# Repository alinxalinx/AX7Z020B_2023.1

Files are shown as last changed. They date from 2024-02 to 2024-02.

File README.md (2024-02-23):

# Xilinx Zynq 7000 series development boards AX7Z020, AX7Z020B
## Development board introduction
### Development board introduction
The entire structure of the development board is designed based on our consistent core board + expansion board model. Core board and expansion board
are connected using high-speed inter-board connectors.
The core board is mainly composed of XC7Z020 + 2 DDR3 + QSPI FLASH minimum system, responsible for the ZYNQ system
The high-speed data processing and storage function of the system. The data bit width between ZYNQ7020 and two DDR3 chips is 32 bits.
DDR3 capacity up to 1GB. ZYNQ7020 uses Xilinx’s Zynq7000 series of chips, model number is
XC7Z020-2CLG400I. The ZYNQ7020 chip can be divided into the processor system part Processor System (PS) and
Programmable Logic (PL).
The baseboard extends the core board with a wealth of peripheral interfaces, including 1 Gigabit Ethernet interface and 1 USB2.0 HOST
interface, 1 HDMI output interface, 1 SD Card interface, 1 UART USB interface, 1 SD card interface, 1
2-way MIPI interface, 2-way CAN bus interface, 2-way RS485 bus interface, 2-way AD input interface, 2-way 40-pin
Expansion port and some button LEDs.
### Key Features
1. ZYNQ7000 core board consists of XC7Z020+1GB DDR3 + 256Mb QSPI FLASH, and a 33.333333MHz crystal oscillator provides the clock to the PS system.
2. For the 2-way CAN bus interface, the SN65HVD232 chip of TI Company is selected.
3. For the 2-way 485 communication interface, the MAX3485 chip of MAXIM Company is selected.
4. 1 channel 10/100M/1000M Ethernet RJ45 interface, used for Ethernet data exchange with computers or other network devices. The network interface chip uses JL2121 industrial-grade GPHY chip from Jinglue Semiconductor Company.
5. One high-speed USB2.0 HOST interface, which can be used to connect the development board to USB peripherals such as mouse, keyboard, and U disk;
6. 1-way Uart to USB interface, used to communicate with the computer to facilitate user debugging. The serial port chip uses the USB-UAR chip of Silicon Labs CP2102GM, and the USB interface uses the MINI USB interface.
7. 1-way Micro SD card holder for storing operating system images and file systems.
8. 2 AD analog input interfaces, which can be used for analog signal input and voltage conversion, SMA interface form. The analog signal voltage input range is 0~10V (do not input voltage exceeding this range).
9. One HDMI image video output interface, capable of 1080P video image transmission;
10. A piece of EEPROM 24LC04 with IIC interface;
11. There is a temperature sensor chip LM75 on the board, which is used to detect the temperature of the environment around the board.
12. One MIPI camera interface, which can be connected to the OV5640 camera with black gold MIPI interface (only used by AX7Z020).
13. 1 JTAG debugging interface.
14. Two 40-pin 2.54mm pitch expansion ports can be used to connect various black gold modules (binocular cameras, TFT LCD screens, high-speed AD modules, etc.). The expansion port includes 1 channel of 5V power supply, 2 channels of 3.3V power supply, 3 channels of ground, and 34 channels of IO port.
15. 7 light-emitting diodes LED, 6 on the core board and 1 on the base board. There is 1 power indicator light on the core board; 1 power indicator light, 1 DONE configuration indicator light; and 4 user indicator lights on the base board.
16. 4 user buttons on the base panel.

# AX7Z020, AX7Z020B document tutorial link

 Note: You can switch between Chinese and English languages at the footer at the end of the document

# AX7Z020,AX7Z020B routine
## Routine description
This project is the factory routine of the development board and supports most peripherals on the board.
## Development environment and requirements
* Vivado 2023.1
* AX7Z020/AX7Z020B development board
## Create Vivado project
* Download the latest ZIP package.
* Create a new project folder.
* Unzip the downloaded ZIP package into this project folder.

There are two ways to create a Vivado project, as follows:
### Use Vivado tcl console to create a Vivado project
1. Open the Vivado software and use the **cd** command to enter the "**auto_create_project**" directory and press Enter
```
cd \<archive extracted location\>/vivado/auto_create_project
```
2. Enter **source ./create_project.tcl** and press Enter
```
source ./create_project.tcl
```

### Use bat to create a Vivado project
1. In the "**auto_create_project**" folder, there is a "**create_project.bat**" file, right-click to open it in edit mode, and modify the vivado path to the vivado installation path of this host, save and close.
```
CALL E:\XilinxVitis\Vivado\2023.1\bin\vivado.bat -mode batch -source create_project.tcl
PAUSE
```
2. Double-click the bat file under Windows.

For more information, please visit [ALINX website](https://www.alinx.com)

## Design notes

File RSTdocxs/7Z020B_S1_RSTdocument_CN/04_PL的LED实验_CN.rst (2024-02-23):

PL的“Hello World”LED实验
==========================

**实验Vivado工程为“led”。**

**本章内容主要由FPGA工程师负责实现。**

对于ZYNQ来说PL（FPGA）开发是至关重要的，这也是ZYNQ比其他ARM的有优势的地方，可以定制化很多ARM端的外设，在定制ARM端的外设之前先让我们通过一个LED例程来熟悉PL（FPGA）的开发流程，熟悉Vivado软件的基本操作，这个开发流程和不带ARM的FPGA芯片完全一致。

在本例程中，我们要做的是LED灯控制实验，每秒钟控制开发板上的LED灯翻转一次，实现亮、灭、亮、灭的控制。会控制LED灯，其它外设也慢慢就会了。

LED硬件介绍
-----------

1) 开发板的PL部分连接了4个红色的用户LED灯。这4个灯完全由PL控制。

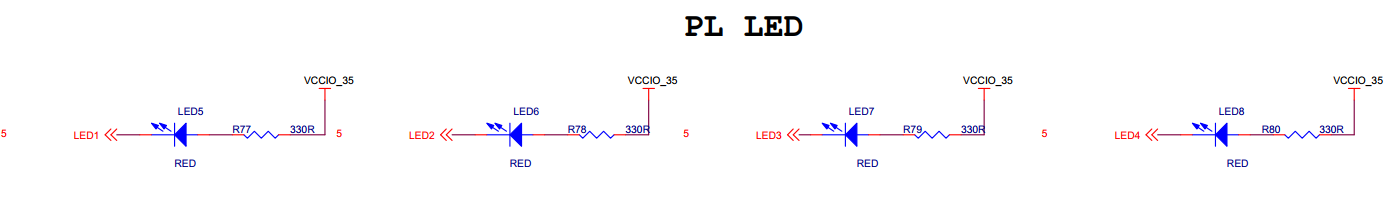
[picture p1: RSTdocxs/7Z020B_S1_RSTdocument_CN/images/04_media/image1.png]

    
2) 我们可以根据原理图的连线关系确定LED和PL管脚的绑定关系。

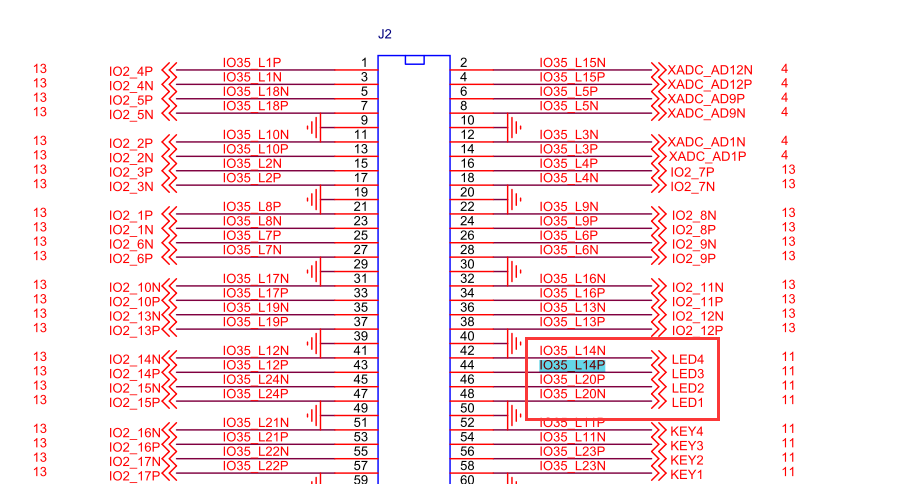
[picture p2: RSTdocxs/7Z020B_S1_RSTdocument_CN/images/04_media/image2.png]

    
对应的管脚信息

3) **原理图中以PS_MIO开头的IO都是PS端IO，不需要绑定，也不能绑定**

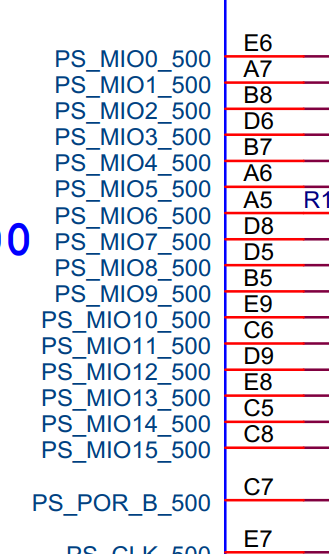
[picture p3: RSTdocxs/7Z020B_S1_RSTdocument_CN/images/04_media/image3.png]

    
创建Vivado工程
--------------

1) 启动Vivado，在Windows中可以通过双击Vivado快捷方式启动


       
2) 在Vivado开发环境里点击“Create New Project”，创建一个新的工程。

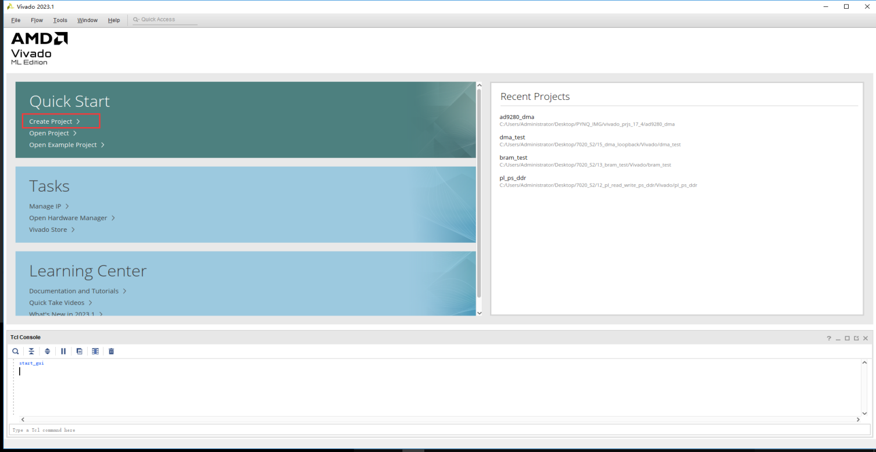
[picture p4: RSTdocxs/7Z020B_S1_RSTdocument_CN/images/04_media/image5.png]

       
3) 弹出一个建立新工程的向导，点击“Next”

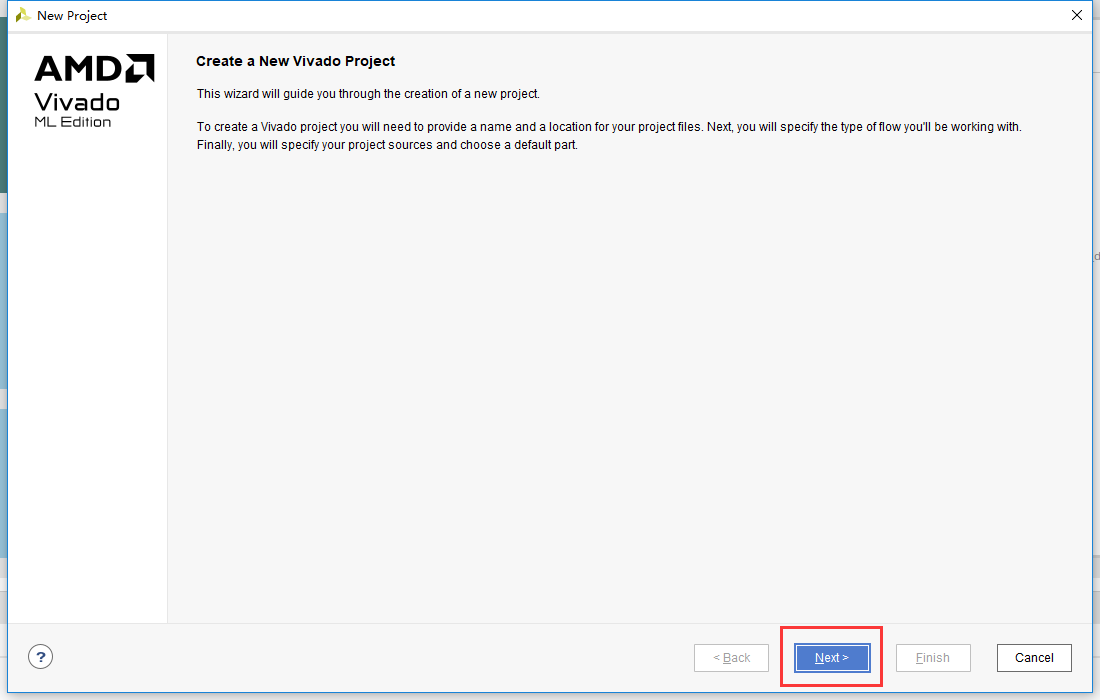
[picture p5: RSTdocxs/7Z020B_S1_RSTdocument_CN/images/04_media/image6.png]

       
4) 在弹出的对话框中输入工程名和工程存放的目录，我们这里取一个led的工程名。需要注意工程路径“Project
   location”不能有中文空格，路径名称也不能太长。

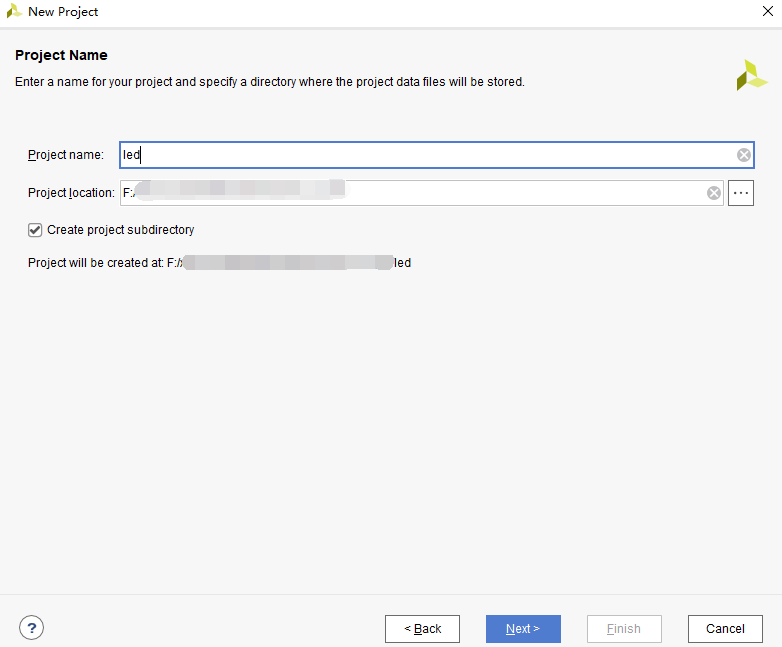
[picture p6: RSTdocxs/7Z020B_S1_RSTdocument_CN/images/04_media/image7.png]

    
5) 在工程类型中选择“RTL Project”

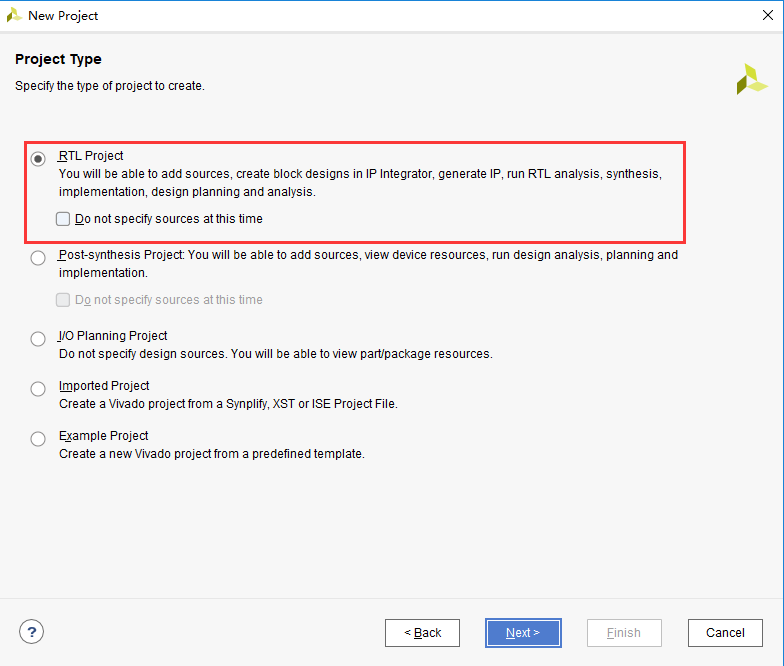
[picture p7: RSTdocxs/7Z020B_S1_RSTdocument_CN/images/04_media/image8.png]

    
6) 目标语言“Target
   language”选择“Verilog”，虽然选择Verilog，但VHDL也可以使用，支持多语言混合编程。

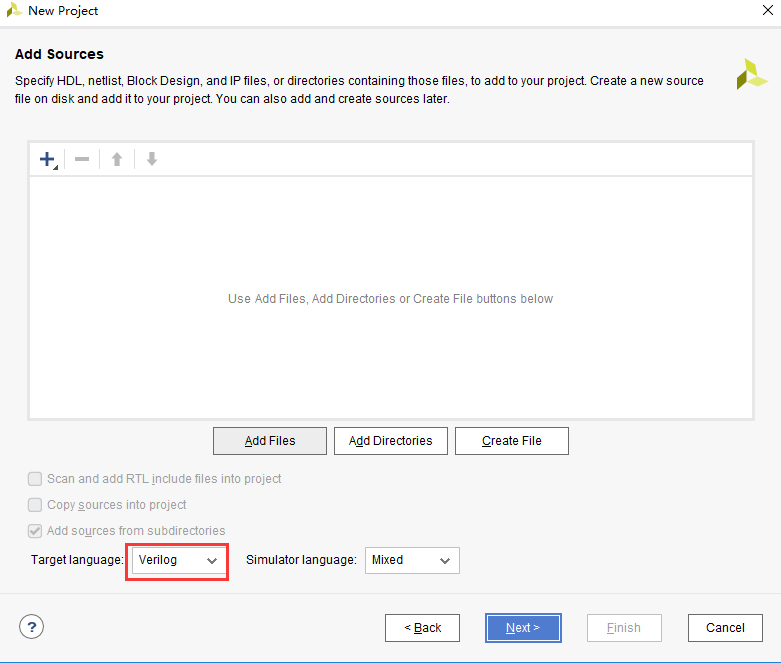
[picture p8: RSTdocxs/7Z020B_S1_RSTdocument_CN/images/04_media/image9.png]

    
7) 点击“Next”，不添加任何文件

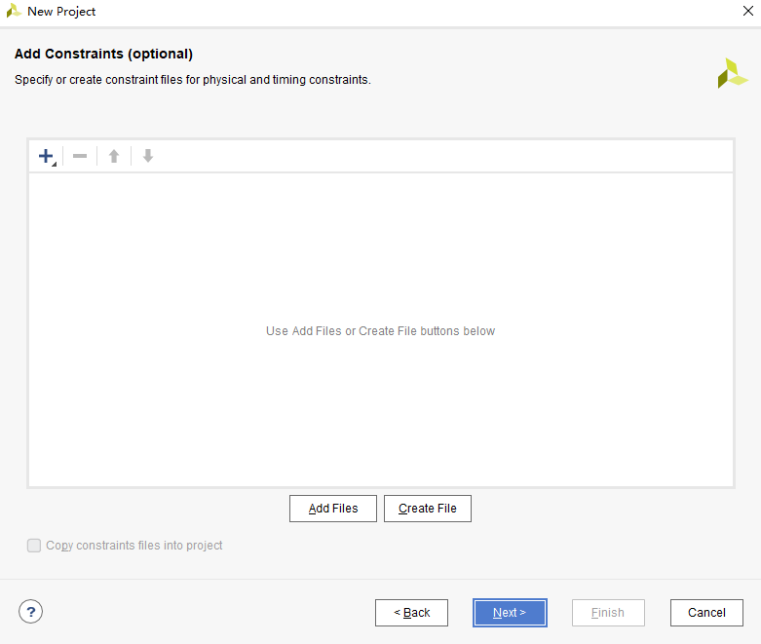
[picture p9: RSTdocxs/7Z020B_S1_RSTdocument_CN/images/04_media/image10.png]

    
8) 在“Part”选项中，器件家族“Family”选择“Zynq-7000”，AX7020开发板封装类型“Package”选择“clg400”,Speed选择”-2”减少选择范围。在下拉列表中选择“xc7z020clg400-2”,“-2”表示速率等级，数字越大，性能越好，速率高的芯片向下兼容速率低的芯片。

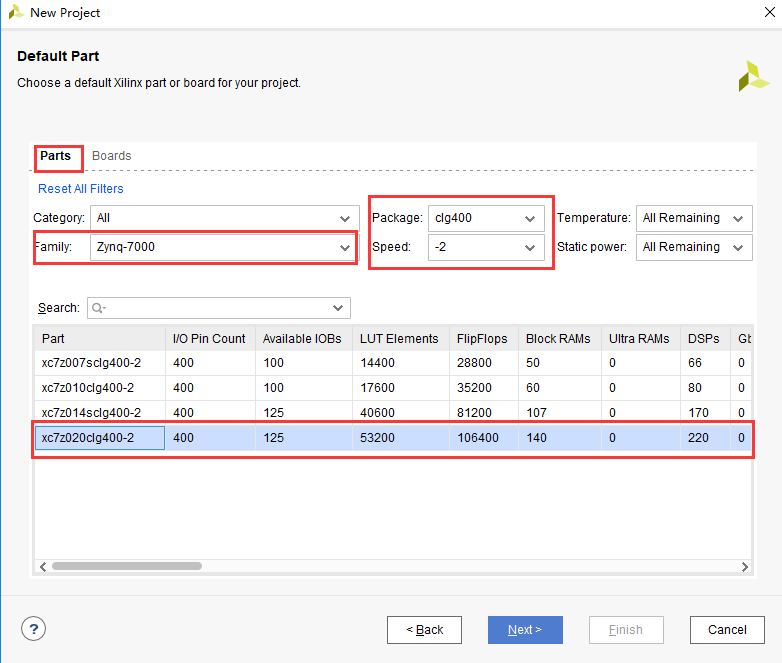
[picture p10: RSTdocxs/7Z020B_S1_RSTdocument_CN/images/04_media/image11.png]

    
AX7010开发板选择型号“xc7z010clg400-1”

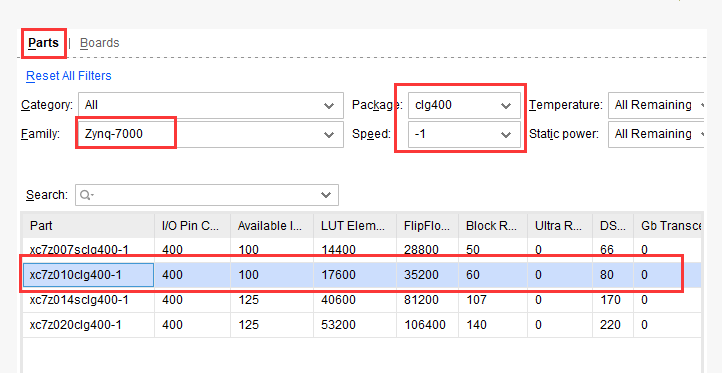
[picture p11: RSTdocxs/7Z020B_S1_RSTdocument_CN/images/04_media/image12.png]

    
9) 点击“Finish”就可以完成以后名为“led”工程的创建。

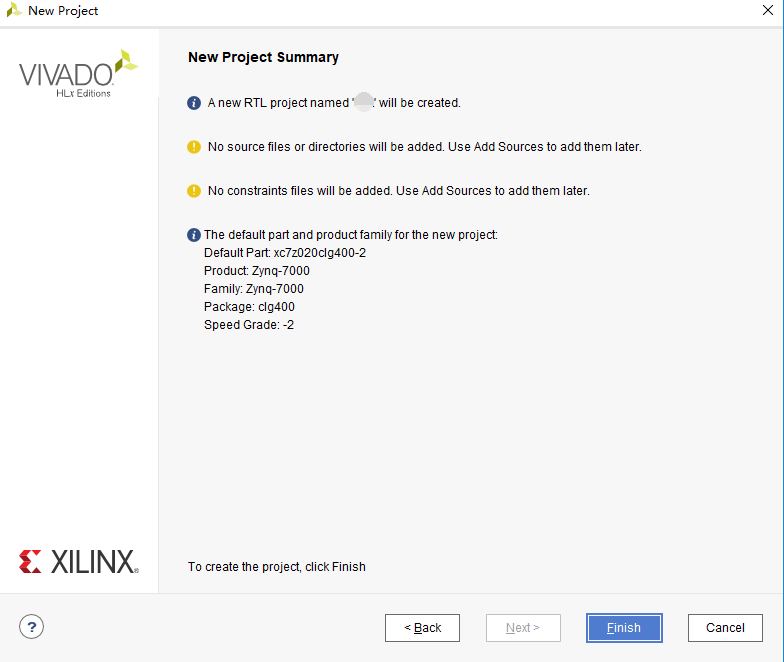
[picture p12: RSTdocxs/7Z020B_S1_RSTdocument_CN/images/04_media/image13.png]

    
10) Vivado软件界面

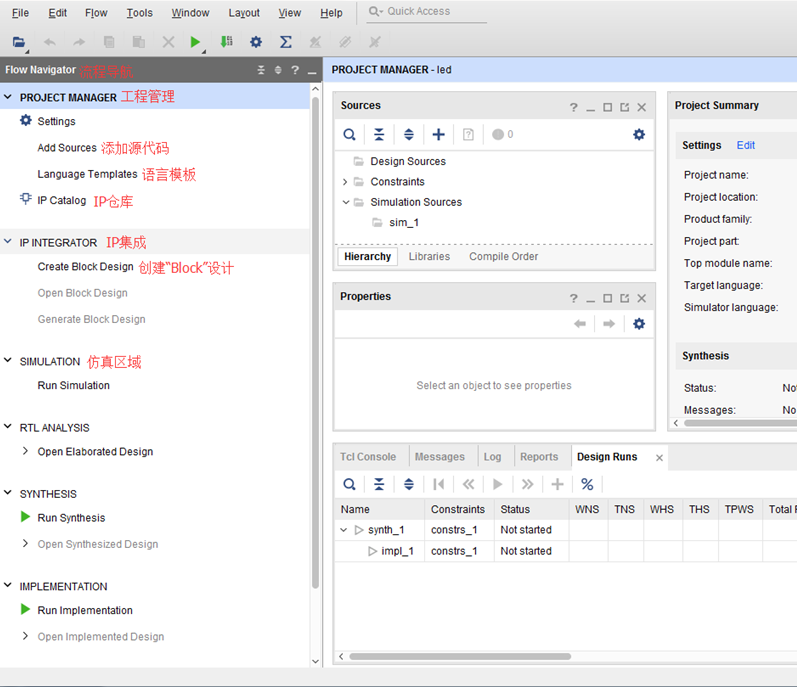
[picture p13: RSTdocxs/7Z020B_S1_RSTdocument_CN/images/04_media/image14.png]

    
创建Verilog HDL文件点亮LED
--------------------------

1) 点击Project Manager下的Add Sources图标（或者使用快捷键Alt+A）

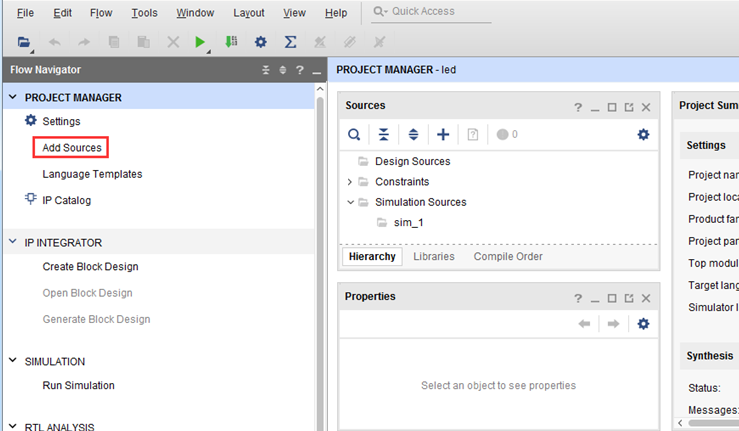
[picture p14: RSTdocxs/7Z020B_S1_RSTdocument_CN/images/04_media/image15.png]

    
2) 选择添加或创建设计源文件“Add or create design sources”,点击“Next”

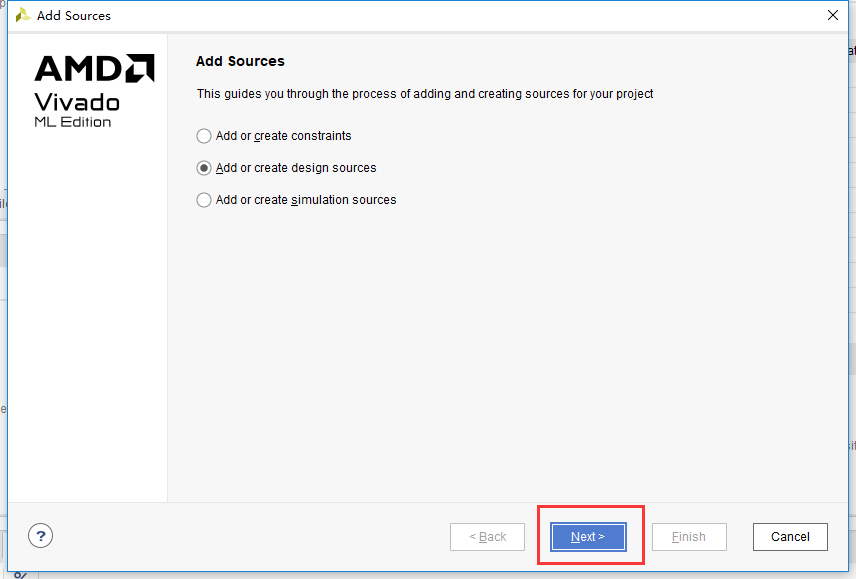
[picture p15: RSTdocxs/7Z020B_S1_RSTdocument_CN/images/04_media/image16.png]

       
3) 选择创建文件“Create File”

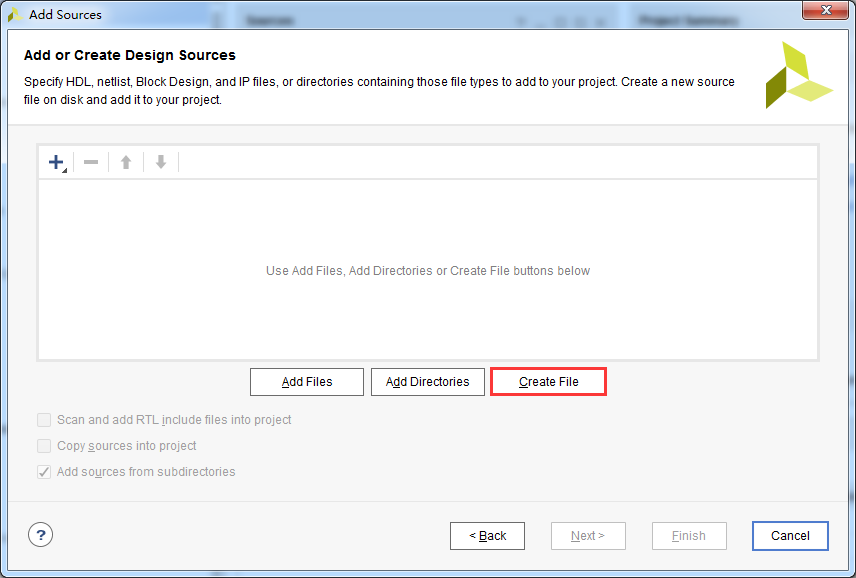
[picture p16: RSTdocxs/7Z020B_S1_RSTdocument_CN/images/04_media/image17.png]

    
4) 文件名“File name”设置为“led”，点击“OK”

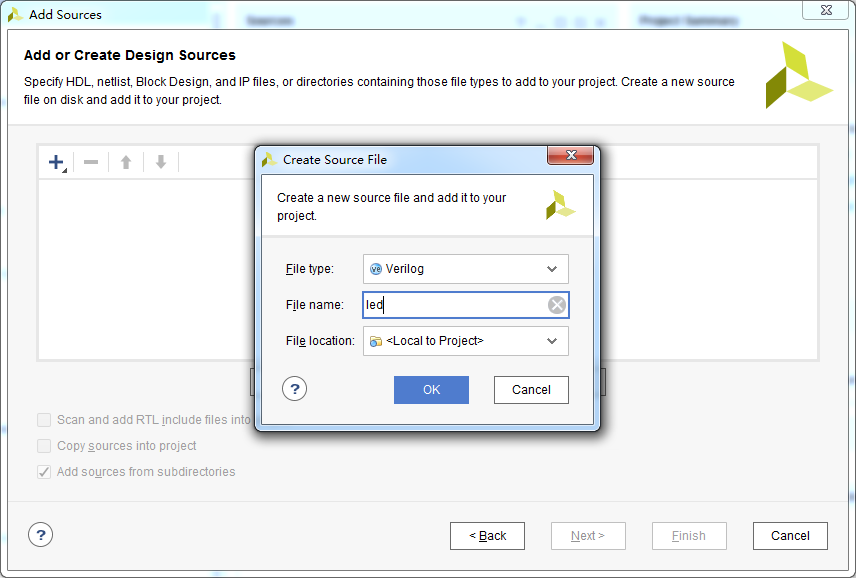
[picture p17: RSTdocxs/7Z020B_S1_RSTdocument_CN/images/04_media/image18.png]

    
5) 点击“Finish”,完成“led.v”文件添加

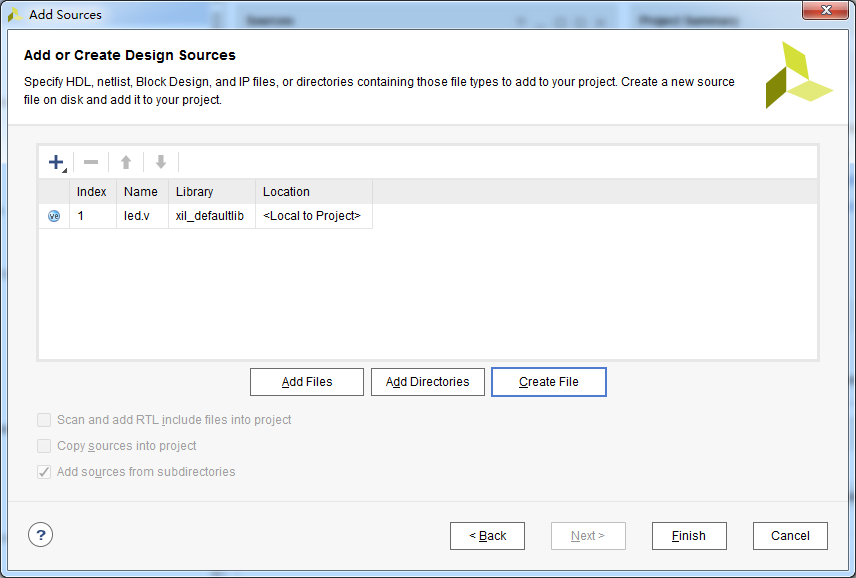
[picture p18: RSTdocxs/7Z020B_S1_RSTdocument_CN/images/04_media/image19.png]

    
6) 在弹出的模块定义“Define
   Module”,中可以指定“led.v”文件的模块名称“Module
   name”,这里默认不变为“led”，还可以指定一些端口，这里暂时不指定，点击“OK”。

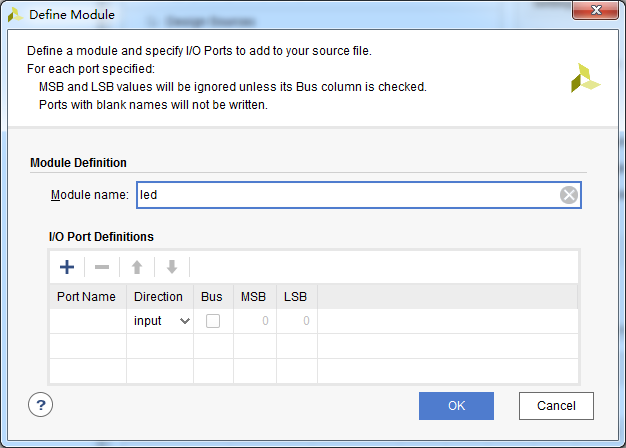
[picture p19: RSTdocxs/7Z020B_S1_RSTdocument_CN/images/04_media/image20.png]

    
7) 在弹出的对话框中选择“Yes”

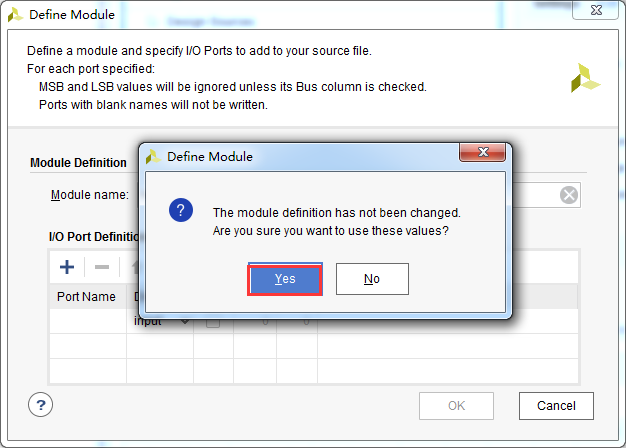
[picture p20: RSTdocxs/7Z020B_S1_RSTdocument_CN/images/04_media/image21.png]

    
8) 双击“led.v”可以打开文件，然后编辑

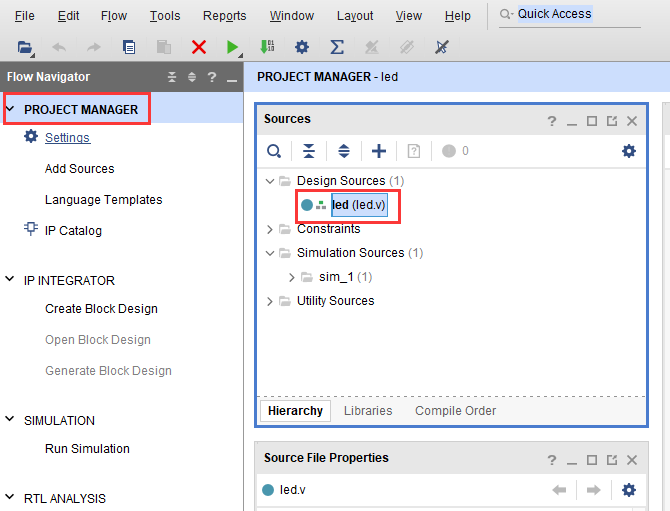
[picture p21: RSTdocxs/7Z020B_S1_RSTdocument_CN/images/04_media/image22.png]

    
9) 编写“led.v”,这里定义了一个32位的寄存器timer,
   用于循环计数0~49999999(1秒钟), 计数到49999999(1秒)的时候,
   寄存器timer变为0，并翻转四个LED。这样原来LED是灭的话，就会点亮，如果原来LED为亮的话，就会熄灭。编写好后的代码如下：

.. code:: verilog

 module led(
     input sys_clk,
     input rst_n,
     output reg [3:0] led
     );
 reg[31:0] timer_cnt;
 always@(posedge sys_clk or negedge rst_n)
 begin
     if (!rst_n)
     begin
         led <= 4'd0 ;
         timer_cnt <= 32'd0 ;
     end
     else if(timer_cnt >= 32'd49_999_999)
     begin
         led <= ~led;
         timer_cnt <= 32'd0;
     end
     else
     begin
         led <= led;
         timer_cnt <= timer_cnt + 32'd1;
     end
     
 end
 endmodule 

10) 编写好代码后保存

添加管脚约束
------------

Vivado使用的约束文件格式为xdc文件。xdc文件里主要是完成管脚的约束,时钟的约束,
以及组的约束。这里我们需要对led.v程序中的输入输出端口分配到FPGA的真实管脚上。

1) 点击“Open Elaborated Design”

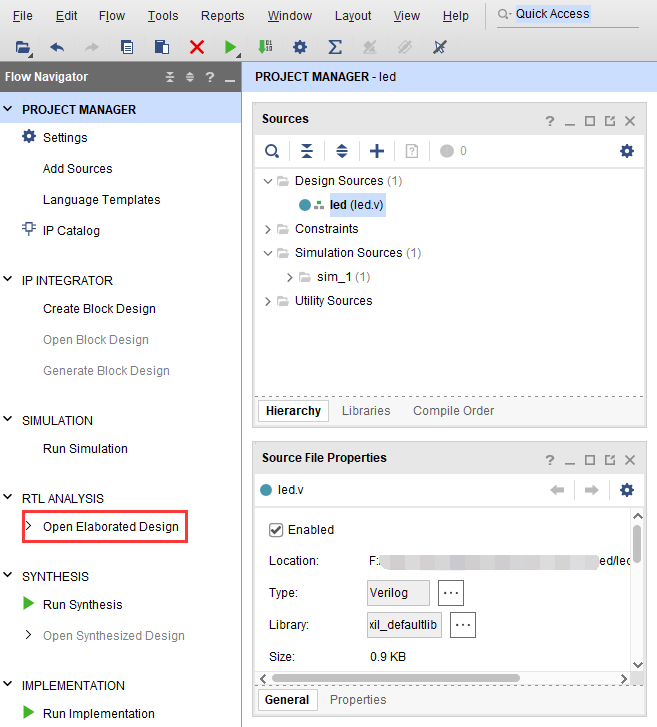
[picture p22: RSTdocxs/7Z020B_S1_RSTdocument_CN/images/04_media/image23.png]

    
2) 在弹出的窗口中点击“OK”按钮

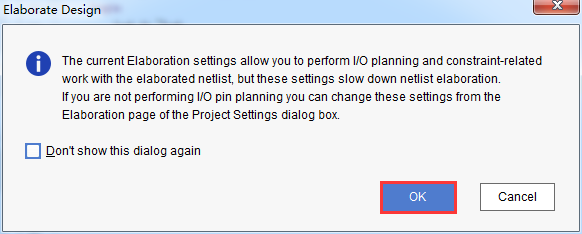
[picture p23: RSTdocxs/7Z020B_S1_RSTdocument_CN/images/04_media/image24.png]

    
3) 在菜单中选择“Window -> I/O Ports”

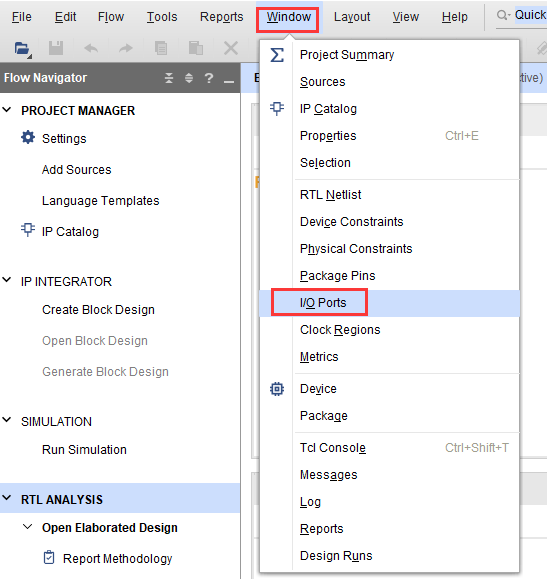
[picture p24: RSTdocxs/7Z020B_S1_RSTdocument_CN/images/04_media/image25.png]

    
4) 在弹出的I/O Ports中可以看到管脚分配情况


    
5) 将复位信号rst_n绑定到PL端的按键，给LED和时钟分配管脚、电平标准，完成后点击保存图标


    
6) 弹出窗口，要求保存约束文件，文件名我们填写“led”，文件类型默认“XDC”，点击“OK”


    
7) 打开刚才生成的“led.xdc”文件，我们可以看到是一个TCL脚本，如果我们了解这些语法，完全可以通过自己编写led.xdc文件的方式来约束管脚


    
下面来介绍一下最基本的XDC编写的语法，普通IO口只需约束引脚号和电压，管脚约束如下：

**set_property PACKAGE_PIN "引脚编号" [get_ports “端口名称”]**

电平信号的约束如下：

**set_property IOSTANDARD "电平标准" [get_ports “端口名称”]**

这里需要注意文字的大小写，端口名称是数组的话用{
}刮起来，端口名称必须和源代码中的名字一致，且端口名字不能和关键字一样。

电平标准中“LVCMOS33”后面的数字指FPGA的BANK电压，LED所在BANK电压为3.3伏，所以电平标准为“LVCMOS33”。\ **Vivado默认要求为所有IO分配正确的电平标准和管脚编号**\ 。

添加时序约束
------------

一个FPGA设计除了管脚分配以外，还有一个重要的约束，那就是时序约束，这里通过向导方式演示如果进行一个时序约束。

1) 点击“Run Synthesis”开始综合


    
2) 弹出对话框点击“OK”


    
3) 综合完成以后点击“Cancel”


    
4) 点击“Constraints Wizard”


    
5) 在弹出的窗口中点击“Next”


    
6) 时序约束向导分析出设计中的时钟，这里把“sys_clk”频率设置为50Mhz，然后点击“Skip
   to Finish”结束时序约束向导。


    
7) 弹出的窗口中点击“OK”


    
8) 点击“Finish”


    
9) 这个时候led.xdc文件已经更新，点击“Reload”重新加载文件，并保存文件


    
生成BIT文件
-----------

1) 编译的过程可以细分为综合、布局布线、生成bit文件等，这里我们直接点击“Generate
   Bitstream”,直接生成bit文件。


    
2) 在弹出的对话框中可以选择任务数量，这里和CPU核心数有关，一般数字越大，编译越快，点击“OK”


    
3) 这个时候开始编译，可以看到右上角有个状态信息，在编译过程中可能会被杀毒软件、电脑管家拦截运行，导致无法编译或很长时间没有编译成功。


    
4) 编译中没有任何错误，编译完成，弹出一个对话框让我们选择后续操作，可以选择“Open
   Hardware Manger”，当然，也可以选择“Cancel”，我们这里选择
   “Cancel”，先不下载。


    
Vivado仿真
----------

接下来我们不妨小试牛刀，利用Vivado自带的仿真工具来输出波形验证流水灯程序设计结果和我们的预想是否一致。具体步骤如下：

1. 设置Vivado的仿真配置，右击SIMULATION中Simulation Settings。


    
2. 在Simulation
   Settings窗口中进行如下图来配置，这里设置成50ms（根据需要自行设定）,其它按默认设置，单击OK完成。


    
3. 添加激励测试文件，点击Project Manager下的Add
   Sources图标,按下图设置后单击Next。


    
4. 点击Create File生成仿真激励文件。


    
在弹出的对话框中输入激励文件的名字，这里我们输入名为vtf_led_test。


    
5. 点击Finish按钮返回。


    
这里我们先不添加IO Ports，点击OK。


    
在Simulation
Sources目录下多了一个刚才添加的vtf_led_test文件。双击打开这个文件，可以看到里面只有module名的定义，其它都没有。


    
6. 接下去我们需要编写这个vtf_led_test.v文件的内容。首先定义输入和输出信号，然后需要实例化led_test模块，让led_test程序作为本测试程序的一部分。再添加复位和时钟的激励。完成后的vtf_led_test.v文件如下：

.. code:: verilog

 `timescale 1ns / 1ps
 //////////////////////////////////////////////////////////////////////////////////
 // Module Name: vtf_led_test
 //////////////////////////////////////////////////////////////////////////////////
 
 module vtf_led_test;
 // Inputs
 reg sys_clk;
 reg rst_n ;
 // Outputs
 wire [3:0] led;
 
 // Instantiate the Unit Under Test (UUT)
 led uut (
     .sys_clk(sys_clk),   
     .rst_n(rst_n),
     .led(led)
  );
 
 initial 
 begin
 // Initialize Inputs
     sys_clk = 0;
     rst_n = 0 ;
     #1000 ;
     rst_n = 1; 
 end
 //Create clock
 always #10 sys_clk = ~ sys_clk;  
 
 endmodule

1) 编写好后保存，vtf_led_test.v自动成了这个仿真Hierarchy的顶层了，它下面是设计文件led_test.v。


    
8) 点击Run Simulation按钮，再选择Run Behavioral
   Simulation。这里我们做一下行为级的仿真就可以了。


    
如果没有错误，Vivado中的仿真软件开始工作了。

10.
在弹出仿真界面后如下图，界面是仿真软件自动运行到仿真设置的50ms的波形。


    
由于LED[3：0]在程序中设计的状态变化时间长，而仿真又比较耗时，在这里观测timer[31:0]计数器变化。把它放到Wave中观察(点击Scope界面下的uut，
再右键选择Objects界面下的timer， 在弹出的下拉菜单里选择Add Wave
Window)。


    
添加后timer显示在Wave的波形界面上，如下图所示。


    
11. 点击如下标注的Restart按钮复位一下，再点击Run
All按钮。（需要耐心！！！），可以看到仿真波形与设计相符。（注意：仿真的时间越长，仿真的波形文件占用的磁盘空间越大，波形文件在工程目录的xx.sim文件夹）


    

    
我们可以看到led的信号会变成F，说明LED1~LED4灯同时变亮。

下载
----

1) 连接好开发板的JTAG接口，给开发板上电

2) 在“HARDWARE MANAGER”界面点击“Auto Connect”，自动连接设备


    
3) 可以看到JTAG扫描到arm和FPGA内核


    
4) 选择xc7z020_1，右键“Program Device...”


    
5) 在弹出窗口中点击“Program”


    
6) 等待下载


    
7) 下载完成以后，我们可以看到4颗LED开始每秒变化一次。到此为止Vivado简单流程体验完成。后面的章节会介绍如果把程序烧录到Flash，需要PS系统的配合才能完成，只有PL的工程不能直接烧写Flash。在”体验ARM，裸机输出”Hello
   World”一章的常见问题中有介绍。

在线调试
--------

前面介绍了仿真和下载，但仿真并不需要程序烧写到板子，是比较理想化的结果，下面介绍Vivado在线调试方法，观察内部信号的变化。Vivado有内嵌的逻辑分析仪，叫做ILA，可以用于在线观察内部信号的变化，对于调试有很大帮助。在本实验中我们观察timer_cnt和led的信号变化。

添加ILA IP核
~~~~~~~~~~~~

1. 点击IP Catalog，在搜索框中搜索ila，双击ILA的IP


    
2. 修改名称为ila，由于要采样两个信号，Probes的数量设置为2，Sample Data
   Depth指的是采样深度，设置的越高，采集的信号越多，同样消耗的资源也会越多。


    
3. 在Probe_Ports页面，设置Probe的宽度，设置PROBE0位宽为32，用于采样timer_cnt，设置PROBE1位宽为4，用于采样led。点击OK


    
弹出界面，选择OK


    
再如下设置，点击Generate


    
4. 在led.v中例化ila，并保存


    
5. 重新生成Bitstream


    
6. 下载程序


    
这时候看到有bit和ltx文件，点击program


    
7. 此时弹出在线调试窗口，出现了我们添加的信号


    
点击运行按钮，出现信号的数据


    
也可以触发采集，在Trigger Setup窗口点击“+”，深度选择timer_cnt信号


    
将Radix改为U，也就是十进制，在Value中设置为49999999，也就是timer_cnt计数的最大值


    
再次点击运行，即可以看到触发成功，此时timer_cnt显示为十六进制，而led也在此时翻转。


    
MARK DEBUG
~~~~~~~~~~

上面介绍了添加ILA
IP的方式在线调试，下面介绍在代码中添加综合属性，实现在线调试。

1. 首先打开led.v，将ila的例化部分注释掉


    
2. 在led和timer_cnt的定义前面添加(\* MARK_DEBUG=”true” \*)，保存文件。


    
3. 点击综合


    
4. 综合结束后，点击Set Up Debug


    
5) 弹出的窗口点击Next


    
按照默认点击Next


    
采样深度窗口，选择Next


    
点击Finish


    
点击保存


    
在xdc文件中即可看到添加的ila核约束


    
5. 重新生成bitstream


    
6) 调试方法与前面一样，不再赘述。

实验总结
--------

本章节介绍了如何在PL端开发程序，包括工程建立，约束，仿真，在线调试等方法，在后续的代码开发方式中皆可参考此方法。

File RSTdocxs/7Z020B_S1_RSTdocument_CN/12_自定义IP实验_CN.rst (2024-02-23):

自定义IP实验
==============

**实验Vivado工程为“custom_pwm_ip”。**

Xilinx官方为大家提供了很多IP核，在Vivado的IP Catalog中可以查看这些IP核，
用户在构建自己的系统中，不可能只使用Xilinx官方的免费IP核，很多时候需要创建属于自己的用户IP核，创建自己的IP核有很多好处，例如系统设计定制化；设计复用，可以在在IP核中加入license,
有偿提供给别人使用；简化系统设计和缩短设计时间。用ZYNQ系统设计IP核，最常用的就是使用AXI总线将PS同PL部分的IP核连接起来。本实验将为大家介绍如何在Vivado中构建AXI总线类型的IP核，此IP核用来产生一个PWM，用这个控制开发板上的LED，做一个呼吸灯的效果。

PWM介绍
-------

我们经常使用PWM来控制LED，蜂鸣器等，通过调节脉冲的占空比来调节LED的亮度。

在其他开发板中我们使用过的一个pwm模块如下：

.. code:: verilog
   
 //////////////////////////////////////////////////////////////////////////////////
 //                                                                              //
 //                                                                              //
 //  Author: meisq                                                               //
 //          msq@qq.com                                                          //
 //          ALINX(shanghai) Technology Co.,Ltd                                  //
 //          heijin                                                              //
 //     WEB: http://www.alinx.cn/                                                //
 //     BBS: http://www.heijin.org/                                              //
 //                                                                              //
 //////////////////////////////////////////////////////////////////////////////////
 //                                                                              //
 // Copyright (c) 2017,ALINX(shanghai) Technology Co.,Ltd                        //
 //                    All rights reserved                                       //
 //                                                                              //
 // This source file may be used and distributed without restriction provided    //
 // that this copyright statement is not removed from the file and that any      //
 // derivative work contains the original copyright notice and the associated    //
 // disclaimer.                                                                  //
 //                                                                              //
 //////////////////////////////////////////////////////////////////////////////////
 
 //================================================================================
 //   Description:  pwm model
 //   pwm out period = frequency(pwm_out) * (2 ** N) / frequency(clk);
 //
 //================================================================================
 //  Revision History:
 //  Date          By            Revision    Change Description
 //--------------------------------------------------------------------------------
 //  2017/5/3     meisq          1.0         Original
 //********************************************************************************/
 `timescale 1ns / 1ps
 module ax_pwm
 #(
 	parameter N = 32 //pwm bit width 
 )
 (
     input         clk,
     input         rst,
     input[N - 1:0]period,
     input[N - 1:0]duty,
     output        pwm_out 
     );
  
 reg[N - 1:0] period_r;
 reg[N - 1:0] duty_r;
 reg[N - 1:0] period_cnt;
 reg pwm_r;
 assign pwm_out = pwm_r;
 always@(posedge clk or posedge rst)
 begin
     if(rst==1)
     begin
         period_r <= { N {1'b0} };
         duty_r <= { N {1'b0} };
     end
     else
     begin
         period_r <= period;
         duty_r   <= duty;
     end
 end
 
 always@(posedge clk or posedge rst)
 begin
     if(rst==1)
         period_cnt <= { N {1'b0} };
     else
         period_cnt <= period_cnt + period_r;
 end
 
 always@(posedge clk or posedge rst)
 begin
     if(rst==1)
     begin
         pwm_r <= 1'b0;
     end
     else
     begin
         if(period_cnt >= duty_r)
             pwm_r <= 1'b1;
         else
             pwm_r <= 1'b0;
     end
 end
 
 endmodule

可以看到这个PWM模块需要2个参数“period”、“duty”来控制频率和占空比，”period”为步进值，也就是计数器每个周期要加的值。Duty为占空比的值。我们需要设计一些寄存器来控制这些参数，这里需要使用AXI总线，PS通过AXI总线来读写寄存器。

PWM频率 = :math:`\frac{period}{2\hat{}N} \times clk频率` (单位为Hz)

PWM占空比 = 1 - :math:`\frac{duty + 1}{2\hat{}N}`

Vivado工程建立
--------------

用”ps_hello”工程另存为一个名为“custom_pwm_ip”工程

创建自定义IP
~~~~~~~~~~~~

1) 点击菜单“Tools->Create and Package IP...”


    
2) 选择“Next”


    
3) 选择创建一个新的AXI4设备


    
4) 名称填写“ax_pwm”,描述填写“alinx pwm”，然后选择一个合适的位置用来放IP


    
5) 下面参数可以指定接口类型、寄存器数量等，这里不需要修改，使用AXI Lite
   Slave接口，4个寄存器。


    
6) 点击“Finish”完成IP的创建


    
7) 在“IP Catalog”中可以看到刚才创建的IP


    
8) 这个时候的IP只有简单的寄存器读写功能，我们需要修改IP，选择IP，右键“Edit
   in IP Packager”


    
9) 这是弹出一个对话框，可以填写工程名称和路径，这里默认，点击“OK”


    
10) Vivado打开了一个新的工程


    
11) 添加PWM功能的核心代码


    
12) 添加代码时选择复制代码到IP目录


    
13) 修改“ax_pwm_v1_0.v”，添加一个pwm输出端口


    
14) 修改“ax_pwm_v1_0.v”，在例化“ax_pwm_V1_0_S00_AXI”,中添加pwm端口的例化


    
15) 修改“ax_pwm_v1_0_s00_AXI.v”文件，添加pwm端口，这个文件是实现AXI4
    Lite Slave的核心代码


    
16) 修改“ax_pwm_v1_0_s00_AXI.v”文件，例化pwm核心功能代码，将寄存器slv_reg0和slv_reg1用于pwm模块的参数控制。


    
17) 双击“component.xml”文件


    
18) 在“File Groups”选项中点击“Merge changers from File Groups Wizard”


    
19) 在“Customization Parameters”选项中点击“Merge changes form
    Customization Parameters Wizard”


    
20) 点击“Re-Package IP”完成IP的修改


    
添加自定义IP到工程
~~~~~~~~~~~~~~~~~~

1) 搜索“pwm”，添加“ax_pwm_v1.0”


    
2) 点击“Run Connection Automation”


    
3) 导出pwm端口


    

    
4) 保存设计，并Generate Output Products


    
5) 添加xdc文件分配管脚，把pwm_0输出端口分配给PL LED1，做一个呼吸灯

::

 set_property IOSTANDARD LVCMOS33 [get_ports pwm_0]
 set_property PACKAGE_PIN J14 [get_ports pwm_0]

1) 编译生成bit文件，导出硬件


    

    
Vitis软件编写调试
-----------------

1) 启动Vitis，新建APP，模板选择“Hello World”


                
2) 前面的例都是使用xilinx的IP，xilinx大多都提供一套API，对于这个自定义IP，我们需要自己开发，先看看APP的目录下的资源，可以找到一个ax_pwm.h的文件，这个文件里包含里对自定义IP寄存器的读写宏定义


    
3) 在bsp里找到“xparameters.h”文件，这个非常重要的文件，里面找到了自定IP的寄存器基地址，可以找到自定义IP的基地址。


    
4) 有个寄存器读写宏和自定义IP的基地址，我们开始编写代码，测试自定义IP，我们先通过写寄存器AX_PWM_S00_AXI_SLV_REG0_OFFSET，控制PWM输出频率，然后通过写寄存器AX_PWM_S00_AXI_SLV_REG1_OFFSET控制PWM输出的占空比。

.. code:: verilog

 #include <stdio.h>
 #include "platform.h"
 #include "xil_printf.h"
 #include "ax_pwm.h"
 #include "xil_io.h"
 #include "xparameters.h"
 #include "sleep.h"
 
 unsigned int duty;
 
 int main()
 {
     init_platform();
 
     print("Hello World\n\r");
 
 	//pwm out period = frequency(pwm_out) * (2^N) / frequency(clk);
 	AX_PWM_mWriteReg(XPAR_AX_PWM_0_S00_AXI_BASEADDR, AX_PWM_S00_AXI_SLV_REG0_OFFSET, 17179);//200hz
 	//duty = (2^N) * (1 - (duty cycle)) - 1
 	while (1) {
 		for (duty = 0x8fffffff; duty < 0xffffffff; duty = duty + 100000) {
 			AX_PWM_mWriteReg(XPAR_AX_PWM_0_S00_AXI_BASEADDR, AX_PWM_S00_AXI_SLV_REG1_OFFSET, duty);
 			usleep(100);
 		}
 	}
 
     cleanup_platform();
     return 0;
 }

1) 通过运行代码，我们可以看到PL LED1呈现出一个呼吸灯的效果。


    
6) 通过debug，我们来查看一下寄存器


    
7) 进入debug状态，按“F6”可以单步运行。


    
8) 通过菜单可以查看“Memory”窗口


    
9) 添加一个监视地址“0x43c00000”


    

    
10) 单步运行，观察变化


    
实验总结
--------

通过本实验我们掌握了更多的Vitis调试技巧，掌握了ARM +
FPGA开发的核心内容，就是ARM和FPGA数据交互。

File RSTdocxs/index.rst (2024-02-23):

.. ZYNQ 7000 开发平台 FPGA 教程 documentation master file, created by
   sphinx-quickstart on Tue Jan 30 18:14:13 2024.
   You can adapt this file completely to your liking, but it should at least
   contain the root `toctree` directive.

ZYNQ 7000 开发平台
======================================

.. toctree::
   :maxdepth: 1
   :caption: 公司简介

   7Z020B_S1_RSTdocument_CN/00_关于ALINX_CN
   7Z020B_S1_RSTdocument_CN/00_序_CN
   7Z020B_S1_RSTdocument_CN/00_文档版本履历_CN

.. toctree::
   :maxdepth: 3
   :caption: 用户手册

   7Z020UserManual_CN/AX7Z020UserManual

.. toctree::
   :maxdepth: 2
   :caption: AX7Z020B型号板卡S1_FPGA教程

   7Z020B_S1_RSTdocument_CN/01_软件包说明和开发板检测_CN
   7Z020B_S1_RSTdocument_CN/02_ZYNQ简介_CN
   7Z020B_S1_RSTdocument_CN/03_Vivado开发环境_CN
   7Z020B_S1_RSTdocument_CN/04_PL的LED实验_CN
   7Z020B_S1_RSTdocument_CN/05_HDMI输出实验_CN
   7Z020B_S1_RSTdocument_CN/06_体验ARM输出Hello World_CN
   7Z020B_S1_RSTdocument_CN/07_PS定时器中断实验_CN
   7Z020B_S1_RSTdocument_CN/08_PS端MIO的使用_CN
   7Z020B_S1_RSTdocument_CN/09_PS端EMIO的使用_CN
   7Z020B_S1_RSTdocument_CN/10_PL端AXI GPIO的使用_CN
   7Z020B_S1_RSTdocument_CN/11_以太网实验_CN
   7Z020B_S1_RSTdocument_CN/12_自定义IP实验_CN
   7Z020B_S1_RSTdocument_CN/13_使用VDMA驱动HDMI显示_CN

.. toctree::
   :maxdepth: 2
   :caption: AX7Z020B型号板卡S2_Vitis教程
   
   7Z020B_S2_RSTdocument_CN/00_前言_CN
   7Z020B_S2_RSTdocument_CN/00_准备工程及注意事项_CN
   7Z020B_S2_RSTdocument_CN/01_PS端UART读写控制_CN
   7Z020B_S2_RSTdocument_CN/02_XADC的使用_CN
   7Z020B_S2_RSTdocument_CN/03_I2C的读写_CN
   7Z020B_S2_RSTdocument_CN/04_CAN总线读写_CN
   7Z020B_S2_RSTdocument_CN/05_RS485测试_CN
   7Z020B_S2_RSTdocument_CN/06_PL读写PS端DDR数据_CN
   7Z020B_S2_RSTdocument_CN/07_通过BRAM实现PS与PL数据交互_CN
   7Z020B_S2_RSTdocument_CN/08_双核AMP的使用_CN
   7Z020B_S2_RSTdocument_CN/09_ZYNQ下使用Free RTOS_CN
   7Z020B_S2_RSTdocument_CN/10_DMA环通测试_CN
   7Z020B_S2_RSTdocument_CN/11_DMA使用之DAC波形发生器_CN
   7Z020B_S2_RSTdocument_CN/12_DMA使用之ADC示波器_CN
   7Z020B_S2_RSTdocument_CN/13_DMA使用之ADC示波器_CN
   7Z020B_S2_RSTdocument_CN/14_DMA使用之ADC示波器_CN
   7Z020B_S2_RSTdocument_CN/15_基于ADC模块的Scatter_CN
   7Z020B_S2_RSTdocument_CN/16_基于DAC模块的Scatter_CN
   7Z020B_S2_RSTdocument_CN/17_OV5640摄像头的采集显示一_CN
   7Z020B_S2_RSTdocument_CN/18_OV5640摄像头的采集显示二_CN
   7Z020B_S2_RSTdocument_CN/19_双目摄像头以太网传输_CN
   7Z020B_S2_RSTdocument_CN/20_SD卡读写操作之BMP图片显示_CN
   7Z020B_S2_RSTdocument_CN/21_SD卡读写操作之摄像头抓拍_CN
   7Z020B_S2_RSTdocument_CN/22_基于AN5641模块的MIPI采集显示_CN
   7Z020B_S2_RSTdocument_CN/23_音频模块AN831的录音与播放_CN
   7Z020B_S2_RSTdocument_CN/24_7寸触摸屏模块的显示_CN
   7Z020B_S2_RSTdocument_CN/25_7寸触摸屏的GUI及触摸控制_CN
   7Z020B_S2_RSTdocument_CN/26_基于AN108模块的ADC采集以太网传输_CN
   7Z020B_S2_RSTdocument_CN/27_基于AN9238模块的ADC采集之以太网传输_CN
   7Z020B_S2_RSTdocument_CN/28_基于AN706模块的ADC采集之以太网传输_CN
   7Z020B_S2_RSTdocument_CN/29_基于UDP TCP的远程更新_CN

.. toctree::
   :maxdepth: 2
   :caption: AX7Z020B型号板卡S3_HLS教程

   7Z020B_S3_RSTdocument_CN/01_led_control_CN
   7Z020B_S3_RSTdocument_CN/02_led_register_CN
   7Z020B_S3_RSTdocument_CN/03_average_float_CN
   7Z020B_S3_RSTdocument_CN/04_colorbar_CN
   7Z020B_S3_RSTdocument_CN/05_video_show_CN
   7Z020B_S3_RSTdocument_CN/06_contrast_adj_CN
   7Z020B_S3_RSTdocument_CN/07_auto_focus_CN
   7Z020B_S3_RSTdocument_CN/08_edge_detector_CN
   7Z020B_S3_RSTdocument_CN/09_dual_corner_CN

.. toctree::
   :maxdepth: 2
   :caption: AX7Z020B型号板卡S4_LINUX教程

   7Z020B_S4_RSTdocument_CN/01_安装虚拟机和Ubuntu系统_CN
   7Z020B_S4_RSTdocument_CN/02_Ubuntu安装Linux版Vitis软件_CN
   7Z020B_S4_RSTdocument_CN/03_Petalinux工具安装_CN
   7Z020B_S4_RSTdocument_CN/04_NFS服务软件安装_CN
   7Z020B_S4_RSTdocument_CN/05_使用Petalinux定制Linux系统_CN
   7Z020B_S4_RSTdocument_CN/06_使用Vitis开发Linux程序_CN
   7Z020B_S4_RSTdocument_CN/07_Linux下GPIO实验_CN
   7Z020B_S4_RSTdocument_CN/08_Petalinux下的HDMI显示_CN
   7Z020B_S4_RSTdocument_CN/09_使用Debian桌面系统_CN
   7Z020B_S4_RSTdocument_CN/10_制作QSPI Flash启动的Linux_CN
   7Z020B_S4_RSTdocument_CN/11_QT在ZYNQ上的应用_CN
   7Z020B_S4_RSTdocument_CN/12_OpenCV应用_CN
   7Z020B_S4_RSTdocument_CN/13_双目摄像头模块OpenCV显示_CN
   7Z020B_S4_RSTdocument_CN/14_触摸屏模块应用_CN
   7Z020B_S4_RSTdocument_CN/15_AXI DMA读写测试_CN
   7Z020B_S4_RSTdocument_CN/16_基于DMA的ADC波形显示AN9238_CN
   7Z020B_S4_RSTdocument_CN/17_基于DMA的ADC波形显示AN706_CN
   7Z020B_S4_RSTdocument_CN/18_自动运行的petalinux应用程序_CN

.. toctree::
   :maxdepth: 1
   :caption: Alinx版权

   7Z020B_S1_RSTdocument_CN/00_责任声明_CN

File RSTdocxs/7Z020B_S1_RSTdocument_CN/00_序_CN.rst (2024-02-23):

序
====

首先感谢大家购买芯驿电子科技（上海）有限公司出品的ZYNQ的开发板AX7Z010、AX7Z020！
您对我们和我们产品的支持和信任,给我们增添了永往直前的信心和勇气。

“播下一粒种子，收获一片森林”，更是芯驿电子科技（上海）有限公司的美好愿望，同时我们会在 GitHub 上和大家一起讨论，一起学习，一起进步，一起成长。

有人要问零基础能不能学习ZYNQ？那要看这个零在哪里，如果连原理图都看不懂，C语言里数组是什么都不知道，对指针完全没有概念，这是负基础，学习ZYNQ要有基本的硬件知识，熟练的C语言功底。

本教程为基础教程，通过不断练习，掌握ZYNQ开发的基本流程，虽然没有讲解很多大道理，但是熟能生巧，多多练习，逐渐掌握其中的奥秘。

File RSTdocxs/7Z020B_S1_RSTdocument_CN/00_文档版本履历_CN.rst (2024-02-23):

文档版本履历
============

Copyright ©2012-2024 芯驿电子科技（上海）有限公司

公司网址:

Http://www.alinx.com.cn

官方旗舰店：

http://alinx.jd.com

邮箱:

avic@alinx.com.cn

电话:

021-67676997

传真：

021-37737073

ALINX微信公众号：



文档修订记录:

+---------+--------------+--------------------------------------------+
| 版本    | 时间         | 描述                                       |
+=========+==============+============================================+
| 1.01    | 2024/1/12    | 2017v1.06版本更新至2023v1.01版本           |
+---------+--------------+--------------------------------------------+
|         |              |                                            |
+---------+--------------+--------------------------------------------+
|         |              |                                            |
+---------+--------------+--------------------------------------------+
|         |              |                                            |
+---------+--------------+--------------------------------------------+
|         |              |                                            |
+---------+--------------+--------------------------------------------+
|         |              |                                            |
+---------+--------------+--------------------------------------------+
|         |              |                                            |
+---------+--------------+--------------------------------------------+
|         |              |                                            |
+---------+--------------+--------------------------------------------+
|         |              |                                            |
+---------+--------------+--------------------------------------------+
|         |              |                                            |
+---------+--------------+--------------------------------------------+

我们承诺本教程并非一劳永逸，固守不变的文档。我们会根据论坛上大家的反馈意见，以及实际的开发实践经验积累不断的修正和优化教程

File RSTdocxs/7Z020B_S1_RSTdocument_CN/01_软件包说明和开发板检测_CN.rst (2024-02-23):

软件包说明和开发板检测
========================

为了您方便找到教程中所用到的软件、源码包、驱动等，下面会介绍一下软件包里主要内容，教程中难免有疏漏之处，找不到时麻烦您搜索一下您的电脑。

软件包说明
----------


    
1) CP210x_Windows_Drivers.zip 串口驱动

2) **Xilinx_Unified_2023.1_0507_1903.tar.gz** Vivado
   2023.1安装包，Windows和Linux通用版本，Windows下需要WinRAR解压软件。

3) petalinux-v2023.1-final-installer.run petalinux安装包

4) qt-opensource-windows-x86-mingw530-5.7.1.exe Windows版本QT

5) qt-opensource-linux-x64-5.7.1.run Linux版本QT

6) imageUSB.exe 镜像恢复工具

7) 00_resource内包含Linux源代码、根文件系统

8) VMware-workstation-full-12.1.1-3770994.exe 虚拟机安装包

9) ubuntu-16.04.3-desktop-amd64.iso
   Ubuntu安装包，只能装在PC上，不能装开发板

开发板检测
----------

拿到开发板，大部分人都想立即体验一下，看看开发板是否正常工作，下面我们介绍如何对开发板进行一个简单的检测。

测需要自备的工具
~~~~~~~~~~~~~~~~

1) 电脑


    
2) 另外一台支持HDMI的显示器，要求分辨率不小于1920x1080，开发板不支持无电源HDMI转VGA转换器，需要使用单独供电的转换器。


    
3) HDMI线缆1条


    
4) USB鼠标键盘


    
5) 路由器，为了测试网络，最好能连接互联网，支持DHCP，这个非常重要，特别是对于那些不会配置网络的开发人员，如果是校园网，特殊运行商宽带，还要特殊路由器。


    
6) 网线


    
开发板线缆连接
~~~~~~~~~~~~~~

1) 连接HDMI显示器

2) 连接网口到路由器

3) 连接电源


    
开始测试
~~~~~~~~

1) 测试前我们需要安装USB转串口的驱动软件（软件/CP210x_Windows_Drivers.zip），不然无法做串口通信测试，双击exe文件进行驱动安装。驱动安装好以后，用红色USB线连接电脑USB口和开发板上的UART口(J7)进行连接,
   然后打开电脑的设备管理器，设备管理器能够找到串口设备CP210x,
   我机器上映射的是COM3。如果不能成功安装驱动，可以尝试使用驱动精灵安装。


    

    

    
2) 终端工具有很多，例如putty，teraterm,
   Windows自带终端工具，SecureCRT等等，众多终端工具中，比较下来，还是putty最好用，资料（软件/
   putty.exe）为大家准备了绿色免安装的putty软件。

3) 选择Serial，Serial
   line填写COM3，Speed填写115200，COM3串口号根据设备管理器里显示的填写


    
选择Serial，并将流控Flow control改为None，点击“Open”


    

    
启动后界面

4) 确定开发板启动模式是否为SD启动模式（默认出厂时开发板的SD卡插槽里有卡，启动模式默认也是SD卡），通过跳冒修改启动模式。


    
5) 打开开发板上的电源开关，PuTTY工具窗口会显示u-boot和Linux系统的启动信息。


    
6) 可以在串口终端登陆系统，用户: root，密码: root

有很多人是第一次接触Putty，或者是第一次用串口，需要说明的是，Putty输入命令是通过主机键盘输入，不是通过连接在开发板上的键盘输入


    
7) 启动完成后连接开发板HDMI显示器会显示Debian的桌面。可能会提示选择面板，选择默认面板配置就可以。


    

    
8) 这时可以使用连接到鼠标和键盘来操作了，用鼠标双击Web浏览器，启动浏览器时间较长，请耐心等待。


    
9) 地址栏输入网址，我们这里输入黑金动力社区的网址。正常打开，我们的开发板已经能正常上网了。提示一下，不要使用浏览器带的搜索功能，因为国内无法使用谷歌搜索。\ **这里需要说明：有些公司、学校网络有网络管制，不是任意设备都能连接互联网，建议先咨询网络管理员**\ 。


    
10) 开发板的简单检测到此结束。

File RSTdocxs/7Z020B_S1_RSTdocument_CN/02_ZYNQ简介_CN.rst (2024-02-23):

ZYNQ简介
==========

Zynq系列的亮点在于FPGA里包含了完整的ARM处理子系统（PS），每一颗Zynq系列的处理器都包含了Cortex-A9处理器，整个处理器的搭建都以处理器为中心，
而且处理器子系统中集成了内存控制器和大量的外设，
使Cortex-A9的核在Zynq-7000中完全独立于可编程逻辑单元，也就是说如果暂时没有用到可编程逻辑单元部分（PL），
ARM处理器的子系统也可以独立工作，这与以前的FPGA有本质区别，其是以处理器为中心的。

Zynq就是两大功能块，PS 部分和 PL部分，
说白了，就是ARM的SOC部分，和FPGA部分。其中，PS集成了两个ARM
Cortex™-A9处理器，AMBA®互连，内部存储器，外部存储器接口和外设。这些外设主要包括USB总线接口，以太网接口，SD/SDIO接口，I2C总线接口，CAN总线接口，UART接口，GPIO等。


    
ZYNQ芯片的总体框图

PS: 处理系统 （Processing System) , 就是与FPGA无关的ARM的SOC的部分。

PL: 可编程逻辑 (Progarmmable Logic), 就是FPGA部分。

*PL部分是与7系列一样的，在DS190文档中可以看到对应的7系列产品。*


    
PS和PL互联技术 
---------------

ZYNQ作为首款将高性能ARM
Cortex-A9系列处理器与高性能FPGA在单芯片内紧密结合的产品，为了实现ARM处理器和FPGA之间的高速通信和数据交互，发挥ARM处理器和FPGA的性能优势，需要设计高效的片内高性能处理器与FPGA之间的互联通路。因此，如何设计高效的PL和PS数据交互通路是ZYNQ芯片设计的重中之重，也是产品设计的成败关键之一。本节，我们就将主要介绍PS和PL的连接，让用户了解PS和PL之间连接的技术。

其实，在具体设计中我们往往不需要在连接这个地方做太多工作，我们加入IP核以后，系统会自动使用AXI接口将我们的IP核与处理器连接起来，我们只需要再做一点补充就可以了。

AXI全称Advanced eXtensible
Interface，是Xilinx从6系列的FPGA开始引入的一个接口协议，主要描述了主设备和从设备之间的数据传输方式。在ZYNQ中继续使用，版本是AXI4，所以我们经常会看到AXI4.0，ZYNQ内部设备都有AXI接口。其实AXI就是ARM公司提出的AMBA（Advanced
Microcontroller Bus
Architecture）的一个部分，是一种高性能、高带宽、低延迟的片内总线，也用来替代以前的AHB和APB总线。第一个版本的AXI（AXI3）包含在2003年发布的AMBA3.0中，AXI的第二个版本AXI（AXI4）包含在2010年发布的AMBA
4.0之中。

AXI协议主要描述了主设备和从设备之间的数据传输方式，主设备和从设备之间通过握手信号建立连接。当从设备准备好接收数据时，会发出READY信号。当主设备的数据准备好时，会发出和维持VALID信号，表示数据有效。数据只有在VALID和READY信号都有效的时候才开始传输。当这两个信号持续保持有效，主设备会继续传输下一个数据。主设备可以撤销VALID信号，或者从设备撤销READY信号终止传输。AXI的协议如图，T2时，从设备的READY信号有效，T3时主设备的VILID信号有效，数据传输开始。


    
AXI握手时序图

在ZYNQ中，支持AXI-Lite，AXI4和AXI-Stream三种总线，通过表5-1,我们可以看到这三中AXI接口的特性。

+----------------------+----------------------+------------------------+
| 接口协议             | 特性                 | 应用场合               |
+======================+======================+========================+
| AXI4-Lite            | 地址/单数据传输      | 低速外设或控制         |
+----------------------+----------------------+------------------------+
| AXI4                 | 地址/突发数据传输    | 地址的批量传输         |
+----------------------+----------------------+------------------------+
| AXI4-Stream          | 仅传输数据，突发传输 | 数据流和媒体流传输     |
+----------------------+----------------------+------------------------+

AXI4-Lite：

具有轻量级，结构简单的特点，适合小批量数据、简单控制场合。不支持批量传输，读写时一次只能读写一个字（32bit）。主要用于访问一些低速外设和外设的控制。

AXI4：

接口和AXI-Lite差不多，只是增加了一项功能就是批量传输，可以连续对一片地址进行一次性读写。也就是说具有数据读写的burst功能。

上面两种均采用内存映射控制方式，即ARM将用户自定义IP编入某一地址进行访问，读写时就像在读写自己的片内RAM，编程也很方便，开发难度较低。代价就是资源占用过多，需要额外的读地址线、写地址线、读数据线、写数据线、写应答线这些信号线。

AXI4-Stream：

这是一种连续流接口，不需要地址线（很像FIFO，一直读或一直写就行）。对于这类IP，ARM不能通过上面的内存映射方式控制（FIFO根本没有地址的概念），必须有一个转换装置，例如AXI-DMA模块来实现内存映射到流式接口的转换。AXI-Stream适用的场合有很多：视频流处理；通信协议转换；数字信号处理；无线通信等。其本质都是针对数值流构建的数据通路，从信源（例如ARM内存、DMA、无线接收前端等）到信宿（例如HDMI显示器、高速AD音频输出，等）构建起连续的数据流。这种接口适合做实时信号处理。

AXI4和AXI4-Lite接口包含5个不同的通道：

-  Read Address Channel

-  Write Address Channel

-  Read Data Channel

-  Write Data Channel

-  Write Response Channel

其中每个通道都是一个独立的AXI握手协议。下面两个图分别显示了读和写的模型：


    
AXI读数据通道


    
AXI写数据通道

在ZYNQ芯片内部用硬件实现了AXI总线协议，包括9个物理接口，分别为AXI-GP0~AXI-GP3，AXI-HP0~AXI-HP3，AXI-ACP接口。

AXI_ACP接口，是ARM多核架构下定义的一种接口，中文翻译为加速器一致性端口，用来管理DMA之类的不带缓存的AXI外设，PS端是Slave接口。

AXI_HP接口，是高性能/带宽的AXI3.0标准的接口，总共有四个，PL模块作为主设备连接。主要用于PL访问PS上的存储器（DDR和On-Chip
RAM）

AXI_GP接口，是通用的AXI接口，总共有四个，包括两个32位主设备接口和两个32位从设备接口。


    
可以看到，只有两个AXI-GP是Master Port，即主机接口，其余7个口都是Slave
Port（从机接口）。主机接口具有发起读写的权限，ARM可以利用两个AXI-GP主机接口主动访问PL逻辑，其实就是把PL映射到某个地址，读写PL寄存器如同在读写自己的存储器。其余从机接口就属于被动接口，接受来自PL的读写，逆来顺受。

另外这9个AXI接口性能也是不同的。GP接口是32位的低性能接口，理论带宽600MB/s，而HP和ACP接口为64位高性能接口，理论带宽1200MB/s。有人会问，为什么高性能接口不做成主机接口呢？这样可以由ARM发起高速数据传输。答案是高性能接口根本不需要ARM
CPU来负责数据搬移，真正的搬运工是位于PL中的DMA控制器。

位于PS端的ARM直接有硬件支持AXI接口，而PL则需要使用逻辑实现相应的AXI协议。Xilinx在Vivado开发环境里提供现成IP如AXI-DMA，AXI-GPIO，AXI-Dataover,
AXI-Stream都实现了相应的接口，使用时直接从Vivado的IP列表中添加即可实现相应的功能。下图为Vivado下的各种DMA
IP：


    
下面为几个常用的AXI接口IP的功能介绍：

AXI-DMA：实现从PS内存到PL高速传输高速通道AXI-HP<---->AXI-Stream的转换

AXI-FIFO-MM2S：实现从PS内存到PL通用传输通道AXI-GP<----->AXI-Stream的转换

AXI-Datamover：实现从PS内存到PL高速传输高速通道AXI-HP<---->AXI-Stream的转换，只不过这次是完全由PL控制的，PS是完全被动的。

AXI-VDMA：实现从PS内存到PL高速传输高速通道AXI-HP<---->AXI-Stream的转换，只不过是专门针对视频、图像等二维数据的。

AXI-CDMA：这个是由PL完成的将数据从内存的一个位置搬移到另一个位置，无需CPU来插手。

关于如何使用这些IP，我们会在后面的章节中举例讲到。有时，用户需要开发自己定义的IP同PS进行通信，这时可以利用向导生成对应的IP。用户自定义IP核可以拥有AXI4-Lite，AXI4，AXI-Stream，PLB和FSL这些接口。后两种由于ARM这一端不支持，所以不用。

有了上面的这些官方IP和向导生成的自定义IP，用户其实不需要对AXI时序了解太多（除非确实遇到问题），因为Xilinx已经将和AXI时序有关的细节都封装起来，用户只需要关注自己的逻辑实现即可。

AXI协议严格的讲是一个点对点的主从接口协议，当多个外设需要互相交互数据时，我们需要加入一个AXI
Interconnect模块，也就是AXI互联矩阵，作用是提供将一个或多个AXI主设备连接到一个或多个AXI从设备的一种交换机制（有点类似于交换机里面的交换矩阵）。

这个AXI Interconnect
IP核最多可以支持16个主设备、16个从设备，如果需要更多的接口，可以多加入几个IP核。

AXI Interconnect基本连接模式有以下几种：

-  N-to-1 Interconnect

-  to-N Interconnect

-  N-to-M Interconnect (Crossbar Mode)

-  N-to-M Interconnect (Shared Access Mode)


    
多对一的情况


    
一对多的情况


    
多对多读写地址通道


    
多对多读写数据通道

ZYNQ内部的AXI接口设备就是通过互联矩阵的的方式互联起来的，既保证了传输数据的高效性，又保证了连接的灵活性。Xilinx在Vivado里我们提供了实现这种互联矩阵的IP核axi_interconnect，我们只要调用就可以。


    
AXI Interconnect IP

ZYNQ芯片开发流程的简介
----------------------

由于ZYNQ将CPU与FPGA集成在了一起，开发人员既需要设计ARM的操作系统应用程序和设备的驱动程序，又需要设计FPGA部分的硬件逻辑设计。开发中既要了解Linux操作系统，系统的构架，也需要搭建一个FPGA和ARM系统之间的硬件设计平台。所以ZYNQ的开发是需要软件人员和硬件硬件人员协同设计并开发的。这既是ZYNQ开发中所谓的"软硬件协同设计”。

ZYNQ系统的硬件系统和软件系统的设计和开发需要用到一下的开发环境和调试工具：
Xilinx Vivado。

Vivado设计套件实现FPGA部分的设计和开发，管脚和时序的约束，编译和仿真，实现RTL到比特流的设计流程。Vivado并不是ISE设计套件的简单升级，而是一个全新的设计套件。它替代了ISE设计套件的所有重要工具，比如Project
Navigator、Xilinx Synthesis Technology、Implementation、CORE
Generator、Constraint、Simulator、Chipscope Analyzer、FPGA
Editor等设计工具。

Xilinx Vitis（Software Development Kit），
Vitis是Xilinx软件开发套件(Vitis),在Vivado硬件系统的基础上，系统会自动配置一些重要参数，其中包括工具和库路径、编译器选项、JTAG和闪存设置，调试器连接已经裸机板支持包(BSP)。Vitis也为所有支持的Xilinx
IP硬核提供了驱动程序。Vitis支持IP硬核（FPGA上）和处理器软件协同调试，我们可以使用高级C或C++语言来开发和调试ARM和FPGA系统，测试硬件系统是否工作正常。Vitis软件也是Vivado软件自带的，无需单独安装。

ZYNQ的开发也是先硬件后软件的方法。具体流程如下：

1) 在Vivado上新建工程，增加一个嵌入式的源文件。

2) 在Vivado里添加和配置PS和PL部分基本的外设，或需要添加自定义的外设。

3) 在Vivado里生成顶层HDL文件，并添加约束文件。再编译生成比特流文件（\*.bit）。

4) 导出硬件信息到Vitis软件开发环境，在Vitis环境里可以编写一些调试软件验证硬件和软件，结合比特流文件单独调试ZYNQ系统。

5) 在Vitis里生成FSBL文件。

6) 在VMware虚拟机里生成u-boot.elf、 bootloader 镜像。

7) 在Vitis里通过FSBL文件,
   比特流文件system.bit和u-boot.elf文件生成一个BOOT.bin文件。

8) 在VMware里生成Ubuntu的内核镜像文件Zimage和Ubuntu的根文件系统。另外还需要要对FPGA自定义的IP编写驱动。

9) 把BOOT、内核、设备树、根文件系统文件放入到SD卡中，启动开发板电源，Linux操作系统会从SD卡里启动。

以上是典型的ZYNQ开发流程，但是ZYNQ也可以单独做为ARM来使用，这样就不需要关系PL端资源，和传统的ARM开发没有太大区别。ZYNQ也可以只使用PL部分，但是PL的配置还是要PS来完成的，就是无法通过传统的固化Flash方式把只要PL的固件固化起来。

学习ZYNQ要具备哪些技能
----------------------

学习ZYNQ比学习FPGA、MCU、ARM等传统工具开发要求更高，想学好ZYNQ也不是一蹴而就的事情。

软件开发人员
~~~~~~~~~~~~

-  计算机组成原理

-  C、C++语言

-  计算机操作系统

-  tcl脚本

-  良好的英语阅读基础

逻辑开发人员
~~~~~~~~~~~~

-  计算机组成原理

-  C语言

-  数字电路基础

-  Verilog、VHDL语言

-  良好的英语阅读基础

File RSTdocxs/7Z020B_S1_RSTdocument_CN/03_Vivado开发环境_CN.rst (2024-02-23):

Vivado开发环境
================

Vivado软件介绍
--------------

一提起Xilinx的开发环境，人们总是先会想起ISE，而对Vivado不甚了解。其实，Vivado是Xilinx公司于2012推出的新一代集成设计
环境。虽然目前其流行度并不高，但可以说Vivado代表了未来Xilinx
FPGA开发环境的变化趋势。所以，作为一个Xilinx
FPGA的开发使用者，学习掌握Vivado是趋势，也是必然。作为开发者，首先肯定有以下疑惑：既然已经有ISE存在了，为何Xilinx公司又花大力气去搞什么Vivado呢？在Vivado
Design Suite User Guide : Getting
Started(UG910)中提到，推出Vivado是为了提高设计者的效率，它能显著增加Xilinx的28nm工艺的可编程逻辑器件的设计、综合与
实现效率。可以推测，随着FPGA进入28nm时代，ISE工具似乎就有些“不合时宜”了，硬件提升了，软件不提升的话，设计效率必然受影响。正是出于这
一考虑，Xilinx公司于2008年开始便筹划推出新一代的软件开发环境，经历10年时间打造出了Vivado工具这一巅峰之作。

Vivado软件版本
--------------

Vivado的软件版本在不断的升级中，到目前为止最新的软件版本已经是2023.2了。因为ZYNQ开发板的所有例程和教程我们都在Vivado
2023.1的开发环境中完成。为了避免软件版本版本的原因而导致一些无法解释的问题，还是希望大家学习过程中与我们保持同步。用户使用之前需要安装Vivado
2023.1的软件。因为Vivado软件比较大，我们没有提供光盘安装文件，只提供下载链接，另外用户也可以到Xilinx的官网下载，官网下载需要注册相关账号。

Vivado软件的Xilinx官方下载地址：\ http://china.xilinx.com/support/download.html


       
Vivado提供了Linux版和Windows版，还提供二合一版本，我们这里使用二合一版本，既能满足Windows开发又能满足Linux开发，Vivado要求操作系统必须是64位。

Vivado软件Windows下安装
-----------------------

1) 下载解压Vivado软件压缩包，直接点击xsetup.exe，进入安装，不过为了更好的安装，请关闭杀毒软件，各种电脑管家，电脑用户名不要有中文，和空格


       

       
2) 如果提示版本更新，我们忽略更新，点击“Continue”

3) 点击“next”进行安装，可以看到Vivado对系统要求


       
4) 选择需要安装的产品，如果不需要使用Vitis（取代之前的Vitis）则仅选Vivado，一般Vivado是ZYNQ或者带有处理器硬核的芯片会用到，如果是纯FPGA硬件且自己不学习软件相关，则选择Vivado


       
5) 这里选择安装的器件库，由于我们不需要UltraScale、UltraScale+和versal芯片，可以取消勾选，节省安装空间，其他保持默认，点击“next”


       
6) 选中“I agree”，点击“next”


       
7) 安装路径这里没有修改，安装路径不能有中文、空格等特殊字符，同时电脑的用户名不要是中文、带空格的名称。可以看到Vivado对硬盘大小的要求，至少要有190G。


       
8) 点击“Install”安装


    
9) 等待安装，时间较长，如果没有关闭杀毒软件和电脑管家，安装过程可能会被拦截，导致安装软件后不能使用


    
10) 提示安装成功


    
11) 安装License文件，点击“Copy
    License”，选择“xilinx_ise_vivado.lic”文件。


    
12) 可以看到安装成功


    
重新安装驱动
------------

一般安装vivado时，都会安装下载器驱动。如果需要再次安装下载器驱动，进入vivado安装路径“X:\\XXX\\Vivado\\2023.1\\data\\xicom\\cable_drivers\\nt64\\digilent”下，双击“install_digilent.exe”文件安装，安装前先关闭vivado软件，如果vivado识别不到下载器，请尝试关闭防火墙，杀毒软件，也不能同时打开多个版本的vivado、ise。


       
安装完成后，\ **连接下载器，**\ 打开设备管理器，在通用串行总线控制器里找到USB
Serial Converter，说明安装成功



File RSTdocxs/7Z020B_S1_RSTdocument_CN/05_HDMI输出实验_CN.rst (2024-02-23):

HDMI输出实验
==============

**实验Vivado工程为“hdmi_output_test”。**

**本章内容主要由FPGA工程师负责实现。**

前面我们介绍了led闪灯实验，只是为了了解Vivado的基本开发流程，本章这个实验相对LED闪灯实验复杂点，做一个HDMI输出的彩条，这也是我们后面学习显示、视频处理的基础。实验还不涉及到PS系统，从实验设计可以看出如果要非常好的使用ZYNQ芯片，需要良好的FPGA基础知识。

硬件介绍
--------

开发板没有使用HDMI编码芯片，而是将FPGA的3.3V差分IO直接连接到HDMI连接器，
FPGA完成24位RGB编码输出TMDS差分信号。


    
在做HDMI显示之前，我们需要思考一个问题，产生HDMI图像数据需要哪些要素，如果各位了解过图像的时序应该清楚，无非是图像的像素时钟，图像时序，以及图像数据。当然不同的分辨率时钟和时序也是不同的，具体的可以网上搜索各种分辨率的时序参数。在此不再赘述。本实验仅提供了720p的时序参数（color_bar.v文件中）。


    
Vivado工程建立
--------------

1) 新建一个名为“hdmi_output_test”的工程

添加HDMI 编码器IP核
~~~~~~~~~~~~~~~~~~~

VGA的数据很多人都比较清楚，为RGB数据，而HDMI为TMDS差分信号，RGB数据在FPGA比较容易操作，那么我们需要做的就是把RGB数据转成HDMI的TMDS差分信号，因此采用了RGB
to DVI的IP（DVI与HDMI都是TMDS信号）。

2) 复制repo文件夹（这个文件夹可以到给的例程工程中找到）到工程目录，这个文件夹里包含了HDMI编码器的IP，是别的厂家提供


    
3) 点击“IP
   Catalog”，默认这些IP和都是Xilinx提供，现在我们要添加第三方IP，或者我们自己做的IP


    
4) 右键“Add Repository...”


    
5) 路径选择刚才复制的repo文件夹


    
6) 添加IP成功提示添加了多少个IP


    
7) 找到“RGB to DVI Video Encoder(Source)”，双击


    
8) 弹出下面窗口，“Component
   Name”元件名保持不变，其他参数也不用改，点击“OK”


    
9) 弹出一个“Generate Output Products”窗口，其中“Number of
   jobs”指线程数量，越高越快


    
10) 可以看到一个名为rgb2dvi_0


    
添加像素时钟PLL模块
~~~~~~~~~~~~~~~~~~~

为了驱动HDMI编码器，需要提供像素时钟和5倍像素时钟，5倍像素时钟用于10:1串行化。

11) 在“IP Catlog”窗口搜索关键字“clock”，双击“Clocking Wizard”


    
12) 这次给元件起个名字，在“Component
    Name”中填写“video_clock”，“clk_in1”填写50，这里50Mhz和开发板PL端晶振频率一致。


    
13) 输出时钟“clk_out1”用于视频像素时钟，这里填写74.25，这是1280x720@60分辨率的像素时钟，每一种分辨率的像素时钟都不同，需要非常了解视频标准才能知道每一种视频分辨率的像素时钟，“clk_out2”用于编码器串行化，像素时钟的5倍，这里填写371.25，然后点击“OK”生成IP。


    
添加彩条发生模块
~~~~~~~~~~~~~~~~

14) 彩条发生模块是一段Verilog代码，用于产生视频时序和水平方向的8个彩条，FPGA不是本开发学习重点，不再详细讲解代码，可以到给的例程中复制现有代码。


    
添加顶层模块
~~~~~~~~~~~~

15) top模块例化了彩条发生模块，HDMI编码模块，和像素时钟生成模块，代码参考例程给的工程。


    
添加XDC约束文件
---------------

添加以下的xdc约束文件到项目中，在约束文件里添加了时钟和HDMI相关的管脚。


    
::

 set_property PACKAGE_PIN U18 [get_ports {sys_clk}]
 set_property IOSTANDARD LVCMOS33 [get_ports {sys_clk}]
 create_clock -period 20.000 -waveform {0.000 10.000} [get_ports sys_clk]
 set_property IOSTANDARD TMDS_33 [get_ports TMDS_clk_n]
 set_property PACKAGE_PIN U13 [get_ports TMDS_clk_p]
 set_property IOSTANDARD TMDS_33 [get_ports TMDS_clk_p]
 set_property IOSTANDARD TMDS_33 [get_ports {TMDS_data_n[0]}]
 set_property PACKAGE_PIN W14 [get_ports {TMDS_data_p[0]}]
 set_property IOSTANDARD TMDS_33 [get_ports {TMDS_data_p[0]}]
 set_property IOSTANDARD TMDS_33 [get_ports {TMDS_data_n[1]}]
 set_property PACKAGE_PIN Y18 [get_ports {TMDS_data_p[1]}]
 set_property IOSTANDARD TMDS_33 [get_ports {TMDS_data_p[1]}]
 set_property IOSTANDARD TMDS_33 [get_ports {TMDS_data_n[2]}]
 set_property PACKAGE_PIN Y16 [get_ports {TMDS_data_p[2]}]
 set_property IOSTANDARD TMDS_33 [get_ports {TMDS_data_p[2]}]
 set_property PACKAGE_PIN V16 [get_ports hdmi_oen]
 set_property IOSTANDARD LVCMOS33 [get_ports hdmi_oen]

下载调试
--------

保存工程并编译生成bit文件，连接HDMI接口到HDMI显示器，需要注意，这里使用1280x720@60Hz，请确保自己的显示器支持这个分辨率。


    
下载后显示器显示如下图像


    
实验总结
--------

本实验初步接触到视频显示，涉及到视频知识，这不是zynq学习的重点，所以没有详细介绍，但zynq在视频处理领域用途广泛，需要学习者有良好的基础知识。实验中仅仅使用PL来驱动HDMI芯片，初步学习了第三方自定IP的用法，后面我们会学习如何自定义IP。

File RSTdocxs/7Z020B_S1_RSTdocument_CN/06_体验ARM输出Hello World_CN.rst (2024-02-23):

体验ARM，裸机输出“Hello World”
================================

**实验Vivado工程为“ps_hello”。**

**从本章开始由FPGA工程师与软件开发工程师协同实现。**

前面的实验都是在PL端进行的，可以看到和普通FPGA开发流程没有任何区别，ZYNQ的主要优势就是FPGA和ARM的合理结合，这对开发人员提出了更高的要求。从本章开始，我们开始使用ARM，也就是我们说的PS，本章我们使用一个简单的串口打印来体验一下Vivado
Vitis和PS端的特性。

前面的实验都是FPGA工程师应该做的事情，从本章节开始就有了分工，FPGA工程师负责把Vivado工程搭建好，提供好硬件给软件开发人员，软件开发人员便能在这个基础上开发应用程序。做好分工，也有利于项目的推进。如果是软件开发人员想把所有的事情都做了，可能需要花费很多时间和精力去学习FPGA的知识，由软件思维转成硬件思维是个比较痛苦的过程，如果纯粹的学习，又有时间，就另当别论了。专业的人做专业的事，是个很好的选择。

硬件介绍
--------

我们从原理图中可以看到ZYNQ芯片分为PL和PS，PS端的IO分配相对是固定的，不能任意分配，而且不需要在Vivado软件里分配管脚，虽然本实验仅仅使用了PS，但是还要建立一个Vivado工程，用来配置PS管脚。虽然PS端的ARM是硬核，但是在ZYNQ当中也要将ARM硬核添加到工程当中才能使用。前面章节介绍的是代码形式的工程，本章开始介绍ZYNQ的图形化方式建立工程。

FPGA工程师工作内容
------------------

下面介绍FPGA工程师负责内容。

Vivado工程建立
--------------

1) 创建一个名为“ps_hello”的工程，建立过程不再赘述，参考“PL的”Hello
   World”LED实验”。

2) 点击“Create Block Design”，创建一个Block设计，也就是图形化设计


    
3) “Design
   name”这里不做修改，保持默认“design_1”，这里可以根据需要修改，不过名字要尽量简短，否则在Windows下编译会有问题。


    
4) 点击“Add IP”快捷图标


    
5) 搜索“zynq”，在搜索结果列表中双击“ZYNQ7 Processing System”


    
6) 双击Block图中的“processing_system7_0”，配置相关参数


    
7) 首先出现的界面是ZYNQ硬核的架构图，可以很清楚看到它的结构，可以参考ug585文档，里面有对ZYNQ的详细介绍。图中绿色部分是可配置模块，可以点击进入相应的编辑界面，当然也可以在左侧的窗口进入编辑。下面对各个窗口的功能一一介绍。


    
8) 接下来是PS-PL
   Configuration界面，这个界面主要是进行PS与PL之间接口的配置，主要是AXI接口，这些接口可以扩展PL端的AXI接口外设，所以PL如果要和PS进行数据交互，都要按照AXI总线协议进行，xilinx为我们提供了大量的AXI接口的IP
   核。在这里保持默认，在后面的章节中会对其配置，本章节不与PL端进行交互，保持默认。


    
9) 之后进入PS端外设的配置阶段，一开始接触ZYNQ可能会很疑惑，看到密密麻麻的外设，无从下手。这里解释一下，ZYNQ的PS端外设很多是复用的，相同的引脚标号可以配置成不一样的功能，比如下图中的16-27可以配置成Enet0，也可以配置成SD0、SD1，但只能配置成一种外设，比如如果配置Enet0，也就不能再选择SD0、SD1了。
至于该怎么去选择，是由原理图和PCB决定的，可以通过查看原理图或用户手册选择。


    

    
PS端外设原理图

PS端外设配置
~~~~~~~~~~~~

1)  从原理图中我们可以找到串口连接在PS的MIO48-MIO49上，所以在“Peripheral
    I/O Pins”选项中使能UART1（MIO48 MIO49），PS端MIO分为两个Bank，Bank 0
    ，也就是原理图中的BANK500，电压选择“LVCMOS 3.3V”，Bank
    1，也就是原理图中的BANK501，电压选择“LVCOMS 1.8
    V”。\ **如果不配置Bank1电平标准，可能导致串口无法接收**\ 。


    
11) 配置QSPI，QSPI可以作为ZYNQ的启动存储设备，ZYNQ可以通过读取QSPI中存储的启动文件加载ARM和FPGA，从原理图得知，我们选择Quad
    SPI Flash为Single SS 4bit IO，并且勾选上fb引脚。


    
12) 配置以太网，在PS端设计有以太网接口，根据原理图选择Ethernet
    0到MIO16-MIO27


    
MDIO为以太网PHY寄存器配置接口，选择MDIO并配置到MIO52-MIO53


    
13) 配置USB0到MIO28-MIO39


    
14) 除了QSPI启动ZYNQ，还有SD卡模式启动ZYNQ，选择SD
    0，配置到MIO40-MIO45，选择Card Detection MIO47，用于检测SD卡的插入。


    
15) 打开GPIO MIO，PS便可以控制剩余未分配的MIO，用作GPIO


    
在GPIO MIO中选择MIO46作为USB PHY的复位


    
至此，外设配置结束。

MIO配置
~~~~~~~

修改Enet0的电平标准为HSTL 1.8V，Speed 为
fast，这些参数非常重要，如果不修改，网络可能不通。其他部分保持默认。


    
时钟配置
~~~~~~~~

16) 在“Clock
    Configuration”选项卡中我们可以配置PS时钟输入时钟频率，这里默认是33.333333，和板子上一致，不用修改，CPU频率默认666.666666Mhz，这里也不修改。同时PS还可以给PL端提供4路时钟，频率可以配置，这里不需要，所以保持默认即可。还有PS端外设的时钟等也可以进行配置，这里保持默认。


    
DDR3配置
~~~~~~~~

17) 在“DDR
Configuration”选项卡中可以配置PS端ddr的参数，配置DDR3型号为“MT41J256M16
RE-125”，\ **这里ddr3型号并不是板子上的ddr3型号，而是参数最接近的型号**\ 。Effective
DRAM Bus Width”，选择“32 Bit”


    
DDR3配置

其他部分保持默认，点击OK。至此ZYNQ核的配置结束。

18) 点击“Run Block Automation”，vivado软件会自动完成一些导出端口的工作


    
19) 按照默认点击“OK”


    
20) 点击“OK”以后我们可以看到PS端导出一些管脚，包括DDR还有FIXED_IO，DDR是DDR3的接口信号，FIXED_IO为PS端固定的一些接口，比如输入时钟，PS端复位信号，MIO等。


    
21) 连接FCLK_CLK0到M_AXI_GP0_ACLK，按Ctrl+S保存设计


    
*知识点：DDR和FIXED_IO是PS端引脚，PS_PORB为PS端上电复位信号，不能用于PL端复位，不要将PL端的复位绑定到这个引脚号上，切记！！！*


    
22) 选择Block设计，右键“Create HDL
Wrapper...”,创建一个Verilog或VHDL文件，为block
design生成HDL顶层文件。


    
23) 保持默认选项，点击“OK”


    
24) 展开设计可以看到PS被当成一个普通IP 来使用。


    
25) 选择block设计，右键“Generate Output
    Products”，此步骤会生成block的输出文件，包括IP，例化模板，RTL源文件，XDC约束，第三方综合源文件等等。供后续操作使用。


    
26) 点击“Generate”


    
27) 其实并不是说PS端的引脚不需要绑定，而是在IP生成的输出文件里已经包含了PS端引脚分配的XDC文件，在IP
Sources，Block
Designsdesign_1Synthesis中，可以看到处理器的XDC文件，绑定了PS端的IO，因此不需要再新建XDC绑定这些引脚。


    
28) 在菜单栏“File -> Export -> Export
Hardware...”导出硬件信息，这里就包含了PS端的配置信息。


    
29) 在弹出的对话框中点击“next”，因为实验仅仅是使用了PS的串口，不需要PL参与，这里就没有使能“Include
bitstream”，继续步骤直到finish。


    

    

    

    

    
此时刚刚的路径下就会输出一个xsa文件，这个文件就是这个文件就包含了Vivado硬件设计的信息，供软件开发人员使用。

\ 到此为止，FPGA工程师工作告一段落。

软件工程师工作内容
------------------

以下为软件工程师负责内容。

Vitis调试
---------

创建Application工程
~~~~~~~~~~~~~~~~~~~

1) Vitis是独立的软件，我们可以通过ToolsLaunch Vitis打开Vitis软件


    
也可以需要双击Vitis软件打开


       
选择之前新建的文件夹，点击”Launch”


       
2) 启动Vitis之后界面如下，点击“Create Application
Project”，这个选项会生成APP工程以及Platfrom工程，Platform工程类似于以前版本的hardware
platform，包含了硬件支持的相关文件以及BSP。


       
3) 点击Next


       
4) 点击“Create a new platform
hardware(XSA)，软件已经提供了一些板卡的硬件平台，但对于我们自己的硬件平台，可以选择”+”


       
5) 选择之前生成的xsa，点击打开


       
6) 最下面的Generate boot
components选项，如果勾选上，软件会自动生成fsbl工程，我们一般选择默认勾选上。点击Next


       
7) 项目名称填入“hello”，也可以根据自己的需要填写,CPU默认选择ps7_cortexa9_0，OS选择standalone，点击Next


       

       
8) 模板选择Hello World，点击Finish


       
9) 完成之后可以看到生成了两个工程，一个是硬件平台工程，即之前所说的Platfrom工程，一个是APP工程


       
10) 展开Platform工程后可以看到里面包含有BSP工程，以及zynq_fsbl工程（此工程即选择Generate
boot
components之后的结果）,双击platform.spr即可看到Platform对应生成的BSP工程，可以在这里对BSP进行配置。软件开发人员比较清楚，BSP也就是Board
Support
Package板级支持包的意思，里面包含了开发所需要的驱动文件，用于应用程序开发。可以看到Platform下有多个BSP，这是跟以往的Vitis软件不一样的，其中zynq_fsbl即是fsbl的BSP，standalone
on
ps7_cortexa9_0即是APP工程的BSP。也可以在Platform里添加BSP，在以后的例程中再讲。


       
11) 点开BSP，即可看到工程带有的外设驱动，其中Documentation是xilinx提供的驱动的说明文档，Import
Examples是xilinx提供的example工程，加快学习。


    
12) 选中APP工程，右键Build
Project，或者点击菜单栏的“锤子”按键，进行工程编译


    
13) 可以在Console看到编译过程


    
编译结束，生成elf文件


    
14) 连接JTAG线到开发板、UART的USB线到PC

15) 使用PuTTY软件做为串口终端调试工具，PuTTY是一个免安装的小软件


    
16) 选择Serial，Serial
line填写COM3，Speed填写115200，COM3串口号根据设备管理器里显示的填写，点击“Open”


    
17) 在上电之前最好将开发板的启动模式设置到JTAG模式


    
18) 给开发板上电，准备运行程序，开发板出厂时带有程序，这里可以把运行模式选择JTAG模式，然后重新上电。选择“hello”，右键，可以看到很多选项，本实验要用到这里的“Run
as”，就是把程序运行起来，“Run as”里又有很对选项，选择第一个“Launch
on Hardware(Single Application Debug)”，使用系统调试，直接运行程序。


    
19) 这个时候观察PuTTY软件，即可以看到输出”Hello World”


    
20) 为了保证系统的可靠调试，最好是右键“Run As -> Run Configuration...”


    
21) 我们可以看一下里面的配置，其中Reset entire
system是默认选中的，这是跟以前的Vitis软件不同的。如果系统中还有PL设计，还必须选择“Program
FPGA”。


    
22) 除了“Run As”，还可以“Debug As”，这样可以设置断点，单步运行


    
23) 进入Debug模式


    
24) 和其他C语言开发IDE一样，可以逐步运行、设置断点等


    
25) 右上角可以切换IDE模式


    
固化程序
--------

普通的FPGA一般是可以从flash启动，或者被动加载，ZYNQ的启动是由ARM主导的，包括FPGA程序的加载，ZYNQ启动一般为最少两个步骤，在UG585中也有介绍：

Stage 0
:在上电复位或者热复位之后，处理器首先执行BootRom里的代码，这一步是最初始启动设置。BootRom存放了一段用户不可更改的代码，当然是在非JTAG模式下才执行，代码里包含了最基本的NAND，NOR，Quad-SPI，SD和PCAP的驱动。另外一个很重要的作用就是把stage
1的代码搬运到OCM中，就是FSBL代码（First Stage Boot
Loader）,空间限制为192KB。

Stage 1:
接下来进入最重要的一步，当BootRom搬运FSBL到OCM后，处理开始执行FSBL代码，FSBL主要有以下几个作用：

-  初始化PS端配置，这些配置也就是在Vivado工程中对ZYNQ核的配置。包括初始化DDR，MIO，SLCR寄存器。主要是执行ps7_init.c和ps7_init.h，ps7_init.tcl的执行效果跟ps7_init.c是一样的。

-  如果有PL端程序，加载PL端bitstream

-  加载second stage bootloader或者bare-metal应用程序到DDR存储器

-  交接给second stage bootloader或bare-metal应用程序


    
Stage 2: Second stage
bootloader是可选项，一般是在跑系统的情况下使用，比如linux系统的u-boot，在这里不再介绍，后面会使用petalinux工具制作linux系统。

生成FSBL
~~~~~~~~

FSBL是一个二级引导程序，完成MIO的分配、时钟、PLL、DDR控制器初始化、SD、QSPI控制器初始化，通过启动模式查找bitstream配置FPGA，然后搜索用户程序加载到DDR，最后交接给应用程序执行。详情请参考ug821文档。

1) 由于在新建时选择了Generate boot
   components选项，所以Platform已经导入了fsbl的工程，并生成了相应的elf文件。


    
2) 添加调试宏定义FSBL_DEBUG_INFO，可以在启动输出FSBL的一些状态信息，有利于调试，但是会导致启动时间变长。保存文件。可以看一下fsbl里包含了很多外设的文件，包括ps7_init.c，nand，nor，qspi，sd等，在fsbl的main.c中，第一个运行的函数就是ps7_init，至于后面的工作，大家可以再仔细读读代码。当然这个fsbl模板也是可以修改的，至于怎么修改根据自己的需求来做。


    
3) 重新Build Project


    
4) 接下来我们可以点击APP工程的system，右键选择Build project


    
5) 这个时候就会多出一个Debug文件夹，生成了对应的BOOT.BIN


    
6) 还有一种方法就是，点击APP工程的system右键选择Creat Boot
Image，弹出的窗口中可以看到生成的BIF文件路径，BIF文件是生成BOOT文件的配置文件，还有生成的BOOT.bin文件路径，BOOT.bin文件是我们需要的启动文件，可以放到SD卡启动，也可以烧写到QSPI
Flash。


    

    
1) 在Boot image
   partitions列表中有要合成的文件，第一个文件一定是bootloader文件，就是上面生成的fsbl.elf文件，第二个文件是FPGA配置文件bitstream，在本实验中由于没有FPGA的bitstream，不需要添加，第三个是应用程序，在本实验中为hello.elf，由于没有bitstream，在本实验中只添加bootloader和应用程序。点击Create
   Image生成。


    
8) 在生成的目录下可以找到BOOT.bin文件


    
SD卡启动测试
~~~~~~~~~~~~

1) 格式化SD卡，只能格式化为FAT32格式，其他格式无法启动


    
2) 放入BOOT.bin文件，放在根目录


    
3) SD卡插入开发板的SD卡插槽

4) 启动模式调整为SD卡启动


    
5) 打开putty软件，上电启动，即可看到打印信息，红色框为FSBL启动信息，黄色箭头部分为执行的应用程序helloworld


    
QSPI启动测试
~~~~~~~~~~~~

1) 在Vitis菜单Xilinx -> Program Flash


    
2) Hardware Platform选择最新的，Image FIle文件选择要烧写的BOOT.bin，FSBL
   file选择生成的fsbl.elf，Flash Type选择qspi_dual_parallel。


    
3) 点击Program等待烧写完成


    
4) 设置启动模式为QSPI，再次启动，可以在putty里看到与SD同样的启动效果。


    
Vivado下烧写QSPI 
~~~~~~~~~~~~~~~~~

1) 在HARDWARE MANGER下选择器件，右键Add Configuration Memory Device


    
2) 选择尝试Winbond，类型选择qspi，宽度选择x4-single，这时候出现w25q128，选择红框型号，开发板使用w25q256，但是不影响烧录。


    
3) 右键选择编程文件


    
4) 选择要烧写的文件和fsbl文件，就可以烧写了，如果烧写时不是JTAG启动模式，软件会给出一个警告，所以建议烧写QSPI的时候设置到JTAG启动模式


    
使用批处理文件快速烧写QSPI
~~~~~~~~~~~~~~~~~~~~~~~~~~

1) 新建一个program_qspi.txt文本文件，扩展名改为bat,内容填写如下，其中set
   XIL_CSE_ZYNQ_DISPLAY_UBOOT_MESSAGES=1设置显示烧写过程中的uboot打印信息，

..

   C:\\Xilinx\\Vitis\\2023.1\\bin\\program_flash
   为我们工具路径，按照安装路径适当修改，-f
   为要烧写的文件，-fsbl为要烧写使用的fsbl文件（芯驿电子特定文件），-blank_check
   -verify为校验选项。

::

 set XIL_CSE_ZYNQ_DISPLAY_UBOOT_MESSAGES=1
 call C:\Xilinx\Vitis\2023.1\bin\program_flash -f BOOT.bin  -fsbl fsbl.elf  -offset 0 -flash_type qspi_single  -blank_check       -verify
 pause

1) 把要烧录的BOOT.bin、fsbl、bat文件放在一起


    
2) 插上JTAG线后上电，双击bat文件即可烧写flash。


    
常见问题
--------

仅有PL端逻辑的固化
~~~~~~~~~~~~~~~~~~

有很多人会问，如果只有PL端的逻辑，不需要PS端该怎么固化程序呢？不带ARM的FPGA固化是没问题的，但是对于ZYNQ来说，必须要有PS端的配合才能固化程序。那么对于前面的”PL的“Hello
World”LED实验”该怎么固化程序呢？

1. 根据本章的PS端添加ZYNQ核并配置，最简单的方法就是在本章工程的基础上添加LED实验的verilog源文件，并进行例化，组成一个系统，并需要生成bitstream。


    

    
2. 生成bitstream之后，导出硬件，选择include bitstream


    
3. 在生成BOOT.BIN时，还是需要一个app工程hello，仅仅是为了生成BOOT.BIN，默认情况下在system右键Build
   Project，即可生成包含bitstream的BOOT.BIN。


    
打开Create Boot Image界面可以看到，Boot Image
Partitions的文件顺序是fsbl、bitstream、app，注意顺序不要颠倒，利用这样生成的BOOT.BIN就可以按照前面的启动方式测试启动了


    
在course_s1文件夹，我们提供了一个名为led_qspi_sd的工程，大家可以参考。

使用技巧分享
------------

在频繁的修改源文件，并进行编译的时候，最好选择APP工程进行Build
Project，这种情况下只会生成elf文件。


    
如果想生成BOOT.BIN文件，可以选择system进行编译，这种情况既会生成elf也会生成BOOT.BIN，笔者最开始用的时候就吃过亏，每次编译都是选择system，结果每次都要等待生成BOOT.BIN，浪费时间，大家可以注意一下。


    
本章小结
--------

本章从FPGA工程师和软件工程师两者角度出发，介绍了ZYNQ开发的经典流程，FPGA工程师的主要工作是搭建好硬件平台，提供硬件描述文件xsa给软件工程师，软件工程师在此基础上开发应用程序。本章是一个简单的例子介绍了FPGA和软件工程师协同工作，后续还会牵涉到PS与PL之间的联合调试，较为复杂，也是ZYNQ开发的核心部分。

同时也介绍了FSBL，启动文件的制作，SD卡启动方式，QSPI下载及启动方式，Vivado下载BOOT.BIN方式，本章没有FPGA加载文件，后面的应用中会再介绍添加FPGA加载文件制作BOOT.BIN。

后续的工程都会以本章节的配置为准，后面不再介绍ZYNQ的基本配置。

千里之行，始于足下，相信经过本章的学习，大家对ZYNQ开发有了基本概念，高楼稳不稳，要看地基打的牢不牢，虽然本章较为简单，但也有很多知识点待诸位慢慢消化。加油！！！



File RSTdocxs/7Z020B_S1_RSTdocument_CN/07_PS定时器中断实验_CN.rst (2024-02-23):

PS定时器中断实验
==================

**实验Vivado工程为“ps_timer”。**

很多SOC内部都会有定时器，ZYNQ的PS也有，对于ZYNQ内到底有什么外设，这些外设有什么特性，都是开发者必须关心的，因此建议经常阅读xilinx文档UG585。本章的实验用的是CPU
Private Timer，即私有定时器。


    
ZYNQ定时器结构图

打开工程“ps_hello”，另存为一个名为”ps_timer”的工程

中断介绍
--------

翻开UG585中断部分，Zynq中断大致可分为三个部分，1为SGI，软件生成的中断，共16个端口；2为PPI，CPU私有外设中断，有5个；3为SPI，共享外设中断，来自于44个PS端的IO外设以及16个PL端的中断。中间部分为GIC，也即中断控制器，用于对中断进行使能、关闭、掩码、设置优先等。


    
以下为中断控制器框图，主要的控制器部分为ICC和ICD，ICD连接SGI和PPI，ICD连接SPI，可配置两者的寄存器来控制中断。


    
SGI中断（软件产生中断），共16个IRQ ID号


    
PPI中断，CPU私有中断，共5个IRQ ID号


    

    
SPI中断部分，共60个IRQ ID号


    

    
中断寄存器介绍
--------------

用Xilinx的API函数就可以很好的控制中断，如果有兴趣可以深入了解中断寄存器，可以对其机制有更好的认识。


    
ICDICFR:
配置寄存器，用于配置触发方式，电平触发或边沿触发，共有6个，每个寄存器32位，每两位表示一个中断，32*6/2=96个中断号，能覆盖所有中断。

ICDICFR0: IRQ ID#0~#15

ICDICFR1: IRQ ID#16~#31

ICDICFR2: IRQ ID#32~#47

ICDICFR3: IRQ ID#48~#63

ICDICFR4: IRQ ID#64~#79

ICDICFR5: IRQ ID#80~#95

对于SPI中断 0b01：高电平触发 0b11：上升沿触发

ICDIPR:
中断优先级寄存器，设置优先级，共24个寄存器，每8位代表一个中断号，共96个中断号。

ICDIPTR: CPU选择寄存器，24个寄存器，每8位代表一个中断号，共96个

0bxxxxxxx1: CPU interface 0

0bxxxxxx1x: CPU interface 1

ICDICER: 中断关闭寄存器，3个寄存器，每1位代表一个中断号，共96个

ICDISER: 中断使能寄存器，3个寄存器，每1位代表一个中断号，共96个

关于其余的寄存器，大家可以研究UG585的寄存器表中的mpcore部分。


    
软件工程师工作内容
------------------

以下为软件工程师负责内容。

Vitis程序编写
-------------

创建Platform工程
~~~~~~~~~~~~~~~~

1) 点击ToolsLaunch Vitis


    
2) 与前面的Hello World实验不同，我们只建立Platform工程


    
3) 填入工程名字，点击Next


    
4) 选择XSA文件


    
保持默认，点击Finish


    
5) 点开platform.spr，并点开BSP


    
6) 现在又到了写代码的时候了，又有了无从下手的感觉，不知道定时器怎么用，也不知道中断怎么用，还是用老方法，来看看例子


    
7) 非常幸运，有一个定时器中断的例子，怎么就知道这个例子就是中断的例子呢？是通过“intr”猜测的，所以，基本功很重要，不然你连找例程都不会。


    
下面就是阅读代码，然后修改代码了，当然，可能一下不能完全理解这些代码，只能在以后的应用中去反复练习

8) 本实验设计一个1秒定时器中断一次，然后打印出信息，30秒后结束。在UG585文档中我们得知，定时器的时钟频率为CPU频率的一半，首先要修改计数器最大值，修改为CPU频率的一半，也就是计数器的时钟频率值，这样就会1秒中断一次


    

    
CPU频率的宏定义可以在xparameters.h中找到


    
9) 修改计数次数3改为30


    
10) 添加打印信息


    
11) 了解一下中断控制器的使用，主要分为几个步骤，初始化中断控制器\ *GIC初始化中断异常中断服务函数注册在中断控制器中使能中断使能外设中断使能中断异常*\ 。有两步需要注意，\ *在中断控制器中使能中断*
是要根据中断号使能相应的中断，比如本章介绍的Timer为私有定时器，中断号为29，是在中断控制器GIC中的操作，而后面的\ *使能外设中断*
是指在外设中打开它的中断，正常情况下是不打开的，打开之后就可以产生中断传递到中断控制器GIC。在以后的实验中可以借鉴这种写法。


    

    
下载调试
--------

1) 打开PuTTY串口终端

2) 下载调试程序的方法前面教程已经讲解，不再复述


    
3) 和我们预期一样，串口每秒会输出一句信息


    
实验总结
--------

实验中通过简单的修改Vitis的例程，就完成了定时器，中断的应用，看似简单的操作，可蕴含了丰富的知识，我们需要非常了解定时器的原理、中断的原理，这些基本知识是学习好ZYNQ的必要条件。

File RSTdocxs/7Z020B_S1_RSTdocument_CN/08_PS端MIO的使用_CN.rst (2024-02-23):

PS端MIO的使用
===============

**实验Vivado工程为“ps_mio”(仅供参考，AX7Z020/AX7Z010开发板没有此工程)。**

本章介绍PS端MIO的操作，MIO是基础的外设IO，可以连接诸如SPI，I2C，UART，GPIO等，通过VIVADO软件设置，软件可以将信号通过MIO导出，同样也可以将信号通过EMIO连接到PL端的引脚上。

MIO共有两个BANK，BANK0有16个引脚，BANK1为38个引脚，共54个引脚，两个BANK的电压需要注意选择正确。


    
本实验通过实现PS端LED灯的闪烁演示MIO的操作。

原理介绍
--------

先来了解GPIO的BANK分布，在UG585文档GPIO一章中可以看到GPIO是有4个BANK，注意与MIO的BANK区分。
BANK0控制32个信号，BANK1控制22个信号，总共是MIO的54个引脚，也就是诸如SPI,I2C,USB,SD等PS端外设接口；
BANK2和BANK3共能控制64个PL端引脚，注意每一组都有三个信号，输入EMIOGPIOI，输出EMIOGPIOO，输出使能EMIOGPIOTN，类似于三态门，共192个信号。可以连接到PL端引脚，通过PS控制信号。


    
Vivado工程建立
--------------

本实验基于 “ps_hello”工程。如果想要控制PS端的MIO是需要将 GPIO
MIO打开的，前面已经配置.. image:: images/08_media/image3.png
          
1. 为了方便，将Vitis目录删除


          
2. 由于不需要生成FPGA烧写文件，直接点击FileExportExport
   Hardware，不用勾选include
   bitstream选项，生成Hardware信息，此时会生成新的Vitis目录。


          

          
软件工程师工作内容
------------------

以下为软件工程师负责内容。

Vitis程序开发
-------------

MIO点亮PS端LED灯
~~~~~~~~~~~~~~~~

根据原理图得知，AX7020和AX7010的LED灯连接到了PS端的MIO0和MIO13，可以根据相应的开发板MIO的位置控制LED灯。


    
AX7020/AX7010原理图

1. 点击FileLaunch Vitis进入Vitis


          
2. 新建platform工程过程不再赘述，参考“PS定时器中断实验” 一章


    
3. 下图为GPIO的控制框图，实验中会用到输出部分的寄存器，数据寄存器DATA，数据掩码寄存器MASK_DATA_LSW，MASK_DATA_MSW，方向控制寄存器DIRM，输出使能控制器OEN。


    
4. 再来看GPIO的寄存器，可以打开UG585文档的最下面Register
Details，找到General Purpose I/O部分。


    
5. 实验中可能会用到的寄存器：

数据掩码寄存器，例如MIO 9在GPIO的BANK0，可以屏蔽其他BANK0中的其他31位。


    
方向寄存器，控制数据的方向


    
输出使能寄存器


    
数据寄存器，有效的数据


    
具体的寄存器含义就不一一讲解了，大家自行研究。

6. 一开始编写代码可能会无从下手，我们可以导入Xilinx提供的example工程，点开system.mss，找到ps7_gpio_0，点击Import Examples


    
在弹出窗口选择“xgpiops_polled_example”，点击OK


    
会出现一个新的APP工程


    
7. 这个example工程是测试PS端MIO的输入输出的，由于开发板PS端的LED是MIO0和MIO13，需要在文件中修改Output_pin为0，测试MIO0的LED灯。


    
由于只测试LED灯，也就是输出，我们把输入功能注释掉。保存文件。


    
8. 编译工程


          
9. Run AsLaunch on Hardware(Single Application Debug)，下载结束后，即可看到PS_LED1快速闪烁16次


          
大家也可以改成MIO13观察PS_LED2的变化。

10. 虽然用官方的例子比较方便，但是它的代码看起来比较臃肿，我们可以通过学习它的方法，自己简化写一遍。在ps_led_test的helloworld.c中修改。其实程序步骤很简单，初始化GPIO设置方向输出使能控制GPIO输出值。


    
11. 选择platform


    
12. 选择Domain，Domain的含义类似于BSP


    
13. 模板选择Hellow World即可


    
14. 可以看到多了一个APP工程，仍然是基于名为standalone on ps7_cortexa9_0的BSP，也就是一个Domain，与前面的example工程共用一个BSP


          
15. 可以将例程的代码复制到helloworld.c中，保存并Build Project


          
下载方法与前面一样，就可以看到PS端的LED1和LED2灯开始闪烁。

MIO按键中断
~~~~~~~~~~~

前面介绍了MIO作为输出控制LED灯，这里讲一下利用MIO作为按键输入控制LED灯。

1. 通过UG585文档看下GPIO的结构图，中断的寄存器：

INT_MASK：中断掩码

INT_DIS: 中断关闭

INT_EN: 中断使能

INT_TYPE: 中断类型，设置电平敏感还是边沿敏感

INT_POLARITY: 中断极性，设置低电平或下降沿还是高电平或上升沿

INT_ANY: 边沿触发方式，需要INT_TYPE设置为边沿敏感才能使用

设置中断产生方式时需要INT_TYPE、INT_POLARITY、INT_ANY配合使用。具体寄存器含义请参考UG585
Register Details部分。


    
在原理图中可以看出PS端的按键接在了MIO50和MIO51，本实验采用MIO50

\ 

AX7020/AX7010原理图

2. 本实验设计为接下按键LED灯亮，再按下LED灭。

主程序设计流程如下：

GPIO初始化设置按键和LED方向设置产生中断方式设置中断打开中断控制器打开中断异常打开GPIO中断判断KEY_FLAG值，是1，写LED

中断处理流程：

查询中断状态寄存器判断状态清除中断设置KEY_FLAG值

3. 新建Vitis工程


    
4. 定义PS按键编号为50，PS LED为0


    
5. 在main函数中，设置LED和按键，将按键中断类型设置为上升沿产生中断。在本实验中，即按键信号的上升沿产生中断。


    
6. 中断控制器设置函数IntrInitFuntions是参考PS定时器中断实验所做，而下面的语句是设置中断优先级和触发方式。即操作ICDIPR和ICDICFR寄存器。


    
7. 在中断服务程序GpioHandler中，判断中断状态寄存器，清除中断，并将按键标志置1。


    
8. 在main函数中，判断按键标志key_flag，向LED写入数据。


    
9.  下载程序界面

10. 观察实验现象，按下PS端按键，就可以控制PS端LED的亮灭。

..

   AX7020/AX7010开发板丝印为PS KEY1；

   PS端LED灯位置： AX7020/AX7010开发板丝印为PS LED1;

知识点分享
----------

1. 在bsp的include文件夹下包含了xilinx的各种头文件，如本章用到的GPIO，用到了xgpiops.h，在此文件中可以看到各种宏定义，在调用GPIO函数时可以使用这些宏定义，提高可读性。


    
同时也包含外设自带的函数声明


    
2. 在xparameters.h头文件中定义了各个外设的基地址，器件ID，中断等


    
比如程序中的DEVICE_ID宏定义就是在这个文件里找到的。


    
3. 在libsrc文件夹中，包含外设函数的定义，使用说明


    
4. 在src文件夹下的lscript.ld中，定义了可用memory空间，栈和堆空间大小等，可根据需要修改。


    
5. 把鼠标光标放到宏定义或函数上，按下F3即可看到在哪里定义的，也可以按Ctrl+鼠标左键进入。比如下面的DEVICE_ID即可进入xparameter.h中


    

    
本章小结
--------

本章介绍了MIO的输入输出控制，以及GPIO的使用，相信大家也有了一定的认识。在学习过程中，一定要多看文档，结合模块结构以及寄存器含义加深理解。参考文档UG585。




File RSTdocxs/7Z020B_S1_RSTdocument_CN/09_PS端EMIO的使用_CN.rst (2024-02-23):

PS端EMIO的使用
================

**实验Vivado工程为“ps_emio”。**

前面介绍了PS端点亮LED灯的实验，但是如果想用PS点亮PL的LED灯，该如何做呢？一是可以通过EMIO控制PL端LED灯，二是通过AXI
GPIO的IP实现控制。本章介绍如何使用EMIO控制PL端LED灯的亮灭。同时也介绍了，利用EMIO连接PL端按键控制PL端LED灯。

原理介绍
--------

前面介绍了PS端MIO的结构如下，从图中可知BANK0和BANK1的MIO有54个。BANK2和BANK3的EMIO有64个，本章就是采用EMIO控制PL端LED。


    
FPGA工程师工作内容
------------------

以下为FPGA工程师负责内容。

Vivado工程建立
--------------

1. 以ps_hello工程为基础，另存为一个名为ps_emio的工程，打开ZYNQ配置，把GPIO
   EMIO勾选上。


    
2. 在MIO配置中选择EMIO的位宽为8位，因为PL端的LED有四个，使用PL端的一个按键。配置结束，点击OK。


    
3. 点击多出的GPIO_0端口右键选择Make External，将端口信号导出


    
4. 修改引脚名称为emio


    
修改结果，并保存设计


    
5. 点击xx.bd右键选择Generate Output Products，重新生成输出文件


    
6. 结束后，顶层文件会更新出新的管脚，下面需要对其进行引脚绑定


    
XDC文件约束PL管脚
-----------------

7. 新建XDC文件，绑定PL端引脚


    
设置文件名称为emio


    
8. emio.xdc添加一下内容，端口名称一定要和顶层文件端口一致

::

 set_property IOSTANDARD LVCMOS33 [get_ports {emio_tri_io[*]}]
 #pl led
 set_property PACKAGE_PIN J14 [get_ports {emio_tri_io[0]}]
 set_property PACKAGE_PIN K14 [get_ports {emio_tri_io[1]}]
 set_property PACKAGE_PIN J18 [get_ports {emio_tri_io[2]}]
 set_property PACKAGE_PIN H18 [get_ports {emio_tri_io[3]}]
 #pl key
 set_property PACKAGE_PIN M15 [get_ports {emio_tri_io[4]}]

1. 生成bit文件


    
10. 导出硬件


    
11. 因为要用到PL，所以选择“Include bitstream”，点击“OK”


    
软件工程师工作内容
------------------

以下为软件工程师负责内容。

Vitis程序编写
-------------

EMIO点亮PL端LED灯
~~~~~~~~~~~~~~~~~

1. 进入Vitis软件，新建名为emio_led_test的工程


    
2. 代码部分与PS端MIO操作点亮LED类似，由于MIO的编号是0~53，因此EMIO的编号是从54开始的，只要做以下修改即可


    
3. 下载配置


    
由于下载需要bitstream文件，勾选上Program
FPGA，点击Run，即可看到PL端LED闪烁。


    
EMIO实现PL端按键中断
~~~~~~~~~~~~~~~~~~~~

通过PL端的按键控制PL端LED灯的亮灭

1) 新建名为emio_key的工程，模板为hello world，拷贝例程的程序，保存并编译


    
1. 由PS端MIO的使用的MIO按键中断程序移植过来，并修改按键的编号为58，LED灯编号为54，保存重新生成elf。


    
2. Run Configurations选择Program FPGA，点击Run


    
1. 观察实验现象，按下PL端按键，就可以控制PL端LED的亮灭。

..

   AX7Z020/AX7Z010开发板丝印为KEY1；

   PL端LED灯位置： AX7Z020/AX7Z010开发板丝印为 LED1;

固化程序
--------

前面介绍过没有FPGA加载文件情况下如何生成固化程序（详情参考“体验ARM，裸机输出”Hello
World”一章）。本章内容生成了FPGA的加载文件，在这里演示一下如何生成固化程序。

与前面一样，也是点击system，右键Build Project即可


    

    
软件会自动添加三个文件，第一个引导程序fsbl.elf，第二个为FPGA的bitstream，第三个为应用程序xx.elf，下载方法与前面一样，不再赘述。

引脚绑定常见错误
----------------

1. 在block design设计中，比如下图，GPIO模块的引脚名设置为了leds和keys，很多人想当然的在XDC里按照这样的名称绑定引脚。


          
如果打开顶层文件就会发现引脚名称是不一样的，一定要仔细检查，以顶层文件里的引脚名称为


          
否则就会出现以下引脚未绑定的


          
2. 如果是手写XDC文件，切记注意空格，这也是非常常见的错误


          
本章小节
--------

本章进一步学习了PS端的EMIO的使用，虽然将EMIO连接到了PL端的引脚上，但Vitis中的用法还是一样的，从这个例子我们也可以看出，一旦与PL端发生了联系，就需要生成bitstream，虽然几乎没有产生逻辑。

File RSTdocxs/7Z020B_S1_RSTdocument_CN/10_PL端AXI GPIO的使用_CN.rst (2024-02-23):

PL端AXI GPIO的使用
====================

**实验Vivado工程为“ps_axi_gpio”。**

可能有些人就会问，怎么又在讲GPIO，LED灯，觉得太繁琐，但是GPIO是ZYNQ的基本操作，本教程力求把各种方法分享给大家，PS端的MIO，EMIO，PL端的axi
gpio，包括输入输出两个方向，以及PS与PL的基本操作，所以还是希望大家耐心学习。

前面讲过如何用的是PS端的EMIO点亮PL端LED灯，但是并没有与PL端产生交互。本章介绍另外一种控制方法，在ZYNQ当中可以使用AXI
GPIO，通过AXI总线控制PL端的LED灯。同时也介绍了PL端按键的使用。

使用zynq最大的疑问就是如何把PS和PL结合起来使用，在其他的SOC芯片中一般都会有GPIO，本实验使用一个AXI
GPIO的IP核，让PS端通过AXI总线控制PL端的LED灯，实验虽然简单，不过可以让我们了解PL和PS是如何结合的。

原理介绍
--------

一个AXI
GPIO模块有两个GPIO，分别是GPIO和GPIO2，也就是channel1和channel2，为双向IO。


    
AXI GPIO结构

FPGA工程师工作内容
------------------

以下为FPGA工程师负责内容。

Vivado工程建立
--------------

1) 打开“ps_hello”另存为一个名为“ps_axi_gpio”Vivado工程，表示PS通过AXI总线控制gpio


    

    
2) 双击xx.bd打开block design


    
添加AXI GPIO
~~~~~~~~~~~~

3) 添加一个AXI GPIO的IP 核


    
4) 双击刚才添加的“axi_gpio_0”配置参数


    
5) 选择“All Outputs”，因为这里控制LED，只要输出就可以了，“GPIO
   Width”填4，控制4颗LED，点击OK。如果想使用channel2，需要把”Enable Dual
   Channel”打开，也就使能了GPIO2。


    
6) 点击“Run Connection Automation”，可以完成部分自动连线


    
7) 选择要自动连接的端口，这里全选，点击OK


    
8) 点击“Optimize
   Routing”，可以优化布局，同时可以看到多了两个模块，一个是Processor
   System Reset模块，为同步复位模块，提供同一时钟域的复位信号。AXI
   Interconnect模块为AXI总线互联模块，用于AXI模块的交叉互联。


    
在这个应用中，我们可以看到用到了ZYNQ的GP口，M_AXI_GP0，M代表的是master，此接口用于访问PL端数据，大部分应用中是为了配置PL端模块的寄存器。


    
复位信号由ZYNQ的复位输出提供，最好是每个时钟域都加一个复位模块，可以根据模块下面的名称搜索添加。


    
9) 修改GPIO端口的名称


    
10) 名称修改为leds


    
11) 再添加一个AXI GPIO，连接PL端按键


    
12) 配置GPIO参数，都为输入，宽度为1，使能中断


    
13) 使用自动连接


    
14) 再把端口名称改为keys


    
15) 由于是PL端过来的中断，在这里需要配置ZYNQ处理器的中断，勾选IRQ_F2P


    
16) 连接ip2intc_irpt到IRQ_F2P


    
17) 保存设计，点击xx.bd，右键Generate Output Products


    
18) 在生成的Verilog文件中，可以看到有个“leds_tri_o”和”keys_tri_i”的端口，要为他们分配管脚，在绑定引脚时，以这个文件里的引脚名称为准。


    
XDC文件约束PL管脚
-----------------

1. 创建一个新的xdc约束文件


    
2. 文件名称为led


    
3. led.xdc添加一下内容，端口名称一定要和顶层文件端口一致

::

 set_property IOSTANDARD LVCMOS33 [get_ports {leds_tri_o[3]}]
 set_property IOSTANDARD LVCMOS33 [get_ports {leds_tri_o[2]}]
 set_property IOSTANDARD LVCMOS33 [get_ports {leds_tri_o[1]}]
 set_property IOSTANDARD LVCMOS33 [get_ports {leds_tri_o[0]}]
 set_property PACKAGE_PIN J14 [get_ports {leds_tri_o[0]}]
 set_property PACKAGE_PIN K14 [get_ports {leds_tri_o[1]}]
 set_property PACKAGE_PIN J18 [get_ports {leds_tri_o[2]}]
 set_property PACKAGE_PIN H18 [get_ports {leds_tri_o[3]}]
 
 set_property IOSTANDARD LVCMOS33 [get_ports {keys_tri_i[0]}]
 set_property PACKAGE_PIN M15 [get_ports {keys_tri_i[0]}]

1. 生成bit文件


    
5. 导出硬件FileExportExport Hardware


    
6. 因为要用到PL，所以选择“Include bitstream”，点击“OK”


    
软件工程师工作内容
------------------

以下为软件工程师负责内容。

Vitis程序编写
-------------

AXI GPIO点亮PL端LED灯
~~~~~~~~~~~~~~~~~~~~~

1) 创建一个platform，创建过程参考“PS定时器中断实验”一章


    
2) 面对一个不熟悉AXI
   GPIO，我们如何控制呢？我们可以尝试一下Vitis自带的例程

3) 双击“system.mss”,找到“axi_gpio_0”,这里可以点击“Documentation”来看相关文档，这里就不演示，点击“Import
   Examples”


    
4) 在弹出的对话框中有多个例程，从名称中可以猜个大概，这里选第一个“xgpio_example”


    
5) 可以看到例程比较简单，短短几行代码，完成了AXI GPIO的操作

\ 里面用到很多GPIO相关的API函数，通过文档可以了解详细，也可以选中该函数，按“F3”查看具体定义。如果有了这些信息你还不能理解如何使用AXI
GPIO，说明你需要补充C语言基础。

其实这些函数都是在操作GPIO的寄存器，AXI
GPIO的寄存器也不多，主要是两个channel的数据寄存器GPIO_DATA和GPIO2_DATA，两个channel的方向控制GPIO_TRI和GPIO2_TRI，以及全局中断使能寄存器GIER，IP的中断使能IP
IER和中断状态寄存器ISR，具体的功能可以看AXI GPIO的文档pg144。


    
比如进入到设置GPIO方向的函数中，就可以看到是在向GPIO的GPIO_TRI寄存器写数据，从而控制方向。


    
其他的函数也可以按此法自行研究。

下载调试
~~~~~~~~

1) 虽然Vitis可以提供一些例程，但有一部分例程是需要自己修改的，这个简单的LED例程就不修改了，尝试运行一下，发现不能达到预期效果，甚至提示一些错误。


    
2) 前面的教程已经提到，“Run As”最好复位系统，有PL的设计要“Program
   FPGA”，如果你的PL多次修改，别忘了重新导出硬件。按照下图配置后再次运行，可以看到开发板PL
   LED1快速闪烁。


    
3) 修改代码让4个LED灯都闪烁


    
寄存器方式实现
~~~~~~~~~~~~~~

如果觉得Xilinx提供的API函数比较繁琐，效率低，也可以采取操作寄存器的方式实现LED的控制。

比如下面我们在axi_led的工程，修改helloworld.c如下。


    

    
其中定义的基地址GPIO_BASEADDR可以在XX.xsa里找到


    
由于我们只启用了channel1，因此定义了下面的寄存器地址


    
这样直接操作寄存器的方式效率会比调用Xilinx
API函数高，而且更直观，对于理解程序如何运行有很大帮助。但是对于大工程来讲，这种方式使用起来就比较复杂，主要依据个人需求选择。

AXI GPIO之PL端按键中断
~~~~~~~~~~~~~~~~~~~~~~

前面的定时器中断实验的中断属于PS内部的中断，本实验中断来自PL，PS最大可以接收16个来自PL的中断信号，都是上升沿或高电平触发。


    
1) 和前面的教程一样，在不熟悉Vitis程序编写的情况下，我们尽量使用Vitis自带例程来修改，选择“xgpio_intr_tapp_example”


    
2) 导入例程以后有未定义的错误，我们需要修改部分代码，可以回到vivado工程看到按键的axi
   gpio模块叫做axi_gpio_1，以及它的偏移地址


    
因此就可以在xparameters.h中找到它的device id


    

    

    
3) 然后可以修改GPIO和中断号的宏定义如下


    
4) 修改测试延时时间，让我们有足够的时间去按按键


    
.. _下载调试-1:

下载调试
~~~~~~~~

1. 打开串口终端，运行程序


    
5) 如果一直不按按键，串口显示“No button pressed.”，如果按下“PL
   KEY1”按键显示“Successfully ran Gpio Interrupt Tapp Example”。


    
实验总结
--------

通过实验我们了解到PS可以通过AXI总线控制PL，但几乎没有体现出ZYNQ的优势，因为对于控制LED灯，无论是ARM还是FPGA，都可以轻松完成，但是如果把LED换成串口呢，控制100路串口通信，8路以太网等应用，我想还没有哪个SOC能完成这种功能，只有ZYNQ可以，这就是ZYNQ和普通SOC的不同之处。

PL端可以给PS发送中断信号，这提高了PL和PS数据交互的效率，在需要大数量、低延时的应用中需要用到中断处理。

到本章结束已经把ZYNQ的PS端MIO、EMIO，PL端GPIO如何使用讲完了，包括输入和输出以及中断处理，这些都是最基础的操作，大家还是要多多思考，理解清楚。

知识点分享
----------

1) 在设计好后，可以看到Address
   Editor中，已经为AXI外设分配好了地址空间，其中偏移地址和空间大小是可以修改的。


    
但是修改偏移地址是有限制的，详情参考UG585文档System Address一章，
AXI外设连接到了M_AXI_GP0口， 在4000_0000到7FFF_FFFF地址空间内修改。


    
2) 在使用一个模块时，需要配套的文档辅助开发，但是这些文档该如何去找呢，例如XILINX的IP，打开模块的配置，在左上角点击Documentation，再点击Product
   Guide，如果在安装Vivado的时候安装了DocNav，就会跳转过去打开文档。


    

    

    
此功能需要电脑联网，DocNav会从网站加载文档。可以点击下载按钮下载到本地。

还有一种方法是在Xilinx官网根据模块的名称搜索资料下载（页面可能会有所变化）


    


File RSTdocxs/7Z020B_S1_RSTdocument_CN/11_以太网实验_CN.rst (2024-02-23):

以太网实验（LWIP）
==============================

**实验Vivado工程为“net_test”。**

开发板有1路千兆以太网，通过RGMII接口连接，本实验演示如何使用Vitis自带的LWIP模板进行千兆以太网TCP通信。

LWIP虽然是轻量级协议栈，但如果从来没有使用过，使用起来会有一定的困难，建议先熟悉LWIP的相关知识。

Vivado工程建立
--------------

基于“ps_hello”另存一个“net_test”vivado工作。PS端Ethernet 0已经配置过。

Vitis程序开发
-------------

LWIP库修改
~~~~~~~~~~

由于自带的LWIP库只能识别部分phy芯片，如果开发板所用的phy芯片不在默认支持范围内，要修改库文件。也可以直接使用修改过的库替换原有的库。

1) 找到库文件目录“D:\\Xilinx2023.1\\Vitis\\2023.1\\data\\embeddedsw\\ThirdParty\\sw_services”



2) 找到要修改的文件目录“lwip213_v1_0\\src\\contrib\\ports\\xilinx\\netif”中文件“xaxiemacif_physpeed.c”和“xemacpsif_physpeed.c”要修改。



3) 修改“xaxiemacif_physpeed.c”文件，添加相关宏定义



4) 添加phy速度获取函数

.. code:: c

 unsigned int get_phy_speed_ksz9031(XAxiEthernet *xaxiemacp, u32 phy_addr)
 {
 	u16 control;
 	u16 status;
 	u16 partner_capabilities;
 	xil_printf("Start PHY autonegotiation \r\n");
 
 	XAxiEthernet_PhyWrite(xaxiemacp,phy_addr, IEEE_PAGE_ADDRESS_REGISTER, 2);
 	XAxiEthernet_PhyRead(xaxiemacp, phy_addr, IEEE_CONTROL_REG_MAC, &control);
 	//control |= IEEE_RGMII_TXRX_CLOCK_DELAYED_MASK;
 	control &= ~(0x10);
 	XAxiEthernet_PhyWrite(xaxiemacp, phy_addr, IEEE_CONTROL_REG_MAC, control);
 
 	XAxiEthernet_PhyWrite(xaxiemacp, phy_addr, IEEE_PAGE_ADDRESS_REGISTER, 0);
 
 	XAxiEthernet_PhyRead(xaxiemacp, phy_addr, IEEE_AUTONEGO_ADVERTISE_REG, &control);
 	control |= IEEE_ASYMMETRIC_PAUSE_MASK;
 	control |= IEEE_PAUSE_MASK;
 	control |= ADVERTISE_100;
 	control |= ADVERTISE_10;
 	XAxiEthernet_PhyWrite(xaxiemacp, phy_addr, IEEE_AUTONEGO_ADVERTISE_REG, control);
 
 	XAxiEthernet_PhyRead(xaxiemacp, phy_addr, IEEE_1000_ADVERTISE_REG_OFFSET,
 																	&control);
 	control |= ADVERTISE_1000;
 	XAxiEthernet_PhyWrite(xaxiemacp, phy_addr, IEEE_1000_ADVERTISE_REG_OFFSET,
 																	control);
 
 	XAxiEthernet_PhyWrite(xaxiemacp, phy_addr, IEEE_PAGE_ADDRESS_REGISTER, 0);
 	XAxiEthernet_PhyRead(xaxiemacp, phy_addr, IEEE_COPPER_SPECIFIC_CONTROL_REG,
 																&control);
 	control |= (7 << 12);	/* max number of gigabit attempts */
 	control |= (1 << 11);	/* enable downshift */
 	XAxiEthernet_PhyWrite(xaxiemacp, phy_addr, IEEE_COPPER_SPECIFIC_CONTROL_REG,
 																control);
 	XAxiEthernet_PhyRead(xaxiemacp, phy_addr, IEEE_CONTROL_REG_OFFSET, &control);
 	control |= IEEE_CTRL_AUTONEGOTIATE_ENABLE;
 	control |= IEEE_STAT_AUTONEGOTIATE_RESTART;
 
 	XAxiEthernet_PhyWrite(xaxiemacp, phy_addr, IEEE_CONTROL_REG_OFFSET, control);
 
 	XAxiEthernet_PhyRead(xaxiemacp, phy_addr, IEEE_CONTROL_REG_OFFSET, &control);
 	control |= IEEE_CTRL_RESET_MASK;
 	XAxiEthernet_PhyWrite(xaxiemacp, phy_addr, IEEE_CONTROL_REG_OFFSET, control);
 
 	while (1) {
 		XAxiEthernet_PhyRead(xaxiemacp, phy_addr, IEEE_CONTROL_REG_OFFSET, &control);
 		if (control & IEEE_CTRL_RESET_MASK)
 			continue;
 		else
 			break;
 	}
 	xil_printf("Waiting for PHY to complete autonegotiation.\r\n");
 
 	XAxiEthernet_PhyRead(xaxiemacp, phy_addr, IEEE_STATUS_REG_OFFSET, &status);
 	while ( !(status & IEEE_STAT_AUTONEGOTIATE_COMPLETE) ) {
 		sleep(1);
 		XAxiEthernet_PhyRead(xaxiemacp, phy_addr, IEEE_STATUS_REG_OFFSET,
 																&status);
 		}
 
 	xil_printf("autonegotiation complete \r\n");
 
 	XAxiEthernet_PhyRead(xaxiemacp, phy_addr, 0x1f, &partner_capabilities);
 
 	if ( (partner_capabilities & 0x40) == 0x40)/* 1000Mbps */
 		return 1000;
 	else if ( (partner_capabilities & 0x20) == 0x20)/* 100Mbps */
 		return 100;
 	else if ( (partner_capabilities & 0x10) == 0x10)/* 10Mbps */
 		return 10;
 	else
 		return 0;
 }
 static u32_t get_phy_speed_JL2121(XAxiEthernet *xaxiemacp, u32_t phy_addr)
 {
 	u16_t temp;
 	u16_t control;
 	u16_t status;
 	u16_t status_speed;
 	u32_t timeout_counter = 0;
 	u32_t temp_speed;
 	u32_t phyregtemp;
 
 	xil_printf("phy is JL2121!\r\n");

 	xil_printf("Start PHY autonegotiation \r\n");
 
 	XAxiEthernet_PhyRead(xaxiemacp, phy_addr, IEEE_CONTROL_REG_OFFSET, &control);
 	control |= IEEE_CTRL_RESET_MASK;
 	XAxiEthernet_PhyWrite(xaxiemacp, phy_addr, IEEE_CONTROL_REG_OFFSET, control);
 
 	usleep(10000);
 
 	XAxiEthernet_PhyRead(xaxiemacp, phy_addr, IEEE_AUTONEGO_ADVERTISE_REG, &control);
 	control |= IEEE_ASYMMETRIC_PAUSE_MASK;
 	control |= IEEE_PAUSE_MASK;
 	control |= ADVERTISE_100;
 	control |= ADVERTISE_10;
 	XAxiEthernet_PhyWrite(xaxiemacp, phy_addr, IEEE_AUTONEGO_ADVERTISE_REG, control);
 
 	XAxiEthernet_PhyRead(xaxiemacp, phy_addr, IEEE_1000_ADVERTISE_REG_OFFSET,
 					&control);
 	control |= ADVERTISE_1000;
 	XAxiEthernet_PhyWrite(xaxiemacp, phy_addr, IEEE_1000_ADVERTISE_REG_OFFSET,
 					control);
 
 	XAxiEthernet_PhyRead(xaxiemacp, phy_addr, IEEE_CONTROL_REG_OFFSET, &control);
 	control |= IEEE_CTRL_AUTONEGOTIATE_ENABLE;
 	control |= IEEE_STAT_AUTONEGOTIATE_RESTART;
 	XAxiEthernet_PhyWrite(xaxiemacp, phy_addr, IEEE_CONTROL_REG_OFFSET, control);

 	while (1) {
 		XAxiEthernet_PhyRead(xaxiemacp, phy_addr, IEEE_CONTROL_REG_OFFSET, &control);
 		if (control & IEEE_CTRL_RESET_MASK)
 			continue;
 		else
 			break;
 	}
 
 	XAxiEthernet_PhyRead(xaxiemacp, phy_addr, IEEE_STATUS_REG_OFFSET, &status);
 
 	xil_printf("Waiting for PHY to complete autonegotiation.\r\n");
 
 	while ( !(status & IEEE_STAT_AUTONEGOTIATE_COMPLETE) ) {
 		sleep(1);
 
 		timeout_counter++;
 
 		if (timeout_counter == 30) {
 			xil_printf("Auto negotiation error \r\n");
 			return;
 		}
 		XAxiEthernet_PhyRead(xaxiemacp, phy_addr, IEEE_STATUS_REG_OFFSET, &status);
 	}
 	xil_printf("autonegotiation complete \r\n");

 	XAxiEthernet_PhyWrite(xaxiemacp, phy_addr,JLSEMI_PHY_SELECT_REG_OFFSET,JLSEMI_PHY_SPECIFIC_PAGE);
 	XAxiEthernet_PhyRead(xaxiemacp,  phy_addr, JLSEMI_PHY_SPECIFIC_STATUS_REG_OFFSET, &status_speed);
 
 	XAxiEthernet_PhyWrite(xaxiemacp, phy_addr,JLSEMI_PHY_SELECT_REG_OFFSET,JLSEMI_PHY_LCR_PAGE);
 	XAxiEthernet_PhyWrite(xaxiemacp, phy_addr,JLSEMI_PHY_LED_CONTROL_REG_OFFSET,0xAE01);
 
 	XAxiEthernet_PhyWrite(xaxiemacp, phy_addr,JLSEMI_PHY_SELECT_REG_OFFSET,JLSEMI_PHY_LED_BLINK_PAGE);
 	XAxiEthernet_PhyWrite(xaxiemacp, phy_addr,JLSEMI_PHY_LED_BLINK_REG_OFFSET,0x0704);
 	XAxiEthernet_PhyWrite(xaxiemacp, phy_addr,JLSEMI_PHY_SELECT_REG_OFFSET,0);
 
 	if ( (status_speed & 0x20) == 0x20)/* 1000Mbps */
 		return 1000;
 	else if ( (status_speed & 0x10) == 0x10)/* 100Mbps */
 		return 100;
 	else if ( (status_speed & 0x30) == 0x0)/* 10Mbps */
 		return 10;
 	else
 		return 0;
 	return XST_SUCCESS;
 }

5) 修改函数“get_IEEE_phy_speed”，添加对KSZ9031和JL2121的支持。

.. code:: c

 unsigned get_IEEE_phy_speed(XAxiEthernet *xaxiemacp)
 {
 	u16 phy_identifier;
 	u16 phy_model;
 	u8 phytype;
 
 #ifdef XPAR_AXIETHERNET_0_BASEADDR
 	u32 phy_addr = detect_phy(xaxiemacp);
 
 	/* Get the PHY Identifier and Model number */
 	XAxiEthernet_PhyRead(xaxiemacp, phy_addr, PHY_IDENTIFIER_1_REG, &phy_identifier);
 	XAxiEthernet_PhyRead(xaxiemacp, phy_addr, PHY_IDENTIFIER_2_REG, &phy_model);
 
 /* Depending upon what manufacturer PHY is connected, a different mask is
  * needed to determine the specific model number of the PHY. */
 	if (phy_identifier == MARVEL_PHY_IDENTIFIER) {
 		phy_model = phy_model & MARVEL_PHY_MODEL_NUM_MASK;
 
 		if (phy_model == MARVEL_PHY_88E1116R_MODEL) {
 			return get_phy_speed_88E1116R(xaxiemacp, phy_addr);
 		} else if (phy_model == MARVEL_PHY_88E1111_MODEL) {
 			return get_phy_speed_88E1111(xaxiemacp, phy_addr);
 		}
 	} else if (phy_identifier == TI_PHY_IDENTIFIER) {
 		phy_model = phy_model & TI_PHY_DP83867_MODEL;
 		phytype = XAxiEthernet_GetPhysicalInterface(xaxiemacp);
 
 		if (phy_model == TI_PHY_DP83867_MODEL && phytype == XAE_PHY_TYPE_SGMII) {
 			return get_phy_speed_TI_DP83867_SGMII(xaxiemacp, phy_addr);
 		}
 
 		if (phy_model == TI_PHY_DP83867_MODEL) {
 			return get_phy_speed_TI_DP83867(xaxiemacp, phy_addr);
 		}
 	}
 	else if(phy_identifier == MICREL_PHY_IDENTIFIER)
 	{
 		xil_printf("Phy %d is KSZ9031\n\r", phy_addr);
 		return get_phy_speed_ksz9031(xaxiemacp, phy_addr);
 	}
 	else if(phy_identifier == JLSEMI_IDENTIFIER)
 	{
 		return get_phy_speed_JL2121(xaxiemacp, phy_addr);
 	}
 	else {
 	    LWIP_DEBUGF(NETIF_DEBUG, ("XAxiEthernet get_IEEE_phy_speed: Detected PHY with unknown identifier/model.\r\n"));
 	}
 #endif
 #ifdef PCM_PMA_CORE_PRESENT
 	return get_phy_negotiated_speed(xaxiemacp, phy_addr);
 #endif
 }

6) 修改“xemacpsif_physpeed.c”文件添加宏定义



7) 添加phy速度获取函数

.. code:: c

 static u32_t get_phy_speed_ksz9031(XEmacPs *xemacpsp, u32_t phy_addr)
 {
 	u16_t temp;
 	u16_t control;
 	u16_t status;
 	u16_t status_speed;
 	u32_t timeout_counter = 0;
 	u32_t temp_speed;
 	u32_t phyregtemp;
 
 	xil_printf("Start PHY autonegotiation \r\n");
 
 	XEmacPs_PhyWrite(xemacpsp,phy_addr, IEEE_PAGE_ADDRESS_REGISTER, 2);
 	XEmacPs_PhyRead(xemacpsp, phy_addr, IEEE_CONTROL_REG_MAC, &control);
 	control |= IEEE_RGMII_TXRX_CLOCK_DELAYED_MASK;
 	XEmacPs_PhyWrite(xemacpsp, phy_addr, IEEE_CONTROL_REG_MAC, control);
 
 	XEmacPs_PhyWrite(xemacpsp, phy_addr, IEEE_PAGE_ADDRESS_REGISTER, 0);
 
 	XEmacPs_PhyRead(xemacpsp, phy_addr, IEEE_AUTONEGO_ADVERTISE_REG, &control);
 	control |= IEEE_ASYMMETRIC_PAUSE_MASK;
 	control |= IEEE_PAUSE_MASK;
 	control |= ADVERTISE_100;
 	control |= ADVERTISE_10;
 	XEmacPs_PhyWrite(xemacpsp, phy_addr, IEEE_AUTONEGO_ADVERTISE_REG, control);
 
 	XEmacPs_PhyRead(xemacpsp, phy_addr, IEEE_1000_ADVERTISE_REG_OFFSET,
 					&control);
 	control |= ADVERTISE_1000;
 	XEmacPs_PhyWrite(xemacpsp, phy_addr, IEEE_1000_ADVERTISE_REG_OFFSET,
 					control);
 
 	XEmacPs_PhyWrite(xemacpsp, phy_addr, IEEE_PAGE_ADDRESS_REGISTER, 0);
 	XEmacPs_PhyRead(xemacpsp, phy_addr, IEEE_COPPER_SPECIFIC_CONTROL_REG,
 																&control);
 	control |= (7 << 12);	/* max number of gigabit attempts */
 	control |= (1 << 11);	/* enable downshift */
 	XEmacPs_PhyWrite(xemacpsp, phy_addr, IEEE_COPPER_SPECIFIC_CONTROL_REG,
 																control);
 	XEmacPs_PhyRead(xemacpsp, phy_addr, IEEE_CONTROL_REG_OFFSET, &control);
 	control |= IEEE_CTRL_AUTONEGOTIATE_ENABLE;
 	control |= IEEE_STAT_AUTONEGOTIATE_RESTART;
 	XEmacPs_PhyWrite(xemacpsp, phy_addr, IEEE_CONTROL_REG_OFFSET, control);
 
 	XEmacPs_PhyRead(xemacpsp, phy_addr, IEEE_CONTROL_REG_OFFSET, &control);
 	control |= IEEE_CTRL_RESET_MASK;
 	XEmacPs_PhyWrite(xemacpsp, phy_addr, IEEE_CONTROL_REG_OFFSET, control);
 
 	while (1) {
 		XEmacPs_PhyRead(xemacpsp, phy_addr, IEEE_CONTROL_REG_OFFSET, &control);
 		if (control & IEEE_CTRL_RESET_MASK)
 			continue;
 		else
 			break;
 	}
 
 	XEmacPs_PhyRead(xemacpsp, phy_addr, IEEE_STATUS_REG_OFFSET, &status);
 
 	xil_printf("Waiting for PHY to complete autonegotiation.\r\n");
 
 	while ( !(status & IEEE_STAT_AUTONEGOTIATE_COMPLETE) ) {
 		sleep(1);
 		XEmacPs_PhyRead(xemacpsp, phy_addr,
 						IEEE_COPPER_SPECIFIC_STATUS_REG_2,  &temp);
 		timeout_counter++;
 
 		if (timeout_counter == 30) {
 			xil_printf("Auto negotiation error \r\n");
 			return;
 		}
 		XEmacPs_PhyRead(xemacpsp, phy_addr, IEEE_STATUS_REG_OFFSET, &status);
 	}
 	xil_printf("autonegotiation complete \r\n");
 
 	XEmacPs_PhyRead(xemacpsp, phy_addr,0x1f,
 					&status_speed);
 
 	if ( (status_speed & 0x40) == 0x40)/* 1000Mbps */
 		return 1000;
 	else if ( (status_speed & 0x20) == 0x20)/* 100Mbps */
 		return 100;
 	else if ( (status_speed & 0x10) == 0x10)/* 10Mbps */
 		return 10;
 	else
 		return 0;
 	return XST_SUCCESS;
 }
 static u32_t get_phy_speed_JL2121(XEmacPs *xemacpsp, u32_t phy_addr)
 {
 	u16_t temp;
 	u16_t control;
 	u16_t status;
 	u16_t status_speed;
 	u32_t timeout_counter = 0;
 	u32_t temp_speed;
 	u32_t phyregtemp;
 
 	xil_printf("phy is JL2121!\r\n");

 	xil_printf("Start PHY autonegotiation \r\n");
 
 	XEmacPs_PhyRead(xemacpsp, phy_addr, IEEE_CONTROL_REG_OFFSET, &control);
 	control |= IEEE_CTRL_RESET_MASK;
 	XEmacPs_PhyWrite(xemacpsp, phy_addr, IEEE_CONTROL_REG_OFFSET, control);
 
 	usleep(10000);
 
 	XEmacPs_PhyRead(xemacpsp, phy_addr, IEEE_AUTONEGO_ADVERTISE_REG, &control);
 	control |= IEEE_ASYMMETRIC_PAUSE_MASK;
 	control |= IEEE_PAUSE_MASK;
 	control |= ADVERTISE_100;
 	control |= ADVERTISE_10;
 	XEmacPs_PhyWrite(xemacpsp, phy_addr, IEEE_AUTONEGO_ADVERTISE_REG, control);
 
 	XEmacPs_PhyRead(xemacpsp, phy_addr, IEEE_1000_ADVERTISE_REG_OFFSET,
 					&control);
 	control |= ADVERTISE_1000;
 	XEmacPs_PhyWrite(xemacpsp, phy_addr, IEEE_1000_ADVERTISE_REG_OFFSET,
 					control);
 
 	XEmacPs_PhyRead(xemacpsp, phy_addr, IEEE_CONTROL_REG_OFFSET, &control);
 	control |= IEEE_CTRL_AUTONEGOTIATE_ENABLE;
 	control |= IEEE_STAT_AUTONEGOTIATE_RESTART;
 	XEmacPs_PhyWrite(xemacpsp, phy_addr, IEEE_CONTROL_REG_OFFSET, control);
 
 	while (1) {
 		XEmacPs_PhyRead(xemacpsp, phy_addr, IEEE_CONTROL_REG_OFFSET, &control);
 		if (control & IEEE_CTRL_RESET_MASK)
 			continue;
 		else
 			break;
 	}
 
 	XEmacPs_PhyRead(xemacpsp, phy_addr, IEEE_STATUS_REG_OFFSET, &status);
 
 	xil_printf("Waiting for PHY to complete autonegotiation.\r\n");
 
 	while ( !(status & IEEE_STAT_AUTONEGOTIATE_COMPLETE) ) {
 		sleep(1);
 
 		timeout_counter++;
 
 		if (timeout_counter == 30) {
 			xil_printf("Auto negotiation error \r\n");
 			return;
 		}
 		XEmacPs_PhyRead(xemacpsp, phy_addr, IEEE_STATUS_REG_OFFSET, &status);
 	}
 	xil_printf("autonegotiation complete \r\n");

 	XEmacPs_PhyWrite(xemacpsp, phy_addr,JLSEMI_PHY_SELECT_REG_OFFSET,JLSEMI_PHY_SPECIFIC_PAGE);
 	XEmacPs_PhyRead(xemacpsp,  phy_addr, JLSEMI_PHY_SPECIFIC_STATUS_REG_OFFSET, &status_speed);
 
 	XEmacPs_PhyWrite(xemacpsp, phy_addr,JLSEMI_PHY_SELECT_REG_OFFSET,JLSEMI_PHY_LCR_PAGE);
 	XEmacPs_PhyWrite(xemacpsp, phy_addr,JLSEMI_PHY_LED_CONTROL_REG_OFFSET,0xAE01);
 
 	XEmacPs_PhyWrite(xemacpsp, phy_addr,JLSEMI_PHY_SELECT_REG_OFFSET,JLSEMI_PHY_LED_BLINK_PAGE);
 	XEmacPs_PhyWrite(xemacpsp, phy_addr,JLSEMI_PHY_LED_BLINK_REG_OFFSET,0x0704);
 	XEmacPs_PhyWrite(xemacpsp, phy_addr,JLSEMI_PHY_SELECT_REG_OFFSET,0);
 
 	if ( (status_speed & 0x20) == 0x20)/* 1000Mbps */
 		return 1000;
 	else if ( (status_speed & 0x10) == 0x10)/* 100Mbps */
 		return 100;
 	else if ( (status_speed & 0x30) == 0x0)/* 10Mbps */
 		return 10;
 	else
 		return 0;
 	return XST_SUCCESS;
 }

1) 修改函数“get_IEEE_phy_speed”，添加对KSZ9031和JL2121的支持

.. code:: c

 static u32_t get_IEEE_phy_speed(XEmacPs *xemacpsp, u32_t phy_addr)
 {
 	u16_t phy_identity;
 	u32_t RetStatus;
 
 	XEmacPs_PhyRead(xemacpsp, phy_addr, PHY_IDENTIFIER_1_REG,
 					&phy_identity);
 	
 	if(phy_identity == MICREL_PHY_IDENTIFIER)
 	{
 		RetStatus = get_phy_speed_ksz9031(xemacpsp, phy_addr);
 	}else if (phy_identity == JLSEMI_IDENTIFIER) {
 		RetStatus = get_phy_speed_JL2121(xemacpsp, phy_addr);
 	}
 	else if (phy_identity == PHY_TI_IDENTIFIER) {
 		RetStatus = get_TI_phy_speed(xemacpsp, phy_addr);
 	} else {
 		RetStatus = get_Marvell_phy_speed(xemacpsp, phy_addr);
 	}
 
 	return RetStatus;
 }

创建基于LWIP模板的APP
~~~~~~~~~~~~~~~~~~~~~



下载调试
--------

测试环境要求有一台支持dhcp的路由器，开发板连接路由器可以自动获取IP地址，实验主机和开发板在一个网络，可以相互通信。

以太网测试
~~~~~~~~~~

1) 连接串口打开串口调试终端，连接好PS端以太网网线到路由器，运行Vitis



2) 可以看到串口打印出一些信息，可以看到自动获取到地址为“192.168.1.63”，连接速度1000Mbps，tcp端口为7



3) 使用telnet连接



4) 当输入一个字符时，开发板返回相同字符



实验总结
--------

通过实验我们更加深刻了解到Vitis程序的开发，本实验只是简单的讲解如何创建一个LWIP应用，LWIP可以完成UDP、TCP等协议，在后续的教程中我们会提供基于以太网的具体应用，例如ADC采集数据通过以太网发送，摄像头数据通过以太网发送上位机显示。

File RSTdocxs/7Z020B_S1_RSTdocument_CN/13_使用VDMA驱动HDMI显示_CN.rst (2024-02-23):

使用VDMA驱动HDMI显示
======================

**实验Vivado工程为“vdma_hdmi_out”。**

我们板子上是有HDMI接口的，在前面也介绍过了使用PL端实现HDMI的显示，但是如何使用PS控制HDMI显示内容呢？由于PS没有集成显示控制系统，还是需要借助PL来实现，怎么将数据传输到PL端的显示部分呢？这里就需要用到PS与PL之间的数据交互接口了。通常情况下，都会选择高性能的HP口作为PS与PL之间的高速数据传输。HP口最大数据宽度是64位，如果频率跑到150MHz，带宽就能达到9.6Gbps，可以满足图像数据的传输。

实现数据传输方案有很多，但是都离不开DMA系统，DMA系统可以完成显示数据从ddr3读出到显示器的显示，降低CPU的开销，VDMA是xilinx开发的特殊DMA，专门用于视频输入输出，是学习xilinx
FPGA视频处理的重要内容。

前面的HDMI显示数据是PL内部产生的，这个实验中显示数据是PS生成的，然后PL通过VDMA送给HDMI接口。



FPGA工程师工作内容
------------------

下面介绍FPGA工程师负责内容。

Vivado工程建立
--------------

由于VDMA显示是一个非常重要的内容，本实验会详细介绍Vivado的搭建过程。

1) 用”ps_hello”新建一个名为“vdma_hdmi_out”工程。打开ZYNQ配置，由于要从DDR中读出数据，我们采用高性能的HP口进行PS与PL之间的数据交互。打开
   HP0接口。


    
配置I2C的EMIO
~~~~~~~~~~~~~

2) 使能I2C0，并且选择EMIO，这样可以把I2C连接到PL端，用于连接HDMI DDC


    
3) 配置时钟，FCLK_CLK0配置为100Mhz，FCLK_CLK1配置为142Mhz，这个时钟用于VDMA读取数据。这是由于1080p
   60帧的频率为148.5MHz，但包含同步和消隐时间，而VDMA传输的都是有效数据，因此设置为142MHz就可以满足要求。


    
配置中断
~~~~~~~~

4) 配置中断，使能IRQ_F2P，接收PL端的中断


    
配置VDMA
~~~~~~~~

5) 添加VDMA IP


    
6) 按照下图配置VDMA基本参数，这里主要牵涉到两个接口，Memory
   Map接口，采用AXI4接口，与ZYNQ
   HP口进行数据交互，读取PS端DDR中的图像数据。ZYNQ
   HP接口为64位接口，在这里我们也设置成64位接口，当然也可以设置大一些，经过交叉互联模块可以进行数据宽度自动转换。另外一个接口就是Stream接口，也就是AXI4
   stream流接口，在这里主要是用来传输图像数据到HDMI接口，由于RGB数据是24位的，因此这里的Stream
   Data Width也设置成24。Frame
   Buffers为帧缓存数，可以储存多帧图像，本实验中只使能1帧图像缓存。Line
   Buffer Depth类似于fifo缓存，以Stream Data
   Width为单位，设置大些，可以缓存的数据越多。


    
7) 配置VDMA高级参数，在这里使能Allow Unaligned
   Transfers，如果不使能，在软件中就要对数据按照Memory Map Data
   Width对齐，比如我们设置的是64，也就是要64位对齐。但这里使能了，就可以进行不对齐的数据传输。GenLock用于避免读和写通道同时访问同一个frame，而使图像显示不正常。由于我们只有一个读通道，设置它的意义并不是很大，需要与写通道配置才有用处。组合方式比较多，具体可以参考VDMA的手册PG020。


    
8) 添加视频时序控制器，此模块主要是用来产生图像的时序。


    
9) 配置视频时序控制器参数（简称VTC），Enable
   Generation是产生输出时序的使能，选择之后会出现vtiming_out总线信号。Enable
   Detetion是用于检测输入时序信号的使能，如果使能，会出现vtiming_in总线，由于本实验为图像输出，因此不使能。


    
10) 添加AXI流转视频输出控制器


    
11) 配置AXI流转视频输出控制器参数，Clock
    Mode选择Independent，指的是AXI4-Stream和Video的时钟是独立的，异步的，而common是同步的。在本实验中两者是异步的。Timing
    Mode的Slave mode是指VTC是时序的Slave，由Video Out模块通过clock
    enable控制时序的输出。Master Mode指VTC是时序的master，不由Video
    Out控制。详情参考模块用户手册pg044。


    
添加自定义IP
~~~~~~~~~~~~

12) 由于视频有很多分辨率，各种分辨的时钟频率不相同，需要使用一个动态时钟控制器，找到例程里的repo目录，复制到自己的目录下


    
13) 添加IP仓库


    
14) 添加完成以后可以看到很多IP


    
15) 添加动态时钟控制器，这个模块主要功能是根据不同的分辨率配置出不同的时钟输出，本质上是调用了锁相环，但要注意的是，此模块的参考时钟必须设置为100MHz


    
添加HDMI编码器，用于将RGB数据转换为TMDS信号。
~~~~~~~~~~~~~~~~~~~~~~~~~~~~~~~~~~~~~~~~~~~~~


    

    
16) 连接Vivado可能无法自动连接的时钟信号


    
17) 连接其他一些关键信号


    
18) 连接中断信号，需要先添加一个Concat IP，用于中断信号连接


    

    
19) 使用Vivado自动连接功能，完成剩下的线连接


    
20) 选择所有模块自动连接


    
21) 导出IIC_0端口


    
22) 导出编码器端口TMDS


    
23) 修改其他端口的名称


    
24) 保存设计后按F6 检查设计，添加HDMI输出的xdc文件，约束管脚


    
25) xdc文件内容如下

::

 set_property IOSTANDARD TMDS_33 [get_ports TMDS_clk_n]
 set_property PACKAGE_PIN U13 [get_ports TMDS_clk_p]
 set_property IOSTANDARD TMDS_33 [get_ports TMDS_clk_p]
 set_property IOSTANDARD TMDS_33 [get_ports {TMDS_data_n[0]}]
 set_property PACKAGE_PIN W14 [get_ports {TMDS_data_p[0]}]
 set_property IOSTANDARD TMDS_33 [get_ports {TMDS_data_p[0]}]
 set_property IOSTANDARD TMDS_33 [get_ports {TMDS_data_n[1]}]
 set_property PACKAGE_PIN Y18 [get_ports {TMDS_data_p[1]}]
 set_property IOSTANDARD TMDS_33 [get_ports {TMDS_data_p[1]}]
 set_property IOSTANDARD TMDS_33 [get_ports {TMDS_data_n[2]}]
 set_property PACKAGE_PIN Y16 [get_ports {TMDS_data_p[2]}]
 set_property IOSTANDARD TMDS_33 [get_ports {TMDS_data_p[2]}]
 #set_property PACKAGE_PIN Y19 [get_ports {hdmi_hpd_tri_i[0]}]
 #set_property IOSTANDARD LVCMOS33 [get_ports {hdmi_hpd_tri_i[0]}]
 #set_property PACKAGE_PIN V16 [get_ports hdmi_oen]
 #set_property IOSTANDARD LVCMOS33 [get_ports hdmi_oen]
 set_property PACKAGE_PIN V18 [get_ports hdmi_ddc_scl_io]
 set_property IOSTANDARD LVCMOS33 [get_ports hdmi_ddc_scl_io]
 set_property PACKAGE_PIN V17 [get_ports hdmi_ddc_sda_io]
 set_property IOSTANDARD LVCMOS33 [get_ports hdmi_ddc_sda_io]

26) 编译生成bit文件，之后导出硬件


    

    
软件工程师工作内容
------------------

以下为软件工程师负责内容。

Vitis软件编写调试
-----------------

1) 运行Vitis，新建一个名为vdma_hdmi的APP，已经预备了相关程序


    
2) 由于程序文件较多，不再具体介绍，直接复制例程的源代码。删除src目录下的文件，使用例程的src目录文件代替


    
3) 在Vitis下按F5刷新

4) 在display_ctrl文件夹中，diplay_ctrl.c主要是显示的控制，vga_mode.h中加入了一些显示分辨率的时序参数。


    
在display_ctrl.c中，可以修改displayPtr->vMode，改变显示的分辨率。


    
5) Dynclk文件中，主要功能是根据不同的分辨率配置锁相环的时钟输出，产生像素时钟。


    
6) 有个概念注意要弄清楚，一般我们知道，图像有行和列的概念，在VDMA的寄存器中，即HSIZE和VSIZE，这里多了一个STRIDE寄存器，可以理解为一行存储的最大字节数，大于等于HSIZE。注意HSIZE和STRIDE都是以字节为单位。


    
举例说明：如果显示分辨率为1920*1080，24位深度，也就是3个字节，那么HSIZE就可以设置成1920*3，VSIZE为1080，STRIDE为1920*3；如果显示分辨率改为1280*720，那么HSIZE设置为1280*3，VSIZE为720，STRIDE可以不用变，仍然为1920*3。

7) 连接HDMI输出端口到显示器，编译运行


    
8) 显示器显示出一幅图片


    
本章小结
--------

本章介绍了使用VDMA实现HDMI的显示，使用的模块较多，需要大家多看看各个模块的文档，尤其是VDMA，VTC，Video
Out，慢慢消化。此实验是后面显示实验的基础，还要是多花些时间学习。

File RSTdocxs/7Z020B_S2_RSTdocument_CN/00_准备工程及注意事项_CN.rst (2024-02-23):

准备工程及注意事项
====================

软件环境
--------

软件开发环境基于Vivado 2023.1


         
硬件环境
--------

+---------------------------------+------------------------------------+
| 开发板型号                      | 芯片型号                           |
+=================================+====================================+
| AX7015                          | XCZ7015-2CLG485                    |
+---------------------------------+------------------------------------+
| AX7010/AX7Z010                  | XCZ7010-1CLG400                    |
+---------------------------------+------------------------------------+
| AX7020/AX7Z020                  | XCZ7020-2CLG400                    |
+---------------------------------+------------------------------------+
| AX7021                          | XC7Z020-2CLG484                    |
+---------------------------------+------------------------------------+

工程对应
--------

+----------------------------------+-----------------------------------+
| 章节名称                         | 工程目录                          |
+==================================+===================================+
| PS端UART读写控制                 | ps_uart                           |
+----------------------------------+-----------------------------------+
| XADC的使用                       | ps_xadc                           |
+----------------------------------+-----------------------------------+
| I2C的读写                        | i2c_test                          |
+----------------------------------+-----------------------------------+
| CAN总线的读写                    | ps_can                            |
+----------------------------------+-----------------------------------+
| RS485测试                        | rs485_test                        |
+----------------------------------+-----------------------------------+
| PL读写PS端DDR数据                | pl_read_write_ps_ddr              |
+----------------------------------+-----------------------------------+
| 通过BRAM实现PS与PL数据交互       | bram_test                         |
+----------------------------------+-----------------------------------+
| 双核AMP的使用                    | dualcore_amp                      |
+----------------------------------+-----------------------------------+
| ZYNQ下使用Free RTOS              | freeos_test                       |
+----------------------------------+-----------------------------------+
| DMA环通测试                      | dma_loopback                      |
+----------------------------------+-----------------------------------+
| DMA使用之DAC波形发生器（AN108）  | ad9708_dma                        |
+----------------------------------+-----------------------------------+
| DMA使用之ADC示波器（AN108）      | ad9280_dma_hdmi                   |
+----------------------------------+-----------------------------------+
| DMA使用之ADC示波器（AN9238）     | ad9238_dma_hdmi                   |
+----------------------------------+-----------------------------------+
| DMA使用之ADC示波器（AN706）      | ad7606_dma_hdmi                   |
+----------------------------------+-----------------------------------+
| 基于ADC模块的Scatter/Gather      | ad9280_sg_dma_hdmi                |
| DMA使用(AN108)                   |                                   |
+----------------------------------+-----------------------------------+
| 基于DAC模块的Scatter/Gather      | ad9767_sg_dma                     |
| DMA使用(AN9767)                  |                                   |
+----------------------------------+-----------------------------------+
| OV5640摄像头的采集显示一         | ov5640_single                     |
+----------------------------------+-----------------------------------+
| OV5640摄像头的采集显示二         | ov5640_dual                       |
+----------------------------------+-----------------------------------+
| 双目摄像头以太网传输             | an5642_lwip_double                |
+----------------------------------+-----------------------------------+
| SD卡读写操作之BMP图片显示        | sd_hdmi_out                       |
+----------------------------------+-----------------------------------+
| SD卡读写操作之摄像头抓拍         | ov5640_sd                         |
+----------------------------------+-----------------------------------+
| 基于AN5641模块的MIPI采集显示     | an5641_mipi_hdmi                  |
+----------------------------------+-----------------------------------+
| 基于AN831音频模块的录音与播放    | audio_i2s_stream                  |
+----------------------------------+-----------------------------------+
| 7寸液晶屏模块的使用              | lcd7_touch                        |
+----------------------------------+-----------------------------------+
| 7寸触摸屏的使用                  | lcd7_touch                        |
+----------------------------------+-----------------------------------+
| 基                               | ad9280_lwip                       |
| 于AN108模块的ADC采集之以太网传输 |                                   |
+----------------------------------+-----------------------------------+
| 基于                             | ad9238_lwip                       |
| AN9238模块的ADC采集之以太网传输  |                                   |
+----------------------------------+-----------------------------------+
| 基                               | ad7606_lwip                       |
| 于AN706模块的ADC采集之以太网传输 |                                   |
+----------------------------------+-----------------------------------+
| 基于UDP/TCP的远程更新QSPI FLASH  | remote_update                     |
+----------------------------------+-----------------------------------+

注意事项
--------

所有的工程目录下都有个bootimage文件夹，存放了对应的BOOT.bin文件，可将此文件拷贝到Vitis_image_download文件夹，覆盖原有的BOOT.bin。


      
Vitis_image_download文件夹在course_s2_Vitis目录下面，进入文件夹，右键点击program_qspi.bat，打开编辑


      

      
将program_flash路径改成自己的软件安装路径，保存并关闭。


      
双击program_qspi.bat，即可下载BOOT.BIN到QSPI FLASH，建议用JTAG模式下载。


      
也可以采用SD卡启动方法，把BOOT.bin文件拷贝到SD内，启动方法前面在基础篇已经讲过，不再赘述。

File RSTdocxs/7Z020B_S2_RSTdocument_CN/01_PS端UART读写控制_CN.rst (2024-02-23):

PS端UART读写控制
==================

在前面的实验中，大家或多或少会发现有打印信息的情况，主要是调用”xil_printf”或”printf”，但是通过什么打印信息呢？我们还记得打印信息之前设置了串口，是的，确实是串口，但这些函数是如何调用串口呢？其实我们可以在”xil_printf”函数定义中看到，注意outbyte函数就是调用UART打印的。


      
再进入outbye的函数，即可看到调用了PS端UART的函数，得以在串口中显示。


      
除了打印信息之外，如果我们想用UART进行数据传输呢？本章便来介绍PS端UART的读写控制，实验中，每隔1S向外发送一串字符，如果收到数据，产生中断，并将收到的数据再发送出去。

Vivado工程基于“ps_hello”。

UART模块介绍
------------

以下是UART模块的结构图，TxFIFO和RxFIFO都为64字节。


      
下图为UART的四种模式


      
可以用remote loopback
mode测试物理电路是否正常，使用API函数XUartPs_SetOperMode


      
软件工程师工作内容
------------------

以下为软件工程师负责内容。

Vitis程序开发
-------------

1. 本实验流程如下：

**主程序流程：**

UART初始化 —— 设置UART模式 —— 设置数据格式 —— 设置中断 —— 发送UART数据检查是否收到数据 —— 如果收到,发送收到的数据,如果没有,等待1秒钟,继续发数据

**中断程序流程：**

中断初始化 —— 设置接收FIFO trigger中断寄存器,设置为1,即收到一个数据就中断 —— 打开接收trigger中断REMPTY及接收FIFO空中断RTRIG

**中断服务程序：**

判断状态寄存器是trigger还是empty —— 清除相应中断 —— trigger状态读取RxFIFO数据,empty状态将接收标志ReceivedFlag置1

2. 首先来看寄存器，主要分为配置寄存器，用于配置UART的模式，波特率；中断寄存器配置；发送以及接收寄存器的配置。


      
3. 设置trigger level寄存器，6位，1~63


      
4. 发送部分比较简单，只要向TxFIFO写数据即可，而接收部分需要用到中断，在这里主要用到Intrpt_en_reg和Intrpt_dis_reg，一般这两个中断寄存器都是成对使用的。使能相应的中断，关闭其余的中断。


      
需要设置接收的RTRIG中断，也就是trigger中断，在此之前设置好trigger的值，也就是RxFIFO里的数据个数达到了trigger值，即中断，同时打开REMPTY空中断，判断是否为空。


      
5. 在中断服务程序中读取status register的值，判断接收是否有trigger或为空


      

      
6. 在main函数中进行模式的设置，可以直接调用函数，设置为正常模式，数据格式设置为波特率115200，数据8bit，无校验位，1bit停止位。UartFormat定义在uart_parameter.h中。


      

      
7. 中断控制器程序初始化可参考按键中断方式，用法类似。

8. 在main函数中将trigger level设置为1，打开trigger和empty中断。


      
9. 数据的发送和接收函数参考了UARTPS的XUartPs_Send和XUartPs_Rev函数，但它们会打开某些中断，不符合预期，因此做了修改。


      
在接收缓存中设置了最大2000字节的缓冲，可以根据需要修改。

\ 

10. 在中断服务程序中，将ReceivedBufferPtr指针地址和ReceivedByteNum加上接收到的个数，如果FIFO空了，将ReceivedFlag置为1。同时向中断状态寄存器写数据，清除中断。


      

      
UG585 UART部分清除中断

11. 在main函数中，将ReceivedFlag和ReceivedByteNum清零，ReceivedBufferPtr指针复位。


      
12. Uart发送函数中，判断TxFIFO是否满，否则继续发送，直到计数达到NumBytes


      
13. Uart接收函数中，判断接收RxFIFO是否为空，否则继续读数据，NumBytes为需要读取的数据个数，但如果接收的FIFO空了，计数没有达到这个值，也会结束此函数。


      
14. 除了自己写程序外，还可以从platform.spr的BSP中导入模块的例子，参考Xilinx提供的程序，方便学习。


      
板上验证
--------

1. 接下来下载程序


      
2. 打开工程目录下的串口调试工具


      
3. 设置好参数如下，打开串口，即可看到打印信息。


      
4. 在发送区填入数据，点击手动发送，即可看到接收区的数据。


      
总结
----

本章学习了UART的发送与接收，以及中断的使用，希望大家能养成良好的习惯，多看文档，理解原理，能对系统的认识有很大提高。




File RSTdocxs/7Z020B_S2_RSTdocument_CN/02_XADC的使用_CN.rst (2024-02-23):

XADC的使用
============

本章介绍XADC的使用，XADC内嵌在PS端，允许CPU或其他主机连接XADC，而不用使用PL端。XADC最大采样率为1MSPS，精度为12bits，内置电压和温度传感器，可监测芯片的电压及温度信息。如图所示电压传感器可监测芯片的VCCINT,VCCAUX,VCCBRAM等，VP_0和VN_0为一对专用的ADC模拟输入口。VAUXP[*]和VAUXN[*]也是ADC输入口，但是不用作ADC输入口时，可用作普通IO使用。在AX7015/AX7021/AX7010/AX7020/AX7Z035/AX7Z100开发板上这些引脚均未引出。因此本实验主要测量温度传感器Temperature
Sensor以及电压传感器Supply Sensors的值。


      
本实验介绍三种读取传感器信息值的方法。首先需要新建Vivado工程，同样以“ps_hello”工程为基础，另存一个工程，不再赘述。

Hardware读取XADC
----------------

1. 打开工程，连接好开发板电源，JTAG下载器，并将开发板调整为JTAG模式，开发板上电，点击Open
   Hardware Manager，再点击Auto Connect，发现硬件。


      
2. 右键选中XADC，新建Dashboard


      
3. 修改名称，点击OK


      
4. 默认会有温度信息


      
5. 点击+将电压值添加到窗口


      
6. 显示如下


      
此方法优点是图形化显示，较为直观，但缺点是无法得到数据值。下面介绍PS读取XADC信息。

PS读取XADC信息
--------------

1. 打开Vitis软件，新建Vitis工程，已经为大家准备好了程序，可拷贝到新的工程


      
2. 可以在platform.spr的BSP中看到PS自带有XADC外设


      
3. 在本实验中主要用到xadcps.h和xadcps_hw.h


      
4. 此实验现象为读取温度和电压的数据，并每隔1S通过串口打印出来。通过XAdcPs_GetAdcData函数读取原始值，用XAdcPs_RawToTemperature宏将ADC值转换为温度值。用XAdcPs_RawToVoltage转换为电压值。


      
5. Run as下载后在串口工具中可看到打印信息如下：


      
此方法简单方便，可以读取数据信息，但是其信号对于PL端来说是不可见的，灵活性差些。参考资料UG585，UG480。下面再介绍AXI总线方式读取数据。

AXI总线读取XADC信息
-------------------

前面PS端读取XADC实验是通过查询的方式读取，本小节实验我们想在查询的基础上，添加中断，监测温度是否超过一定温度，如果超过了，就产生中断。

1. 添加XADC模块，点击Run Connection Automation


      
2. 重新配置Zynq CPU，添加PL端中断，点击OK完成


      
3. 连接XADC中断到CPU中断口， 

4. 由于板子连接了Vp_Vn，以及VAUX1, VAUX9, VAXU12四个XADC的外部引脚，因此需要对XADC模块进行配置，在Basic界面设置为Channel Sequencer


      

      
在Channel Sequencer界面，选择上四路通道，点击OK


      
5. 将四个通道导出引脚，并修改名称


      
6. 重新Generate Output Products，之后open Elaborated Design，并在IOPorts里修改引脚位置，这些位置是固定的，主要是电平标准的设置，保存到xdc文件内。Vp_Vn读取的是板子的电流，VAUX12为板子的供电电压5V，VAUX1和VAUX9连接的是SMA接头。


      
7. 此次需要生成Bitstream，点击Generate Bitstream，生成FPGA下载文件。


      
8. 重新Export Hardware，在这里在选中Include bitstream


      
9. XADC有很多报警信号alarm，如温度，电压等，此实验通过设置XADC的温度的Temp Upper和Temp Lower值，设置中断，一旦温度超过Temp Upper的值，就会触发中断


      
温度值与ADC Code值换算关系式如下，程序中有现成的公式可用


      
10. 新建Vitis工程


      
11. 在platform.spr的BSP里多了一个模块，也就是刚才添加的XADC模块，用到了sysmon.h和sysmon_hw.h头文件。


      
12. 以下为设置温度的upper和lower值，打开全局中断和温度中断，中断寄存器可以在PG091文档中找到


      
温度中断使能为ALM[0]，打开此中断即可


      
XSysMon_IntrGlobalEnable(); 全局中断使能函数

XSysMon_IntrEnable(); 中断使能函数，可使用MASK宏定义来确定需要打开的中断

13. 中断服务程序中使用XsysMon_IntrGet_Status();函数读取中断状态寄存器，确定是否是温度中断，打印信息，最后使用XSysMon_IntrClear();函数清除中断


      
14. 打开Run Configuration窗口，新建System Debugger，选择Program
    FPGA，点击Run


      
15. 在程序中设置了电流的转换，电流为0.48A左右，电压VAUX12为5V左右，有一定偏差。SMA没有连接信号。


      
XADC的ADC接口电压范围是0-1V，我们的电路设计做了分压，分压值为10，因此从SMA接入的电压输入范围为0-10V。

16. 程序中设置Upper为80摄氏度，在高于80度后会触发一次中断，等温度降到lower温度后，如果温度再次上升到Upper温度之上，又会触发中断。如下串口所示。


      
当然还有其他许多报警，可以通过配置Alarm Threshold寄存器和中断寄存器实现不同的监测功能。


      
此种方法不但可以访问温度和电压传感器，还可以在PL端进行访问，本章不再做讲解。

本章小结
--------

本章介绍了三种读取XADC的方法，各有优缺点，用户可根据需求选择需要的方式。



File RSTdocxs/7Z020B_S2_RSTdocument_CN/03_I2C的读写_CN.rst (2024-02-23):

I2C的读写
===========

从原理图中可以看出，PS端的I2C接了三个外设，分别是EEPROM，实时时钟RTC，温度传感器，本章介绍如何利用I2C读写外设。

 


      
硬件工程搭建
------------

硬件工程基于”ps_hello”，另存为一份工程“i2c_test”。配置I2C0到MIO50-51，重新Generate Output Products，并导出硬件平台。


      
Vitis程序开发
-------------

RTC测试
~~~~~~~

以下是RTC DS1338的寄存器地址及说明，主要是控制类寄存器07H和时分秒寄存器00H~06H。


      
在DS1338手册中可以看到I2C读写时序，其中器件地址为0x68 + r/w，而xilinx提供的API函数也是7bit地址+1bit读写位.


      
1. 在Vitis软件中新建工程rtc_test，其中添加了PS_i2c.c，主要提供的是i2c的初始化和读写操作等函数。


      
2. 在main函数中，首先是进行i2c的初始化


      
3. 接下来设置为Squart-Wave模式，并设置为32.768KHz，因为板子上的晶振是32.678KHz


      
4. 判断RTC是否是停止状态，如果是停止状态，设置秒寄存器的bit7设置为0。


      
5. 设置初始值时分秒寄存器初始值


      
6. 最后是打印时钟信息


      
7. 下载验证


      
8. 串口工具查看打印信息


      
温度传感器测试
~~~~~~~~~~~~~~

温度传感器用的是LM75，以下是它的寄存器说明，只要读取Temperature寄存器的值就可以了，因此它的地址为0x48+r/w\ 

而它的数据是有两个字节，第一个字节为整数位，第二个字节为小数位，最高位为1，即0.5摄氏度，如果为0，小数位则为0


      
1. 新建Vitis工程，在temp.c中设置了读取的数据为2字节


      
2. 程序很简单，根据收到的数据值，每秒打印出来显示。


      
3. 下载程序


      
4. 串口打印信息


      
EEPROM读写
~~~~~~~~~~

1. 新建一个Vitis工程，导出emample工程


      
2. 导入xiicps_eeprom_polled_example工程


      
EEPROM 的程序比较简单，具体代码大家可以自己去看，这里不详细说了。下面只对程序的功能和一些要点做一下介绍：

1. EEPROM 的设备地址在程序的前面做了定义，这个地址就是系统访问外部 IIC
   外设的设备地址，这里EEPROM地址为 0x54, 相当于 8bit 的 0xA8。


      
EEPROM 的设备地址可以在 24LC04 的芯片手册上找的到，高 4 位是 A，后面 3 位是 Block地址，因为 24LC04 只有 2 个 Block, 所以高 2 位 Block Address 是无效的。


      
2. 由于EEPROM的地址为1个字节，在程序中修改如下


      
3. 程序流程如下：

ReadBuffer清0，WriteBuffer赋FF写16个字节到EEPROM读EEPROM的16个字节到ReadBuffer检验是否正确Readbuffer清0，WriteBuffer赋值10~25写16字节到EEPROM读16字节到ReadBuffer检验是否正确返回

4. 下载程序


      
5. 串口结果


      
本章小结
--------

本章介绍了PS端的I2C控制外设的实验，用户可以再做下。





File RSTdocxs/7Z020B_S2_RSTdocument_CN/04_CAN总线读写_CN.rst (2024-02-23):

CAN总线读写
=============

本章介绍利用板子上了两路CAN接口进行回环测试。

硬件环境搭建
------------

基于”ps_hello”工程另存为一份ps_can，打开block design，配置ZYNQ核，选择CAN0和CAN1，点击OK即可。


      
保存设计，Generate Output Products


      
重新导出硬件信息，不包含bitstream


      
Vitis程序开发
-------------

在Vitis软件中新建工程can_test，并引入example工程，xcanps_polled_example，此example工程是测试单个CAN接口的内部loopback，本实验是在此example基础上进行的修改，将两个CAN接口都设置为Normal Mode，并在外部连接起来，进行loopback测试。


      
1. 功能其实也比较简单，主要就是两路CAN的初始化，并设置为Normal Mode，然后是loopback。


      
2. CanLoopback函数也比较简单，先是CAN0发数据，CAN1接收数据并进行数据对比，然后清除RxBuffer的数据，再是CAN1发送数据，CAN0接收数据并进行数据对比，测试结束。


            
下载测试
--------

1. 利用杜绑线将CAN0的H和L分别与CAN1的H和L进行连接


      
2. 下载程序


      
3. 在串口看到打印信息，大家也可以进入Debug模式进行数据的观测。



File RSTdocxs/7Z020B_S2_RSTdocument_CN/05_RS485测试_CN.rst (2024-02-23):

RS485测试
===========

本章介绍两路RS485接口的读写测试实验。

硬件环境搭建
------------

基于”ps_hello”工程，另存为一份rs485_test工程

1. 第一路RS485用的是PS端的UART0，而DE信号用的是MIO9，GPIO MIO已经勾选上。


      
配置时钟频率为100MHz


      
打开PL端中断


      
2. 添加AXI GPIO模块，并配置为输出，位宽为1，用于第二路RS485的DE控制


      
3. 添加UART16550模块，用于第二路RS485的数据端口


      
4. 自动连接


      

      
5. 删除UART引脚，并展开UART接口

\ 

6. 添加constant模块，并设置位宽为1，值为1


      
7. 连接ctsn，rin信号


      
8. 再添加一个constant模块，值设置为0


      
9. 连接freeze，dcdn，dsrn信号


      
10. 将sin和sout导出引脚


      
11. 连接中断信号到ZYNQ的IRQ_F2P接口


      
12. 修改引脚名称


      
13. 引脚绑定


      
14. 生成bitstream


      
15. 导出硬件平台信息


         
Vitis程序开发
-------------

1. 新建Vitis工程rs485_test，本实验是根据UART和UART16550模块的example工程修改而来，程序流程为，初始化RS485 DE和UART设置RS485 0为发送，设置RS485 1为接收，发送16个字节数据，接收后进行数据对比反向，设置RS485 1为发送，设置RS485 0为接收，发送16个字节数据，接收后进行数据对比程序结束


      
2. 注意要进行BSP的设置，将打印输入输出改成ps7_uart_1，也就是PS端的UART


      

      
3. PS端GPIO设置MIO9为输出，因为它是连接在RS485 0的DE上的。


      
4. PL端GPIO设置，连接到RS485 1的DE


      
5. 在对UART初始化中，将PS端UART和PL端UART16550都设置为波特率115200，8bit，无奇偶校验位，1bit停止位


      
6. 在回环的函数中，首先是将RS485_0设置为输出，RS485_1设置为输入，设置完后，在发送数据之前等待1ms时间，是因为有切换延迟。


      
1. 测试后，切换方向RS485_0设置为输入，RS485_1设置为输出，再次进行数据发送


      
板上验证
--------

1. 用杜邦线将A1与A2连接，B1与B2连接如下：


      
2. 下载界面设置


      
3. 串口打印信息


      
本章小结
--------

本章介绍了利用板子上的两路RS485进行回环测试，大家可以在此基础上功能扩展进行测试。




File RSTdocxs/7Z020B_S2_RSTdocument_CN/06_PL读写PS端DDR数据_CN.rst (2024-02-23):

PL读写PS端DDR数据
===================

PL和PS的高效交互是zynq 7000
soc开发的重中之重，我们常常需要将PL端的大量数据实时送到PS端处理，或者将PS端处理结果实时送到PL端处理，常规我们会想到使用DMA的方式来进行，但是各种协议非常麻烦，灵活性也比较差，本节课程讲解如何直接通过AXI总线来读写PS端ddr的数据，这里面涉及到AXI4协议，vivado的FPGA调试等。

ZYNQ的HP端口使用
----------------

zynq 7000 SOC的HP口是 High-Performance
Ports的缩写，如下图所示，一共有4个HP口，HP口是AXI
Slave设备，我们可以通过这4个HP接口实现高带宽的数据交互。


         
以”ps_hello”工程为基础，另存为一个工程

1. 在vivado的界面中HP的配置如下图(HP0~HP3)，这里面有使能控制，数据位宽选择，可选择32或64bit的位宽。把MAXI GP0接口取消，在本实验中不需要。


      
我们的实验启用HP0配置为64bit位宽，使用的时钟是150Mhz，HP的带宽是150Mhz
\* 64bit，对于视频处理，ADC数据采集等应用都有足够的带宽。


      
2. 如下图所示，配置完HP端口以后，zynq会多出一个AXI Slave端口，名称为S_AXI_HP0，不过这些端口都是AXI3标准的，我们常用的是AXI4协议，这里添加1个AXI Interconnect IP，用于协议转换（AXI3<->AXI4）。


      
3. 将FCLK_CLK0时钟和S00_AXI导出，并修改名称


      
4. 在空白处右键选择Create Port，添加一个时钟输入接口


      

      
5. 添加一个复位模块，并连接时钟如下


      
6. 单击S00_AXI接口，选择时钟接口为axi_hp_clk


      
7. 双击S00_AXI引脚进行配置，改为AXI4接口


      
再次双击，打开配置将AXI的Burst长度设置为最大256，如果与上一步同时设置，可能会不成功。


      

      
8. 导出复位引脚，修改名称，并连接对应信号


      
9. 修改复位的关联时钟为axi_hp_clk


      
10. 在Address Editor里点击自动分配地址空间


      
11. 保存设计，并按F6检查设计


      
12. Generate Output Products生成输出文件。

13. 添加其他hdl文件


      
PL端AXI Master
--------------

AXI4相对复杂，但SOC开发者必须掌握，对于zynq的开发者，笔者建议能够在一些已有的模板代码基础上修改。AXI协议的具体内容可参考Xilinx
UG761 AXI Reference Guide。在这里我们简单了解一下。

AXI4所采用的是一种READY，VALID握手通信机制，即主从模块进行数据通信前，先根据操作对各所用到的数据、地址通道进行握手。主要操作包括传输发送者A等到传输接受者B的READY信号后，A将数据与VALID信号同时发送给B，这是一种典型的握手机制。


         
AXI总线分为五个通道：

-  读地址通道，包含ARVALID, ARADDR, ARREADY信号；

-  写地址通道，包含AWVALID，AWADDR, AWREADY信号；

-  读数据通道，包含RVALID, RDATA, RREADY, RRESP信号；

-  写数据通道，包含WVALID, WDATA，WSTRB, WREADY信号；

-  写应答通道，包含BVALID, BRESP, BREADY信号；

-  系统通道，包含：ACLK，ARESETN信号；

其中ACLK为axi总线时钟，ARESETN是axi总线复位信号，低电平有效；读写数据与读写地址类信号宽度都为32bit；READY与VALID是对应的通道握手信号；WSTRB信号为1的bit对应WDATA有效数据字节，WSTRB宽度是32bit/8=4bit；BRESP与RRESP分别为写回应信号，读回应信号，宽度都为2bit，‘h0代表成功，其他为错误。

读操作顺序为主与从进行读地址通道握手并传输地址内容，然后在读数据通道握手并传输所读内容以及读取操作的回应，时钟上升沿有效。如图所示：


      
写操作顺序为主与从进行写地址通道握手并传输地址内容，然后在写数据通道握手并传输所读内容，最后再写回应通道握手，并传输写回应数据，时钟上升沿有效。如图所示：


      
在我们不擅长写FPGA的一些代码时我们往往要借鉴别人的代码或者使用IP
core。在这里笔者从github上找到一个AXI
master的代码，地址是https://github.com/aquaxis/IPCORE/tree/master/aq_axi_vdma。这个工程是一个自己写的VDMA，里面包含了大量可参考的代码。笔者这里主要使用了aq_axi_master.v这个代码用于AXI
master读写操作。借鉴别人代码有时会节省很多时间，但如果不能理解的去借鉴，出现问题了很难解决。具体可以参考aq_axi_master.v代码，有部分修改。

ddr读写数据的检验
-----------------

有了AXI
Master读写接口以后比较编写了一个简单的验证模块，这个验证模块以前是用来验证ddr
ip的，通过每8bit写入以后递增的数据，然后读取出来比较。这里要注意的是PS端DDR的起始地址和大小，还有地址的单位是byte还是word，AXI总线的地址单位是byte，测试模块的地址单位是word（这里的word不一定是4byte）。文件名mem_test.v。

Vivado软件的调试技巧
--------------------

AXI读写验证模块只有一个error信号用于指示错误，如果有数据错误我们希望能更精确的信息，altera的quartus
II软件中有signal tap工具，xilinx
的ISE中有chipscope工具，这些都是嵌入式逻辑分析仪，对我们调试有很大帮助，在vivado软件中调试更加方便。如下图所示点击Set
Up Debug可直接进入调试配置界面。


      
具体的添加方法在course_s1中的”PL的“Hello
World”LED实验”中已经讲过，可参考。

并在XDC文件里绑定error信号到PL端LED灯上。


      
上电验证
--------

生成bit文件后导出到Vitis，运行Vitis，如下图所示。因为工程移动位置后Vitis找不到硬件信息，所以又重新建了一个硬件平台，top_hw_platform_1，这里的top_hw_platform_0，是笔者调试时产生的。大家可以直接删除，同时将文件也删除，删除以后可将留下top_hw_platform_1改名为top_hw_platform_0。我们在Vitis里建立了一个helloworld程序，虽然我们仅仅测试PL端读取PS端DDR，但是PS如果不工作起来，DDR控制器也是没有工作的，所以这个简单的helloword程序就是为了让DDR控制器工作起来。注意一定要从Vitis下载，如果直接在Vivado中下载bit文件，将无法正常运行。我们配置运行选项，如下图所示：


      
点击运行后系统会复位并且下载FPGA的bit文件。然后回到vivado界面点击Program
and Debug栏自动连接目标如下图所示：


      
自动连接硬件后可发现JTAG连上的设备，其中有一个hw_ila_1的设备，这个设备就是我们debug设备，选中后可点击上方黄色三角按钮捕捉波形。如果有些信号没有显示完整，可点击波形旁边的“+”按钮添加。


      
点击捕获波形以后如下图所示，如果error一直为低，并且读写状态有变化，说明读写DDR数据正常，用户在这里可以自己查看其它的信号来观察写入DDR的数据和从DDR读出的数据。


      
本章小结
--------

zynq系统相对于单个FPGA或单个ARM要复杂很大，对开发者的基础知识要求较高，本章内容涉及到AXI协议、zynq的互联资源、vivado的和Vitis的调试技巧。这些都仅仅是基础知识，笔者在这里也仅仅是抛砖引玉，大家还是要多多练习，在不断练习中掌握技巧。

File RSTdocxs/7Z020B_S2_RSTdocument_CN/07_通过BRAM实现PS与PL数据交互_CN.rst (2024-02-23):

通过BRAM实现PS与PL数据交互
============================

有时CPU需要与PL进行小批量的数据交换，可以通过BRAM模块，也就是Block
RAM实现此要求。本章通过Zynq的GP
Master接口读写PL端的BRAM，实现与PL的交互。在本实验中加入了自定义的FPGA程序，并利用AXI4总线进行配置，通知其何时读写BRAM。

以下为本实验原理图，CPU通过AXI BRAM
Controller读取BRAM数据，CPU仅配置自定义的PL BRAM
Controller的寄存器，不通过它读写数据。


      
硬件环境搭建
------------

以“ps_hello”为基础，另存为一份工程，并配置打开ZYNQ的中断

1. 首先添加AXI BRAM Controller模块，用于PS端控制BRAM，双击打开配置，连接AXI总线，可用于读写BRAM模块，AXI模式设置为AXI4，数据宽度设置为32位，memory depth不在这里设置，需要在Address Editor里设置。BRAM端口数量设置为1个，用于连接双口RAM的PORTA。不使能ECC功能。


      
由于AXI4总线为字节询址，BRAM数据宽度设置也是32位，同样都是32位数据宽度，因此在映射到BRAM地址时，需要按4字节询址，即去掉最后两位，下图为BRAM控制器与BRAM的映射关系。


      
2. 添加BRAM模块，BRAM设置如下，有两种模式选择，standalon模式，此模式可以自由配置RAM的数据宽度和深度。BRAM Controller模式，此模式下地址线和数据端口默认为32位，本实验因为用到了BRAM控制器，因此选择BRAM Controller模式。Memory类型选择双口RAM，一端连BRAM控制器，一端连PL RAM控制器。


            
3. 添加自定义的PL RAM控制器pl_ram_ctrl，功能很简单，start信号有效后开始读取BRAM的数据，可通过ILA逻辑分析仪观察读取的数据，PL RAM控制器读BRAM结束后，开始向BRAM写数据，写完数据使能intr信号，即中断信号，CPU即可读取BRAM的数据。将PL控制器信号与BRAM的PORTB连接。自定义IP在ip_repo文件夹中。


      
如果想添加自定义IP到IP库中，点击IP Catalog，在Vivado Repository右键点击Add Repository


      
找到自定义IP所在文件夹，点击Select


      
跳出窗口，选择IP，点击OK


      
即可看到，出现了刚添加的IP


      
4. 连接AXI BRAM Controller的BRAM_PORTA到BRAM的PORTA，连接pl_bram_ctrl的BRAM_PORT到BRAM的PORTB。连接pl_bram_ctrl模块的中断信号intr到ZYNQ的中断口。并点击自动连接


      
5. 在Address Editor里选择BRAM询址大小，如设置4K空间，即可询址BRAM空间为1K深度。


      
Block Design添加逻辑分析仪方法
~~~~~~~~~~~~~~~~~~~~~~~~~~~~~~

6. 再介绍一种添加逻辑分析仪的方法，选中BRAM_PORT总线和intr中断，右键选择Debug


      
7. 可以看到总线上多了小昆虫，点击Run Connection Automation，自动连接


      
自动添加了一个ILA模块，并且有一个总线接口，一个信号接口


      
8. 保存设计，之后点击Generate Bitsream生成bit文件，并导出Hardware信息。


      
Vitis程序开发
-------------

1. 程序设计流程为：输入起始地址和长度CPU通过BRAM控制器写入BRAM数据通知PL控制器读取BRAM数据PL内部读完后向相同位置写入数据，初始数据由CPU告知写完后使能write_end信号，触发GPIO中断中断读取BRAM数据，打印显示

2. 进入Vitis后，在Vitis下新建项目，已经准备好程序。程序也比较简单，首先中断设置\ |image1|

3. While语句中需要输入起始地址和长度，之后调用bram_write函数


      
4. 在bram_read_write();函数里先通过BRAM控制器写入数据，数据初值为TEST_START_VAL，之后配置PL RAM控制器参数，有长度，起始地址，初始数据，以及开始信号。并在函数中判断测试长度是否超出BRAM控制器地址范围，如果超出，会报错，需要重新输入地址和长度。


            
5. 中断服务程序中，BRAM控制器读取BRAM的数据，并打印


      
实验现象
--------

1. 打开Putty


      
2. 通过Run Configurations下载程序，注意勾选Program FPGA，点击Run


      
3. 打开Hardware Manager，设置将中断信号作为触发信号，选择上升沿触发，点击开始按钮，可以看到hw_ila_1变成了Waiting for trigger状态


      
4. 在串口软件中，输入起始地址，由于BRAM询址为1K，那么可以设置为0~1023，长度设置为1~1024，注意起始地址+长度不要超过1024，因为超出了询址空间。


      
5. 输入的数据为十进制数，输入结束按回车


      
6. 打开ILA逻辑分析仪，可以看到已经触发，首先是PL控制器从BRAM读数据，之后是写数据，可以看到红色为PL读出的BRAM数据，正是CPU写入的数据，从12开始，共10个数据，PL写入的数据为黄色部分从1开始，共10个数据，正与上图CPU读BRAM的数据相符。


      
7. 同样也能看到中断信号的状态


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

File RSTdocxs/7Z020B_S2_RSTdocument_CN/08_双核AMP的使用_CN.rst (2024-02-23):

双核AMP的使用
===============

前面的例程都是采用的单核CPU，在有些情况下，比如多任务处理，并行处理等，需要用到双核CPU，本章将简单介绍双核的使用方法。并将实现以下功能：

1. CPU0实现PS端按键中断，控制PS端LED的亮灭，并向CPU1发出软件中断，让CPU1打印CPU0内存空间的一串字符

2. CPU1实现PL端按键中断，控制PL端LED的亮灭，并向CPU0发出软件中断，让CPU0打印CPU1内存空间的一串字符

3. 内存空间的划分，共享内存空间的使用

4. FSBL启动Flash

参考文档为XAPP1079，裸机下双核应用。名词解释：

AMP:
非对称多处理，每个CPU内核运行一个独立的操作系统或同一操作系统的独立实例

SMP:
对称多处理，一个操作系统实例可以管理所有CPU内核，且应用并不绑定某一内核

BMP:
混合多处理，一个操作系统实例可以同时管理所有CPU内核，但每个应用被锁定于某个指定的核心。

硬件环境搭建
------------

1. 本实验以“ps_hello”例程为基础，添加PL端的GPIO。添加axi_gpio_0设置为输出，位宽为1位，连接PL端LED。


      
2. 添加axi_gpio_1，连接PL端按键，设置为输入，位宽为1位，并使能中断


      
3. 连接后的结果如下，将axi_gpio_1的中断输出连接到CPU的IRQ_F2P端口


      
4. 配置打开GPIO
EMIO（AX7Z035和AX7Z100,以及AX7Z020和AX7Z010开发板比较特殊，没有PS端按键和LED灯，需要配置EMIO控制PL端按键和LED灯，其他板卡不需要打开此项）


      
并将EMIO宽度设置为2，一个用来控制按键，一个控制LED灯


      
将其导出，并修改名称


      
5. Generate Outputs


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

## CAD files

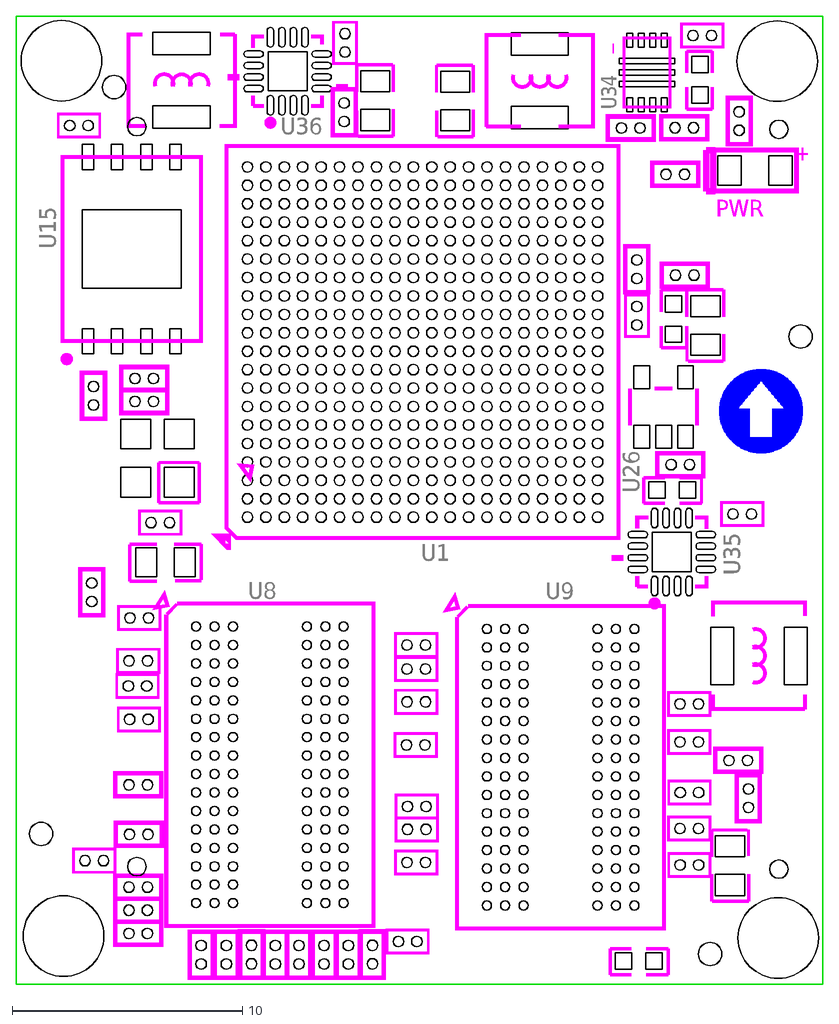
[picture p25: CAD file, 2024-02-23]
Hardware/03_structure size/AC7Z010_AC7Z020_T.dxf
U34
U15
U35
U36
+
U1
U8
U9
U26
PWR

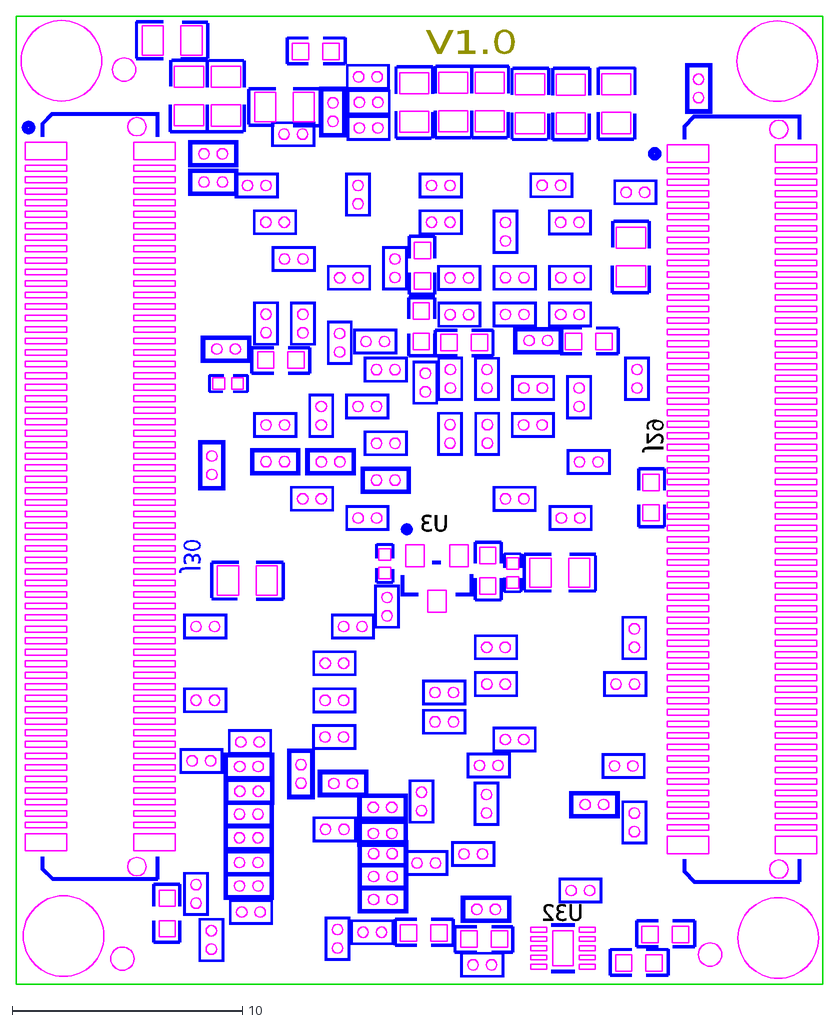
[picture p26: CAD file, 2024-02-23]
Hardware/03_structure size/AC7Z010_AC7Z020_B.dxf
U3
U32
J29
V1.0
J30

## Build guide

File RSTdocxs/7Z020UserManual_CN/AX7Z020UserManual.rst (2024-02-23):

 芯驿电子科技（上海）有限公司 基于XILINX
ZYNQ7000开发平台的开发板（型号：
AX7Z020）2019款正式发布了，为了让您对此开发平台可以快速了解，我们编写了此用户手册。

这款ZYNQ7000
FPGA开发平台采用核心板加扩展板的模式，方便用户对核心板的二次开发利用。核心板使用XILINX的Zynq7000
SOC 芯片的解决方案，它采用ARM+FPGA SOC技术将双核ARM Cortex-A9 和FPGA
可编程逻辑集成在一颗芯片上。另外核心板上含有2片共1GB高速DDR3
SDRAM芯片和1片256Mb的QSPI FLASH芯片。

在底板设计上我们为用户扩展了丰富的外围接口，比如2路CAN通信接口，2路485通信接口，2路XADC输入接口，
1路千兆以太网接口，1路USB2.0
HOST接口，1路HDMI输出接口，Uart通信接口，SD卡座，40针扩展接口等等。满足用户各种以太网高速数据交换，数据存储，视频传输处理以及工业控制的要求，是一款"专业级“的ZYNQ开发平台。为高速以太网数据传输和交换，数据处理的前期验证和后期应用提供了可能。相信这样的一款产品非常适合从事ZYNQ开发的学生、工程师等群体。

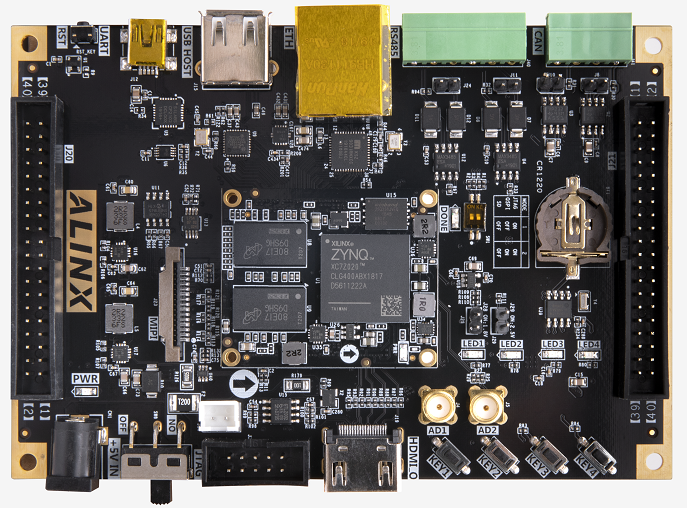
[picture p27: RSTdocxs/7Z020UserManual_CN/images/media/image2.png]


开发板简介
==========

在这里，对这款AX7Z020 ZYNQ开发平台进行简单的功能介绍。

开发板的整个结构，继承了我们一贯的核心板+扩展板的模式来设计的。核心板和扩展板之间使用高速板间连接器连接。

核心板主要由XC7Z020 + 2个DDR3 + QSPI
FLASH的最小系统构成，承担ZYNQ系统的高速数据处理和存储的功能，
ZYNQ7020和两片DDR3之间的数据位宽为32位，两片DDR3容量高达1GB。ZYNQ7020
采用Xilinx公司的Zynq7000系列的芯片，型号为XC7Z020-2CLG400I。ZYNQ7020芯片可分成处理器系统部分Processor
System（PS）和可编程逻辑部分Programmable Logic（PL）。

底板为核心板扩展了丰富的外围接口，其中包含1路千兆以太网接口、1路USB2.0
HOST接口、1路HDMI输出接口、1路SD Card接口、1路UART
USB接口、1路SD卡接口、1路MIPI接口、2路CAN总线接口、2路RS485总线接口、2路AD输入接口、2路40针的扩展口和一些按键LED。

下图为整个开发系统的结构示意图：

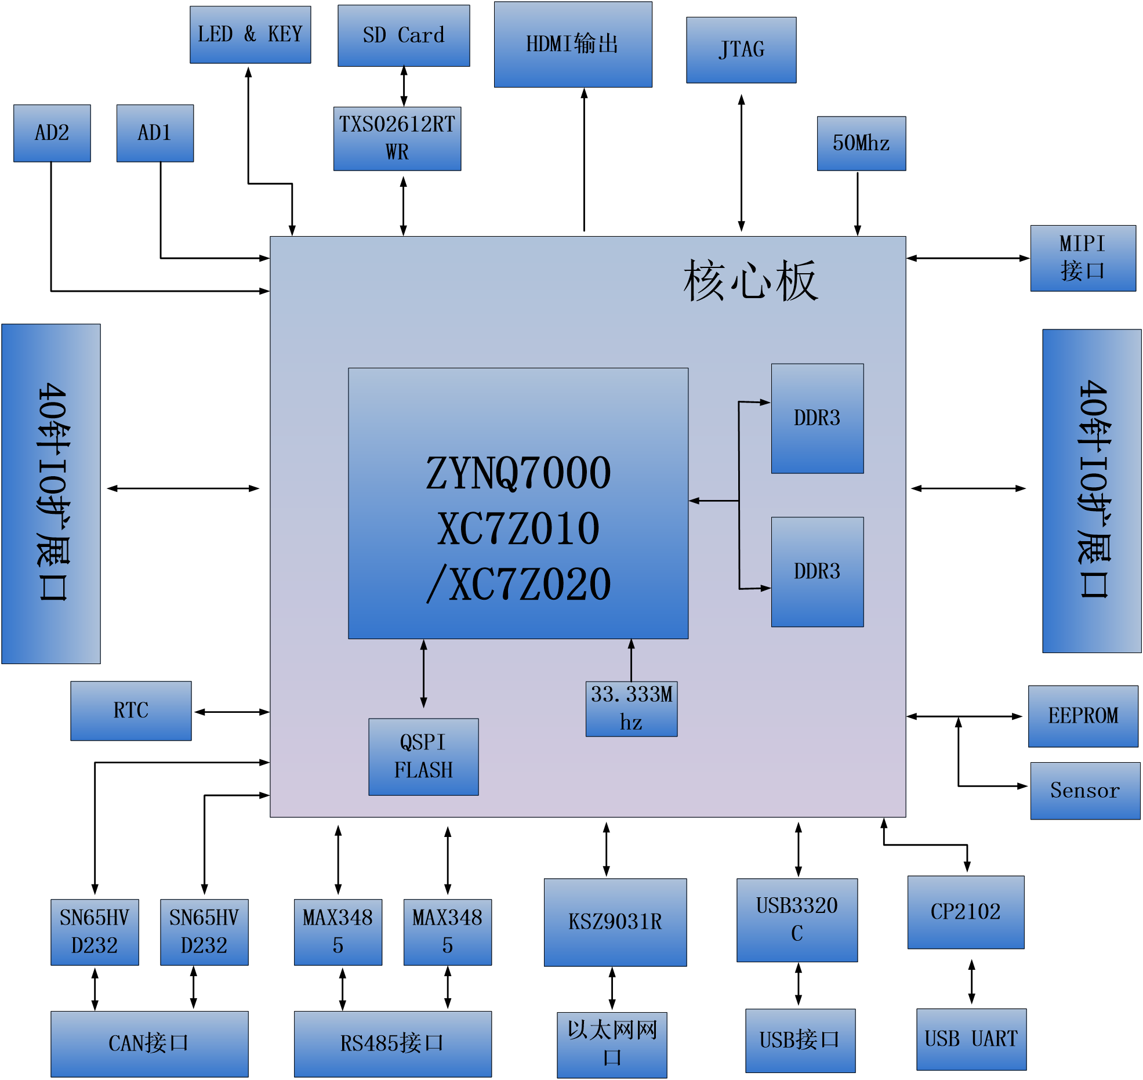
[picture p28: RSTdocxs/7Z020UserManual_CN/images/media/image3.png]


通过这个示意图，我们可以看到，我们这个开发平台所能含有的接口和功能。

-   ZYNQ7000核心板

由XC7Z020+1GB DDR3 + 256Mb QSPI
FLASH组成，另外有33.333333MHz晶振提供时钟提供给PS系统。

-  CAN通信接口

2路CAN总线接口，选用TI公司的SN65HVD232芯片。

-  485通信接口

2路485通信接口，选用MAXIM公司的MAX3485芯片。

-  千兆以太网接口

1路10/100M/1000M以太网RJ45接口，用于和电脑或其它网络设备进行以太网数据交换。网络接口芯片采用Micrel公司的KSZ9031工业级GPHY芯片。

-  一路高速USB2.0 HOST接口, 可用于开发板连接鼠标、键盘和U盘等USB外设;

-  USB Uart接口

1路Uart转USB接口，用于和电脑通信，方便用户调试。串口芯片采用Silicon Labs
CP2102GM的USB-UAR芯片, USB接口采用MINI USB接口。

-  Micro SD卡座

1路Micro SD卡座，用于存储操作系统镜像和文件系统。

-  AD模拟输入接口

2路AD模拟输入接口，可用于模拟信号的输入和电压转换，SMA接口形式。模拟信号电压输入范围为0~10V（不要输入超过这个范围的电压）。

-  一路HDMI 图像视频输出接口, 能实现1080P的视频图像传输；

-  一片IIC接口的EEPROM 24LC04;

-  板载一片温度传感器芯片LM75，用于检测板子周围环境的温度。

-  一路MIPI摄像头接口，可以连接黑金MIPI接口的OV5640摄像头。

-  1个JTAG调试接口。

-  40针扩展口

2个40针2.54mm间距的扩展口，可以外接黑金的各种模块（双目摄像头，TFT
LCD屏，高速AD模块等等）。扩展口包含5V电源1路，3.3V电源2路，地3路，IO口34路。

-  LED灯

7个发光二极管LED,
核心板上6个，底板上1个。核心板上1个电源指示灯；底板上有1个电源指示灯，1个DONE配置指示灯；4个用户指示灯。

-  4个用户按键在底板上。

AC7Z020核心板
=============

简介
----

AC7Z020(**核心板型号，下同**)核心板，ZYNQ芯片是基于XILINX公司的ZYNQ7000系列的XC7Z020-2CLG400I。ZYNQ芯片的PS系统集成了两个ARM
Cortex™-A9处理器，AMBA®互连，内部存储器，外部存储器接口和外设。ZYNQ芯片的FPGA内部含有丰富的可编程逻辑单元，DSP和内部RAM。

   这款核心板使用了2片Micron公司的MT41K256M16TW-107这款DDR3芯片，每片DDR的容量为512MB；2片DDR芯片组合成32bit的数据总线宽度，ZYNQ和DDR3之间的读写数据时钟频率高达533Mhz；这样的配置，可以满足系统的高带宽的数据处理的需求。

   为了和底板连接，这款核心板的2个板对板连接器扩展出了PS端的USB接口，千兆以太网接口，SD卡接口及其它剩余的MIO口。以及PL端的BANK13,
   BAN34和BANK35的几乎所有IO口（122个），其中BANK34和BANK35的IO的电平可以通过更换核心板上的LDO芯片来修改，满足用户不同电平接口的要求。对于需要大量IO的用户，此核心板将是不错的选择。而且IO连接部分，ZYNQ芯片到接口之间走线做了等长和差分处理，并且核心板尺寸仅为35*42（mm），对于二次开发来说非常适合。

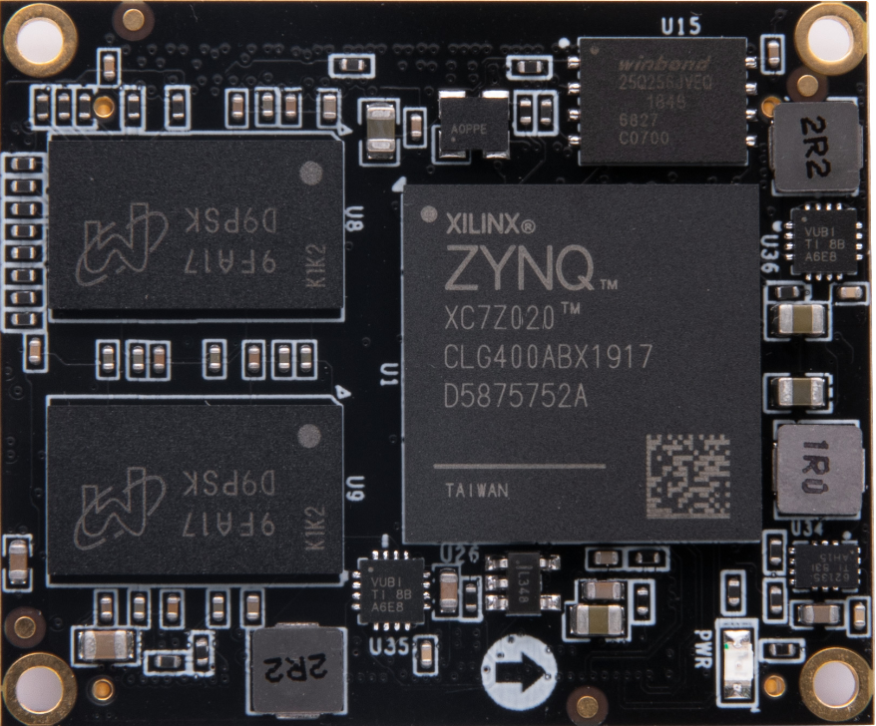
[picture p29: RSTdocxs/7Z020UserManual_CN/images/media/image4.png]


AC7Z020核心板正面图

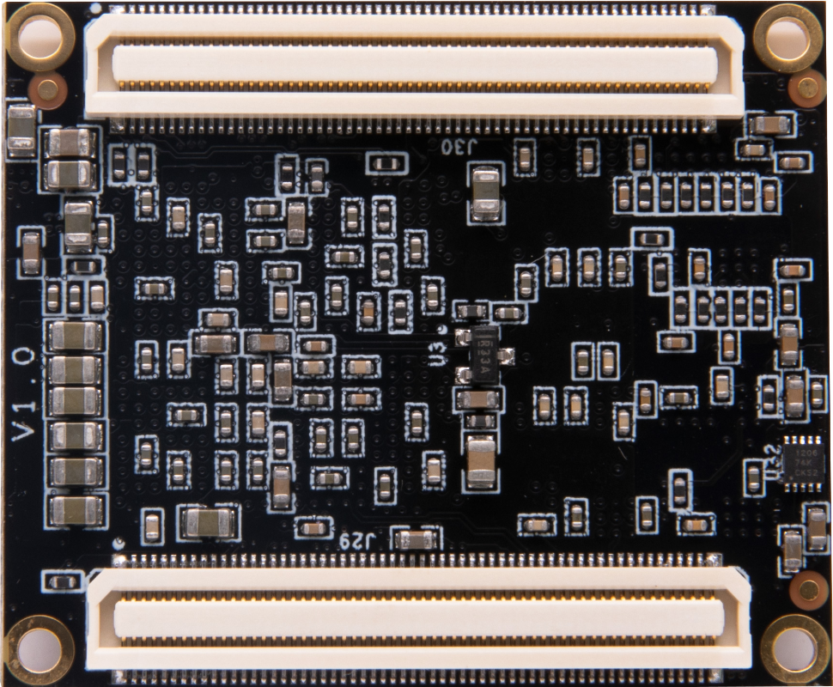
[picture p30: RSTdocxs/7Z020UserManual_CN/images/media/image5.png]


AC7Z020核心板背面图

ZYNQ芯片
--------

开发板使用的是Xilinx公司的Zynq7000系列的芯片，型号为XC7Z020-2CLG400I。芯片的PS系统集成了两个ARM
Cortex™-A9处理器，AMBA®互连，内部存储器，外部存储器接口和外设。这些外设主要包括USB总线接口，以太网接口，SD/SDIO接口，I2C总线接口，CAN总线接口，UART接口，GPIO等。PS可以独立运行并在上电或复位下启动。ZYNQ7000芯片的总体框图如图2-2-1所示

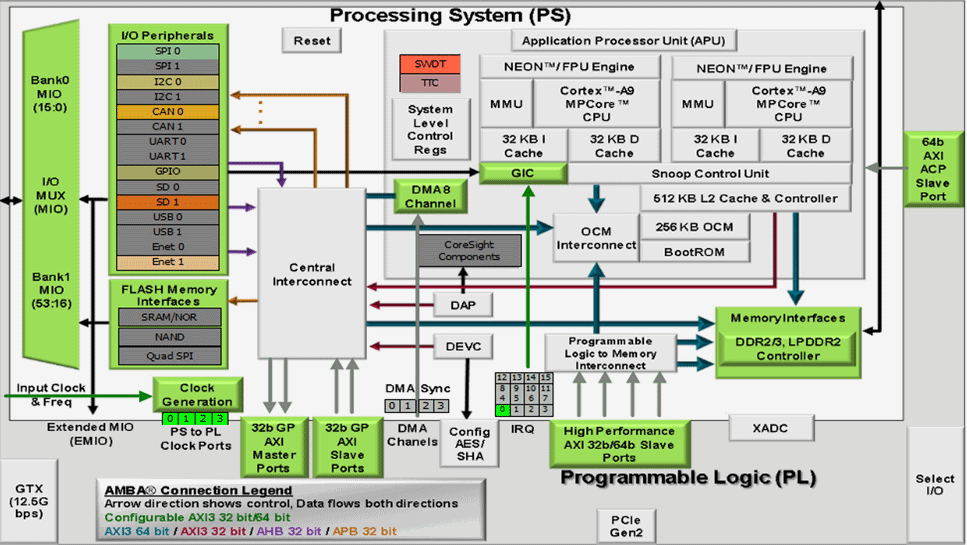
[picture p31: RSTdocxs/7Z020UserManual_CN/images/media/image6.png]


图2-2-1 ZYNQ7000芯片的总体框图

其中PS系统部分的主要参数如下：

-  基于ARM 双核CortexA9 的应用处理器，ARM-v7架构 高达1GHz

-  每个CPU 32KB 1级指令和数据缓存，512KB 2级缓存 2个CPU共享

-  片上boot ROM和256KB 片内RAM

-  外部存储接口，支持16/32 bit DDR2、DDR3接口

-  两个千兆网卡支持：发散-聚集DMA ，GMII，RGMII，SGMII接口

-  两个USB2.0 OTG接口，每个最多支持12节点

-  两个CAN2.0B总线接口

-  两个SD卡、SDIO、MMC兼容控制器

-  2个SPI，2个UARTs，2个I2C接口

-  4组32bit GPIO，54（32+22）作为PS系统IO，64连接到PL

-  PS内和PS到PL的高带宽连接

其中PL逻辑部分的主要参数如下：

-  逻辑单元Logic Cells：85K；

-  查找表LUTs: 53,200

-  触发器(flip-flops):106,400

-  乘法器18x25MACCs：220;

-  Block RAM：4.9Mb；

-  两个AD转换器,可以测量片上电压、温度感应和高达17外部差分输入通道，1MBPS

XC7Z020-2CLG400I芯片的速度等级为-2，工业级，封装为BGA400，引脚间距为0.8mm，ZYNQ7000系列的具体的芯片型号定义如下图2-2-2所示。

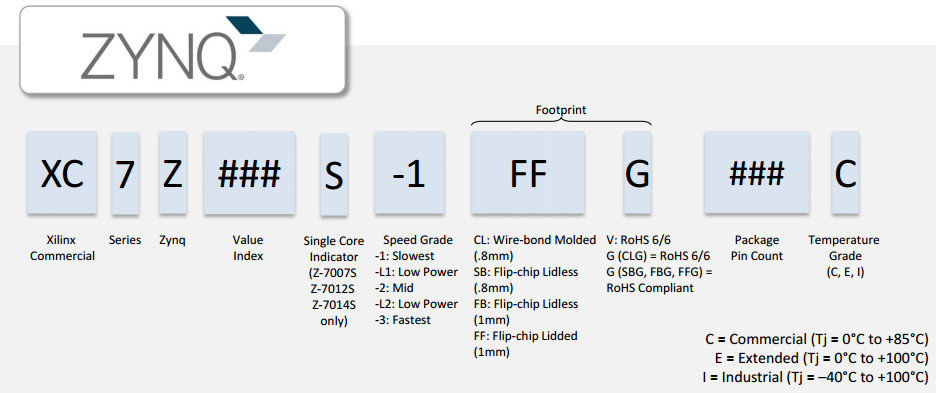
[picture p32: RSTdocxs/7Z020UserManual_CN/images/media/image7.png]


图2-2-2 ZYNQ型号命名规则定义

图2-2-3为开发板所用的XC7Z020芯片实物图。

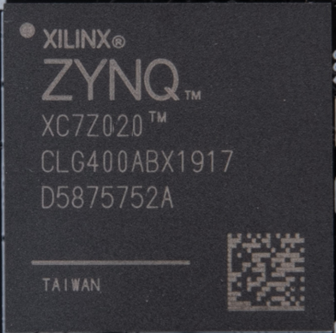
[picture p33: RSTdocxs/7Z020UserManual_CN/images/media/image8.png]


图2-2-3 XC7Z020芯片实物

DDR3 DRAM
---------

AC7Z020核心板上配有两片Micron公司的DDR3
SDRAM芯片(共计1GB),型号为MT41K256M16TW-107(兼容海力士的H5TQ4G63AFR-PBI）。DDR3
SDRAM的总线宽度共为32bit。DDR3
SDRAM的最高运行速度可达533MHz(数据速率1066Mbps)。该DDR3存储系统直接连接到了ZYNQ处理系统（PS）的BANK
502的存储器接口上。DDR3 SDRAM的具体配置如下表2-3-1所示。

表5-1 DDR3 SDRAM配置

+-------------+----------------------+-----------------+-------------+
| **位号**    | **芯片型号**         | **容量**        | **厂家**    |
+-------------+----------------------+-----------------+-------------+
| U8,U9       | MT41K256M16TW-107    | 256M x 16bit    | Micron      |
+-------------+----------------------+-----------------+-------------+

DDR3的硬件设计需要严格考虑信号完整性，我们在电路设计和PCB设计的时候已经充分考虑了匹配电阻/终端电阻,走线阻抗控制，走线等长控制，　保证DDR3的高速稳定的工作。

DDR3 DRAM的硬件连接方式如图2-3-1所示:

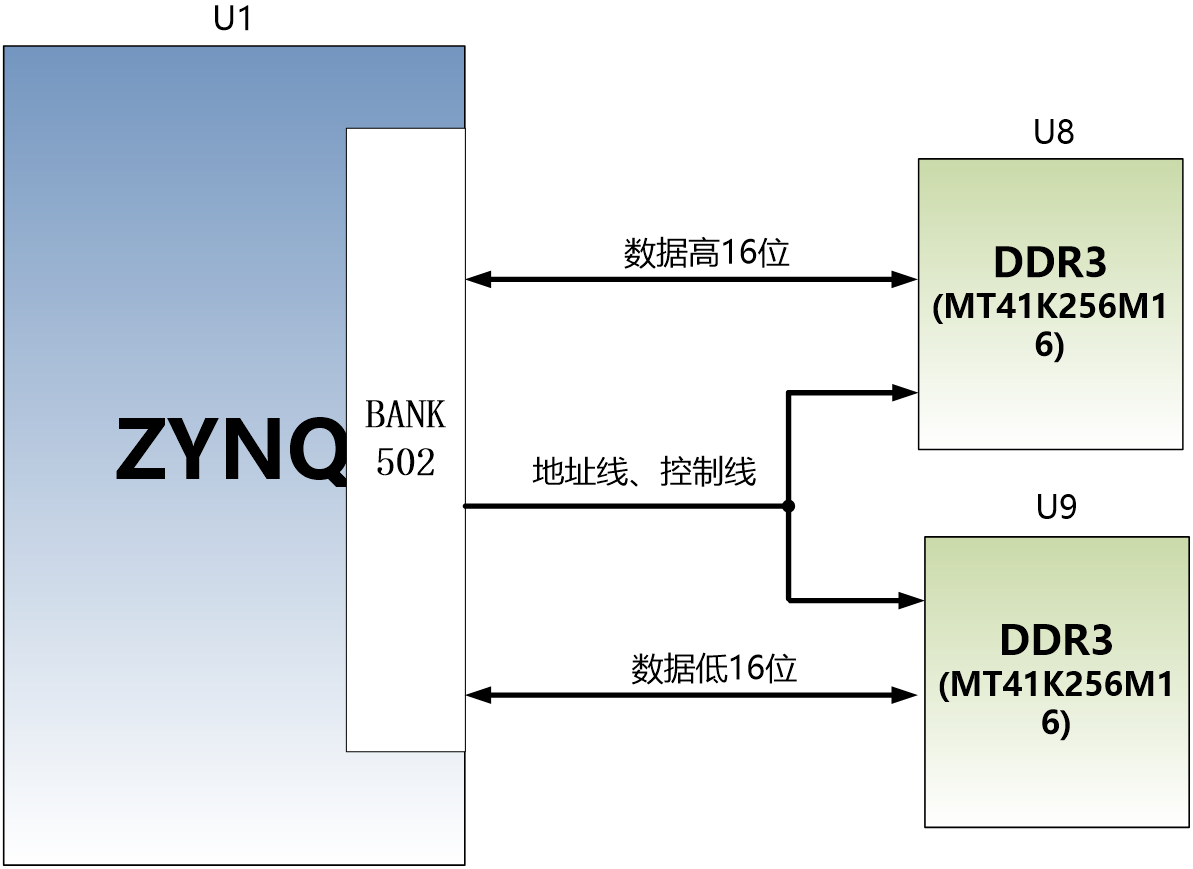
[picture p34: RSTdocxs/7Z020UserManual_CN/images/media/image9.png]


图2-3-1 DDR3 DRAM原理图部分

图2-3-2为DDR3 DRAM实物图

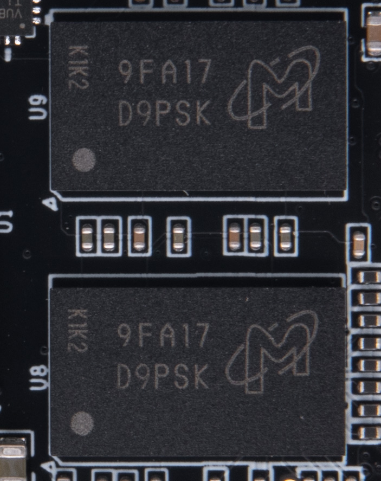
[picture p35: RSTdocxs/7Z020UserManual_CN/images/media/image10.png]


图2-3-2 DDR3 DRAM实物图

**DDR3 DRAM引脚分配：**

+-----------------------+---------------------+------------------------+
| **信号名称**          | **ZYNQ引脚名**      | **ZYNQ引脚号**         |
+-----------------------+---------------------+------------------------+
| **DDR3_DQS0_P**       | PS_DDR_DQS_P0_502   | C2                     |
+-----------------------+---------------------+------------------------+
| **DDR3_DQS0_N**       | PS_DDR_DQS_N0_502   | B2                     |
+-----------------------+---------------------+------------------------+
| **DDR3_DQS1_P**       | PS_DDR_DQS_P1_502   | G2                     |
+-----------------------+---------------------+------------------------+
| **DDR3_DQS1_N**       | PS_DDR_DQS_N1_502   | F2                     |
+-----------------------+---------------------+------------------------+
| **DDR3_DQS2_P**       | PS_DDR_DQS_P2_502   | R2                     |
+-----------------------+---------------------+------------------------+
| **DDR3_DQS2_N**       | PS_DDR_DQS_N2_502   | T2                     |
+-----------------------+---------------------+------------------------+
| **DDR3_DQS3_P**       | PS_DDR_DQS_P3_502   | W5                     |
+-----------------------+---------------------+------------------------+
| **DDR3_DQS4_N**       | PS_DDR_DQS_N3_502   | W4                     |
+-----------------------+---------------------+------------------------+
| **DDR3_D0**           | PS_DDR_DQ0_502      | C3                     |
+-----------------------+---------------------+------------------------+
| **DDR3_D1**           | PS_DDR_DQ1_502      | B3                     |
+-----------------------+---------------------+------------------------+
| **DDR3_D2**           | PS_DDR_DQ2_502      | A2                     |
+-----------------------+---------------------+------------------------+
| **DDR3_D3**           | PS_DDR_DQ3_502      | A4                     |
+-----------------------+---------------------+------------------------+
| **DDR3_D4**           | PS_DDR_DQ4_502      | D3                     |
+-----------------------+---------------------+------------------------+
| **DDR3_D5**           | PS_DDR_DQ5_502      | D1                     |
+-----------------------+---------------------+------------------------+
| **DDR3_D6**           | PS_DDR_DQ6_502      | C1                     |
+-----------------------+---------------------+------------------------+
| **DDR3_D7**           | PS_DDR_DQ7_502      | E1                     |
+-----------------------+---------------------+------------------------+
| **DDR3_D8**           | PS_DDR_DQ8_502      | E2                     |
+-----------------------+---------------------+------------------------+
| **DDR3_D9**           | PS_DDR_DQ9_502      | E3                     |
+-----------------------+---------------------+------------------------+
| **DDR3_D10**          | PS_DDR_DQ10_502     | G3                     |
+-----------------------+---------------------+------------------------+
| **DDR3_D11**          | PS_DDR_DQ11_502     | H3                     |
+-----------------------+---------------------+------------------------+
| **DDR3_D12**          | PS_DDR_DQ12_502     | J3                     |
+-----------------------+---------------------+------------------------+
| **DDR3_D13**          | PS_DDR_DQ13_502     | H2                     |
+-----------------------+---------------------+------------------------+
| **DDR3_D14**          | PS_DDR_DQ14_502     | H1                     |
+-----------------------+---------------------+------------------------+
| **DDR3_D15**          | PS_DDR_DQ15_502     | J1                     |
+-----------------------+---------------------+------------------------+
| **DDR3_D16**          | PS_DDR_DQ16_502     | P1                     |
+-----------------------+---------------------+------------------------+
| **DDR3_D17**          | PS_DDR_DQ17_502     | P3                     |
+-----------------------+---------------------+------------------------+
| **DDR3_D18**          | PS_DDR_DQ18_502     | R3                     |
+-----------------------+---------------------+------------------------+
| **DDR3_D19**          | PS_DDR_DQ19_502     | R1                     |
+-----------------------+---------------------+------------------------+
| **DDR3_D20**          | PS_DDR_DQ20_502     | T4                     |
+-----------------------+---------------------+------------------------+
| **DDR3_D21**          | PS_DDR_DQ21_502     | U4                     |
+-----------------------+---------------------+------------------------+
| **DDR3_D22**          | PS_DDR_DQ22_502     | U2                     |
+-----------------------+---------------------+------------------------+
| **DDR3_D23**          | PS_DDR_DQ23_502     | U3                     |
+-----------------------+---------------------+------------------------+
| **DDR3_D24**          | PS_DDR_DQ24_502     | V1                     |
+-----------------------+---------------------+------------------------+
| **DDR3_D25**          | PS_DDR_DQ25_502     | Y3                     |
+-----------------------+---------------------+------------------------+
| **DDR3_D26**          | PS_DDR_DQ26_502     | W1                     |
+-----------------------+---------------------+------------------------+
| **DDR3_D27**          | PS_DDR_DQ27_502     | Y4                     |
+-----------------------+---------------------+------------------------+
| **DDR3_D28**          | PS_DDR_DQ28_502     | Y2                     |
+-----------------------+---------------------+------------------------+
| **DDR3_D29**          | PS_DDR_DQ29_502     | W3                     |
+-----------------------+---------------------+------------------------+
| **DDR3_D30**          | PS_DDR_DQ30_502     | V2                     |
+-----------------------+---------------------+------------------------+
| **DDR3_D31**          | PS_DDR_DQ31_502     | V3                     |
+-----------------------+---------------------+------------------------+
| **DDR3_DM0**          | PS_DDR_DM0_502      | A1                     |
+-----------------------+---------------------+------------------------+
| **DDR3_DM1**          | PS_DDR_DM1_502      | F1                     |
+-----------------------+---------------------+------------------------+
| **DDR3_DM2**          | PS_DDR_DM2_502      | T1                     |
+-----------------------+---------------------+------------------------+
| **DDR3_DM3**          | PS_DDR_DM3_502      | Y1                     |
+-----------------------+---------------------+------------------------+
| **DDR3_A0**           | PS_DDR_A0_502       | N2                     |
+-----------------------+---------------------+------------------------+
| **DDR3_A1**           | PS_DDR_A1_502       | K2                     |
+-----------------------+---------------------+------------------------+
| **DDR3_A2**           | PS_DDR_A2_502       | M3                     |
+-----------------------+---------------------+------------------------+
| **DDR3_A3**           | PS_DDR_A3_502       | K3                     |
+-----------------------+---------------------+------------------------+
| **DDR3_A4**           | PS_DDR_A4_502       | M4                     |
+-----------------------+---------------------+------------------------+
| **DDR3_A5**           | PS_DDR_A5_502       | L1                     |
+-----------------------+---------------------+------------------------+
| **DDR3_A6**           | PS_DDR_A6_502       | L4                     |
+-----------------------+---------------------+------------------------+
| **DDR3_A7**           | PS_DDR_A7_502       | K4                     |
+-----------------------+---------------------+------------------------+
| **DDR3_A8**           | PS_DDR_A8_502       | K1                     |
+-----------------------+---------------------+------------------------+
| **DDR3_A9**           | PS_DDR_A9_502       | J4                     |
+-----------------------+---------------------+------------------------+
| **DDR3_A10**          | PS_DDR_A10_502      | F5                     |
+-----------------------+---------------------+------------------------+
| **DDR3_A11**          | PS_DDR_A11_502      | G4                     |
+-----------------------+---------------------+------------------------+
| **DDR3_A12**          | PS_DDR_A12_502      | E4                     |
+-----------------------+---------------------+------------------------+
| **DDR3_A13**          | PS_DDR_A13_502      | D4                     |
+-----------------------+---------------------+------------------------+
| **DDR3_A14**          | PS_DDR_A14_502      | F4                     |
+-----------------------+---------------------+------------------------+
| **DDR3_BA0**          | PS_DDR_BA0_502      | L5                     |
+-----------------------+---------------------+------------------------+
| **DDR3_BA1**          | PS_DDR_BA1_502      | R4                     |
+-----------------------+---------------------+------------------------+
| **DDR3_BA2**          | PS_DDR_BA2_502      | J5                     |
+-----------------------+---------------------+------------------------+
| **DDR3_S0**           | PS_DDR_CS_B_502     | N1                     |
+-----------------------+---------------------+------------------------+
| **DDR3_RAS**          | PS_DDR_RAS_B_502    | P4                     |
+-----------------------+---------------------+------------------------+
| **DDR3_CAS**          | PS_DDR_CAS_B_502    | P5                     |
+-----------------------+---------------------+------------------------+
| **DDR3_WE**           | PS_DDR_WE_B_502     | M5                     |
+-----------------------+---------------------+------------------------+
| **DDR3_ODT**          | PS_DDR_ODT_502      | N5                     |
+-----------------------+---------------------+------------------------+
| **DDR3_RESET**        | PS_DDR_DRST_B_502   | B4                     |
+-----------------------+---------------------+------------------------+
| **DDR3_CLK0_P**       | PS_DDR_CKP_502      | L2                     |
+-----------------------+---------------------+------------------------+
| **DDR3_CLK0_N**       | PS_DDR_CKN_502      | M2                     |
+-----------------------+---------------------+------------------------+
| **DDR3_CKE**          | PS_DDR_CKE_502      | N3                     |
+-----------------------+---------------------+------------------------+

QSPI Flash
----------

核心板配有一片256MBit大小的Quad-SPI
FLASH芯片，型号为W25Q256FVEI，它使用3.3V CMOS电压标准。由于QSPI
FLASH的非易失特性，在使用中，
它可以作为系统的启动设备来存储系统的启动镜像。这些镜像主要包括FPGA的bit文件、ARM的应用程序代码以及其它的用户数据文件。QSPI
FLASH的具体型号和相关参数见表2-4-1。

+--------------+--------------------+------------------+--------------+
| **位号**     | **芯片类型**       | **容量**         | **厂家**     |
+--------------+--------------------+------------------+--------------+
| U15          | W25Q256FVEI        | 32M Byte         | Winbond      |
+--------------+--------------------+------------------+--------------+

表2-4-1 QSPI Flash的型号和参数

QSPI
FLASH连接到ZYNQ芯片的PS部分BANK500的GPIO口上，在系统设计中需要配置这些PS端的GPIO口功能为QSPI
FLASH接口。为图2-4-1为QSPI Flash在原理图中的部分。

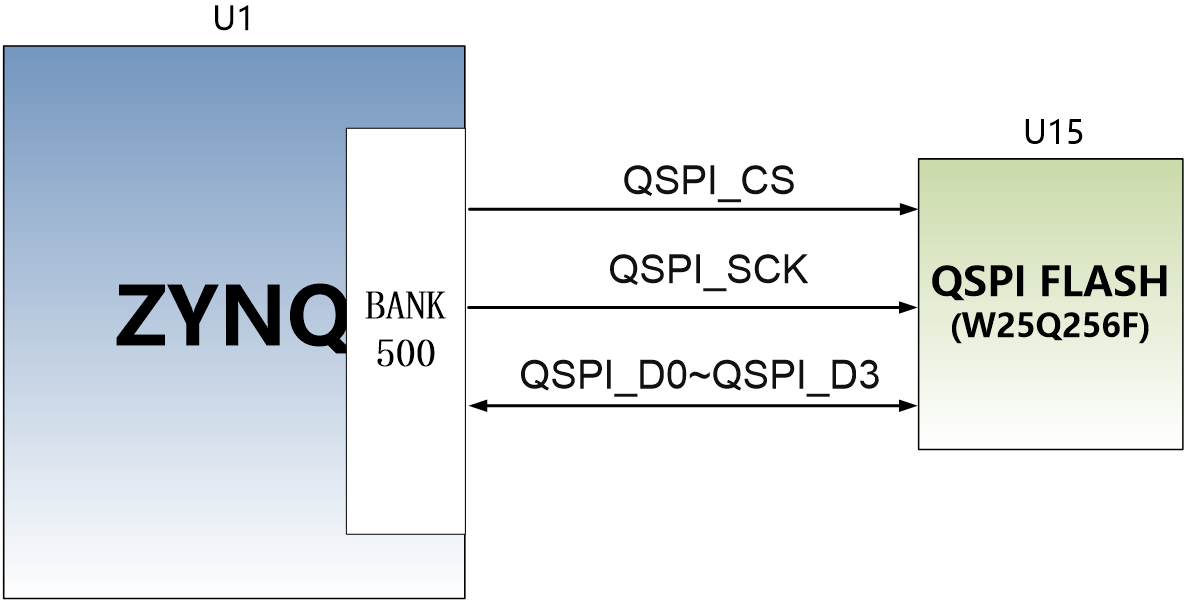
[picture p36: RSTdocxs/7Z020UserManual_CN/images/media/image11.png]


图2-4-1 QSPI Flash连接示意图

图2-4-2为QSPI Flash的实物图

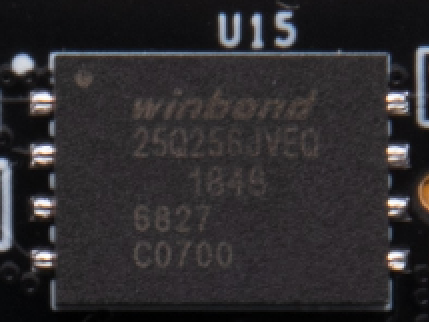
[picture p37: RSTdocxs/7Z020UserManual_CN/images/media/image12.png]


2-4-2为QSPI Flash的实物图

**配置芯片引脚分配：**

+-----------------------------+------------------+---------------------+
| **信号名称**                | **ZYNQ引脚名**   | **ZYNQ引脚号**      |
+-----------------------------+------------------+---------------------+
| **QSPI_SCK**                | PS_MIO6_500      | A5                  |
+-----------------------------+------------------+---------------------+
| **QSPI_CS**                 | PS_MIO1_500      | A7                  |
+-----------------------------+------------------+---------------------+
| **QSPI_D0**                 | PS_MIO2_500      | B8                  |
+-----------------------------+------------------+---------------------+
| **QSPI_D1**                 | PS_MIO3_500      | D6                  |
+-----------------------------+------------------+---------------------+
| **QSPI_D2**                 | PS_MIO4_500      | B7                  |
+-----------------------------+------------------+---------------------+
| **QSPI_D3**                 | PS_MIO5_500      | A6                  |
+-----------------------------+------------------+---------------------+

时钟配置
--------

AC7Z020核心板上为PS系统提供了有源时钟，使PS系统可以单独工作。PL的时钟由底板提供。

**PS系统时钟源**

ZYNQ芯片通过核心板上的X1晶振为PS部分提供33.333333MHz的时钟输入。时钟的输入连接到ZYNQ芯片的BANK500的PS_CLK_500的管脚上。其原理图如图2-5-1所示：

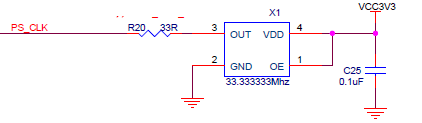
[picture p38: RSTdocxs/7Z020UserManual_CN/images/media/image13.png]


图2-5-1 PS部分的有源晶振

图2-5-2为PS端有源晶振实物图

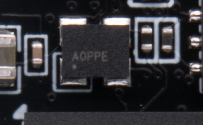
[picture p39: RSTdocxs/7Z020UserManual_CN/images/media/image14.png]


图2-5-2 33.333333Mhz有源晶振实物图

**时钟引脚分配：**

+-----------------------------------+-----------------------------------+
| **信号名称**                      | ZYNQ引脚                          |
+-----------------------------------+-----------------------------------+
| **PS_CLK_500**                    | E7                                |
+-----------------------------------+-----------------------------------+

**PL时钟源**

PL的时钟需要通过底板提供，在AX7Z010底板上有一个50Mhz的时钟，为PL部分提供时钟参考。时钟的输入连接到ZYNQ芯片的BANK34的U18的管脚上。其原理图如图2-5-3所示：

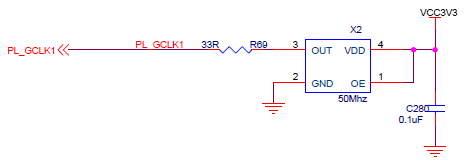
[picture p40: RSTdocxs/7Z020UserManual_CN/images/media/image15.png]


图2-5-3 底板PL部分的晶振

**时钟引脚分配：**

+-----------------------------------+-----------------------------------+
| **信号名称**                      | ZYNQ引脚                          |
+-----------------------------------+-----------------------------------+
| **PL_GCLK1**                      | U18                               |
+-----------------------------------+-----------------------------------+

电源
----

AC7Z020核心板供电电压为DC5V，通过连接底板供电，另外BANK34和BANK35的电源也是通过底板提供。板上的电源设计示意图如下图2-6-1所示:

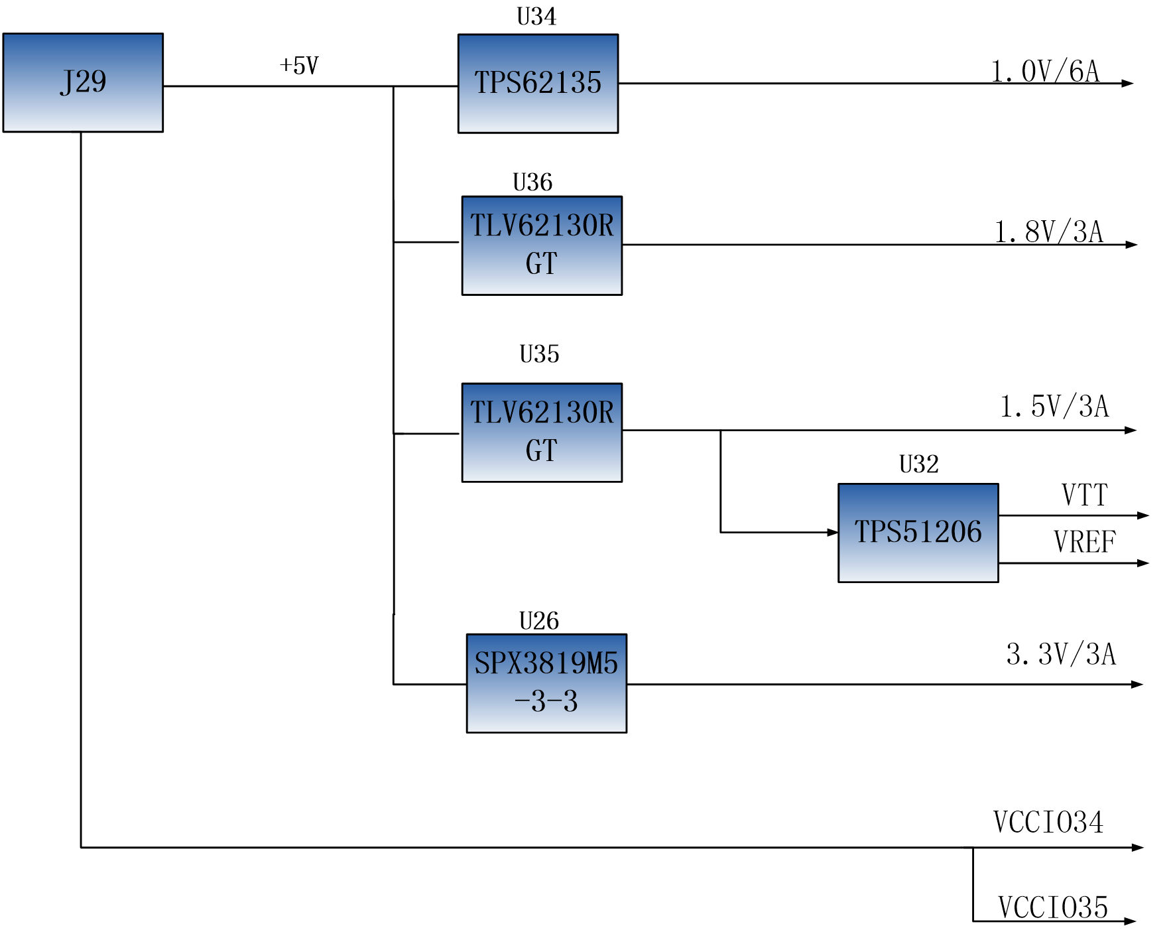
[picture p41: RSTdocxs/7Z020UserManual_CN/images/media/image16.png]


图2-6-1原理图中电源接口部分

开发板通过+5V供电,
通过四路DC/DC电源芯片转化成+1.0V，+1.8V，+1.5V，+3.3V四路电源，+1.0V输出电流可高达6A，
+1.8V和+1.5V电源为3A，+3.3V为500mA
。J29上还各分出4个引脚给FPGA的BANK34，BANK35供电，默认为3.3V，用户可以通过更改底板上的VCCIO34和VCCIO35来改变BANK34和BANK35的电源。1.5V通过TI的TPS51206生成DDR3需要的VTT和VREF电压。各个电源分配的功能如下表所示：

+----------------------+-----------------------------------------------+
| **电源**             | **功能**                                      |
+----------------------+-----------------------------------------------+
| +1.0V                | ZYNQ PS和PL部分的内核电压                     |
+----------------------+-----------------------------------------------+
| +1.8V                | ZYNQ PS和PL部分辅助电压，BANK501 IO电压       |
+----------------------+-----------------------------------------------+
| +3.3V                | ZYNQ Bank0,Bank500，Bank13的VCCIO, QSIP       |
|                      | FLASH, Clock晶振                              |
+----------------------+-----------------------------------------------+
| +1.5V                | DDR3, ZYNQ Bank501                            |
+----------------------+-----------------------------------------------+
| VREF, VTT（+0.75V）  | DDR3                                          |
+----------------------+-----------------------------------------------+
| VCCIO34/35           | Bank34, Bank35                                |
+----------------------+-----------------------------------------------+

因为ZYNQ FPGA的电源有上电顺序的要求，在电路设计中，我们已经按照
芯片的电源要求设计，上电依次为+1.0V->+1.8V->（+1.5
V、+3.3V、VCCIO）的电路设计，保证芯片的正常工作。\ **因为BANK34，BANK35的电平标准由底板提供的电源决定，最高为3.3V，用户自己设计底板为核心板提供VCCIO34和VCCIO35的电源时，上电的顺序要比+5V慢一些。**

结构图
------

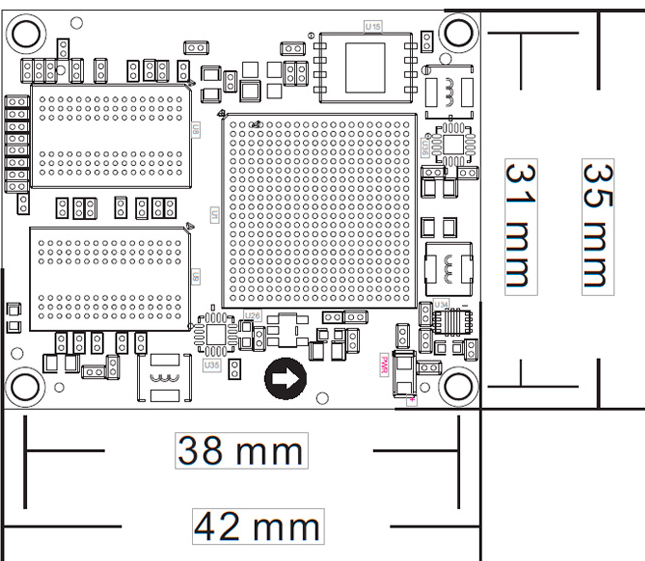
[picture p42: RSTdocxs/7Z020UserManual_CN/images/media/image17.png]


正面图（Top View）

连接器管脚定义
--------------

核心板一共扩展出2个高速扩展口，使用2个120Pin的板间连接器（J29/J30）和底板连接，连接器的PIN脚间距为0.5mm。其中J29连接5V电源，VCCIO电源输入，一部分IO信号和JTAG信号，J30连接剩余的IO信号和MIO。
BANK34和BANK35的IO电平可以通过调整连接器上VCCIO输入来改变电平标准，最高不超过3.3V。我们设计的底板AX7Z020默认为3.3V。

**J29连接器的引脚分配**

+----------+----------+----------+----------+-------------+----------+
| **J      | **信     | **ZYNQ   | **J      | **信号      | **ZYNQ   |
| 29管脚** | 号名称** | 引脚号** | 29管脚** | 名称**      | 引脚号** |
+----------+----------+----------+----------+-------------+----------+
| 1        | VCC5V    | -        | 2        | VCC5V       | -        |
+----------+----------+----------+----------+-------------+----------+
| 3        | VCC5V    | -        | 4        | VCC5V       | -        |
+----------+----------+----------+----------+-------------+----------+
| 5        | VCC5V    | -        | 6        | VCC5V       | -        |
+----------+----------+----------+----------+-------------+----------+
| 7        | VCC5V    | -        | 8        | VCC5V       | -        |
+----------+----------+----------+----------+-------------+----------+
| 9        | GND      | -        | 10       | GND         | -        |
+----------+----------+----------+----------+-------------+----------+
| 11       | VCCIO_34 | -        | 12       | VCCIO_35    | -        |
+----------+----------+----------+----------+-------------+----------+
| 13       | VCCIO_34 | -        | 14       | VCCIO_35    | -        |
+----------+----------+----------+----------+-------------+----------+
| 15       | VCCIO_34 | -        | 16       | VCCIO_35    | -        |
+----------+----------+----------+----------+-------------+----------+
| 17       | VCCIO_34 | -        | 18       | VCCIO_35    | -        |
+----------+----------+----------+----------+-------------+----------+
| 19       | GND      | -        | 20       | GND         | -        |
+----------+----------+----------+----------+-------------+----------+
| 21       | I        | V15      | 22       | IO34_L7P    | Y16      |
|          | O34_L10P |          |          |             |          |
+----------+----------+----------+----------+-------------+----------+
| 23       | I        | W15      | 24       | IO34_L7N    | Y17      |
|          | O34_L10N |          |          |             |          |
+----------+----------+----------+----------+-------------+----------+
| 25       | I        | U20      | 26       | IO34_L17P   | Y18      |
|          | O34_L15N |          |          |             |          |
+----------+----------+----------+----------+-------------+----------+
| 27       | I        | T20      | 28       | IO34_L17N   | Y19      |
|          | O34_L15P |          |          |             |          |
+----------+----------+----------+----------+-------------+----------+
| 29       | GND      | -        | 30       | GND         | -        |
+----------+----------+----------+----------+-------------+----------+
| 31       | IO34_L9N | U17      | 32       | IO34_L8P    | W14      |
+----------+----------+----------+----------+-------------+----------+
| 33       | IO34_L9P | T16      | 34       | IO34_L8N    | Y14      |
+----------+----------+----------+----------+-------------+----------+
| 35       | I        | U19      | 36       | IO34_L3P    | U13      |
|          | O34_L12N |          |          |             |          |
+----------+----------+----------+----------+-------------+----------+
| 37       | I        | U18      | 38       | IO34_L3N    | V13      |
|          | O34_L12P |          |          |             |          |
+----------+----------+----------+----------+-------------+----------+
| 39       | GND      | -        | 40       | GND         | -        |
+----------+----------+----------+----------+-------------+----------+
| 41       | I        | P20      | 42       | IO34_L21N   | V18      |
|          | O34_L14N |          |          |             |          |
+----------+----------+----------+----------+-------------+----------+
| 43       | I        | N20      | 44       | IO34_L21P   | V17      |
|          | O34_L14P |          |          |             |          |
+----------+----------+----------+----------+-------------+----------+
| 45       | I        | W20      | 46       | IO34_L18P   | V16      |
|          | O34_L16N |          |          |             |          |
+----------+----------+----------+----------+-------------+----------+
| 47       | I        | V20      | 48       | IO34_L18N   | W16      |
|          | O34_L16P |          |          |             |          |
+----------+----------+----------+----------+-------------+----------+
| 49       | GND      | -        | 50       | GND         | -        |
+----------+----------+----------+----------+-------------+----------+
| 51       | I        | W19      | 52       | IO34_L23P   | N17      |
|          | O34_L22N |          |          |             |          |
+----------+----------+----------+----------+-------------+----------+
| 53       | I        | W18      | 54       | IO34_L23N   | P18      |
|          | O34_L22P |          |          |             |          |
+----------+----------+----------+----------+-------------+----------+
| 55       | I        | R18      | 56       | IO34_L13N   | P19      |
|          | O34_L20N |          |          |             |          |
+----------+----------+----------+----------+-------------+----------+
| 57       | I        | T17      | 58       | IO34_L13P   | N18      |
|          | O34_L20P |          |          |             |          |
+----------+----------+----------+----------+-------------+----------+
| 59       | GND      | -        | 60       | GND         | -        |
+----------+----------+----------+----------+-------------+----------+
| 61       | I        | R17      | 62       | IO34_L11N   | U15      |
|          | O34_L19N |          |          |             |          |
+----------+----------+----------+----------+-------------+----------+
| 63       | I        | R16      | 64       | IO34_L11P   | U14      |
|          | O34_L19P |          |          |             |          |
+----------+----------+----------+----------+-------------+----------+
| 65       | I        | P15      | 66       | IO34_L5N    | T15      |
|          | O34_L24P |          |          |             |          |
+----------+----------+----------+----------+-------------+----------+
| 67       | I        | P16      | 68       | IO34_L5P    | T14      |
|          | O34_L24N |          |          |             |          |
+----------+----------+----------+----------+-------------+----------+
| 69       | GND      | -        | 70       | GND         | -        |
+----------+----------+----------+----------+-------------+----------+
| 71       | IO34_L4P | V12      | 72       | IO34_L2N    | U12      |
+----------+----------+----------+----------+-------------+----------+
| 73       | IO34_L4N | W13      | 74       | IO34_L2P    | T12      |
+----------+----------+----------+----------+-------------+----------+
| 75       | IO34_L1P | T11      | 76       | IO34_L6N    | R14      |
+----------+----------+----------+----------+-------------+----------+
| 77       | IO34_L1N | T10      | 78       | IO34_L6P    | P14      |
+----------+----------+----------+----------+-------------+----------+
| 79       | GND      | -        | 80       | GND         | -        |
+----------+----------+----------+----------+-------------+----------+
| 81       | I        | Y7       | 82       | IO13_L21P   | V11      |
|          | O13_L13P |          |          |             |          |
+----------+----------+----------+----------+-------------+----------+
| 83       | I        | Y6       | 84       | IO13_L21N   | V10      |
|          | O13_L13N |          |          |             |          |
+----------+----------+----------+----------+-------------+----------+
| 85       | I        | V7       | 86       | IO13_L14N   | Y8       |
|          | O13_L11N |          |          |             |          |
+----------+----------+----------+----------+-------------+----------+
| 87       | I        | U7       | 88       | IO13_L14P   | Y9       |
|          | O13_L11P |          |          |             |          |
+----------+----------+----------+----------+-------------+----------+
| 89       | GND      | -        | 90       | GND         | -        |
+----------+----------+----------+----------+-------------+----------+
| 91       | I        | U5       | 92       | IO13_L22N   | W6       |
|          | O13_L19N |          |          |             |          |
+----------+----------+----------+----------+-------------+----------+
| 93       | I        | T5       | 94       | IO13_L22P   | V6       |
|          | O13_L19P |          |          |             |          |
+----------+----------+----------+----------+-------------+----------+
| 95       | I        | W10      | 96       | IO13_L15P   | V8       |
|          | O13_L16P |          |          |             |          |
+----------+----------+----------+----------+-------------+----------+
| 97       | I        | W9       | 98       | IO13_L15N   | W8       |
|          | O13_L16N |          |          |             |          |
+----------+----------+----------+----------+-------------+----------+
| 99       | GND      | -        | 100      | GND         | -        |
+----------+----------+----------+----------+-------------+----------+
| 101      | I        | U9       | 102      | IO13_L20P   | Y12      |
|          | O13_L17P |          |          |             |          |
+----------+----------+----------+----------+-------------+----------+
| 103      | I        | U8       | 104      | IO13_L20N   | Y13      |
|          | O13_L17N |          |          |             |          |
+----------+----------+----------+----------+-------------+----------+
| 105      | I        | W11      | 106      | IO13_L12N   | U10      |
|          | O13_L18P |          |          |             |          |
+----------+----------+----------+----------+-------------+----------+
| 107      | I        | Y11      | 108      | IO13_L12P   | T9       |
|          | O13_L18N |          |          |             |          |
+----------+----------+----------+----------+-------------+----------+
| 109      | GND      | -        | 110      | GND         | -        |
+----------+----------+----------+----------+-------------+----------+
| 111      | FPGA_TCK | F9       | 112      | VP          | K9       |
+----------+----------+----------+----------+-------------+----------+
| 113      | FPGA_TMS | J6       | 114      | VN          | L10      |
+----------+----------+----------+----------+-------------+----------+
| 115      | FPGA_TDO | F6       | 116      | PS_POR_B    | C7       |
+----------+----------+----------+----------+-------------+----------+
| 117      | FPGA_TDI | G6       | 118      | FPGA_DONE   | R11      |
+----------+----------+----------+----------+-------------+----------+
| 119      | NC       | -        | 120      | NC          | -        |
+----------+----------+----------+----------+-------------+----------+

**J30连接器的引脚分配**

+--------+---------------+--------+--------+---------------+---------+
| **J30  | **信号名称**  | **ZY   | **J30  | **信号名称**  | **ZYN   |
| 管脚** |               | NQ引   | 管脚** |               | Q引     |
|        |               | 脚号** |        |               | 脚号**  |
+--------+---------------+--------+--------+---------------+---------+
| 1      | IO35_L1P      | C20    | 2      | IO35_L15N     | F20     |
+--------+---------------+--------+--------+---------------+---------+
| 3      | IO35_L1N      | B20    | 4      | IO35_L15P     | F19     |
+--------+---------------+--------+--------+---------------+---------+
| 5      | IO35_L18N     | G20    | 6      | IO35_L5P      | E18     |
+--------+---------------+--------+--------+---------------+---------+
| 7      | IO35_L18P     | G19    | 8      | IO35_L5N      | E19     |
+--------+---------------+--------+--------+---------------+---------+
| 9      | GND           | T13    | 10     | GND           | T13     |
+--------+---------------+--------+--------+---------------+---------+
| 11     | IO35_L10N     | J19    | 12     | IO35_L3N      | D18     |
+--------+---------------+--------+--------+---------------+---------+
| 13     | IO35_L10P     | K19    | 14     | IO35_L3P      | E17     |
+--------+---------------+--------+--------+---------------+---------+
| 15     | IO35_L2N      | A20    | 16     | IO35_L4P      | D19     |
+--------+---------------+--------+--------+---------------+---------+
| 17     | IO35_L2P      | B19    | 18     | IO35_L4N      | D20     |
+--------+---------------+--------+--------+---------------+---------+
| 19     | GND           | T13    | 20     | GND           | T13     |
+--------+---------------+--------+--------+---------------+---------+
| 21     | IO35_L8P      | M17    | 22     | IO35_L9N      | L20     |
+--------+---------------+--------+--------+---------------+---------+
| 23     | IO35_L8N      | M18    | 24     | IO35_L9P      | L19     |
+--------+---------------+--------+--------+---------------+---------+
| 25     | IO35_L7P      | M19    | 26     | IO35_L6P      | F16     |
+--------+---------------+--------+--------+---------------+---------+
| 27     | IO35_L7N      | M20    | 28     | IO35_L6N      | F17     |
+--------+---------------+--------+--------+---------------+---------+
| 29     | GND           | T13    | 30     | GND           | T13     |
+--------+---------------+--------+--------+---------------+---------+
| 31     | IO35_L17N     | H20    | 32     | IO35_L16N     | G18     |
+--------+---------------+--------+--------+---------------+---------+
| 33     | IO35_L17P     | J20    | 34     | IO35_L16P     | G17     |
+--------+---------------+--------+--------+---------------+---------+
| 35     | IO35_L19N     | G15    | 36     | IO35_L13N     | H17     |
+--------+---------------+--------+--------+---------------+---------+
| 37     | IO35_L19P     | H15    | 38     | IO35_L13P     | H16     |
+--------+---------------+--------+--------+---------------+---------+
| 39     | GND           | T13    | 40     | GND           | T13     |
+--------+---------------+--------+--------+---------------+---------+
| 41     | IO35_L12N     | K18    | 42     | IO35_L14N     | H18     |
+--------+---------------+--------+--------+---------------+---------+
| 43     | IO35_L12P     | K17    | 44     | IO35_L14P     | J18     |
+--------+---------------+--------+--------+---------------+---------+
| 45     | IO35_L24N     | J16    | 46     | IO35_L20P     | K14     |
+--------+---------------+--------+--------+---------------+---------+
| 47     | IO35_L24P     | K16    | 48     | IO35_L20N     | J14     |
+--------+---------------+--------+--------+---------------+---------+
| 49     | GND           | T13    | 50     | GND           | T13     |
+--------+---------------+--------+--------+---------------+---------+
| 51     | IO35_L21N     | N16    | 52     | IO35_L11P     | L16     |
+--------+---------------+--------+--------+---------------+---------+
| 53     | IO35_L21P     | N15    | 54     | IO35_L11N     | L17     |
+--------+---------------+--------+--------+---------------+---------+
| 55     | IO35_L22N     | L15    | 56     | IO35_L23P     | M14     |
+--------+---------------+--------+--------+---------------+---------+
| 57     | IO35_L22P     | L14    | 58     | IO35_L23N     | M15     |
+--------+---------------+--------+--------+---------------+---------+
| 59     | GND           | T13    | 60     | GND           | T13     |
+--------+---------------+--------+--------+---------------+---------+
| 61     | PS_MIO22      | B17    | 62     | PS_MIO50      | B13     |
+--------+---------------+--------+--------+---------------+---------+
| 63     | PS_MIO27      | D13    | 64     | PS_MIO45      | B15     |
+--------+---------------+--------+--------+---------------+---------+
| 65     | PS_MIO23      | D11    | 66     | PS_MIO46      | D16     |
+--------+---------------+--------+--------+---------------+---------+
| 67     | PS_MIO24      | A16    | 68     | PS_MIO41      | C17     |
+--------+---------------+--------+--------+---------------+---------+
| 69     | GND           | T13    | 70     | GND           | T13     |
+--------+---------------+--------+--------+---------------+---------+
| 71     | PS_MIO25      | F15    | 72     | PS_MIO7       | D8      |
+--------+---------------+--------+--------+---------------+---------+
| 73     | PS_MIO26      | A15    | 74     | PS_MIO12      | D9      |
+--------+---------------+--------+--------+---------------+---------+
| 75     | PS_MIO21      | F14    | 76     | PS_MIO10      | E9      |
+--------+---------------+--------+--------+---------------+---------+
| 77     | PS_MIO16      | A19    | 78     | PS_MIO11      | C6      |
+--------+---------------+--------+--------+---------------+---------+
| 79     | GND           | T13    | 80     | GND           | T13     |
+--------+---------------+--------+--------+---------------+---------+
| 81     | PS_MIO20      | A17    | 82     | PS_MIO9       | B5      |
+--------+---------------+--------+--------+---------------+---------+
| 83     | PS_MIO19      | D10    | 84     | PS_MIO14      | C5      |
+--------+---------------+--------+--------+---------------+---------+
| 85     | PS_MIO18      | B18    | 86     | PS_MIO8       | D5      |
+--------+---------------+--------+--------+---------------+---------+
| 87     | PS_MIO17      | E14    | 88     | PS_MIO0       | E6      |
+--------+---------------+--------+--------+---------------+---------+
| 89     | GND           | T13    | 90     | GND           | T13     |
+--------+---------------+--------+--------+---------------+---------+
| 91     | PS_MIO39      | C18    | 92     | PS_MIO13      | E8      |
+--------+---------------+--------+--------+---------------+---------+
| 93     | PS_MIO38      | E13    | 94     | PS_MIO47      | B14     |
+--------+---------------+--------+--------+---------------+---------+
| 95     | PS_MIO37      | A10    | 96     | PS_MIO48      | B12     |
+--------+---------------+--------+--------+---------------+---------+
| 97     | PS_MIO28      | C16    | 98     | PS_MIO49      | C12     |
+--------+---------------+--------+--------+---------------+---------+
| 99     | GND           | T13    | 100    | GND           | T13     |
+--------+---------------+--------+--------+---------------+---------+
| 101    | PS_MIO35      | F12    | 102    | PS_MIO52      | C10     |
+--------+---------------+--------+--------+---------------+---------+
| 103    | PS_MIO34      | A12    | 104    | PS_MIO51      | B9      |
+--------+---------------+--------+--------+---------------+---------+
| 105    | PS_MIO33      | D15    | 106    | PS_MIO40      | D14     |
+--------+---------------+--------+--------+---------------+---------+
| 107    | PS_MIO32      | A14    | 108    | PS_MIO44      | F13     |
+--------+---------------+--------+--------+---------------+---------+
| 109    | GND           | T13    | 110    | GND           | T13     |
+--------+---------------+--------+--------+---------------+---------+
| 111    | PS_MIO31      | E16    | 112    | PS_MIO15      | C8      |
+--------+---------------+--------+--------+---------------+---------+
| 113    | PS_MIO36      | A11    | 114    | PS_MIO42      | E12     |
+--------+---------------+--------+--------+---------------+---------+
| 115    | PS_MIO29      | C13    | 116    | PS_MIO43      | A9      |
+--------+---------------+--------+--------+---------------+---------+
| 117    | PS_MIO30      | C15    | 118    | PS_MIO53      | C11     |
+--------+---------------+--------+--------+---------------+---------+
| 119    | QS            | A6     | 120    | QS            | B7      |
|        | PI_D3_PS_MIO5 |        |        | PI_D2_PS_MIO4 |         |
+--------+---------------+--------+--------+---------------+---------+

扩展板
======

.. _简介-1:

简介
----

通过前面的功能简介，我们可以了解到扩展板部分的功能

-  2路CAN通信接口

-  2路485通信接口

-  1路10/100M/1000M以太网RJ-45接口

-  1路USB HOST接口

-  1路USB Uart通信接口

-  1路SD卡接口

-  2路40针扩展口

-  2路AD输入接口

-  1路HDMI输出接口

-  1路MIPI摄像头接口

-  1路RTC实时时钟

-  1路EEPROM

-  1路温度传感器

-  JTAG调试口

-  4个独立按键

-  4个用户LED灯

CAN通信接口
-----------

AX7Z020底板上有2路CAN通信接口，连接在PS系统端BANK500的GPIO接口上。CAN收发芯片选用了TI公司的SN65HVD232C芯片为用户CAN通信服务。

图3-2-1为PS端CAN收发芯片的连接示意图

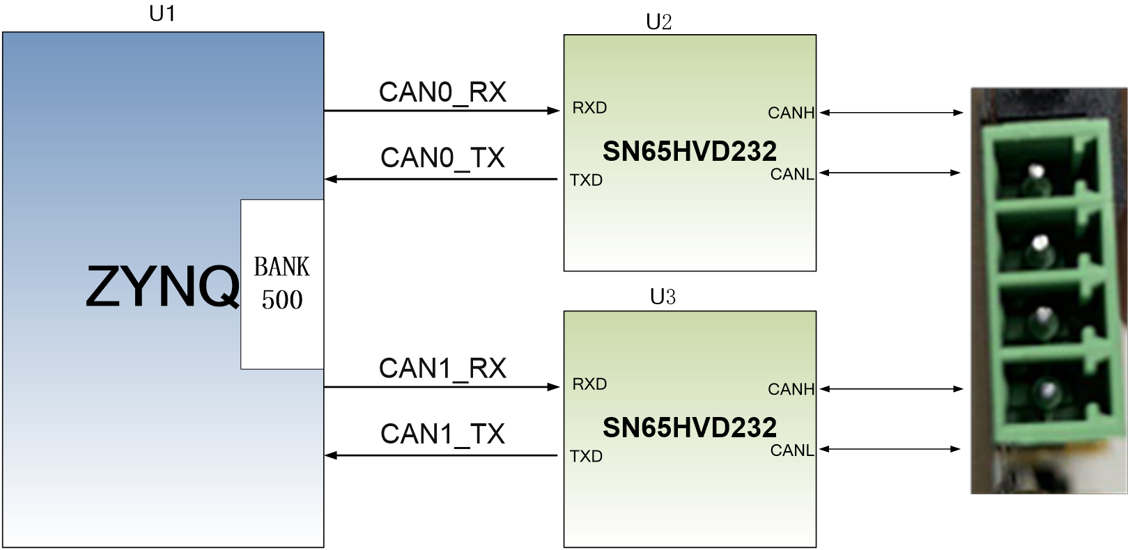
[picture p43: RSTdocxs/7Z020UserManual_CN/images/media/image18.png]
   

图3-2-1 PS端CAN收发芯片的连接示意图

图3-2-2为PS端CAN收发芯片的实物图

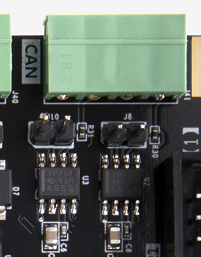
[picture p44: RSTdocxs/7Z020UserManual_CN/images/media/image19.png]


图3-2-2 PS端CAN芯片和接口的实物图

**CAN通信引脚分配如下：**

+-----------------+----------------+-----------------+-----------------+
| **信号名称**    | **ZYNQ引脚名** | **ZYNQ引脚号**  | **备注**        |
+-----------------+----------------+-----------------+-----------------+
| CAN0_RX         | PS_MIO10       | E9              | CAN0接收端      |
+-----------------+----------------+-----------------+-----------------+
| CAN0_TX         | PS_MIO11       | C6              | CAN0发送端      |
+-----------------+----------------+-----------------+-----------------+
| CAN1_RX         | PS_MIO13       | E8              | CAN1接收端      |
+-----------------+----------------+-----------------+-----------------+
| CAN1_TX         | PS_MIO12       | D9              | CAN1发送端      |
+-----------------+----------------+-----------------+-----------------+

485通信接口
-----------

AX7Z020底板上有2路485通信接口，其中485通信端口1连接在PS系统端BANK500的GPIO接口上,485通信端口2连接在PL系统端BANK34的GPIO接口上。

485收发芯片选用MAXIM公司的MAX3485芯片为用户485通信服务。

图3-3-1为PL端485收发芯片的连接示意图

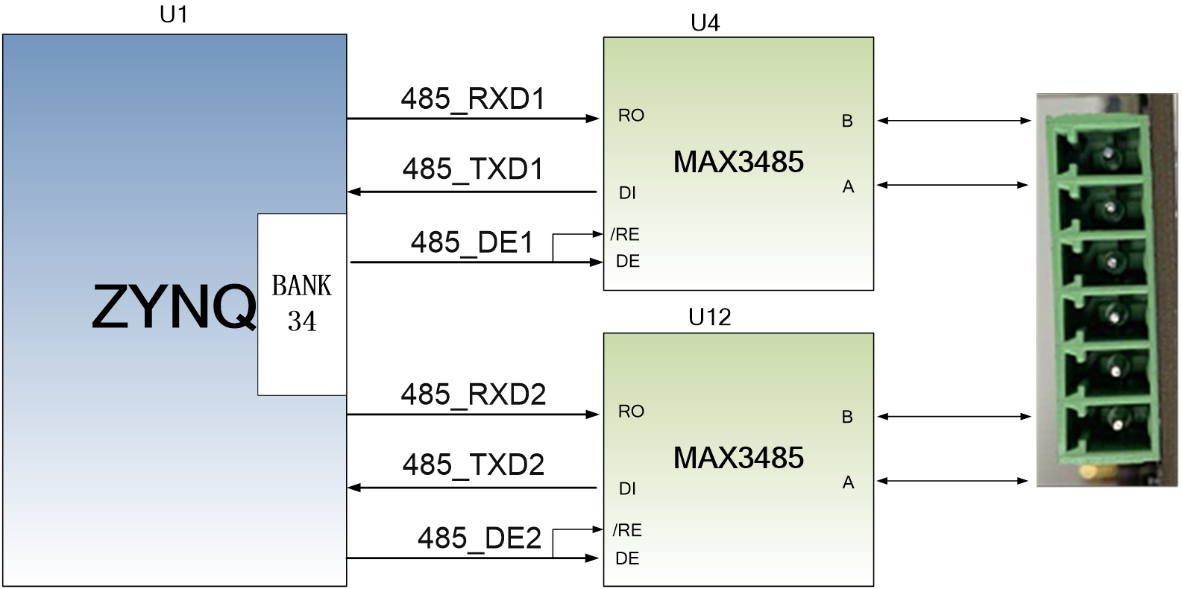
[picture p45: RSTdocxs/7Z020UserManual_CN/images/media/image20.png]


图3-3-1 RS485芯片和接口的连接示意图

图3-3-2为RS485收发芯片的实物图

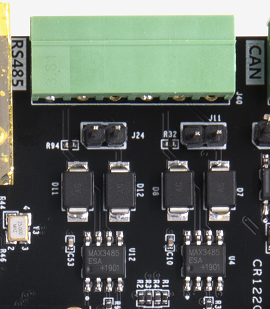
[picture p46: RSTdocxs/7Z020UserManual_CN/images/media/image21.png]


图3-3-2 RS485芯片和接口的实物图

**485通信引脚分配如下：**

+-----------------+----------------+-----------------+-----------------+
| **信号名称**    | **ZYNQ引脚名** | **ZYNQ引脚号**  | **备注**        |
+-----------------+----------------+-----------------+-----------------+
| 485_TXD1        | PS_MIO15       | C8              | 485发送端1      |
+-----------------+----------------+-----------------+-----------------+
| 485_RXD1        | PS_MIO14       | C5              | 485接收端1      |
+-----------------+----------------+-----------------+-----------------+
| 485_DE1         | PS_MIO9        | B5              | 4               |
|                 |                |                 | 85接受发射使能1 |
+-----------------+----------------+-----------------+-----------------+
| 485_TXD2        | IO34_L4N       | W13             | 485发送端2      |
+-----------------+----------------+-----------------+-----------------+
| 485_RXD2        | IO34_L4P       | V12             | 485接收端2      |
+-----------------+----------------+-----------------+-----------------+
| 485_DE2         | IO34_L12N      | U19             | 4               |
|                 |                |                 | 85接受发射使能2 |
+-----------------+----------------+-----------------+-----------------+

千兆以太网接口
--------------

AX7Z020底板上有1路千兆以太网接口，连接在PS系统端BANK501的GPIO接口上。

以太网芯片采用Micrel公司的KSZ9031RNX以太网PHY芯片为用户提供网络通信服务。KSZ9031RNX芯片支持10/100/1000
Mbps网络传输速率，通过RGMII接口跟Zynq7000系统的MAC层进行数据通信。KSZ9031RNX支持ＭDI/MDX自适应，各种速度自适应，Master/Slave自适应，支持MDIO总线进行PHY的寄存器管理。

KSZ9031RNX上电会检测一些特定的IO的电平状态，从而确定自己的工作模式。表3-2-1
描述了GPHY芯片上电之后的默认设定信息。

+-----------------+--------------------------+-------------------------+
| **配置Pin脚**   | **说明**                 | **配置值**              |
+-----------------+--------------------------+-------------------------+
| **PHYAD[2:0]**  | MDIO/MDC 模式的PHY地址   | PHY Address 为 011      |
+-----------------+--------------------------+-------------------------+
| **CLK125_EN**   | 使能125Mhz时钟输出选择   | 使能                    |
+-----------------+--------------------------+-------------------------+
| **LED_MODE**    | LED灯模式配置            | 单个LED灯模式           |
+-----------------+--------------------------+-------------------------+
| **MODE0~MODE3** | 链路自适应和全双工配置   | 10/100/1000自适         |
|                 |                          | 应，兼容全双工、半双工  |
+-----------------+--------------------------+-------------------------+

表3-4-1PHY芯片默认配置值

当网络连接到千兆以太网时，ZYNQ和PHY芯片KSZ9031RNX的数据传输时通过RGMII总线通信，传输时钟为125Mhz，数据在时钟的上升沿和下降样采样。

当网络连接到百兆以太网时，ZYNQ和PHY芯片KSZ9031RNX的数据传输时通过RMII总线通信，传输时钟为25Mhz。数据在时钟的上升沿和下降样采样。

图3-2-1为ZYNQ PS端1路以太网PHY芯片连接示意图:

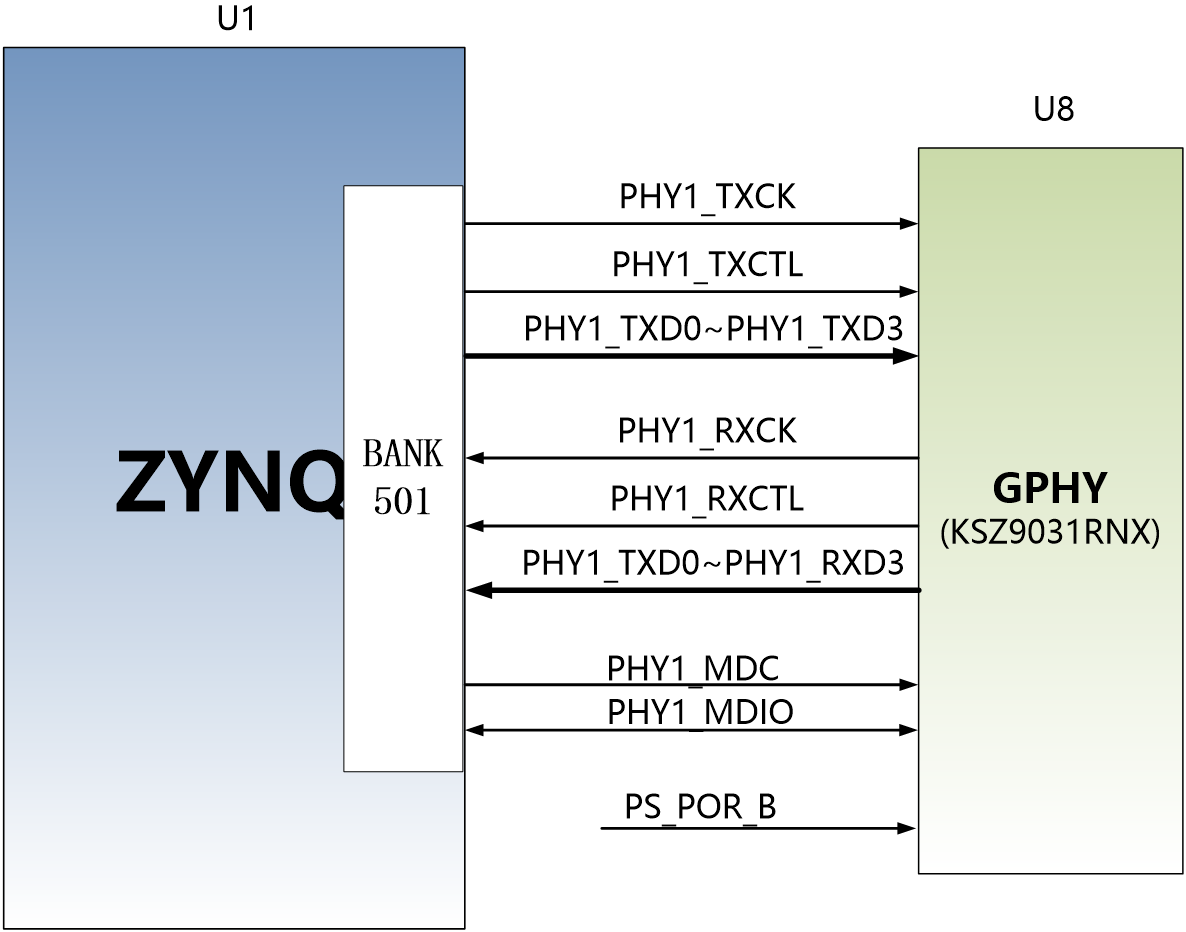
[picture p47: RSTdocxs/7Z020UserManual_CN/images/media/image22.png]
　　　　　　　　　　　　　　　图3-4-1 ZYNQ
PS系统与GPHY连接示意图

图3-4-3为PS端以太网GPHY芯片的实物图

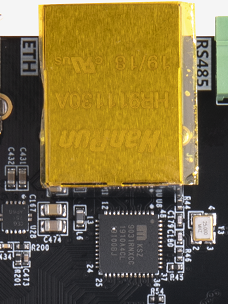
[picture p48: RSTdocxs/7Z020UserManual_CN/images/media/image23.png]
   

图3-4-3 PS端以太网GPHY芯片和接口实物图

**千兆以太网引脚分配如下：**

+-----------------+----------------+-----------------+-----------------+
| **信号名称**    | **ZYNQ引脚名** | **ZYNQ引脚号**  | **备注**        |
+-----------------+----------------+-----------------+-----------------+
| ETH_TXCK        | PS_MIO16       | A19             | RGMII 发送时钟  |
+-----------------+----------------+-----------------+-----------------+
| ETH_TXD0        | PS_MIO17       | E14             | 发送数据bit０   |
+-----------------+----------------+-----------------+-----------------+
| ETH_TXD1        | PS_MIO18       | B18             | 发送数据bit1    |
+-----------------+----------------+-----------------+-----------------+
| ETH_TXD2        | PS_MIO19       | D10             | 发送数据bit2    |
+-----------------+----------------+-----------------+-----------------+
| ETH_TXD3        | PS_MIO20       | A17             | 发送数据bit3    |
+-----------------+----------------+-----------------+-----------------+
| ETH_TXCTL       | PS_MIO21       | F14             | 发送使能信号    |
+-----------------+----------------+-----------------+-----------------+
| ETH_RXCK        | PS_MIO22       | B17             | RGMII接收时钟   |
+-----------------+----------------+-----------------+-----------------+
| ETH_RXD0        | PS_MIO23       | D11             | 接收数据Bit0    |
+-----------------+----------------+-----------------+-----------------+
| ETH_RXD1        | PS_MIO24       | A16             | 接收数据Bit1    |
+-----------------+----------------+-----------------+-----------------+
| ETH_RXD2        | PS_MIO25       | F15             | 接收数据Bit2    |
+-----------------+----------------+-----------------+-----------------+
| ETH_RXD3        | PS_MIO26       | A15             | 接收数据Bit3    |
+-----------------+----------------+-----------------+-----------------+
| ETH_RXCTL       | PS_MIO27       | D13             | 接              |
|                 |                |                 | 收数据有效信号  |
+-----------------+----------------+-----------------+-----------------+
| ETH_MDC         | PS_MIO52       | C10             | MDIO管理时钟    |
+-----------------+----------------+-----------------+-----------------+
| ETH_MDIO        | PS_MIO53       | C11             | MDIO管理数据    |
+-----------------+----------------+-----------------+-----------------+
| PS_POR_B        | PS_POR_B       | C7              | 复位信号        |
+-----------------+----------------+-----------------+-----------------+

USB2.0 Host接口
---------------

AX7Z020底板上有1个USB2.0 HOST接口，
USB2.0收发器采用的是一个1.8V的，高速的支持ULPI标准接口的USB3320C-EZK芯片,ZYNQ的USB总线接口和USB3320C-EZK收发器相连接，实现高速的USB2.0
Host模式的数据通信。USB3320C的USB的数据和控制信号连接到ZYNQ芯片PS端的BANK501的IO口上。24MHz的晶振为为USB3320C芯片提供系统时钟。

USB接口为扁型USB接口(USB Type A)，方便用户同时连接不同的USB
Slave外设(比如USB鼠标和USB键盘）。另外底板为USB接口提供了+5V的电源。

ZYNQ处理器和USB3320C-EZK芯片连接的示意图如3-5-1所示：

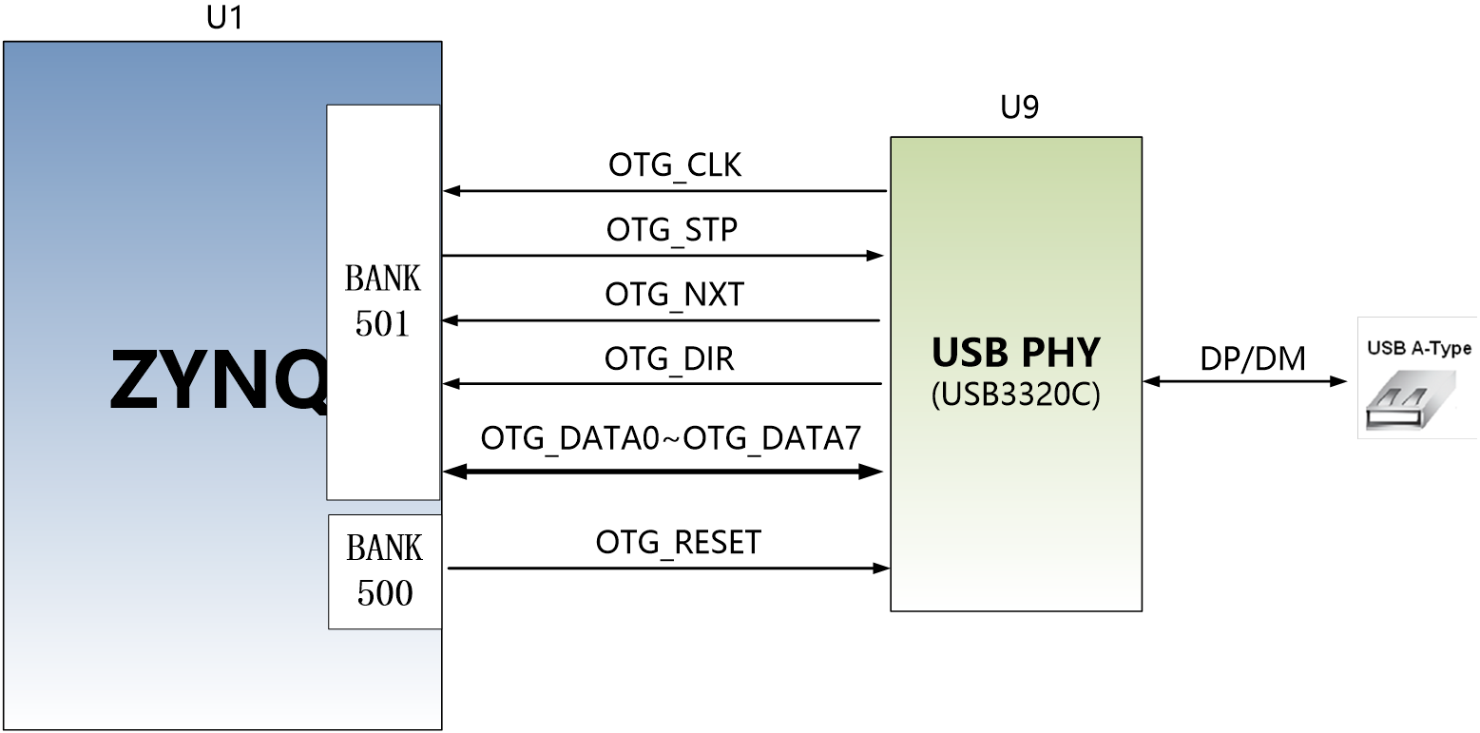
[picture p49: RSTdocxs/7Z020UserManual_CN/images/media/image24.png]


图3-5-1 Zynq7000和USB芯片间连接示意图

图3-5-2为USB2.0芯片和接口的实物图。

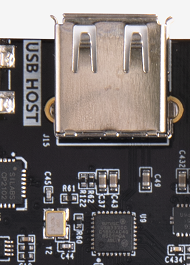
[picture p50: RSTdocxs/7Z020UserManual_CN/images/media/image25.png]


图3-5-2 USB2.0部分的实物图

**USB2.0引脚分配：**

+---------------+--------------+------------+-------------------------+
| **信号名称**  | **ZY         | **ZY       | **备注**                |
|               | NQ引脚名**   | NQ引脚号** |                         |
+---------------+--------------+------------+-------------------------+
| OTG_DATA4     | PS_MIO28     | C16        | USB数据Bit4             |
+---------------+--------------+------------+-------------------------+
| OTG_DIR       | PS_MIO29     | C13        | USB数据方向信号         |
+---------------+--------------+------------+-------------------------+
| OTG_STP       | PS_MIO30     | C15        | USB停止信号             |
+---------------+--------------+------------+-------------------------+
| OTG_NXT       | PS_MIO31     | E16        | USB下一数据信号         |
+---------------+--------------+------------+-------------------------+
| OTG_DATA0     | PS_MIO32     | A14        | USB数据Bit0             |
+---------------+--------------+------------+-------------------------+
| OTG_DATA1     | PS_MIO33     | D15        | USB数据Bit1             |
+---------------+--------------+------------+-------------------------+
| OTG_DATA2     | PS_MIO34     | A12        | USB数据Bit2             |
+---------------+--------------+------------+-------------------------+
| OTG_DATA3     | PS_MIO35     | F12        | USB数据Bit3             |
+---------------+--------------+------------+-------------------------+
| OTG_CLK       | PS_MIO36     | A11        | USB时钟信号             |
+---------------+--------------+------------+-------------------------+
| OTG_DATA5     | PS_MIO37     | A10        | USB数据Bit5             |
+---------------+--------------+------------+-------------------------+
| OTG_DATA6     | PS_MIO38     | E13        | USB数据Bit6             |
+---------------+--------------+------------+-------------------------+
| OTG_DATA7     | PS_MIO39     | C18        | USB数据Bit7             |
+---------------+--------------+------------+-------------------------+
| OTG_RESETN    | PS_MIO46     | D16        | USB复位信号             |
+---------------+--------------+------------+-------------------------+

USB转串口
---------

AX7Z020底板上配有一个USB转Uart接口，用于ZYNQ7000系统的整体调试，
转换芯片采用Silicon Labs CP2102GM的USB-UAR芯片, USB接口采用MINI
USB接口，可以用一根USB线将它连接到上PC的USB口进行核心板的单独供电和串口数据通信
。

USB Uart电路设计的示意图如下图3-6-1所示:

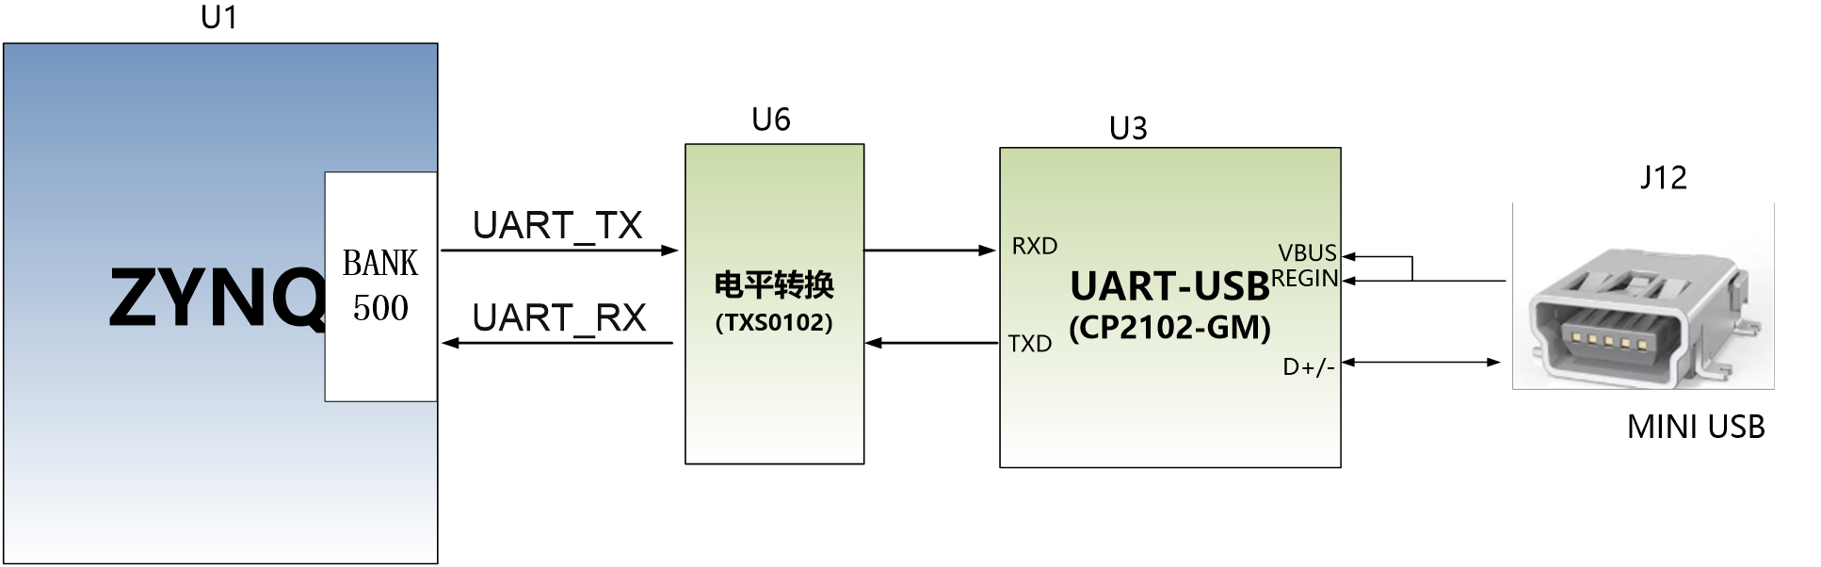
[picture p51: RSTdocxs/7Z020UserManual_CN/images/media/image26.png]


3-6-1 USB转串口示意图

下图3-6-2为USB转串口的实物图

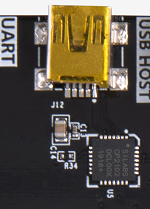
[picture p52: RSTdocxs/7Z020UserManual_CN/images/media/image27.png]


3-6-2 USB转串口实物图

**UART转串口的ZYNQ引脚分配：**

+---------------+--------------+------------+-------------------------+
| **信号名称**  | **ZY         | **ZY       | **备注**                |
|               | NQ引脚名**   | NQ引脚号** |                         |
+---------------+--------------+------------+-------------------------+
| UART_RX       | PS_MIO49     | C12        | Uart数据输入            |
+---------------+--------------+------------+-------------------------+
| UART_TX       | PS_MIO48     | B12        | Uart数据输出            |
+---------------+--------------+------------+-------------------------+

AD输入接口
----------

AX7Z020底板上配有4路AD输入接口，其中2路用于采集外部模拟信号进行AD转换，另外2路用于测量开发板的电源电压和电流。
用于采集外部模拟信号进行AD转换的2路模拟信号选用SMA接头作为输入，将输入的信号转换为差分信号后输入ZYNQ。电源电流测量连接到ZYNQ的专用AD输入管脚VP和VN。

AD采集电路设计的示意图如下图3-7-1所示:

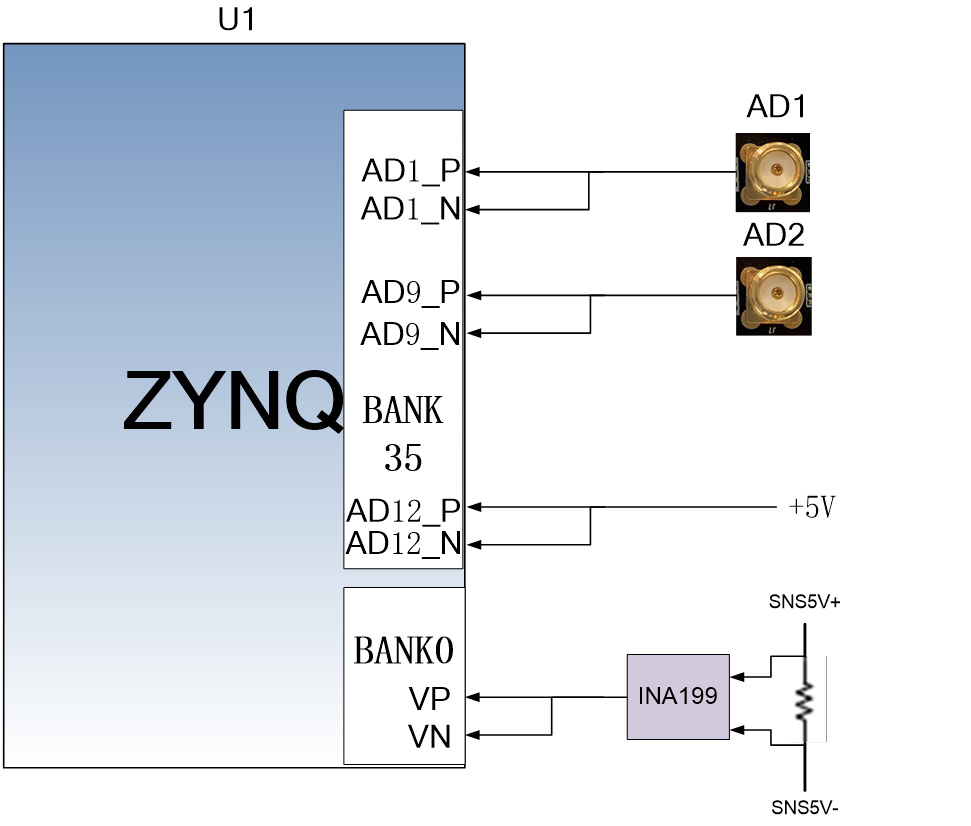
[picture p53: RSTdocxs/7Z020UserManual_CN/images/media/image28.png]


图3-7-1 AD采集电路设计的示意图

下图3-7-2为AD采集电路接口的实物图

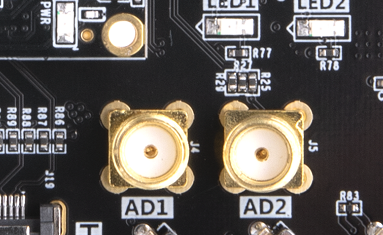
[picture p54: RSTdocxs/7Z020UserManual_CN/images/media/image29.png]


图3-7-2 AD采集电路接口的实物图

**AD采集电路的ZYNQ引脚分配：**

+---------------+--------------+------------+-------------------------+
| **信号名称**  | **ZY         | **ZY       | **备注**                |
|               | NQ引脚名**   | NQ引脚号** |                         |
+---------------+--------------+------------+-------------------------+
| XADC_AD1P     | IO35_L3P     | E17        | AD_IN_P                 |
+---------------+--------------+------------+-------------------------+
| XADC_AD1N     | IO35_L3N     | D18        | AD_IN_N                 |
+---------------+--------------+------------+-------------------------+
| XADC_AD9P     | IO35_L5P     | E18        | AD_IN_P                 |
+---------------+--------------+------------+-------------------------+
| XADC_AD9N     | IO35_L5N     | E19        | AD_IN_N                 |
+---------------+--------------+------------+-------------------------+
| XADC_AD12P    | IO35_L15P    | F19        | AD_IN_P                 |
+---------------+--------------+------------+-------------------------+
| XADC_AD12N    | IO35_L15N    | F20        | AD_IN_N                 |
+---------------+--------------+------------+-------------------------+
| VP            | VP           | K9         | AD_IN_P                 |
+---------------+--------------+------------+-------------------------+
| VN            | VN           | L10        | AD_IN_N                 |
+---------------+--------------+------------+-------------------------+

HDMI输出接口
------------

HDMI，全称为高清晰度多媒体视频输出接口。AX7Z020开发板上通过ZYNQ的差分IO直接连接到HDMI接口的差分信号和时钟，在ZYNQ内部实现HMDI信号的差分转并行再进行编解码，实现DMI数字视频输入和输出的传输解决方案，最高支持1080P@60Hz的输入和输出的功能。

HDMI的信号连接到ZYNQ的PL部分的BANK34上,设计原理图如下图3-8-1所示：

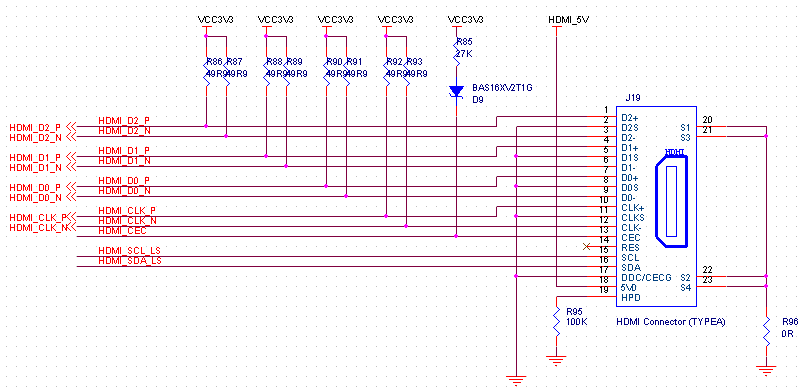
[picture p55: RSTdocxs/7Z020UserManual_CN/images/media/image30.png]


图3-8-1 HDMI接口设计原理图

图3-8-2为HDMI接口的实物图，

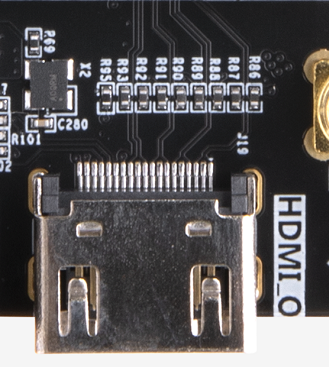
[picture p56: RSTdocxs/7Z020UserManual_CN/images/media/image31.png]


图3-8-2 HDMI接口实物图

**ZYNQ的引脚分配：**

+---------------+--------------+------------+-------------------------+
| **信号名称**  | **ZY         | **ZY       | **备注**                |
|               | NQ引脚名**   | NQ引脚号** |                         |
+---------------+--------------+------------+-------------------------+
| HDMI_CLK_P    | IO34_L3P     | U13        | HDMI时钟信号正          |
+---------------+--------------+------------+-------------------------+
| HDMI_CLK_N    | IO34_L3N     | V13        | HDMI时钟信号负          |
+---------------+--------------+------------+-------------------------+
| HDMI_D0_P     | IO34_L8P     | W14        | HDMI数据0正             |
+---------------+--------------+------------+-------------------------+
| HDMI_D0_N     | IO34_L8N     | Y14        | HDMI数据0负             |
+---------------+--------------+------------+-------------------------+
| HDMI_D1_P     | IO34_L17P    | Y18        | HDMI数据1正             |
+---------------+--------------+------------+-------------------------+
| HDMI_D1_N     | IO34_L17N    | Y19        | HDMI数据1负             |
+---------------+--------------+------------+-------------------------+
| HDMI_D2_P     | IO34_L7P     | Y16        | HDMI数据2正             |
+---------------+--------------+------------+-------------------------+
| HDMI_D2_N     | IO34_L7N     | Y17        | HDMI数据2负             |
+---------------+--------------+------------+-------------------------+
| HDMI_SCL      | IO34_L21N    | V18        | HDMI IIC时钟            |
+---------------+--------------+------------+-------------------------+
| HDMI_SDA      | IO34_L21P    | V17        | HDMI IIC数据            |
+---------------+--------------+------------+-------------------------+

MIPI摄像头接口
--------------

AX7Z020底板上包含了一个MIPI摄像头接口，可以用来接我们的MIPI
OV5640摄像头模块。MIPI接口部分的电路原理图如下图3-9-1 所示：

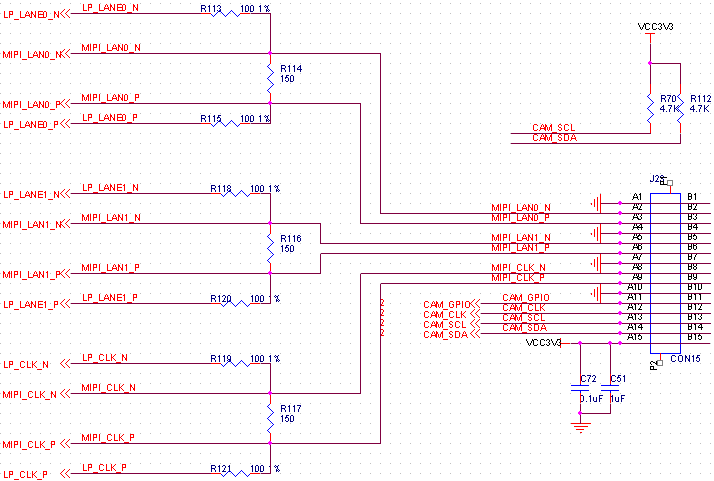
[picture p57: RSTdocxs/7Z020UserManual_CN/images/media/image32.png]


图3-9-1 MIPI接口设计原理图

图3-9-2 为MIPI摄像头接口的实物图：



图3-9-1 HMIPI接口设计原理图

MIPI接口引脚分配

+---------------+--------------+------------+-------------------------+
| **信号名称**  | **ZY         | **ZY       | **备注**                |
|               | NQ引脚名**   | NQ引脚号** |                         |
+---------------+--------------+------------+-------------------------+
| LP_CLK_P      | IO13_L15P    | V8         | Low Power模式的时钟正   |
+---------------+--------------+------------+-------------------------+
| LP_CLK_N      | IO13_L15N    | W8         | Low Power模式的时钟负   |
+---------------+--------------+------------+-------------------------+
| LP_LANE0_P    | IO13_L12P    | T9         | Low Power模式的LANE0正  |
+---------------+--------------+------------+-------------------------+
| LP_LANE0_N    | IO13_L12N    | U10        | Low Power模式的LANE0负  |
+---------------+--------------+------------+-------------------------+
| LP_LANE1_P    | IO13_L20P    | Y12        | Low Power模式的LANE1正  |
+---------------+--------------+------------+-------------------------+
| LP_LANE1_N    | IO13_L20N    | Y13        | Low Power模式的LANE1负  |
+---------------+--------------+------------+-------------------------+
| MIPI_CLK_P    | IO13_L13P    | Y7         | High Speed模式的时钟正  |
+---------------+--------------+------------+-------------------------+
| MIPI_CLK_N    | IO13_L13N    | Y6         | High Speed模式的时钟负  |
+---------------+--------------+------------+-------------------------+
| MIPI_LAN0_P   | IO13_L18P    | W11        | High Speed模式的LANE0正 |
+---------------+--------------+------------+-------------------------+
| MIPI_LAN0_N   | IO13_L18N    | Y11        | High Speed模式的LANE0负 |
+---------------+--------------+------------+-------------------------+
| MIPI_LAN1_P   | IO13_L17P    | U9         | High Speed模式的LANE1正 |
+---------------+--------------+------------+-------------------------+
| MIPI_LAN1_N   | IO13_L17N    | U8         | High Speed模式的LANE1负 |
+---------------+--------------+------------+-------------------------+
| CAM_GPIO      | IO13_L11P    | U7         | 摄像头的GPIO控制        |
+---------------+--------------+------------+-------------------------+
| CAM_CLK       | IO13_L11N    | V7         | 摄像头的时钟输入        |
+---------------+--------------+------------+-------------------------+
| CAM_SCL       | IO13_L19P    | T5         | 摄像头的I2C时钟         |
+---------------+--------------+------------+-------------------------+
| CAM_SDA       | IO13_L19N    | U5         | 摄像头的I2C数据         |
+---------------+--------------+------------+-------------------------+

SD卡槽
------

AX7Z020底板包含了一个Micro型的SD卡接口，以提供用户访问SD卡存储器，用于存储ZYNQ芯片的BOOT程序，Linux操作系统内核,
文件系统以及其它的用户数据文件。

SDIO信号与ZYNQ的PS
BANK501的IO信号相连，因为该BANK的VCCMIO设置为1.8V，但SD卡的数据电平为3.3V,
我们这里通过TXS02612电平转换器来连接。Zynq7000
PS和SD卡连接器的原理图如图3-6-1所示。

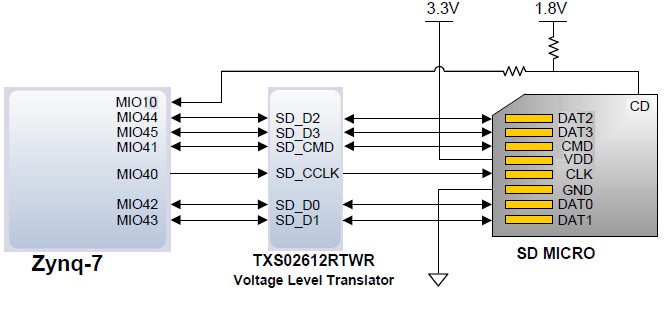
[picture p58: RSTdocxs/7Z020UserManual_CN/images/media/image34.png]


图3-10-1 SD卡连接示意图

图3-10-2 为开发板上SD卡槽实物图

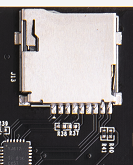
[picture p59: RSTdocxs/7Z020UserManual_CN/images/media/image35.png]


图3-10-2 SD卡槽实物图

**SD卡槽引脚分配**

+---------------+--------------+------------+-------------------------+
| **信号名称**  | **ZY         | **ZY       | **备注**                |
|               | NQ引脚名**   | NQ引脚号** |                         |
+---------------+--------------+------------+-------------------------+
| SD_CLK        | PS_MIO40     | D14        | SD时钟信号              |
+---------------+--------------+------------+-------------------------+
| SD_CMD        | PS_MIO41     | C17        | SD命令信号              |
+---------------+--------------+------------+-------------------------+
| SD_D0         | PS_MIO42     | E12        | SD数据Data0             |
+---------------+--------------+------------+-------------------------+
| SD_D1         | PS_MIO43     | A9         | SD数据Data1             |
+---------------+--------------+------------+-------------------------+
| SD_D2         | PS_MIO44     | F13        | SD数据Data2             |
+---------------+--------------+------------+-------------------------+
| SD_D3         | PS_MIO45     | B15        | SD数据Data3             |
+---------------+--------------+------------+-------------------------+
| SD_CD         | PS_MIO47     | B14        | SD卡插入信号            |
+---------------+--------------+------------+-------------------------+

EEPROM
------

AX7Z020开发板板载了一片EEPROM。EEPROM的型号为24LC04,容量为：4Kbit（2*256*8bit），由2个256byte的block组成,通过IIC总线进行通信。板载EEPROM就是为了学习IIC总线的通信方式。EEPROM的I2C信号连接的ZYNQ
PS端的I2C接口上。图3-11-1为EEPROM的连接示意图

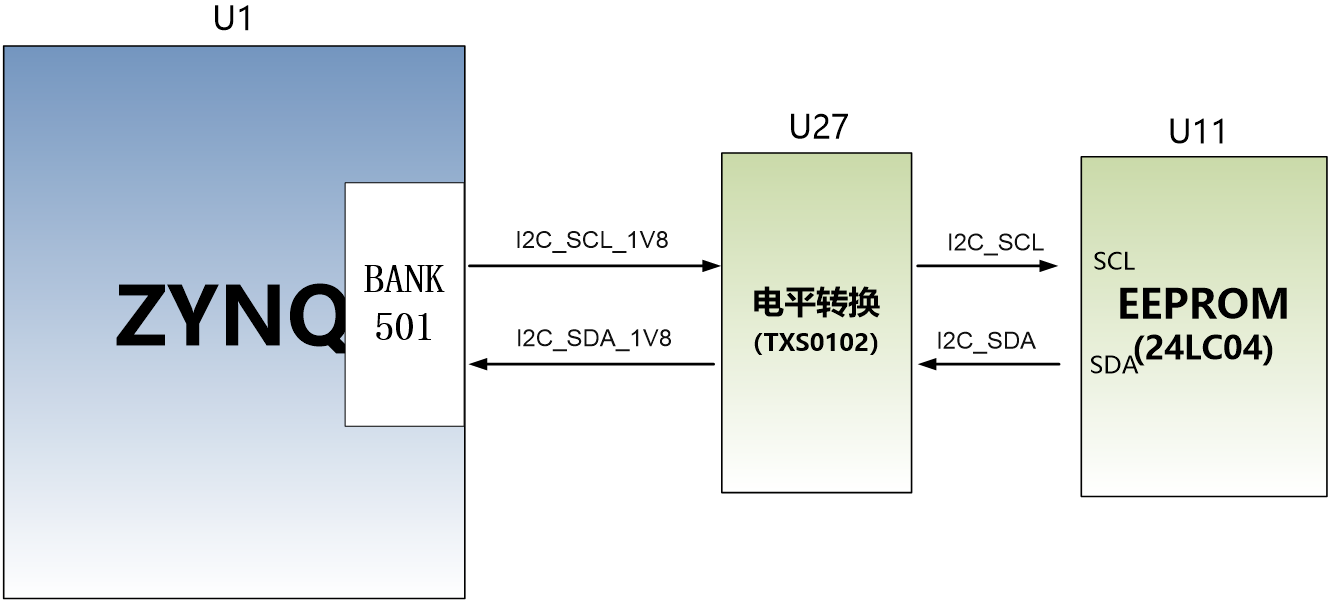
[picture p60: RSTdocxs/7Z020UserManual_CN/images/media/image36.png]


图7-5 EEPROM连接示意图

图3-11-2为EEPROM实物图

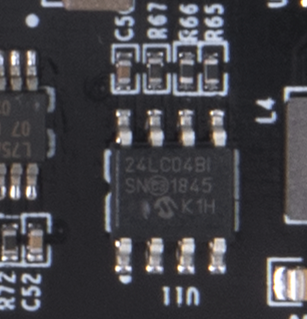
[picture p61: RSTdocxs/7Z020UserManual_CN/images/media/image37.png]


图3-11-2 EEPROM实物图

**EEPROM引脚分配：**

+----------------+-------------------+-----------+--------------------+
| **信号名称**   | **ZYNQ引脚名**    | **ZYN     | **备注**           |
|                |                   | Q引脚号** |                    |
+----------------+-------------------+-----------+--------------------+
| I2C_SCL_1V8    | MIO50             | B13       | IIC时钟信号        |
+----------------+-------------------+-----------+--------------------+
| I2C_SDA_1V8    | MIO51             | B9        | IIC数据信号        |
+----------------+-------------------+-----------+--------------------+

实时时钟 
---------

开发板板载了一片实时时钟RTC芯片，型号DS1338，他的功能是提供到2099年内的日历功能，年月日时分秒还有星期。如果系统中需要时间的话，那么RTC就需要涉及到产品中。他外部需要接一个32.768KHz的无源时钟，提供精确的时钟源给时钟芯片，这样才能让RTC可以准确的提供时钟信息给产品。同时为了产品掉电以后，实时时钟还可以正常运行，一般需要另外配一个电池给时钟芯片供电，图3-12-2中为BT1为电池座，我们将纽扣电池（型号CR1220，电压为3V）放入以后，当系统掉电池，纽扣电池还可以给DS1338供电，这样，不管产品是否供电，DS1302都会正常运行，不会间断，可以提供持续不断的时间信息。RTC的接口信号跟EEPORM是共用I2C总线。图3-12-1为DS1338连接示意图

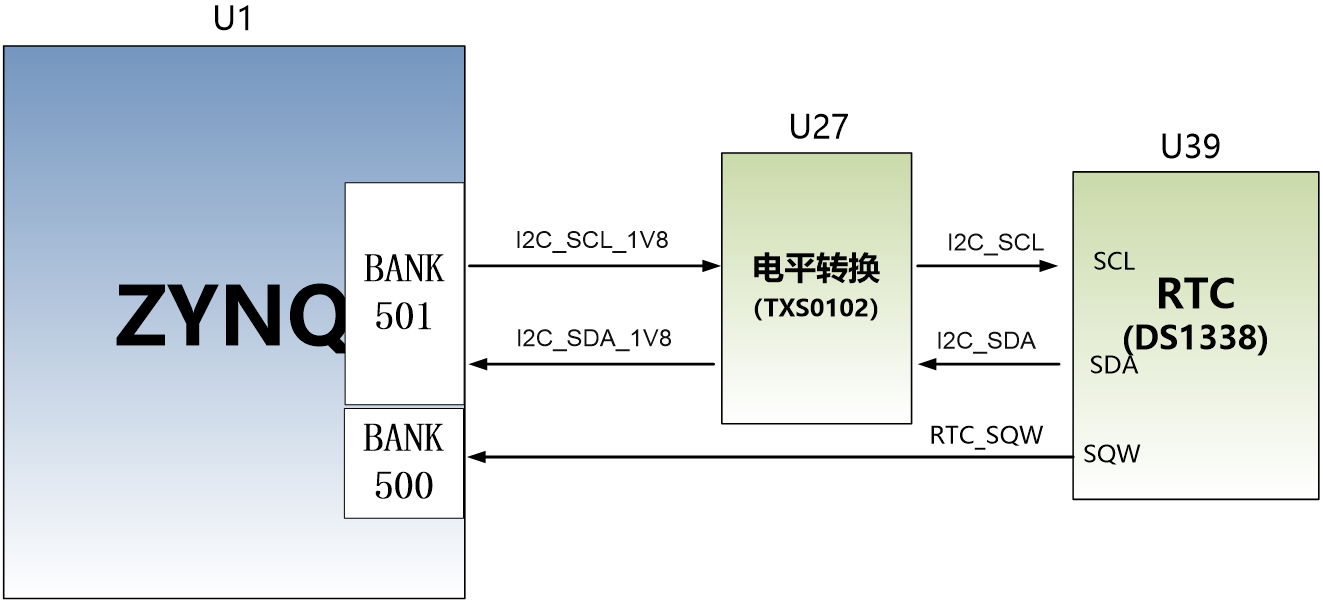
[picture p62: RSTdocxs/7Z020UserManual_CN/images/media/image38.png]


图3-12-1 DS1338原理图

图3-12-2为DS1338实物图

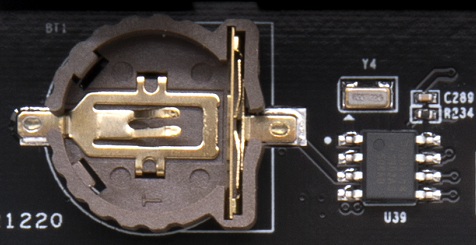
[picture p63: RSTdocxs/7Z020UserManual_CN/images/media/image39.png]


图3-12-2 DS1302实物图

**DS1338接口引脚分配：**

+---------------+--------------------+-------------+------------------+
| **信号名称**  | **ZYNQ引脚名**     | **Z         | **备注**         |
|               |                    | YNQ引脚号** |                  |
+---------------+--------------------+-------------+------------------+
| I2C_SCL_1V8   | MIO50              | B13         | RTC的时钟信号    |
+---------------+--------------------+-------------+------------------+
| I2C_SDA_1V8   | MIO51              | B9          | RTC的复位信号    |
+---------------+--------------------+-------------+------------------+
| RTC_SQW       | MIO7               | D8          | 方波输出信号     |
+---------------+--------------------+-------------+------------------+

温度传感器
----------

AX7Z020开发板上安装了一个高精度、低功耗、数字温度传感器芯片，型号为ON
Semiconductor公司的LM75。LM75芯片的温度精度为0.5度,传感器和FPGA直接为I2C数字接口，
ZYNQ7020通过I2C接口来读取当前开发板附近的温度。LM75传感器的接口信号跟EEPORM是共用I2C总线，下图3-13-1为LM75传感器连接示意图

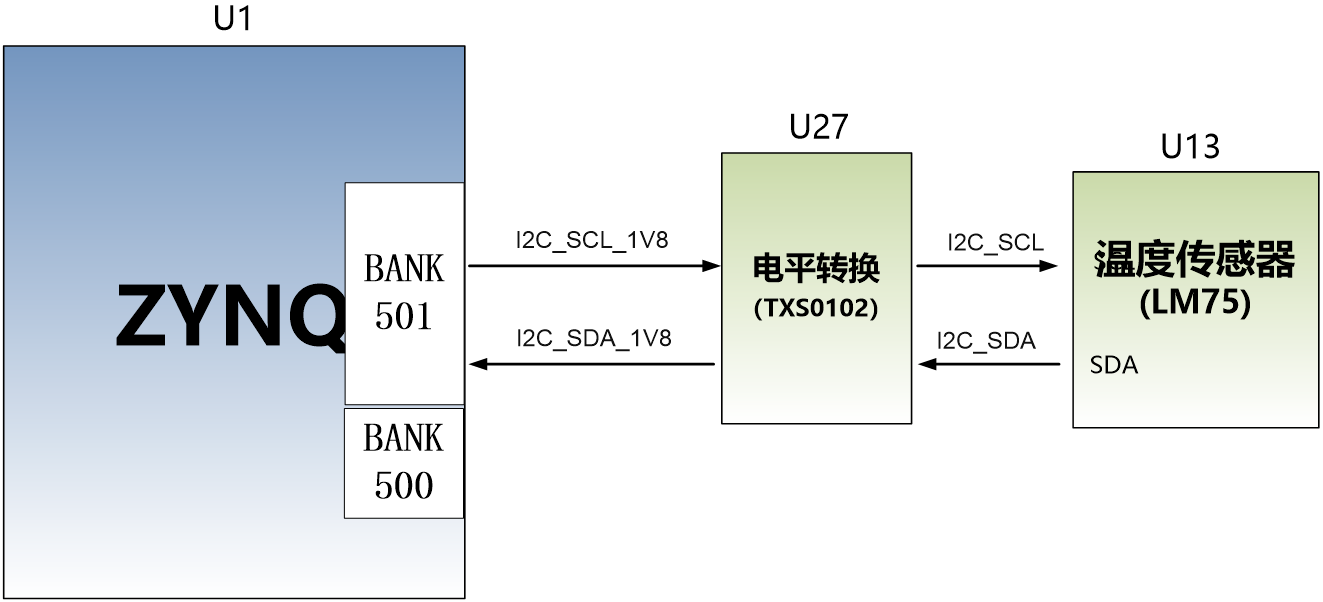
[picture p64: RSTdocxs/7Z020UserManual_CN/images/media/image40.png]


图3-13-1 LM75传感器连接示意图

下图为LM75传感器实物图

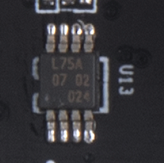
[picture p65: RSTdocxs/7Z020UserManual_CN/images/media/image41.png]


图3-13-2 LM75传感器实物图

JTAG接口
--------

在AX7Z020底板上预留了JTAG的下载调试电路，将
ZYNQ的JTAG调试信号TCK,TDO,TMS,TDI引出。图3-14-1为开发板上JTAG口的原理图部分：

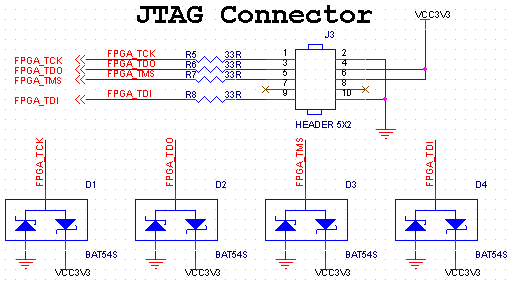
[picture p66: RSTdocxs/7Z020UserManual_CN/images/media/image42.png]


图3-14-1 原理图中JTAG接口部分

在AX7Z020开发板上，JTAG接口的实物图如下图3-14-2，用户可以通过我们的下载器进行ZYNQ的系统调试。



图3-14-2 JTAG接口实物图

用户LED灯
---------

AX7Z020底板上有4个用户LED灯（LED1~LED4）。4个用户LED灯均连接到PL端BANK35的IO上，用户可以通过程序来控制亮和灭，当连接用户LED灯的IO电压为高时，用户LED灯熄灭，当连接IO电压为低时，用户LED会被点亮。LED灯硬件连接的示意图如图3-15-1所示：



图3-15-1 底板LED灯硬件连接示意图

图3-15-2 为底板上的LED灯实物图



图3-15-2 底板的LED灯实物图

**底板用户LED灯的引脚分配**

+--------------+------------------+--------------+--------------------+
| **信号名称** | **ZYNQ引脚名**   | **ZY         | **备注**           |
|              |                  | NQ管脚号**   |                    |
+--------------+------------------+--------------+--------------------+
| LED1         | IO35_L20N        | J14          | 用户LED1灯         |
+--------------+------------------+--------------+--------------------+
| LED2         | IO35_L20P        | K14          | 用户LED2灯         |
+--------------+------------------+--------------+--------------------+
| LED3         | IO35_L14P        | J18          | 用户LED3灯         |
+--------------+------------------+--------------+--------------------+
| LED4         | IO35_L14N        | H18          | 用户LED4灯         |
+--------------+------------------+--------------+--------------------+

用户按键
--------

AX7Z020底板上有4个用户按键KEY1~KEY4，4个用户KEY均连接到PL端BANK35的IO上。按键按下，信号为低，ZYNQ芯片就是检测到低电平来判断按键是否按下。用户按键连接的示意图如图3-16-1所示：



图3-16-1 用户按键连接示意图

图3-16-2 为用户按键在底板的实物图



图2-16-2 用户按键实物图

**用户按键的ZYNQ管脚分配**

+---------------+---------------+------------+------------------------+
| **信号名称**  | **ZY          | **ZY       | **备注**               |
|               | NQ引脚名**    | NQ引脚号** |                        |
+---------------+---------------+------------+------------------------+
| KEY1          | IO35_L23N     | M15        | 用户按键KEY1           |
+---------------+---------------+------------+------------------------+
| KEY2          | IO35_L23P     | M14        | 用户按键KEY2           |
+---------------+---------------+------------+------------------------+
| KEY3          | IO35_L11N     | L17        | 用户按键KEY3           |
+---------------+---------------+------------+------------------------+
| KEY4          | IO35_L11P     | L16        | 用户按键KEY4           |
+---------------+---------------+------------+------------------------+

扩展口
------

AX7Z020底板预留了2个2.54mm标准间距的40针的扩展口J20和J21，用于连接黑金的各个模块或者用户自己设计的外面电路，扩展口有40个信号，其中，5V电源1路，3.3V电源2路，地3路，IO口34路。\ **切勿IO直接跟5V设备直接连接，以免烧坏ZYNQ7000芯片。如果要接5V设备，需要接电平转换芯片。**

扩展口(J20)的电路如下图3-17-1所示



图3-17-1扩展口J20原理图

下图为J20扩展口实物图，扩展口的Pin1,2,39, 40已经在板上标示出。



图3-17-2扩展口J20实物图

**J20扩展口ZYNQ的引脚分配**

+-----------------+------------------+---------------+-----------------+
| **引脚编号**    | **ZYNQ引脚**     | **引脚编号**  | **ZYNQ引脚**    |
+-----------------+------------------+---------------+-----------------+
| **1**           | GND              | **2**         | +5V             |
+-----------------+------------------+---------------+-----------------+
| **3**           | R14              | **4**         | P14             |
+-----------------+------------------+---------------+-----------------+
| **5**           | U12              | **6**         | T12             |
+-----------------+------------------+---------------+-----------------+
| **7**           | T15              | **8**         | T14             |
+-----------------+------------------+---------------+-----------------+
| **9**           | T11              | **10**        | T10             |
+-----------------+------------------+---------------+-----------------+
| **11**          | U15              | **12**        | U14             |
+-----------------+------------------+---------------+-----------------+
| **13**          | P19              | **14**        | N18             |
+-----------------+------------------+---------------+-----------------+
| **15**          | R17              | **16**        | R16             |
+-----------------+------------------+---------------+-----------------+
| **17**          | P15              | **18**        | P16             |
+-----------------+------------------+---------------+-----------------+
| **19**          | N17              | **20**        | P18             |
+-----------------+------------------+---------------+-----------------+
| **21**          | V16              | **22**        | W16             |
+-----------------+------------------+---------------+-----------------+
| **23**          | R18              | **24**        | T17             |
+-----------------+------------------+---------------+-----------------+
| **25**          | W19              | **26**        | W18             |
+-----------------+------------------+---------------+-----------------+
| **27**          | W20              | **28**        | V20             |
+-----------------+------------------+---------------+-----------------+
| **29**          | P20              | **30**        | N20             |
+-----------------+------------------+---------------+-----------------+
| **31**          | U17              | **32**        | T16             |
+-----------------+------------------+---------------+-----------------+
| **33**          | U20              | **34**        | T20             |
+-----------------+------------------+---------------+-----------------+
| **35**          | V15              | **36**        | W15             |
+-----------------+------------------+---------------+-----------------+
| **37**          | GND              | **38**        | GND             |
+-----------------+------------------+---------------+-----------------+
| **39**          | +3.3V            | **40**        | +3.3V           |
+-----------------+------------------+---------------+-----------------+

扩展口(J21)的电路如下图3-17-3所示



图3-17-3扩展口J21原理图

下图为J21扩展口实物图，扩展口的Pin1, 2,39,40已经在板上标示出。



图3-17-4扩展口J21实物图

**J21扩展口ZYNQ的引脚分配**

+-----------------+-------------------+---------------+---------------+
| **引脚编号**    | **ZYNQ引脚**      | **引脚编号**  | **ZYNQ引脚**  |
+-----------------+-------------------+---------------+---------------+
| **1**           | GND               | **2**         | +5V           |
+-----------------+-------------------+---------------+---------------+
| **3**           | M18               | **4**         | M17           |
+-----------------+-------------------+---------------+---------------+
| **5**           | K19               | **6**         | J19           |
+-----------------+-------------------+---------------+---------------+
| **7**           | B19               | **8**         | A20           |
+-----------------+-------------------+---------------+---------------+
| **9**           | B20               | **10**        | C20           |
+-----------------+-------------------+---------------+---------------+
| **11**          | G19               | **12**        | G20           |
+-----------------+-------------------+---------------+---------------+
| **13**          | M19               | **14**        | M20           |
+-----------------+-------------------+---------------+---------------+
| **15**          | D20               | **16**        | D19           |
+-----------------+-------------------+---------------+---------------+
| **17**          | L20               | **18**        | L19           |
+-----------------+-------------------+---------------+---------------+
| **19**          | F16               | **20**        | F17           |
+-----------------+-------------------+---------------+---------------+
| **21**          | H20               | **22**        | J20           |
+-----------------+-------------------+---------------+---------------+
| **23**          | G18               | **24**        | G17           |
+-----------------+-------------------+---------------+---------------+
| **25**          | H17               | **26**        | H16           |
+-----------------+-------------------+---------------+---------------+
| **27**          | G15               | **28**        | H15           |
+-----------------+-------------------+---------------+---------------+
| **29**          | K18               | **30**        | K17           |
+-----------------+-------------------+---------------+---------------+
| **31**          | J16               | **32**        | K16           |
+-----------------+-------------------+---------------+---------------+
| **33**          | N16               | **34**        | N15           |
+-----------------+-------------------+---------------+---------------+
| **35**          | L15               | **36**        | L14           |
+-----------------+-------------------+---------------+---------------+
| **37**          | GND               | **38**        | GND           |
+-----------------+-------------------+---------------+---------------+
| **39**          | +3.3V             | **40**        | +3.3V         |
+-----------------+-------------------+---------------+---------------+

供电电源
--------

开发板的电源输入电压为DC5V，请使用开发板自带的电源,不要用其他规格的电源，以免损坏开发板。底板上通过2路DC/DC电源芯片TLV62130RGT和1路LDO电源芯片SPX3819M5-ADJ转换成1.8V，+3.3V和VCCIO35三路电源。VCCIO35默认输出是3.3V，可以通过跳帽的链接来改变VCCIO35的输出，使其变为2.5V或者1.8V。

扩展上的电源设计如下图3-18-1所示:



图3-18-1底板电源原理图

ZYNQ7020的BANK35的IO的电平可以由底板的跳线帽来调整电压，默认如果J28，J29没有安装跳线帽，BANK35的IO电平是3.3V的。如果J29安装了跳线帽，BANK35的IO电平是1.8V。如果J28安装了跳线帽，BANK35的IO电平是2.5V。



图3-18-2 VCCIO35的电压调整

底板结构图
----------



正面图（Top View）




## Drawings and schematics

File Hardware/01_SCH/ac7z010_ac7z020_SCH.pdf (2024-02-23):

# REV

V1.0

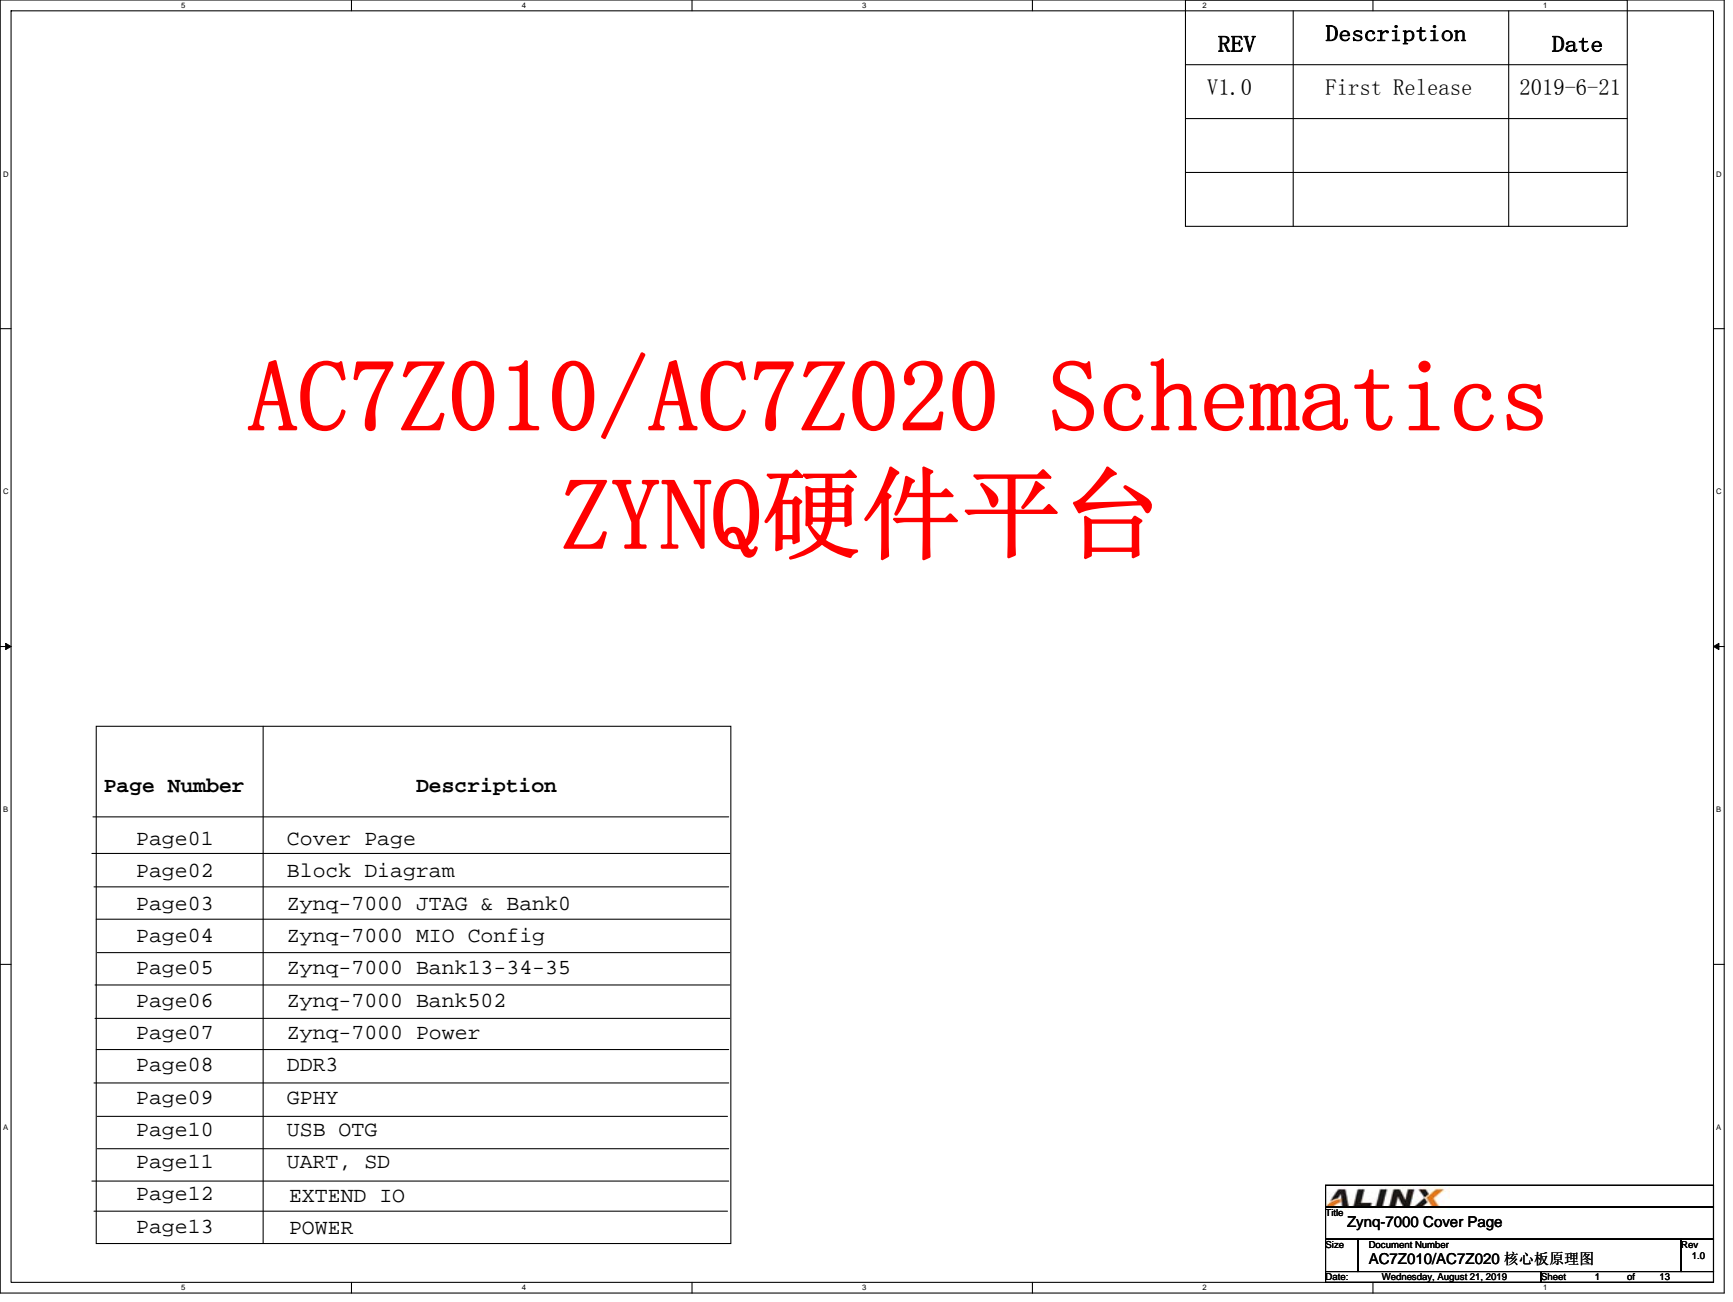
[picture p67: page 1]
ZYNQ硬件平台; AC7Z010/AC7Z020 Schematics; Description; Date; First Release; POWER

Page Number | Description

Page01 | Cover Page
Page02 | Block Diagram
Page03 | Zynq-7000 JTAG & Bank0
Page04 | Zynq-7000 MIO Config
Page05 | Zynq-7000 Bank13-34-35
Page06 | Zynq-7000 Bank502
Page07 | Zynq-7000 Power
Page08 | DDR3
Page09 | GPHY
Page10 | USB OTG
Page11 | UART, SD
Page12 | EXTEND IO

Title
Zynq-7000 Cover Page

Size | Document Number AC7Z010/AC7Z020 核心板原理图 | Rev 1.0

Date: Wednesday, August 21, 2019 Wednesday, August 21, 2019 Wednesday, August 21, 2019 | Sheet 1 1 1 of 13 13 13

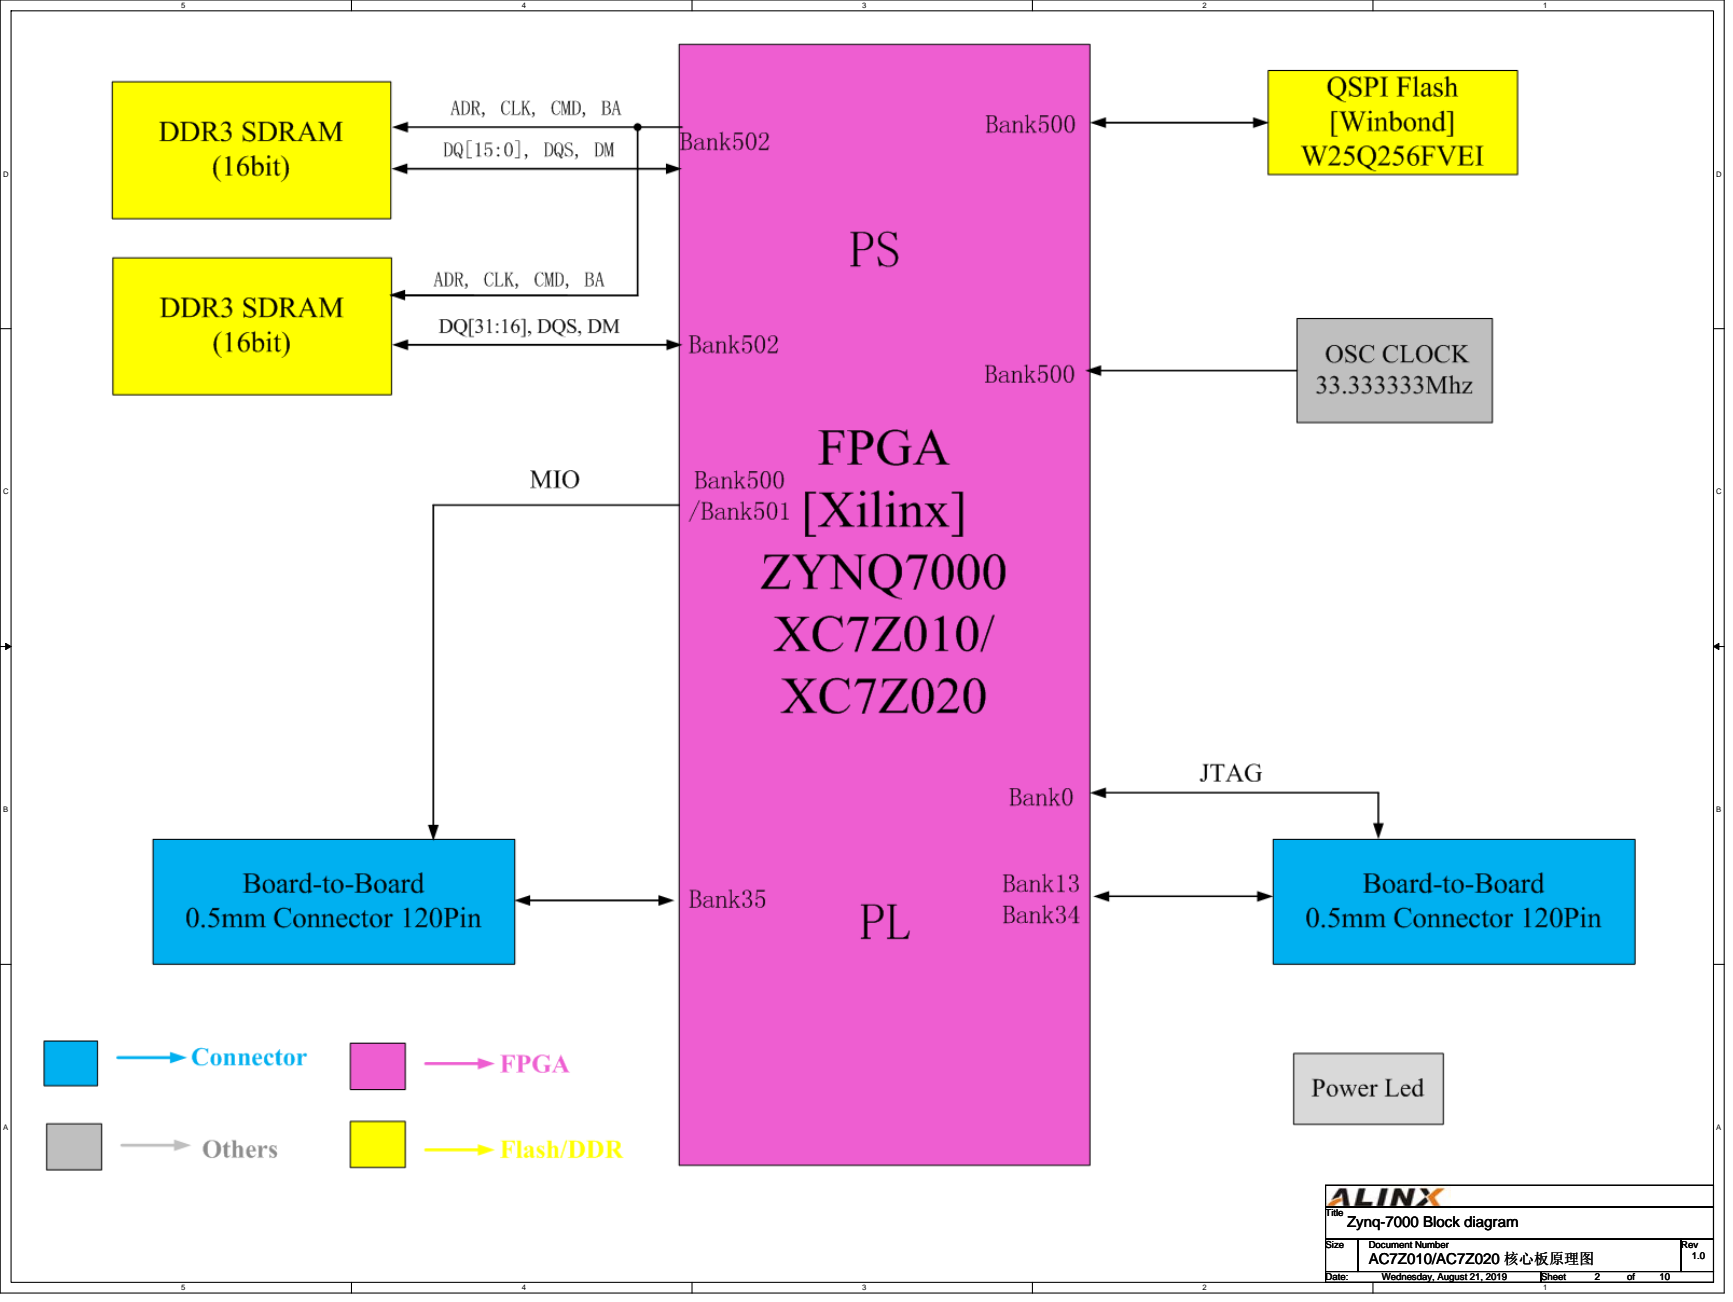
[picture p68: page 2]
Wednesday, August 21, 2019

Zynq-7000 Block diagram

1.25V

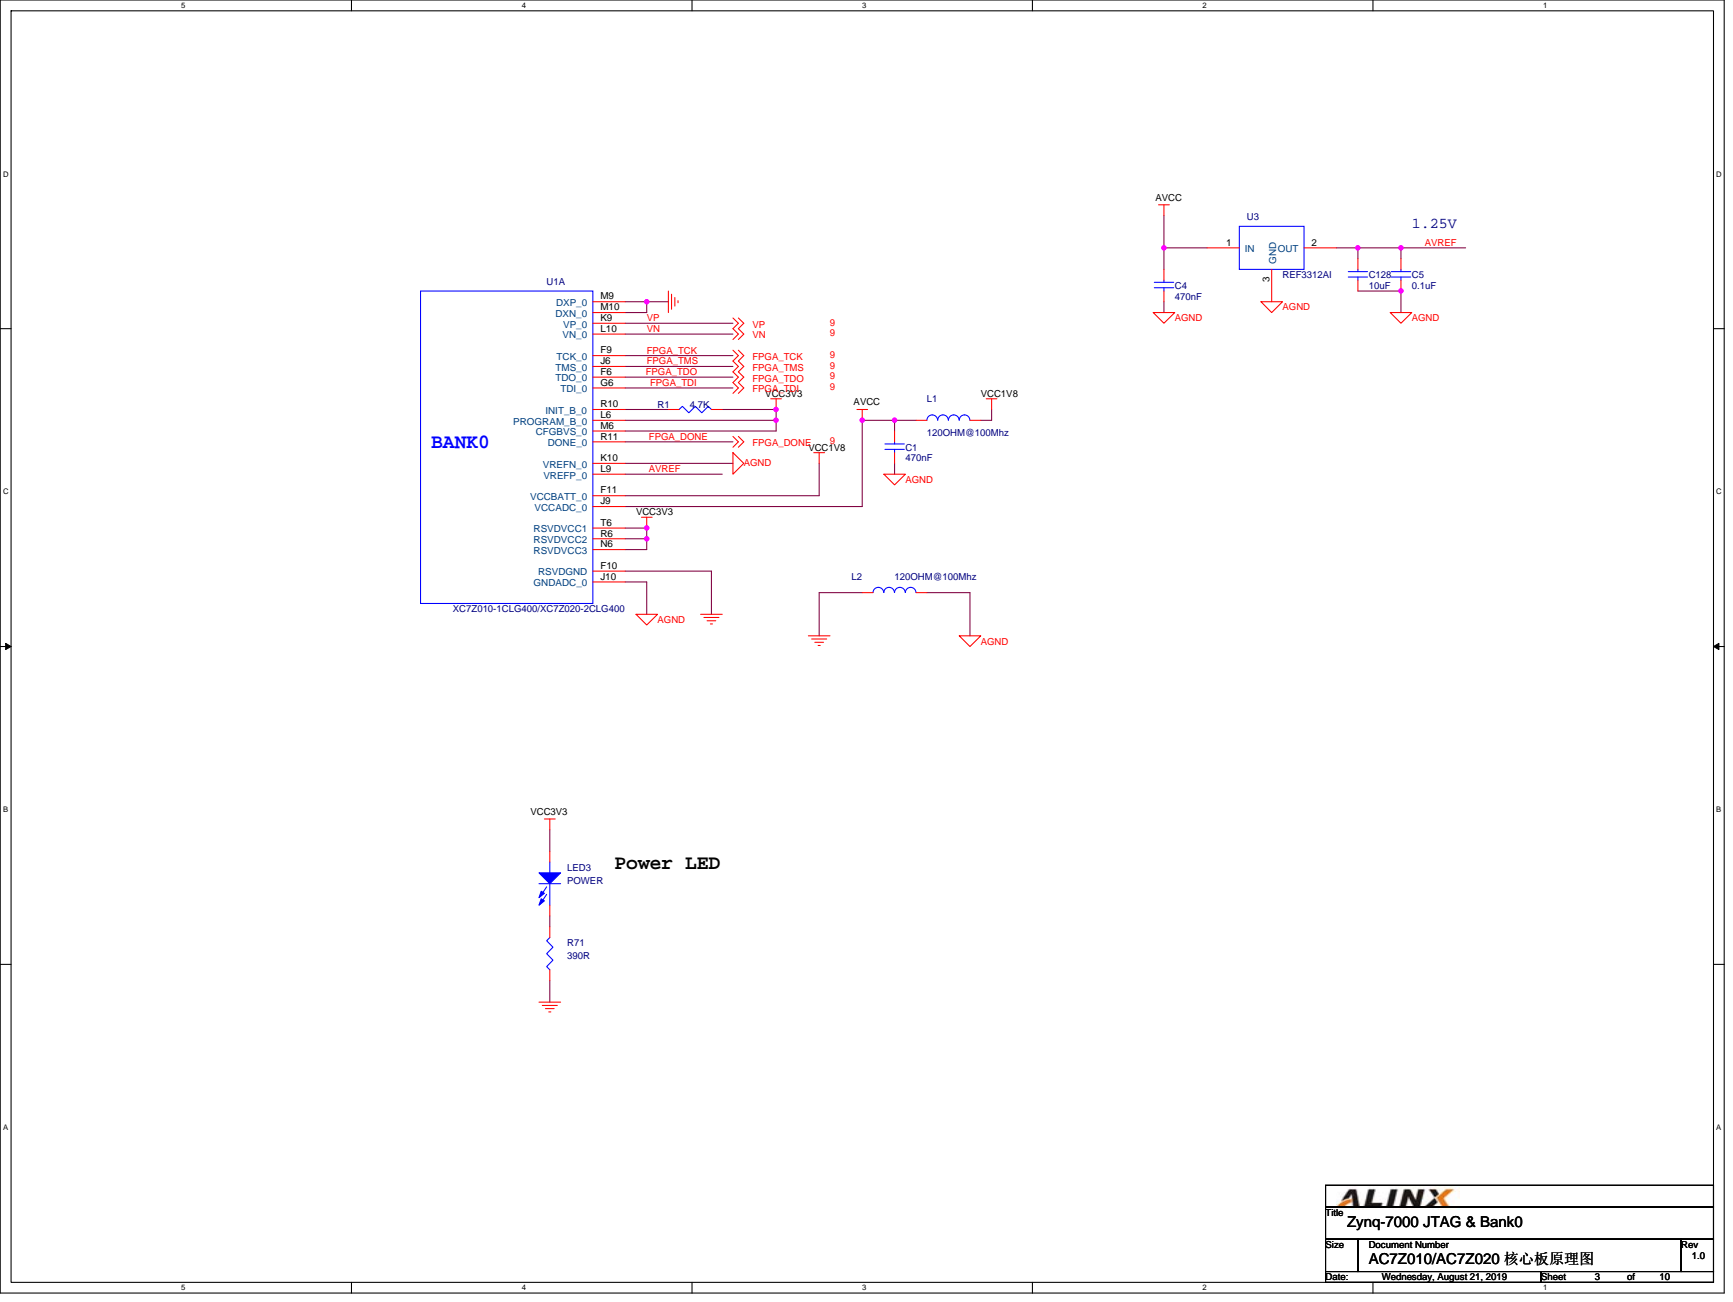
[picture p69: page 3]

# VCC3V3

## MIO[8] =1 ----MIO bank501 voltage=1.8V

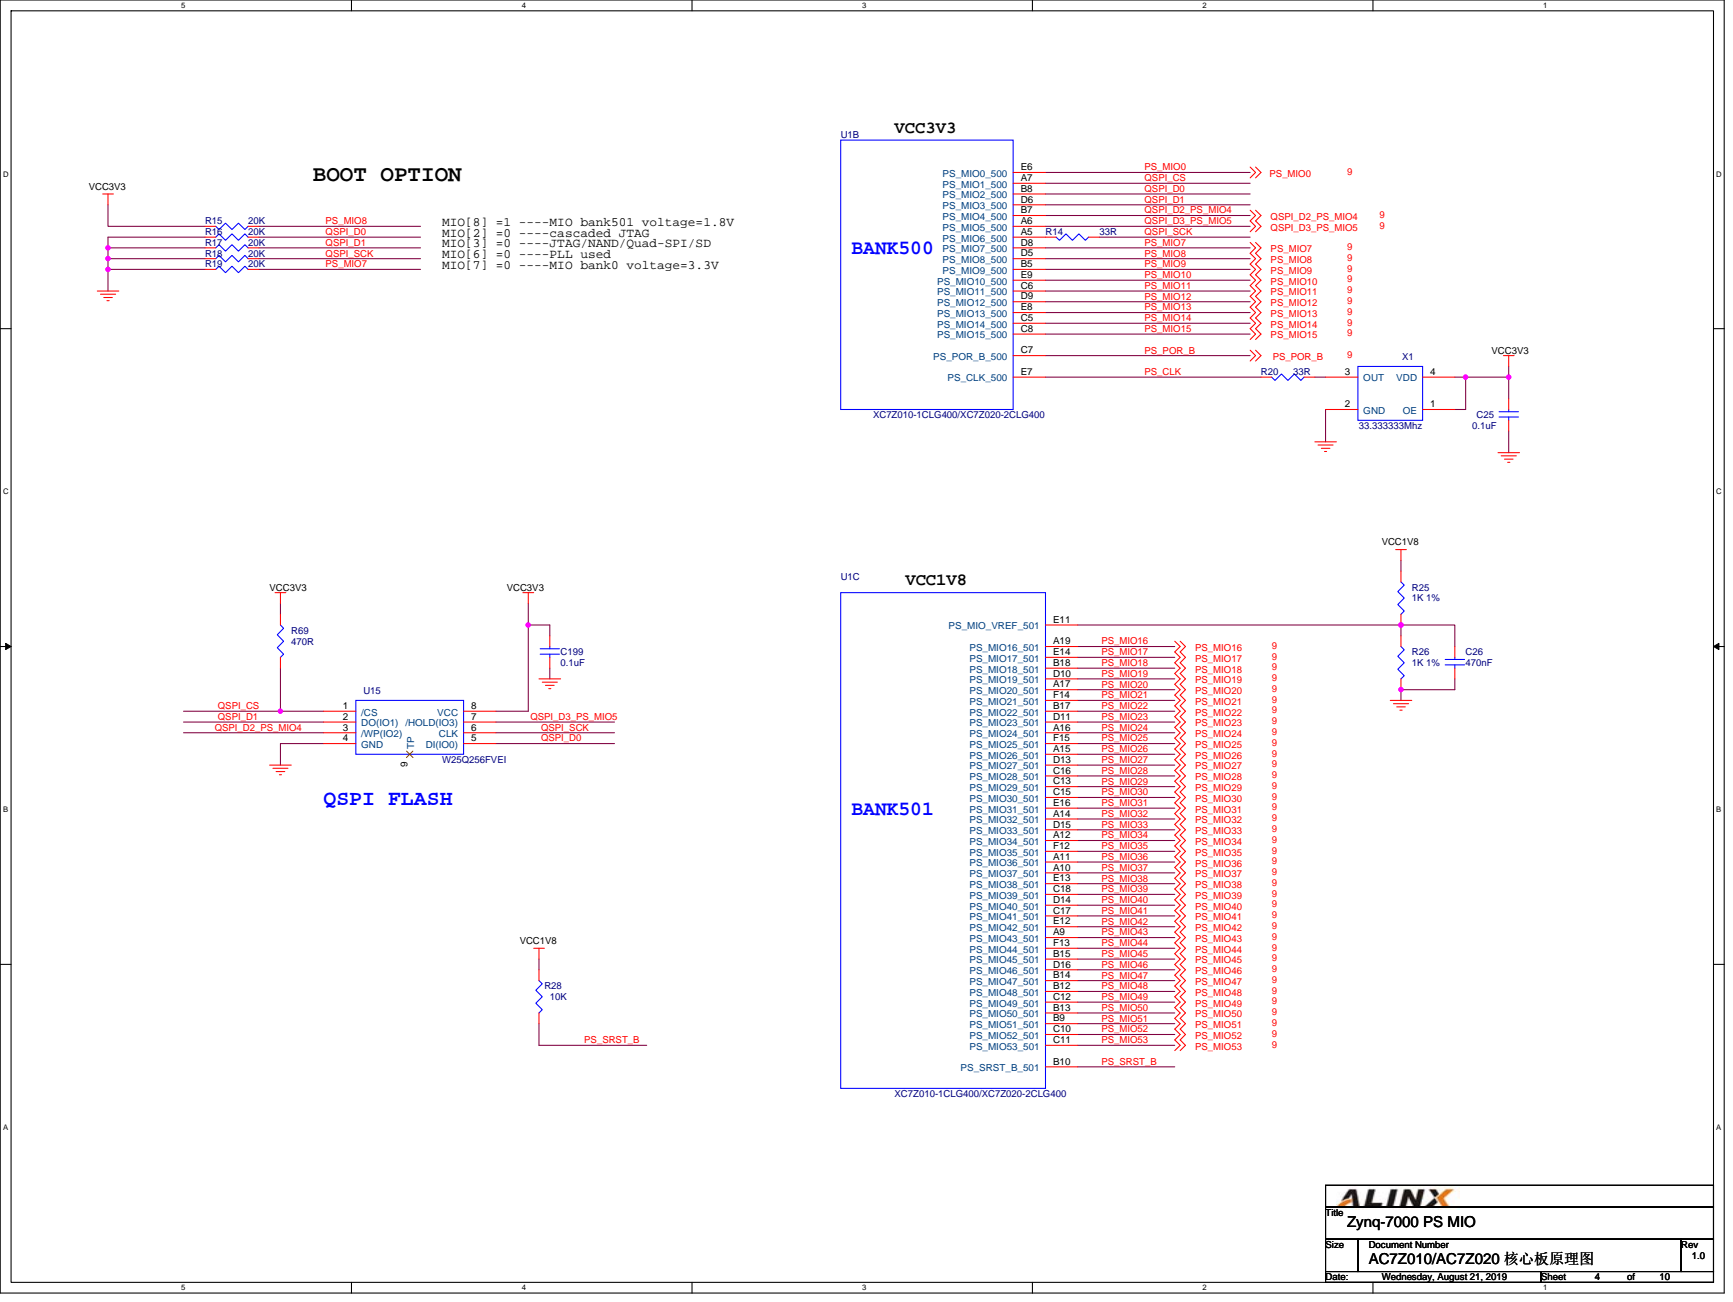
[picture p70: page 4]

MIO[2] =0 ----cascaded JTAG
MIO[3] =0 ----JTAG/NAND/Quad-SPI/SD
MIO[6] =0 ----PLL used
MIO[7] =0 ----MIO bank0 voltage=3.3V

# VCCIO34

## BANK34

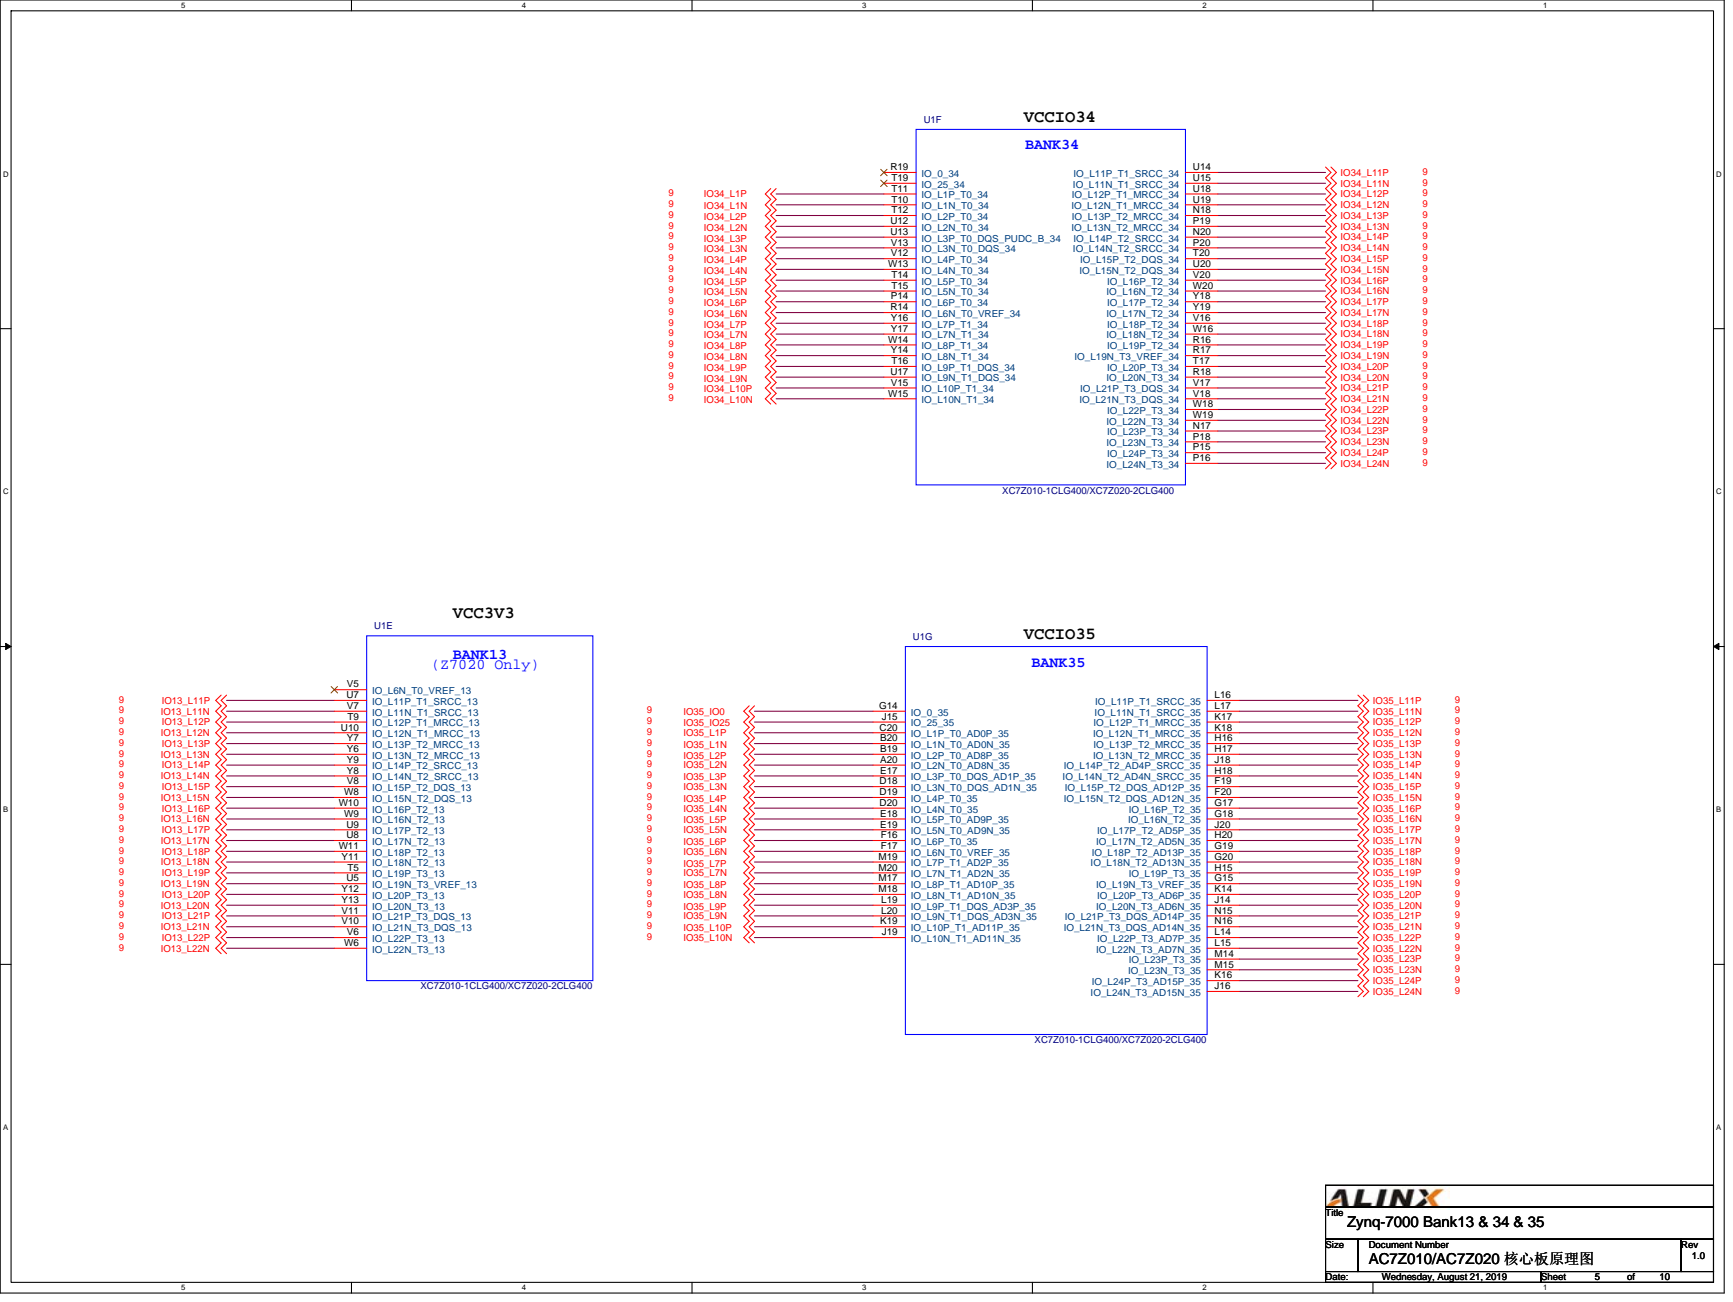
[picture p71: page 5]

# BANK502

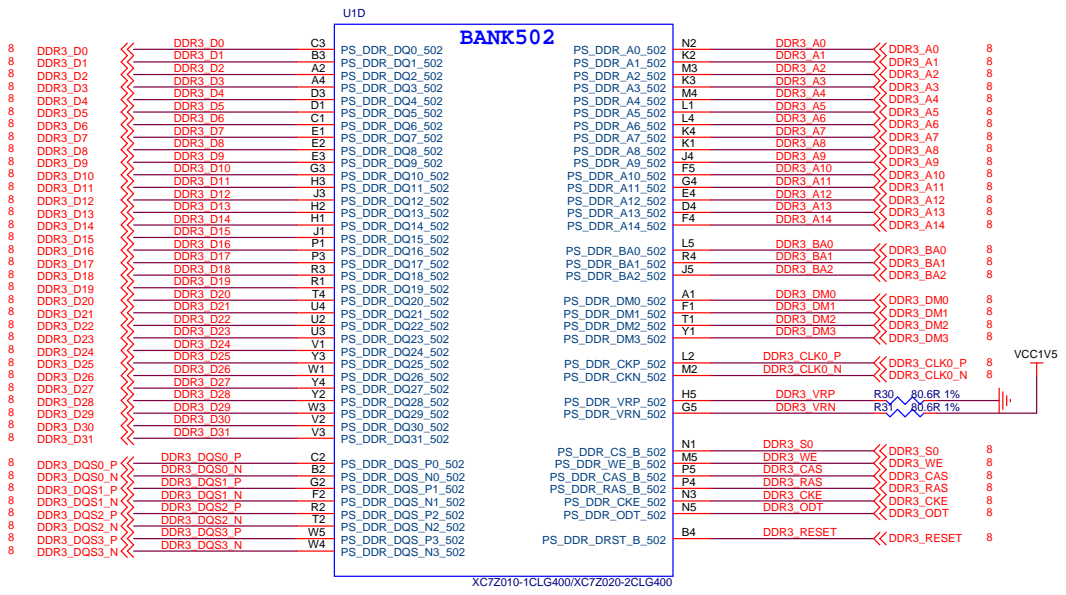
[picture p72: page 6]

# VCCINT

# VCC_AUX

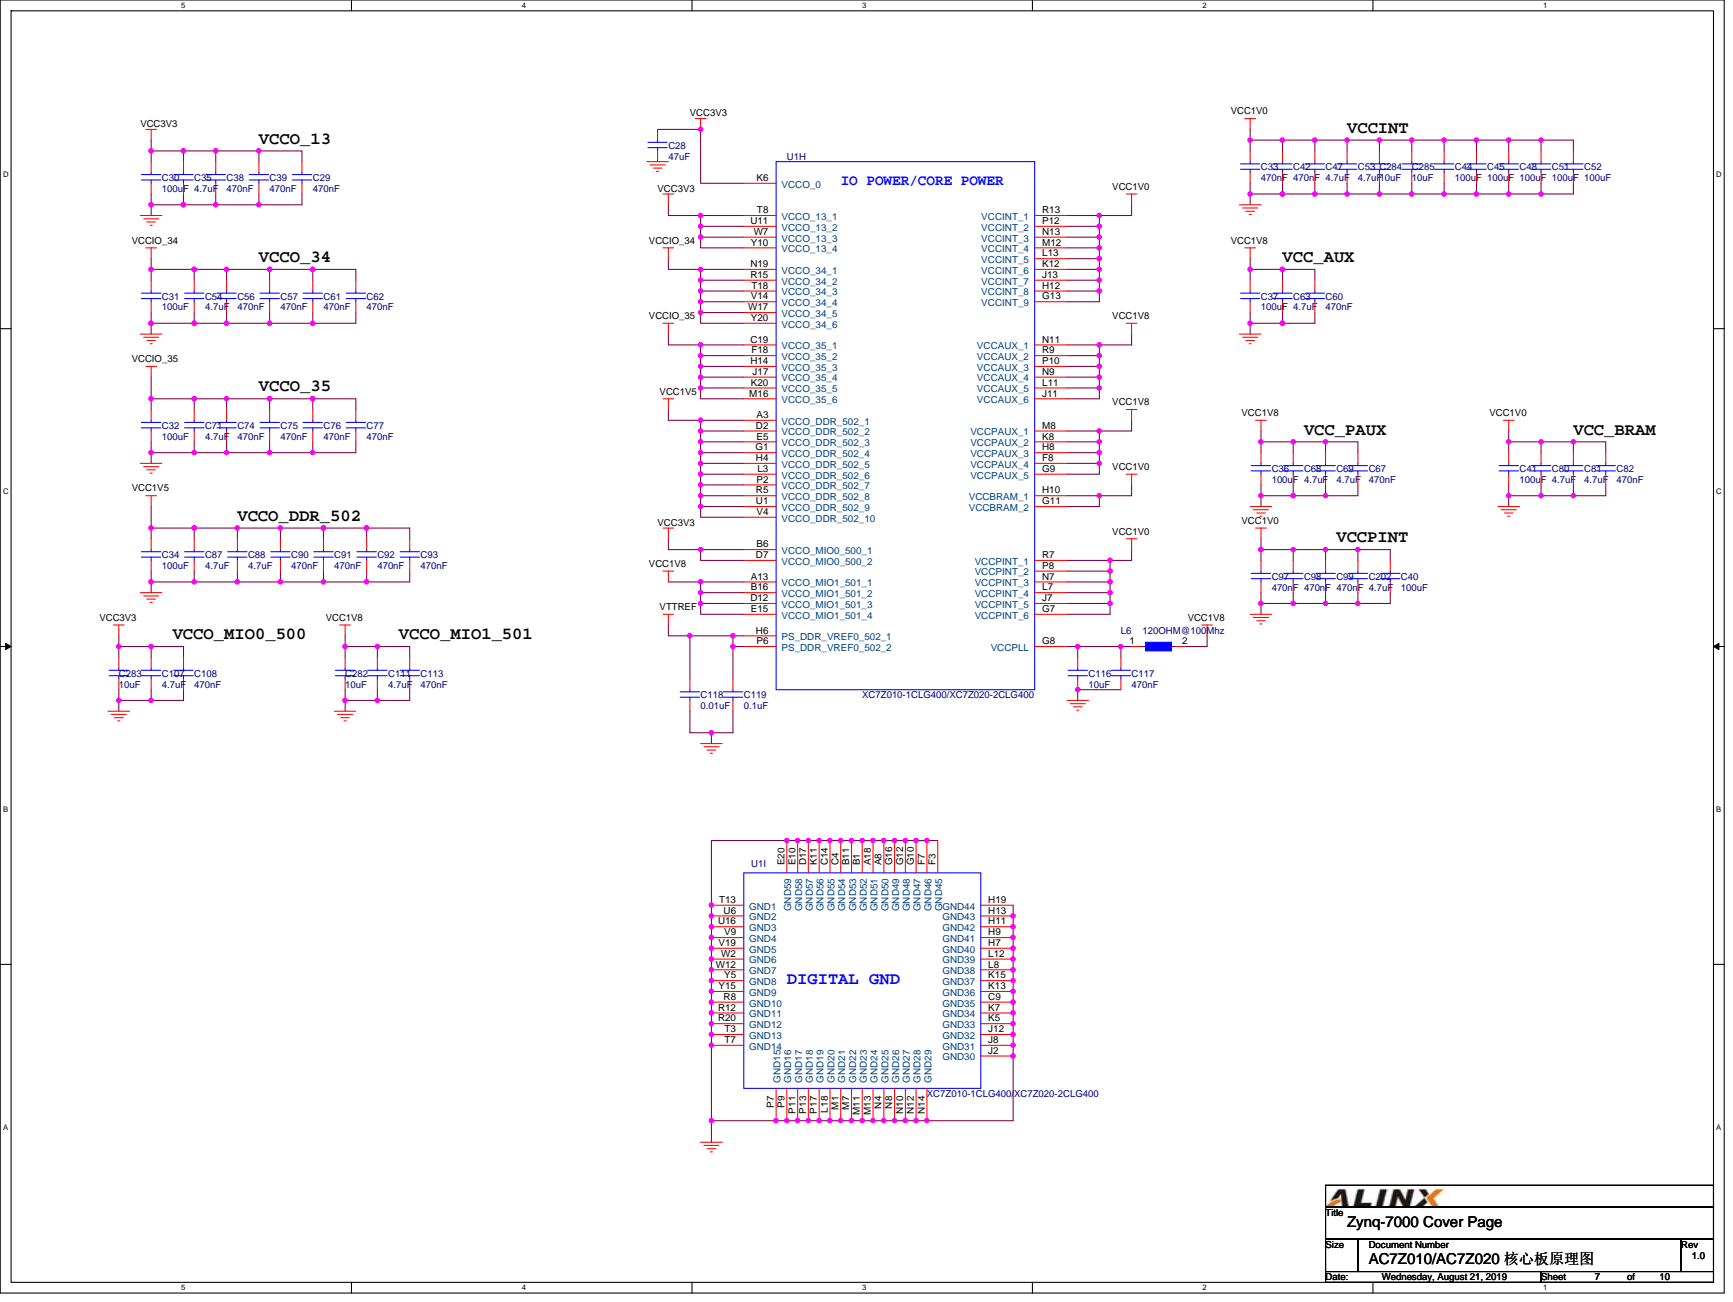
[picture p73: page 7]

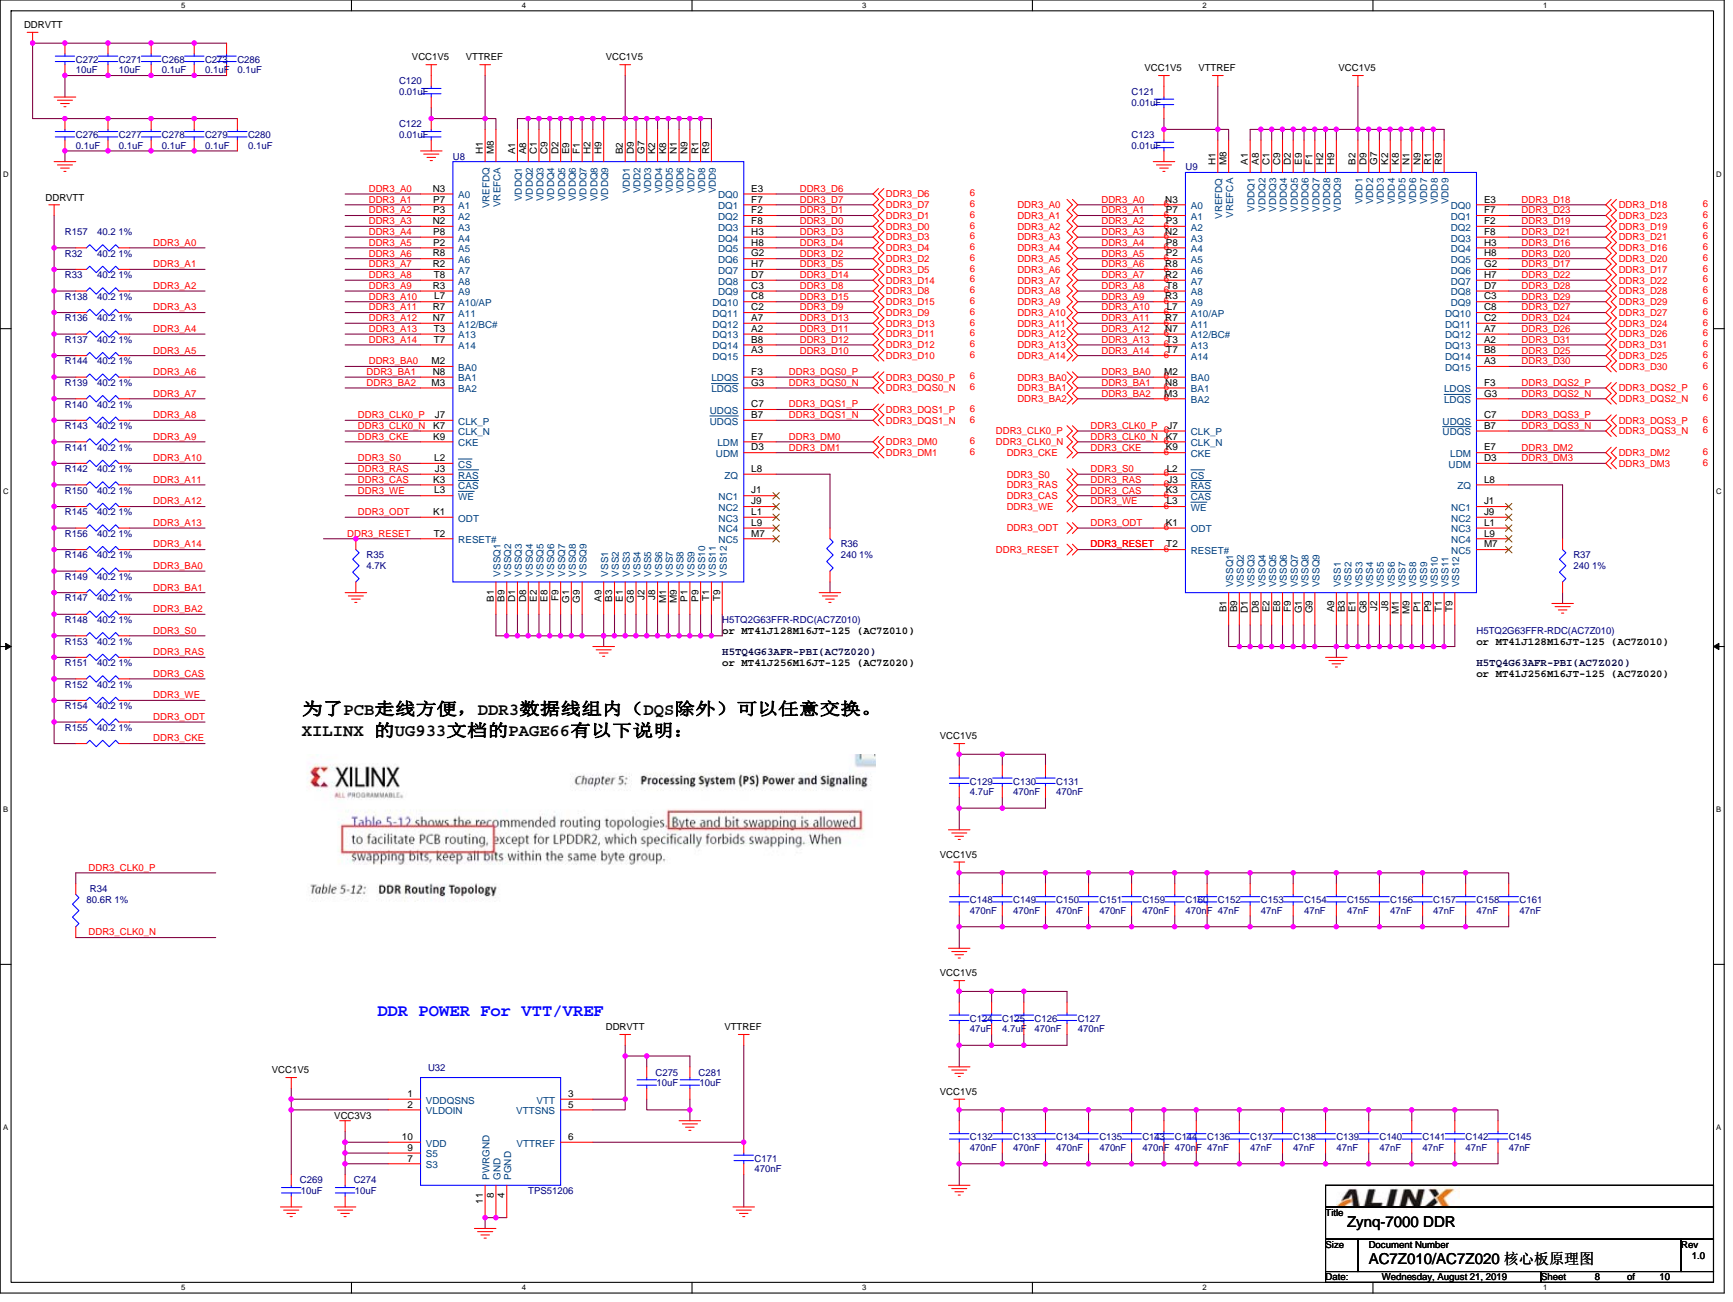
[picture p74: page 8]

DDR POWER For VTT/VREF

# VCCIO34, VCCIO35的电源由底板提供，不能超过3.3V，上电顺序要求5V先供电，然后再供VCCIO34和VCCIO35

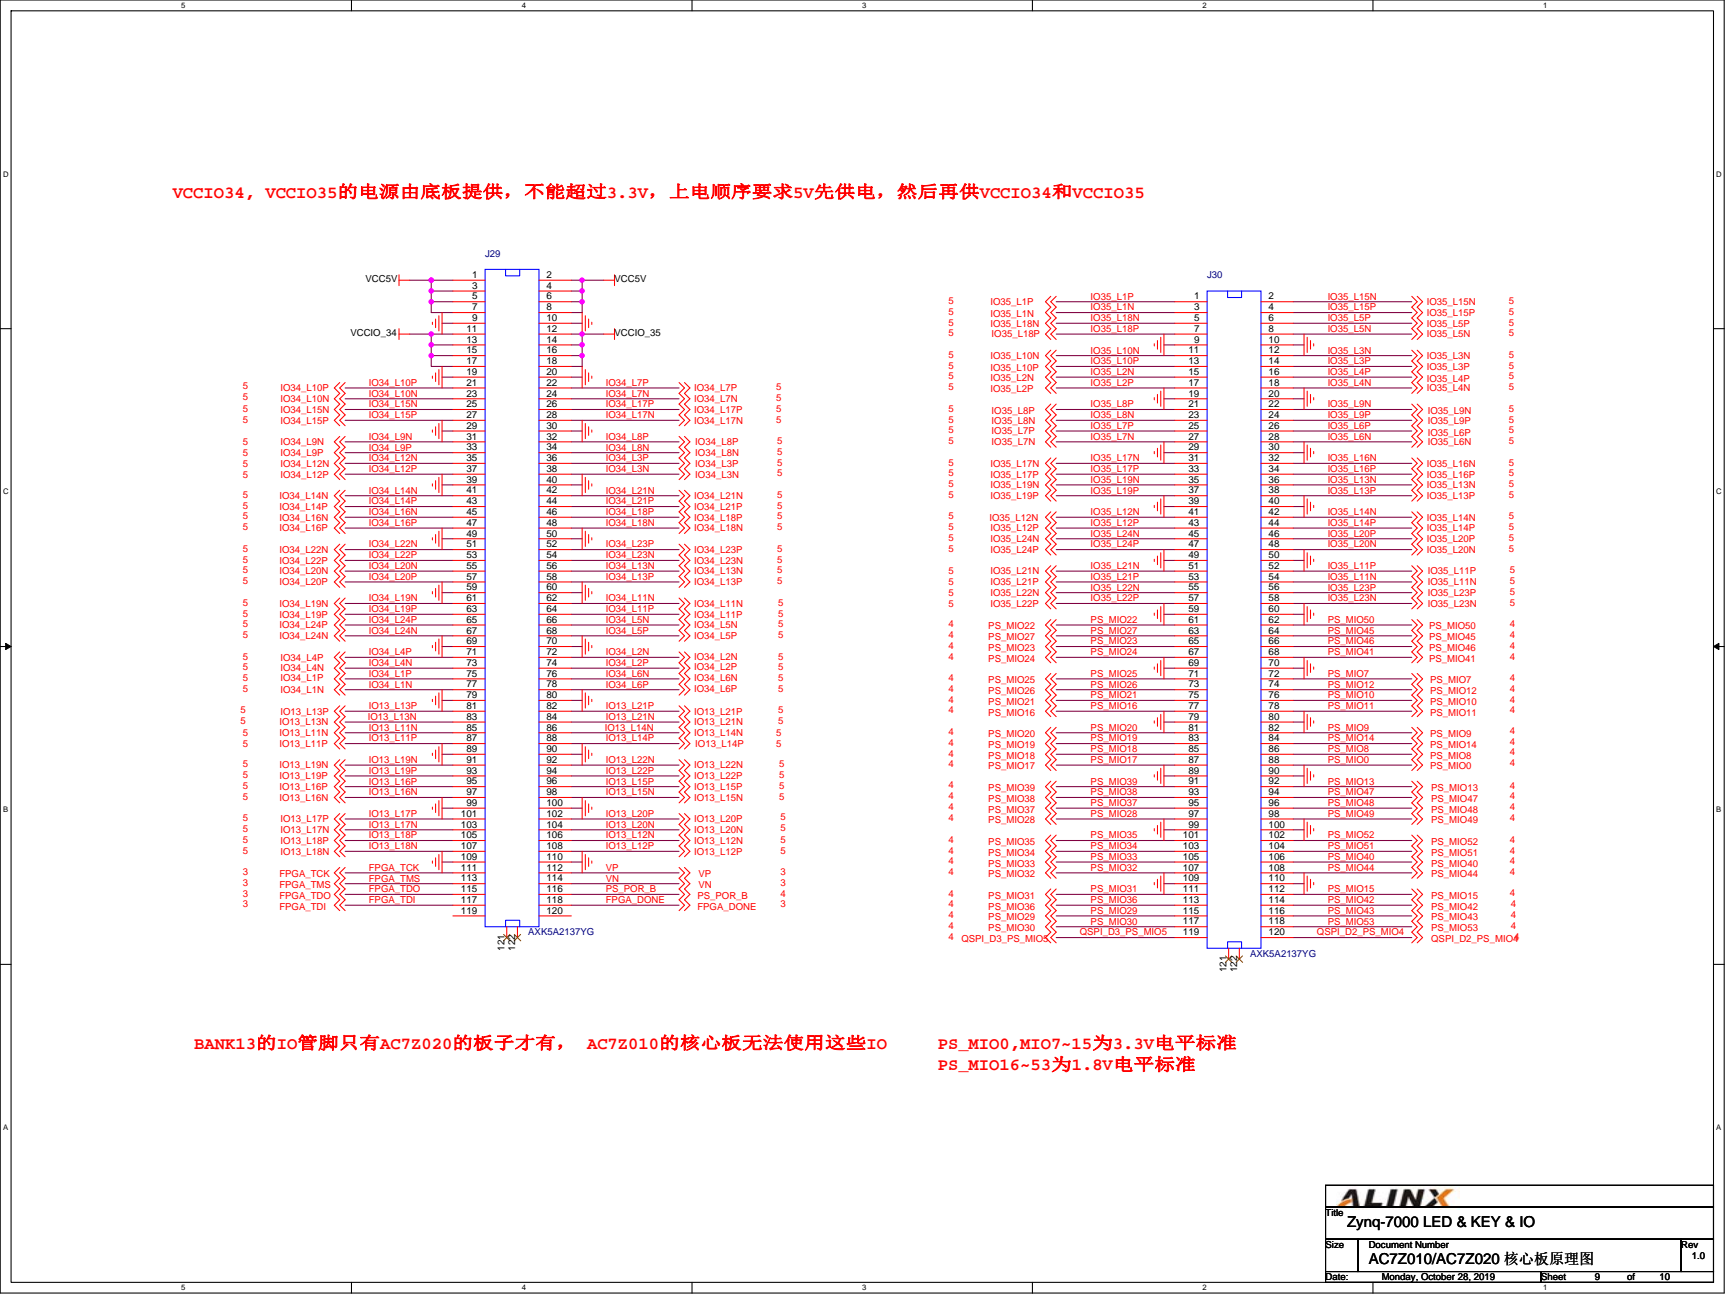
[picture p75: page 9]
BANK13的IO管脚只有AC7Z020的板子才有， AC7Z010的核心板无法使用这些IO; PS_MIO0,MIO7~15为3.3V电平标准; PS_MIO16~53为1.8V电平标准; FPGA_TMS FPGA_TDO FPGA_TDI; FPGA_TCK; FPGA_DONE; PS_POR_B; PS_MIO22 PS_MIO27 PS_MIO23 PS_MIO24; PS_MIO25 PS_MIO26; PS_MIO39 PS_MIO38 PS_MIO37 PS_MIO28; PS_MIO35 PS_MIO34 PS_MIO33 PS_MIO32; PS_MIO31 PS_MIO36 PS_MIO29 PS_MIO30 QSPI_D3_PS_MIO5; PS_MIO50; PS_MIO46; PS_MIO45; PS_MIO41; PS_MIO10; PS_MIO12; PS_MIO7; PS_MIO11; PS_MIO8; PS_MIO14; PS_MIO9; PS_MIO0; PS_MIO48; PS_MIO47; PS_MIO13; PS_MIO49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

9 | | 10
11 | | 12

Zynq-7000 LED & KEY & IO

# 1.8V POWER

# 1.0V POWER

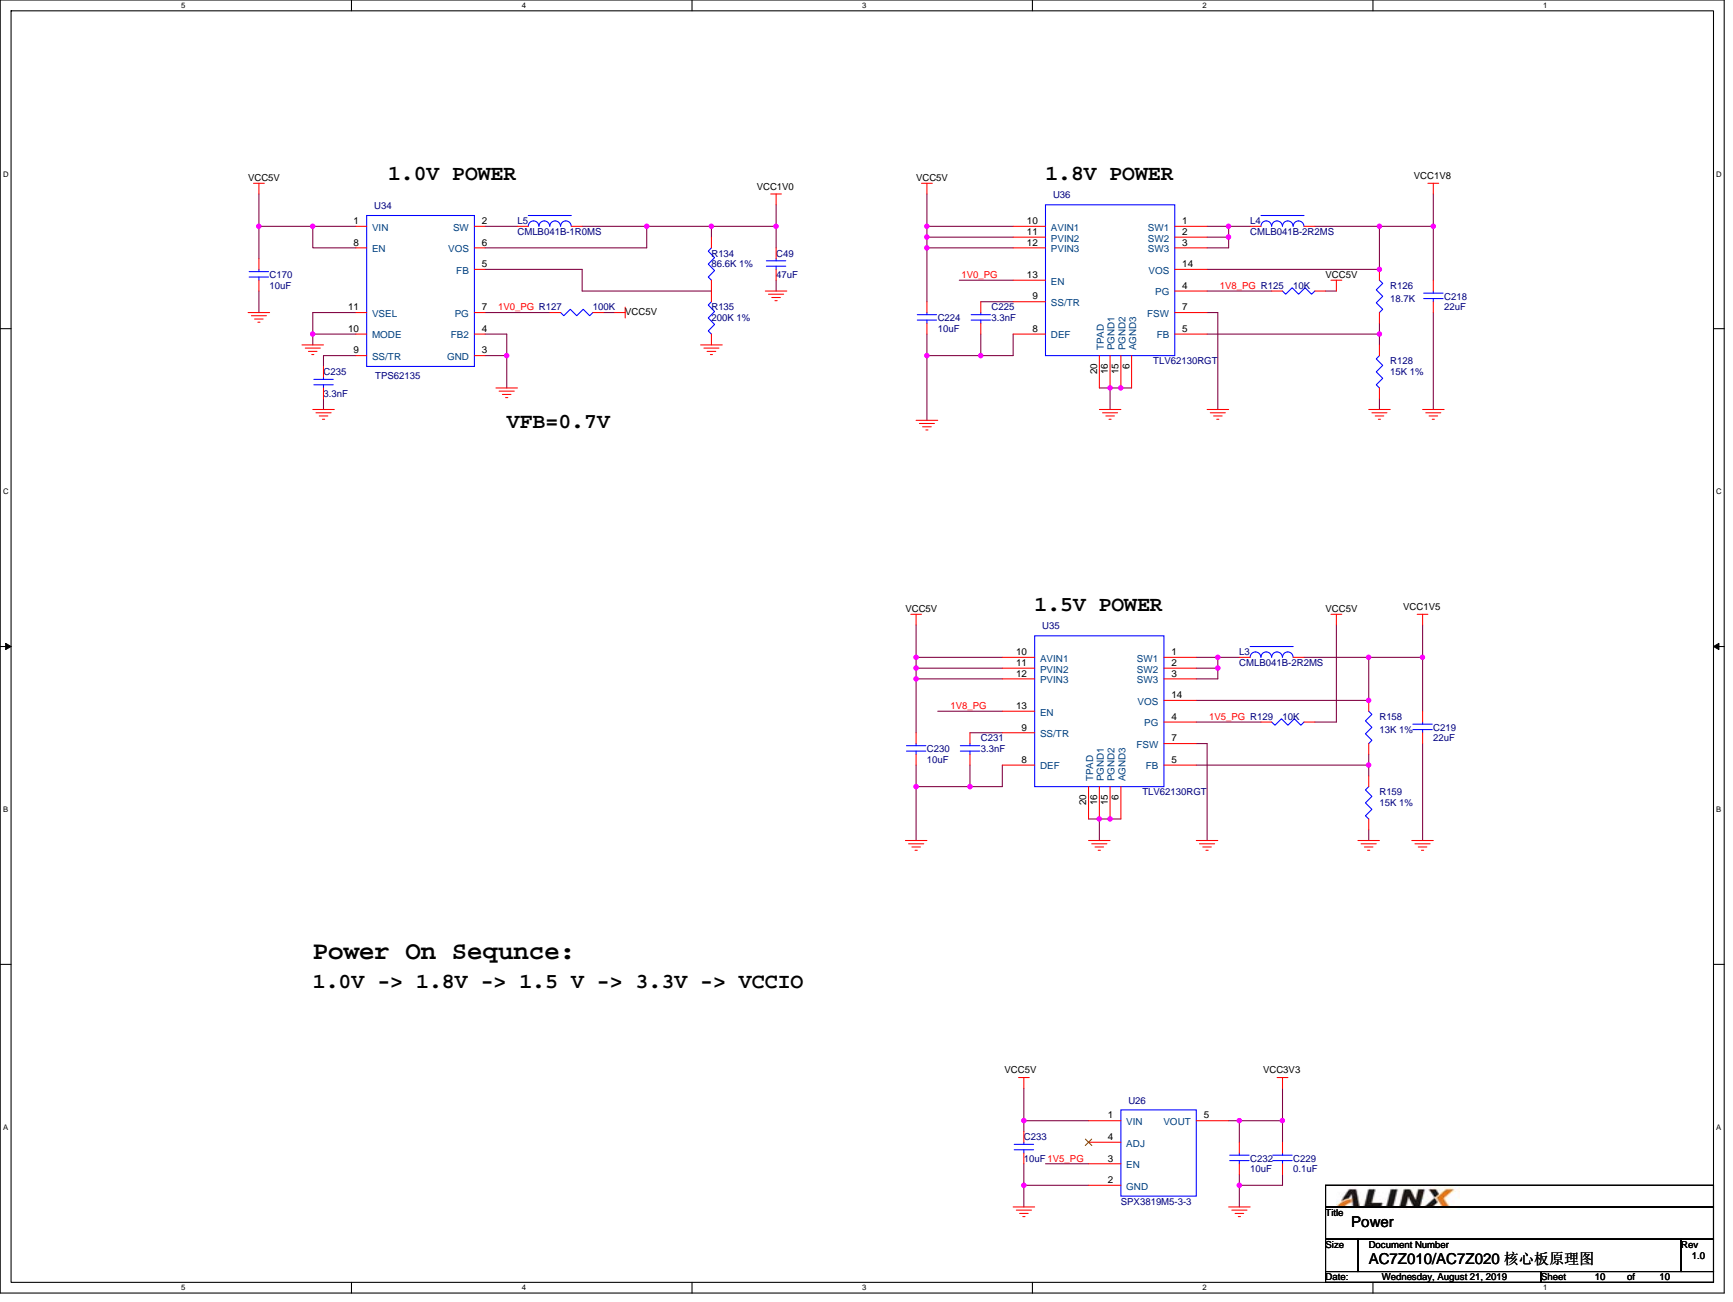
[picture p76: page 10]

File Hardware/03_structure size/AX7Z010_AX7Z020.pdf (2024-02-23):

82 mm

90 mm

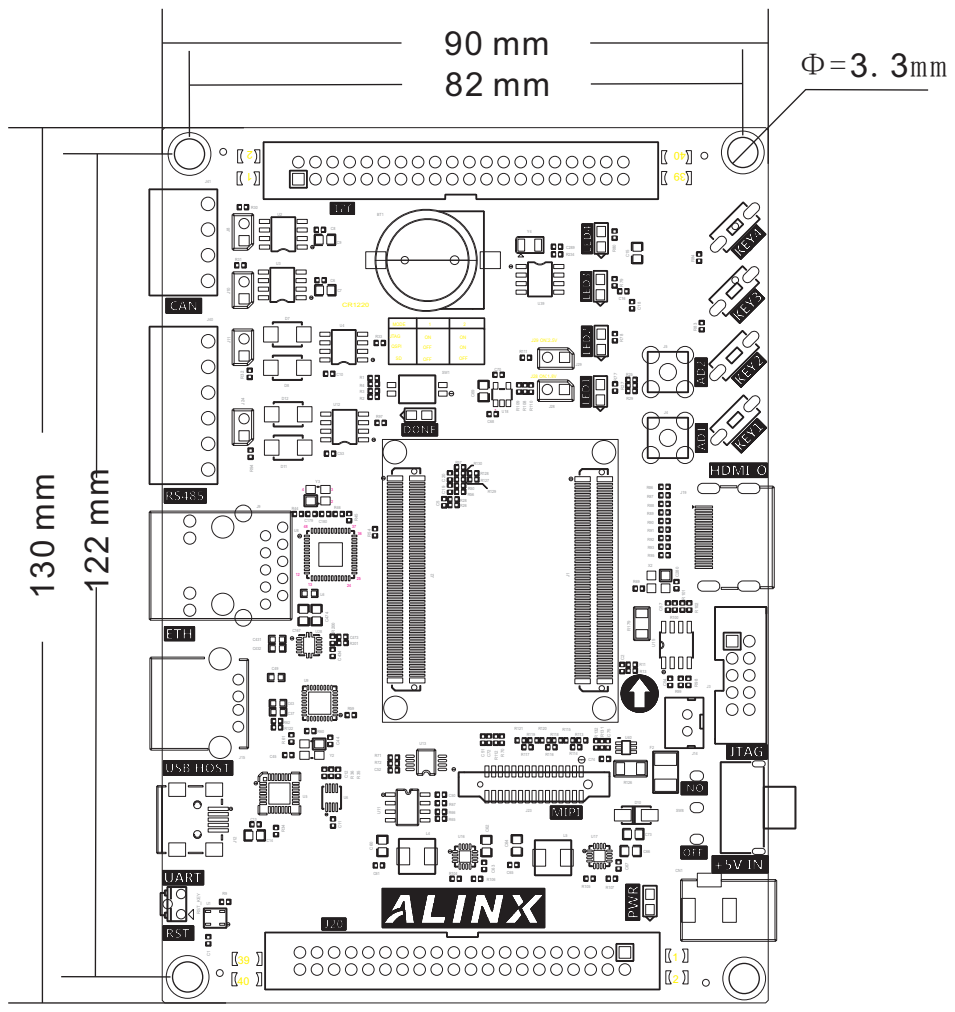
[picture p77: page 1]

MODE | 1 | 2

JTAG QSPI SD | ON OFF OFF | ON ON OFF

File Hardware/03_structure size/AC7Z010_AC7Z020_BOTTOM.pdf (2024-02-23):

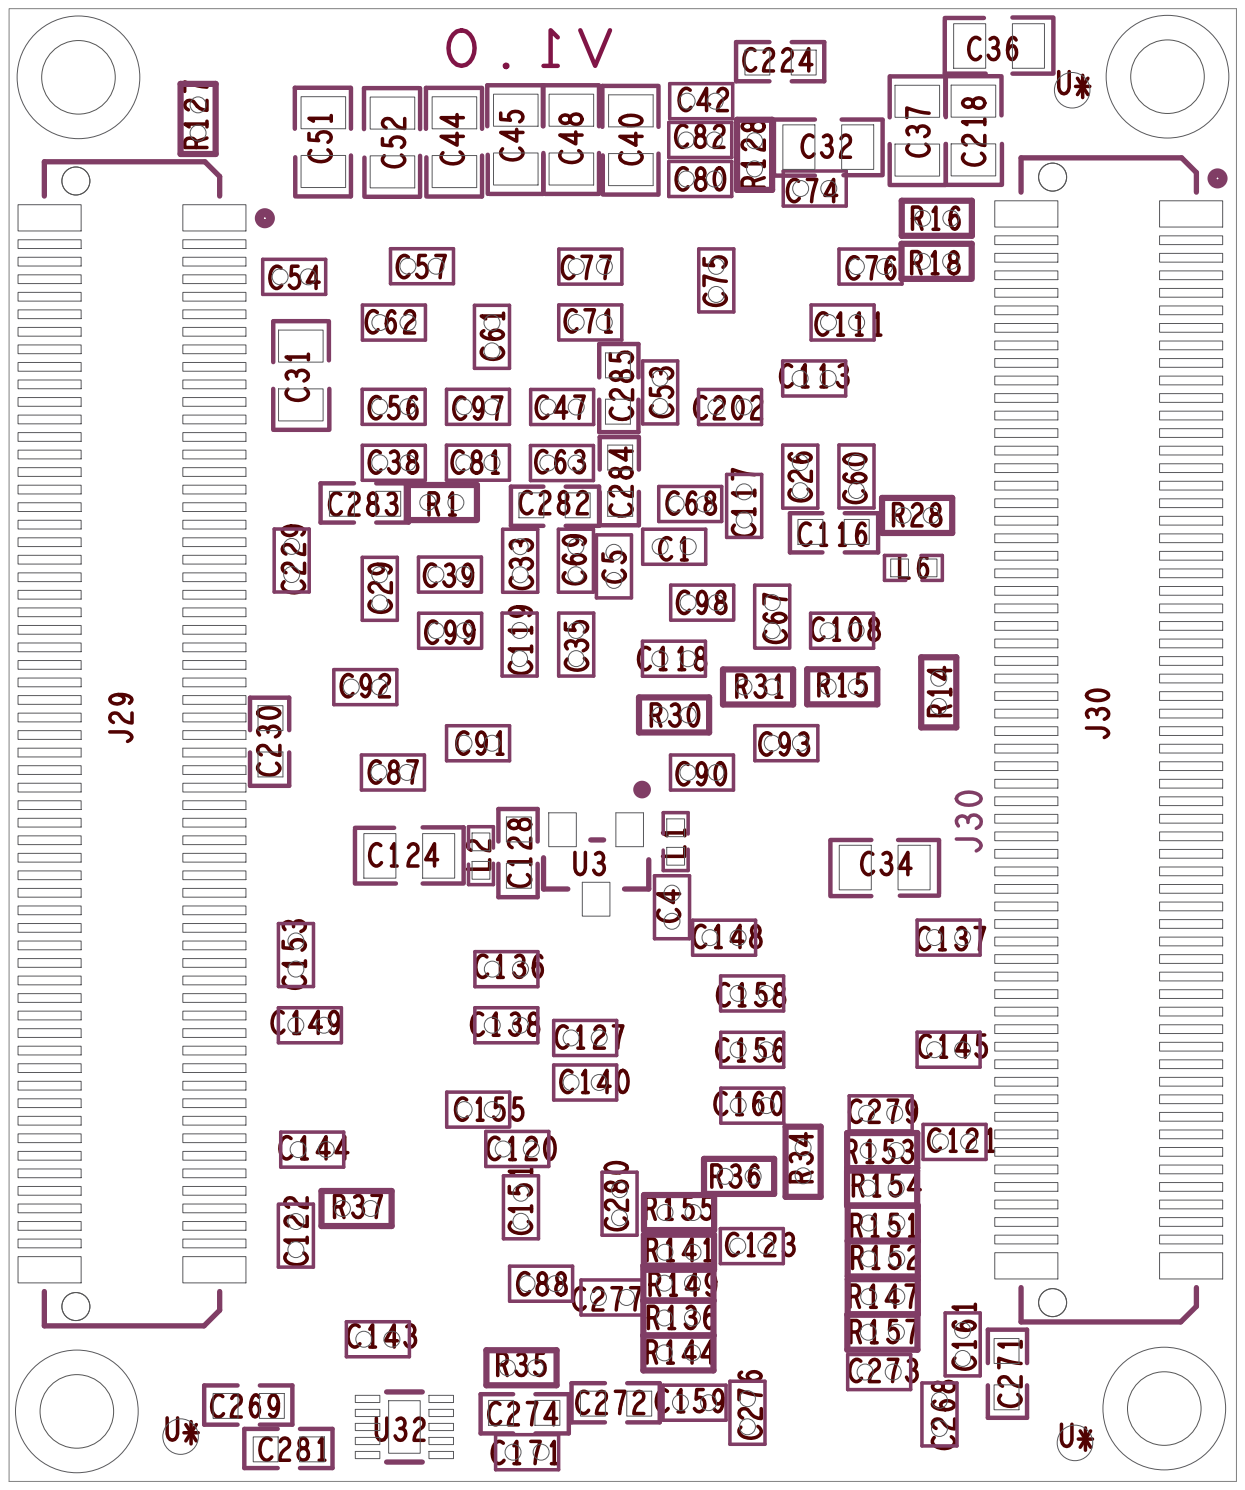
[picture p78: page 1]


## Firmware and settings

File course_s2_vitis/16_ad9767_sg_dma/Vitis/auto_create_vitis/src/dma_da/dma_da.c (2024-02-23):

/*
 * dma_pl.c
 *
 *  Created on: 2018Äê7ÔÂ9ÈÕ
 *      Author: Administrator
 */


#include "xaxidma.h"
#include "xparameters.h"
#include "xil_printf.h"
#include "xscugic.h"
#include "xil_exception.h"
#include "ad9767_send.h"
#include "wave.h"
#include "xgpiops.h"
#include "xgpio.h"
#include "dma_bd/dma_bd.h"


/*
 * AD9767 definitions
 */
#define AD9767_CH0_BASE        XPAR_AD9767_SEND_0_S00_AXI_BASEADDR
#define AD9767_CH0_START       AD9767_SEND_S00_AXI_SLV_REG0_OFFSET
#define AD9767_CH0_LENGTH      AD9767_SEND_S00_AXI_SLV_REG1_OFFSET

#define AD9767_CH1_BASE        XPAR_AD9767_SEND_1_S00_AXI_BASEADDR
#define AD9767_CH1_START       AD9767_SEND_S00_AXI_SLV_REG0_OFFSET
#define AD9767_CH1_LENGTH      AD9767_SEND_S00_AXI_SLV_REG1_OFFSET
/*
 * Interrupt definitions
 */
#define INT_DEVICE_ID          XPAR_SCUGIC_SINGLE_DEVICE_ID
/*
 * DMA definitions
 */
#define CH0_MM2S_INTR_ID       XPAR_FABRIC_AXI_DMA_0_MM2S_INTROUT_INTR
#define CH1_MM2S_INTR_ID       XPAR_FABRIC_AXI_DMA_1_MM2S_INTROUT_INTR
#define CH0_DMA_DEV_ID	  	   XPAR_AXI_DMA_0_DEVICE_ID
#define CH1_DMA_DEV_ID	   	   XPAR_AXI_DMA_1_DEVICE_ID
#define CH0_DMA_BASE   	 	   XPAR_AXI_DMA_0_BASEADDR
#define CH1_DMA_BASE   	 	   XPAR_AXI_DMA_1_BASEADDR

#define BD_COUNT          	   4
/*
 * Wave Parameter definitions
 */
#define CH0_MAX_PKT_LEN		   4096		/* must be bigger than 1024, or FIFO will be empty */
#define CH0_MAX_AMP_VAL        16384    /* 2^14, do not change */
#define CH0_AMP_VAL            16384    /* must be less than 2^14 */
#define CH1_MAX_PKT_LEN		   4096		/* must be bigger than 1024, or FIFO will be empty */
#define CH1_MAX_AMP_VAL        16384    /* 2^14, do not change */
#define CH1_AMP_VAL            16384	/* must be less than 2^14 */

#define ADC_BYTE           2
/*
 * PS GPIO definitions
 */
#define MIO_0_ID           XPAR_PS7_GPIO_0_DEVICE_ID
#define PS_KEY_INTR_ID     XPAR_XGPIOPS_0_INTR
#define GPIO_INPUT         0
/*
 * PL GPIO definitions
 */
#define KEY_DEVICE_ID   XPAR_AXI_GPIO_0_DEVICE_ID
#define PL_KEY_INTR_ID 	XPAR_FABRIC_AXI_GPIO_0_IP2INTC_IRPT_INTR
#define KEY_CHANNEL 1

/*
 * variable declaratinons
 */
XScuGic INST ;

XAxiDma Ch0AxiDma;
XAxiDma Ch1AxiDma;

XGpioPs PsGpio ;

XGpio PlGpio ;

volatile int ch0_key_flag = 0 ;
volatile int ch1_key_flag = 0 ;

/*
 * DMA buffer to MM2S
 */
u16 Ch0DmaTxBuffer[CH0_MAX_PKT_LEN] __attribute__ ((aligned(64)));
u16 Ch1DmaTxBuffer[CH1_MAX_PKT_LEN] __attribute__ ((aligned(64)));
/*
 * wave buffer
 */
u16 Ch0WaveBuffer[CH0_MAX_PKT_LEN] __attribute__ ((aligned(64)));
u16 Ch1WaveBuffer[CH1_MAX_PKT_LEN] __attribute__ ((aligned(64)));
/*
 * BD buffer
 */
u32 Ch0BdTxChainBuffer[BD_ALIGNMENT*16] __attribute__ ((aligned(64)));
u32 Ch1BdTxChainBuffer[BD_ALIGNMENT*16] __attribute__ ((aligned(64)));

/*
 * Function definitions
 */
void XAxiDma_DAC();
int XAxiDma_Initial(u16 DeviceId, u16 IntrID, XAxiDma *XAxiDma, XScuGic *InstancePtr) ;
int SetInterruptInit(XScuGic *InstancePtr, u16 IntID) ;
void DAC_Interrupt_Handler(void *CallBackRef) ;
int PsKeySetup(XScuGic *InstancePtr, u16 IntrID, XGpioPs *GpioInstancePtr) ;
int PLKeySetup(XScuGic *InstancePtr, u16 IntrID, XGpio *GpioInstancePtr) ;
void PsGpioHandler(void *CallbackRef);
void PlGpioHandler(void *CallbackRef) ;
void wave_switch(int wave_sel, int pkg_len, int max_amp_val, int amp_val, u16 *wave_buffer) ;




int main()
{
	int Status;

	Status = SetInterruptInit(&INST, INT_DEVICE_ID) ;
	if (Status != XST_SUCCESS)
		return XST_FAILURE ;

	PsKeySetup(&INST, PS_KEY_INTR_ID, &PsGpio) ;

	PLKeySetup(&INST, PL_KEY_INTR_ID, &PlGpio) ;

	XAxiDma_DAC();

	return XST_SUCCESS;

}



void XAxiDma_DAC()
{
	int ch0_wave_sel = 0;
	int ch1_wave_sel = 0;

	int i ;
	/* Initialize DMA and enable MM2S interrupt */
	XAxiDma_Initial(CH0_DMA_DEV_ID, CH0_MM2S_INTR_ID, &Ch0AxiDma, &INST) ;
	XAxiDma_Initial(CH1_DMA_DEV_ID, CH1_MM2S_INTR_ID, &Ch1AxiDma, &INST) ;
	/* Create initial wave data */
	wave_switch(ch0_wave_sel, CH0_MAX_PKT_LEN, CH0_MAX_AMP_VAL, CH0_AMP_VAL, Ch0WaveBuffer) ;
	wave_switch(ch1_wave_sel, CH1_MAX_PKT_LEN, CH1_MAX_AMP_VAL, CH1_AMP_VAL, Ch1WaveBuffer) ;
	/* Copy wave data to DMA buffer */
	memcpy(Ch0DmaTxBuffer, Ch0WaveBuffer, ADC_BYTE*CH0_MAX_PKT_LEN) ;
	Xil_DCacheFlushRange((UINTPTR)Ch0DmaTxBuffer, ADC_BYTE*CH0_MAX_PKT_LEN);

	memcpy(Ch1DmaTxBuffer, Ch1WaveBuffer, ADC_BYTE*CH1_MAX_PKT_LEN) ;
	Xil_DCacheFlushRange((UINTPTR)Ch1DmaTxBuffer, ADC_BYTE*CH1_MAX_PKT_LEN);
	/*
	 * Start AD9767 sample
	 */
	AD9767_SEND_mWriteReg(AD9767_CH0_BASE, AD9767_CH0_START, 1) ;
	AD9767_SEND_mWriteReg(AD9767_CH1_BASE, AD9767_CH1_START, 1) ;

	/*
	 * Create BD and Start
	 */
	CreateBdChain(Ch0BdTxChainBuffer, BD_COUNT, ADC_BYTE*CH0_MAX_PKT_LEN, (u8 *)Ch0DmaTxBuffer, TXPATH) ;
	Bd_Start(Ch0BdTxChainBuffer, BD_COUNT, &Ch0AxiDma, TXPATH) ;

	CreateBdChain(Ch1BdTxChainBuffer, BD_COUNT, ADC_BYTE*CH1_MAX_PKT_LEN, (u8 *)Ch1DmaTxBuffer, TXPATH) ;
	Bd_Start(Ch1BdTxChainBuffer, BD_COUNT, &Ch1AxiDma, TXPATH) ;


	while(1)
	{
		if (ch0_key_flag)
		{
			if (ch0_wave_sel == 4)
				ch0_wave_sel = 0 ;
			else
				ch0_wave_sel++ ;

			wave_switch(ch0_wave_sel, CH0_MAX_PKT_LEN, CH0_MAX_AMP_VAL, CH0_AMP_VAL, Ch0WaveBuffer) ;

			memcpy(Ch0DmaTxBuffer, Ch0WaveBuffer, ADC_BYTE*CH0_MAX_PKT_LEN) ;
			Xil_DCacheFlushRange((UINTPTR)Ch0DmaTxBuffer, ADC_BYTE*CH0_MAX_PKT_LEN);

			/* Clear flag */
			ch0_key_flag = 0 ;
		}


		if (ch1_key_flag)
		{
			if (ch1_wave_sel == 4)
				ch1_wave_sel = 0 ;
			else
				ch1_wave_sel++ ;

			wave_switch(ch1_wave_sel, CH1_MAX_PKT_LEN, CH1_MAX_AMP_VAL, CH1_AMP_VAL, Ch1WaveBuffer) ;

			memcpy(Ch1DmaTxBuffer, Ch1WaveBuffer, ADC_BYTE*CH1_MAX_PKT_LEN) ;
			Xil_DCacheFlushRange((UINTPTR)Ch1DmaTxBuffer, ADC_BYTE*CH1_MAX_PKT_LEN);

			/* Clear flag */
			ch1_key_flag = 0 ;
		}

	}
}

/*
 * switch wave
 */
void wave_switch(int wave_sel, int pkg_len, int max_amp_val, int amp_val, u16 *wave_buffer)
{
	switch(wave_sel)
	{
	case 0 : GetSinWave(pkg_len, max_amp_val, amp_val, wave_buffer) ; break ;
	case 1 : GetSquareWave(pkg_len, max_amp_val, amp_val, wave_buffer) ; break ;
	case 2 : GetTriangleWave(pkg_len, max_amp_val, amp_val, wave_buffer) ; break ;
	case 3 : GetSawtoothWave(pkg_len, max_amp_val, amp_val, wave_buffer) ; break ;
	case 4 : GetSubSawtoothWave(pkg_len, max_amp_val, amp_val, wave_buffer) ; break ;
	default: GetSinWave(pkg_len, max_amp_val, amp_val, wave_buffer) ; break ;
	}
}

/*
 * Set up PS key and enable GPIO interrupt
 */
int PsKeySetup(XScuGic *InstancePtr, u16 IntrID, XGpioPs *GpioInstancePtr)
{
	XGpioPs_Config *GPIO_CONFIG ;
	int Status ;

	GPIO_CONFIG = XGpioPs_LookupConfig(MIO_0_ID) ;
	Status = XGpioPs_CfgInitialize(GpioInstancePtr, GPIO_CONFIG, GPIO_CONFIG->BaseAddr) ;
	if (Status != XST_SUCCESS)
	{
		return XST_FAILURE ;
	}
	//set MIO 54 as input
	XGpioPs_SetDirectionPin(GpioInstancePtr, 54, GPIO_INPUT) ;
	//set interrupt type
	XGpioPs_SetIntrTypePin(GpioInstancePtr, 54, XGPIOPS_IRQ_TYPE_EDGE_RISING) ;


	//set priority and trigger type
	XScuGic_SetPriorityTriggerType(InstancePtr, IntrID,
			0xA0, 0x3);
	Status = XScuGic_Connect(InstancePtr, IntrID,
			(Xil_ExceptionHandler)PsGpioHandler,
			(void *)GpioInstancePtr) ;

	XScuGic_Enable(InstancePtr, IntrID) ;

	if (Status != XST_SUCCESS) {
		return Status;
	}


	XGpioPs_IntrEnablePin(GpioInstancePtr, 54) ;

	return XST_SUCCESS ;
}

/*
 * Set up PL key and enable GPIO interrupt
 */
int PLKeySetup(XScuGic *InstancePtr, u16 IntrID, XGpio *GpioInstancePtr)
{
	int Status ;

	/* initial gpio key */
	Status = XGpio_Initialize(GpioInstancePtr, KEY_DEVICE_ID) ;
	if (Status != XST_SUCCESS)
		return XST_FAILURE ;

	/* set key as input */
	XGpio_SetDataDirection(GpioInstancePtr, KEY_CHANNEL, 0x1);


	/* Enable key interrupt */
	XGpio_InterruptGlobalEnable(GpioInstancePtr) ;
	XGpio_InterruptEnable(GpioInstancePtr, XGPIO_IR_CH1_MASK) ;

	Status = XScuGic_Connect(InstancePtr, IntrID,
			(Xil_ExceptionHandler)PlGpioHandler,
			(void *)GpioInstancePtr) ;

	XScuGic_Enable(InstancePtr, IntrID) ;

	return XST_SUCCESS ;
}


/*
 * Initial DMA and enable MM2S interrupt
 */
int XAxiDma_Initial(u16 DeviceId, u16 IntrID, XAxiDma *XAxiDma, XScuGic *InstancePtr)
{
	XAxiDma_Config *CfgPtr;
	int Status;
	/* Initialize the XAxiDma device. */
	CfgPtr = XAxiDma_LookupConfig(DeviceId);
	if (!CfgPtr) {
		xil_printf("No config found for %d\r\n", DeviceId);
		return XST_FAILURE;
	}

	Status = XAxiDma_CfgInitialize(XAxiDma, CfgPtr);
	if (Status != XST_SUCCESS) {
		xil_printf("Initialization failed %d\r\n", Status);
		return XST_FAILURE;
	}

	Status = XScuGic_Connect(InstancePtr, IntrID,
			(Xil_ExceptionHandler)DAC_Interrupt_Handler,
			(void *)XAxiDma) ;

	if (Status != XST_SUCCESS) {
		return Status;
	}

	XScuGic_Enable(InstancePtr, IntrID);


	/* Disable S2MM interrupt, Enable MM2S interrupt */
	XAxiDma_IntrDisable(XAxiDma, XAXIDMA_IRQ_ALL_MASK,
			XAXIDMA_DEVICE_TO_DMA);
	XAxiDma_IntrEnable(XAxiDma, XAXIDMA_IRQ_IOC_MASK,
			XAXIDMA_DMA_TO_DEVICE);

	return XST_SUCCESS ;
}

/*
 * Initial interrupt GIC
 */
int SetInterruptInit(XScuGic *InstancePtr, u16 IntID)
{

	XScuGic_Config * Config ;
	int Status ;

	Config = XScuGic_LookupConfig(IntID) ;

	Status = XScuGic_CfgInitialize(&INST, Config, Config->CpuBaseAddress) ;
	if (Status != XST_SUCCESS)
		return XST_FAILURE ;


	Xil_ExceptionInit();
	Xil_ExceptionRegisterHandler(XIL_EXCEPTION_ID_INT,
			(Xil_ExceptionHandler) XScuGic_InterruptHandler,
			InstancePtr);

	Xil_ExceptionEnable();


	return XST_SUCCESS ;

}


void DAC_Interrupt_Handler(void *CallBackRef)
{
	XAxiDma *XAxiDmaPtr = (XAxiDma *) CallBackRef ;
	int mm2s_sr ;

	mm2s_sr = XAxiDma_IntrGetIrq(XAxiDmaPtr, XAXIDMA_DMA_TO_DEVICE) ;

	if (mm2s_sr & XAXIDMA_IRQ_IOC_MASK)
	{
		/* Clear interrupt */
		XAxiDma_IntrAckIrq(XAxiDmaPtr, XAXIDMA_IRQ_IOC_MASK,
				XAXIDMA_DMA_TO_DEVICE) ;
		/*
		 * Clear BD Status and Start Channel 0
		 */
		if (XAxiDmaPtr->RegBase == CH0_DMA_BASE)
		{
			Bd_StatusClr(Ch0BdTxChainBuffer, BD_COUNT) ;
			Bd_Start(Ch0BdTxChainBuffer, BD_COUNT, &Ch0AxiDma, TXPATH) ;
		}
		/*
		 * Clear BD Status and Start Channel 1
		 */
		else if (XAxiDmaPtr->RegBase == CH1_DMA_BASE)
		{
			Bd_StatusClr(Ch1BdTxChainBuffer, BD_COUNT) ;
			Bd_Start(Ch1BdTxChainBuffer, BD_COUNT, &Ch1AxiDma, TXPATH) ;
		}
	}
}


void PsGpioHandler(void *CallbackRef)
{
	XGpioPs *GpioInstancePtr = (XGpioPs *)CallbackRef ;
	int Int_val ;

	Int_val = XGpioPs_IntrGetStatusPin(GpioInstancePtr, 54) ;
	/* clear key interrupt */
	XGpioPs_IntrClearPin(GpioInstancePtr, 54) ;
	if (Int_val)
		ch0_key_flag = 1 ;

}

void PlGpioHandler(void *CallbackRef)
{
	XGpio *GpioInstancePtr = (XGpio *)CallbackRef ;
	int Int_val ;
	int key_val ;

	Int_val = XGpio_InterruptGetStatus(GpioInstancePtr);
	key_val = XGpio_DiscreteRead(GpioInstancePtr, KEY_CHANNEL) ;
	/* Clear Interrupt */
	XGpio_InterruptClear(GpioInstancePtr, XGPIO_IR_CH1_MASK) ;

	if (Int_val & ~key_val)
		ch1_key_flag = 1 ;
}

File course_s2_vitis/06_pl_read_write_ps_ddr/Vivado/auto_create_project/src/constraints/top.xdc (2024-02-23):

set_property IOSTANDARD LVCMOS33 [get_ports error]
set_property PACKAGE_PIN J14 [get_ports error]






connect_debug_port u_ila_0/probe0 [get_nets [list {u_aq_axi_master/wr_state[0]} {u_aq_axi_master/wr_state[1]} {u_aq_axi_master/wr_state[2]}]]


create_debug_core u_ila_0 ila
set_property ALL_PROBE_SAME_MU true [get_debug_cores u_ila_0]
set_property ALL_PROBE_SAME_MU_CNT 1 [get_debug_cores u_ila_0]
set_property C_ADV_TRIGGER false [get_debug_cores u_ila_0]
set_property C_DATA_DEPTH 1024 [get_debug_cores u_ila_0]
set_property C_EN_STRG_QUAL false [get_debug_cores u_ila_0]
set_property C_INPUT_PIPE_STAGES 0 [get_debug_cores u_ila_0]
set_property C_TRIGIN_EN false [get_debug_cores u_ila_0]
set_property C_TRIGOUT_EN false [get_debug_cores u_ila_0]
set_property port_width 1 [get_debug_ports u_ila_0/clk]
connect_debug_port u_ila_0/clk [get_nets [list M_AXI_ACLK]]
set_property PROBE_TYPE DATA_AND_TRIGGER [get_debug_ports u_ila_0/probe0]
set_property port_width 3 [get_debug_ports u_ila_0/probe0]
connect_debug_port u_ila_0/probe0 [get_nets [list {mem_test_m0/state[0]} {mem_test_m0/state[1]} {mem_test_m0/state[2]}]]
create_debug_port u_ila_0 probe
set_property PROBE_TYPE DATA_AND_TRIGGER [get_debug_ports u_ila_0/probe1]
set_property port_width 8 [get_debug_ports u_ila_0/probe1]
connect_debug_port u_ila_0/probe1 [get_nets [list {mem_test_m0/wr_cnt[0]} {mem_test_m0/wr_cnt[1]} {mem_test_m0/wr_cnt[2]} {mem_test_m0/wr_cnt[3]} {mem_test_m0/wr_cnt[4]} {mem_test_m0/wr_cnt[5]} {mem_test_m0/wr_cnt[6]} {mem_test_m0/wr_cnt[7]}]]
create_debug_port u_ila_0 probe
set_property PROBE_TYPE DATA_AND_TRIGGER [get_debug_ports u_ila_0/probe2]
set_property port_width 8 [get_debug_ports u_ila_0/probe2]
connect_debug_port u_ila_0/probe2 [get_nets [list {mem_test_m0/rd_cnt[0]} {mem_test_m0/rd_cnt[1]} {mem_test_m0/rd_cnt[2]} {mem_test_m0/rd_cnt[3]} {mem_test_m0/rd_cnt[4]} {mem_test_m0/rd_cnt[5]} {mem_test_m0/rd_cnt[6]} {mem_test_m0/rd_cnt[7]}]]
create_debug_port u_ila_0 probe
set_property PROBE_TYPE DATA_AND_TRIGGER [get_debug_ports u_ila_0/probe3]
set_property port_width 64 [get_debug_ports u_ila_0/probe3]
connect_debug_port u_ila_0/probe3 [get_nets [list {wr_burst_data[0]} {wr_burst_data[1]} {wr_burst_data[2]} {wr_burst_data[3]} {wr_burst_data[4]} {wr_burst_data[5]} {wr_burst_data[6]} {wr_burst_data[7]} {wr_burst_data[8]} {wr_burst_data[9]} {wr_burst_data[10]} {wr_burst_data[11]} {wr_burst_data[12]} {wr_burst_data[13]} {wr_burst_data[14]} {wr_burst_data[15]} {wr_burst_data[16]} {wr_burst_data[17]} {wr_burst_data[18]} {wr_burst_data[19]} {wr_burst_data[20]} {wr_burst_data[21]} {wr_burst_data[22]} {wr_burst_data[23]} {wr_burst_data[24]} {wr_burst_data[25]} {wr_burst_data[26]} {wr_burst_data[27]} {wr_burst_data[28]} {wr_burst_data[29]} {wr_burst_data[30]} {wr_burst_data[31]} {wr_burst_data[32]} {wr_burst_data[33]} {wr_burst_data[34]} {wr_burst_data[35]} {wr_burst_data[36]} {wr_burst_data[37]} {wr_burst_data[38]} {wr_burst_data[39]} {wr_burst_data[40]} {wr_burst_data[41]} {wr_burst_data[42]} {wr_burst_data[43]} {wr_burst_data[44]} {wr_burst_data[45]} {wr_burst_data[46]} {wr_burst_data[47]} {wr_burst_data[48]} {wr_burst_data[49]} {wr_burst_data[50]} {wr_burst_data[51]} {wr_burst_data[52]} {wr_burst_data[53]} {wr_burst_data[54]} {wr_burst_data[55]} {wr_burst_data[56]} {wr_burst_data[57]} {wr_burst_data[58]} {wr_burst_data[59]} {wr_burst_data[60]} {wr_burst_data[61]} {wr_burst_data[62]} {wr_burst_data[63]}]]
create_debug_port u_ila_0 probe
set_property PROBE_TYPE DATA_AND_TRIGGER [get_debug_ports u_ila_0/probe4]
set_property port_width 10 [get_debug_ports u_ila_0/probe4]
connect_debug_port u_ila_0/probe4 [get_nets [list {wr_burst_len[0]} {wr_burst_len[1]} {wr_burst_len[2]} {wr_burst_len[3]} {wr_burst_len[4]} {wr_burst_len[5]} {wr_burst_len[6]} {wr_burst_len[7]} {wr_burst_len[8]} {wr_burst_len[9]}]]
create_debug_port u_ila_0 probe
set_property PROBE_TYPE DATA_AND_TRIGGER [get_debug_ports u_ila_0/probe5]
set_property port_width 32 [get_debug_ports u_ila_0/probe5]
connect_debug_port u_ila_0/probe5 [get_nets [list {rd_burst_addr[0]} {rd_burst_addr[1]} {rd_burst_addr[2]} {rd_burst_addr[3]} {rd_burst_addr[4]} {rd_burst_addr[5]} {rd_burst_addr[6]} {rd_burst_addr[7]} {rd_burst_addr[8]} {rd_burst_addr[9]} {rd_burst_addr[10]} {rd_burst_addr[11]} {rd_burst_addr[12]} {rd_burst_addr[13]} {rd_burst_addr[14]} {rd_burst_addr[15]} {rd_burst_addr[16]} {rd_burst_addr[17]} {rd_burst_addr[18]} {rd_burst_addr[19]} {rd_burst_addr[20]} {rd_burst_addr[21]} {rd_burst_addr[22]} {rd_burst_addr[23]} {rd_burst_addr[24]} {rd_burst_addr[25]} {rd_burst_addr[26]} {rd_burst_addr[27]} {rd_burst_addr[28]} {rd_burst_addr[29]} {rd_burst_addr[30]} {rd_burst_addr[31]}]]
create_debug_port u_ila_0 probe
set_property PROBE_TYPE DATA_AND_TRIGGER [get_debug_ports u_ila_0/probe6]
set_property port_width 64 [get_debug_ports u_ila_0/probe6]
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

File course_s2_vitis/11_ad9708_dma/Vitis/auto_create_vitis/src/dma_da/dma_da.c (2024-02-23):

/* ------------------------------------------------------------ */
/*				Include File Definitions						*/
/* ------------------------------------------------------------ */


#include "xaxidma.h"
#include "xparameters.h"
#include "xil_printf.h"
#include "xscugic.h"
#include "xil_exception.h"
#include "ad9708_send.h"
#include "wave.h"
#include "xgpiops.h"


/*
 * AD9708 definitions
 */
#define AD9708_BASE        XPAR_AD9708_SEND_0_S00_AXI_BASEADDR
#define AD9708_START       AD9708_SEND_S00_AXI_SLV_REG0_OFFSET
#define AD9708_LENGTH      AD9708_SEND_S00_AXI_SLV_REG1_OFFSET
/*
 * Interrupt definitions
 */
#define INT_DEVICE_ID      XPAR_SCUGIC_SINGLE_DEVICE_ID
#define MM2S_INTR_ID       XPAR_FABRIC_AXI_DMA_0_MM2S_INTROUT_INTR
#define KEY_INTR_ID        XPAR_XGPIOPS_0_INTR
/*
 * Wave Parameter definitions
 */
#define MAX_PKT_LEN		   4096	/* must be bigger than 1024, or FIFO will be empty */
#define MAX_AMP_VAL        256	/* 2^8, do not change */
#define AMP_VAL            256	/* must be less than 2^8 */
/*
 * Device id definitions
 */
#define DMA_DEV_ID		   XPAR_AXIDMA_0_DEVICE_ID
#define MIO_0_ID           XPAR_PS7_GPIO_0_DEVICE_ID

#define GPIO_INPUT         0
/*
 * Function definitions
 */
int XAxiDma_DAC(u16 DeviceId);
void DAC_Interrupt_Handler(void *CallBackRef) ;
int XAxiDma_Initial(u16 DeviceId, u16 IntrID, XAxiDma *XAxiDma, XScuGic *InstancePtr) ;
int SetInterruptInit(XScuGic *InstancePtr, u16 IntID) ;
int KeySetup(XScuGic *InstancePtr, u16 IntrID, XGpioPs *GpioInstancePtr) ;
void GpioHandler(void *CallbackRef);

XScuGic INST ;

XAxiDma AxiDma;

XGpioPs GPIO_PTR ;

volatile int key_flag ;

/*
 * DMA buffer to MM2S
 */
u8 DmaTxBuffer[MAX_PKT_LEN] __attribute__ ((aligned(64)));
/*
 * wave buffer
 */
u8 WaveBuffer[MAX_PKT_LEN] __attribute__ ((aligned(64)));


int main()
{
	int Status;

	Status = SetInterruptInit(&INST, INT_DEVICE_ID) ;
	if (Status != XST_SUCCESS)
		return XST_FAILURE ;

	KeySetup(&INST, KEY_INTR_ID, &GPIO_PTR) ;

	Status = XAxiDma_DAC(DMA_DEV_ID);

	if (Status != XST_SUCCESS) {
		return XST_FAILURE;
	}

	return XST_SUCCESS;

}




int XAxiDma_DAC(u16 DeviceId)
{

	int wave_sel = 0;

	/* Initialize DMA and enable MM2S interrupt */
	XAxiDma_Initial(DeviceId, MM2S_INTR_ID, &AxiDma, &INST) ;
	/* Create initial wave data */
	GetSinWave(MAX_PKT_LEN, MAX_AMP_VAL, AMP_VAL, WaveBuffer) ;
	/* Copy wave data to DMA buffer */
	memcpy(DmaTxBuffer, WaveBuffer, MAX_PKT_LEN) ;
	Xil_DCacheFlushRange((UINTPTR)DmaTxBuffer, MAX_PKT_LEN);

	AD9708_SEND_mWriteReg(AD9708_BASE, AD9708_START, 1) ;

	XAxiDma_SimpleTransfer(&AxiDma,(UINTPTR) DmaTxBuffer,
			MAX_PKT_LEN, XAXIDMA_DMA_TO_DEVICE);

	while(1)
	{
		if (key_flag)
		{
			switch(wave_sel)
			{
			case 0 : GetSquareWave(MAX_PKT_LEN, MAX_AMP_VAL, AMP_VAL, WaveBuffer) ; break ;
			case 1 : GetTriangleWave(MAX_PKT_LEN, MAX_AMP_VAL, AMP_VAL, WaveBuffer) ; break ;
			case 2 : GetSawtoothWave(MAX_PKT_LEN, MAX_AMP_VAL, AMP_VAL, WaveBuffer) ; break ;
			case 3 : GetSubSawtoothWave(MAX_PKT_LEN, MAX_AMP_VAL, AMP_VAL, WaveBuffer) ; break ;
			case 4 : GetSinWave(MAX_PKT_LEN, MAX_AMP_VAL, AMP_VAL, WaveBuffer) ; break ;
			default: GetSinWave(MAX_PKT_LEN, MAX_AMP_VAL, AMP_VAL, WaveBuffer) ; break ;
			}

			memcpy(DmaTxBuffer, WaveBuffer, MAX_PKT_LEN) ;
			Xil_DCacheFlushRange((UINTPTR)DmaTxBuffer, MAX_PKT_LEN);

			if (wave_sel == 4)
				wave_sel = 0 ;
			else
				wave_sel++ ;

			/* Clear flag */
			key_flag = 0 ;
		}

	}

	return XST_SUCCESS;
}

/*
 * Set up key and enable GPIO interrupt
 */
int KeySetup(XScuGic *InstancePtr, u16 IntrID, XGpioPs *GpioInstancePtr)
{
	XGpioPs_Config *GPIO_CONFIG ;
	int Status ;
	key_flag = 0 ;


	GPIO_CONFIG = XGpioPs_LookupConfig(MIO_0_ID) ;
	Status = XGpioPs_CfgInitialize(GpioInstancePtr, GPIO_CONFIG, GPIO_CONFIG->BaseAddr) ;
	if (Status != XST_SUCCESS)
	{
		return XST_FAILURE ;
	}
	//set MIO 54 as input
	XGpioPs_SetDirectionPin(GpioInstancePtr, 54, GPIO_INPUT) ;
	//set interrupt type
	XGpioPs_SetIntrTypePin(GpioInstancePtr, 54, XGPIOPS_IRQ_TYPE_EDGE_RISING) ;


	//set priority and trigger type
	XScuGic_SetPriorityTriggerType(InstancePtr, IntrID,
			0xA0, 0x3);
	Status = XScuGic_Connect(InstancePtr, IntrID,
			(Xil_ExceptionHandler)GpioHandler,
			(void *)GpioInstancePtr) ;

	XScuGic_Enable(InstancePtr, IntrID) ;

	if (Status != XST_SUCCESS) {
		return Status;
	}


	XGpioPs_IntrEnablePin(GpioInstancePtr, 54) ;

	return XST_SUCCESS ;
}


/*
 * Initial DMA and enable MM2S interrupt
 */
int XAxiDma_Initial(u16 DeviceId, u16 IntrID, XAxiDma *XAxiDma, XScuGic *InstancePtr)
{
	XAxiDma_Config *CfgPtr;
	int Status;
	/* Initialize the XAxiDma device. */
	CfgPtr = XAxiDma_LookupConfig(DeviceId);
	if (!CfgPtr) {
		xil_printf("No config found for %d\r\n", DeviceId);
		return XST_FAILURE;
	}

	Status = XAxiDma_CfgInitialize(XAxiDma, CfgPtr);
	if (Status != XST_SUCCESS) {
		xil_printf("Initialization failed %d\r\n", Status);
		return XST_FAILURE;
	}

	Status = XScuGic_Connect(InstancePtr, IntrID,
			(Xil_ExceptionHandler)DAC_Interrupt_Handler,
			(void *)XAxiDma) ;

	if (Status != XST_SUCCESS) {
		return Status;
	}

	XScuGic_Enable(InstancePtr, IntrID);


	/* Disable S2MM interrupt, Enable MM2S interrupt */
	XAxiDma_IntrDisable(&AxiDma, XAXIDMA_IRQ_ALL_MASK,
			XAXIDMA_DEVICE_TO_DMA);
	XAxiDma_IntrEnable(&AxiDma, XAXIDMA_IRQ_IOC_MASK,
			XAXIDMA_DMA_TO_DEVICE);

	return XST_SUCCESS ;
}


int SetInterruptInit(XScuGic *InstancePtr, u16 IntID)
{

	XScuGic_Config * Config ;
	int Status ;

	Config = XScuGic_LookupConfig(IntID) ;

	Status = XScuGic_CfgInitialize(&INST, Config, Config->CpuBaseAddress) ;
	if (Status != XST_SUCCESS)
		return XST_FAILURE ;


	Xil_ExceptionInit();
	Xil_ExceptionRegisterHandler(XIL_EXCEPTION_ID_INT,
			(Xil_ExceptionHandler) XScuGic_InterruptHandler,
			InstancePtr);

	Xil_ExceptionEnable();


	return XST_SUCCESS ;

}


void DAC_Interrupt_Handler(void *CallBackRef)
{
	XAxiDma *XAxiDmaPtr = (XAxiDma *) CallBackRef ;
	int mm2s_sr ;

	mm2s_sr = XAxiDma_IntrGetIrq(XAxiDmaPtr, XAXIDMA_DMA_TO_DEVICE) ;

	if (mm2s_sr & XAXIDMA_IRQ_IOC_MASK)
	{
		/* Clear interrupt */
		XAxiDma_IntrAckIrq(XAxiDmaPtr, XAXIDMA_IRQ_IOC_MASK,
				XAXIDMA_DMA_TO_DEVICE) ;

		XAxiDma_SimpleTransfer(&AxiDma,(UINTPTR) DmaTxBuffer,
				MAX_PKT_LEN, XAXIDMA_DMA_TO_DEVICE);
	}
}


void GpioHandler(void *CallbackRef)
{
	XGpioPs *GpioInstancePtr = (XGpioPs *)CallbackRef ;
	int Int_val ;

	Int_val = XGpioPs_IntrGetStatusPin(GpioInstancePtr, 54) ;
	/* clear key interrupt */
	XGpioPs_IntrClearPin(GpioInstancePtr, 54) ;
	if (Int_val == TRUE)
		key_flag = 1 ;

}

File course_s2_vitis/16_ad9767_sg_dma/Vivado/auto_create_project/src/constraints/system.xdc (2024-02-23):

set_property BITSTREAM.GENERAL.COMPRESS TRUE [current_design]
set_property CFGBVS VCCO [current_design]
set_property CONFIG_VOLTAGE 3.3 [current_design]
#KEY2
set_property IOSTANDARD LVCMOS33 [get_ports {key_tri_i[0]}]
set_property PACKAGE_PIN M14 [get_ports {key_tri_i[0]}]

#KEY1
set_property IOSTANDARD LVCMOS33 [get_ports {GPIO_tri_io[0]}]
set_property PACKAGE_PIN M15 [get_ports {GPIO_tri_io[0]}]





#create_debug_core u_ila_0 ila
#set_property ALL_PROBE_SAME_MU true [get_debug_cores u_ila_0]
#set_property ALL_PROBE_SAME_MU_CNT 1 [get_debug_cores u_ila_0]
#set_property C_ADV_TRIGGER false [get_debug_cores u_ila_0]
#set_property C_DATA_DEPTH 4096 [get_debug_cores u_ila_0]
#set_property C_EN_STRG_QUAL false [get_debug_cores u_ila_0]
#set_property C_INPUT_PIPE_STAGES 2 [get_debug_cores u_ila_0]
#set_property C_TRIGIN_EN false [get_debug_cores u_ila_0]
#set_property C_TRIGOUT_EN false [get_debug_cores u_ila_0]
#set_property port_width 1 [get_debug_ports u_ila_0/clk]
#connect_debug_port u_ila_0/clk [get_nets [list top_i/processing_system7_0/inst/FCLK_CLK1]]
#set_property PROBE_TYPE DATA_AND_TRIGGER [get_debug_ports u_ila_0/probe0]
#set_property port_width 14 [get_debug_ports u_ila_0/probe0]
#connect_debug_port u_ila_0/probe0 [get_nets [list {top_i/ad9767_send_0/inst/ad9767_send_v1_0_S00_AXI_inst/send_inst/dac_data[0]} {top_i/ad9767_send_0/inst/ad9767_send_v1_0_S00_AXI_inst/send_inst/dac_data[1]} {top_i/ad9767_send_0/inst/ad9767_send_v1_0_S00_AXI_inst/send_inst/dac_data[2]} {top_i/ad9767_send_0/inst/ad9767_send_v1_0_S00_AXI_inst/send_inst/dac_data[3]} {top_i/ad9767_send_0/inst/ad9767_send_v1_0_S00_AXI_inst/send_inst/dac_data[4]} {top_i/ad9767_send_0/inst/ad9767_send_v1_0_S00_AXI_inst/send_inst/dac_data[5]} {top_i/ad9767_send_0/inst/ad9767_send_v1_0_S00_AXI_inst/send_inst/dac_data[6]} {top_i/ad9767_send_0/inst/ad9767_send_v1_0_S00_AXI_inst/send_inst/dac_data[7]} {top_i/ad9767_send_0/inst/ad9767_send_v1_0_S00_AXI_inst/send_inst/dac_data[8]} {top_i/ad9767_send_0/inst/ad9767_send_v1_0_S00_AXI_inst/send_inst/dac_data[9]} {top_i/ad9767_send_0/inst/ad9767_send_v1_0_S00_AXI_inst/send_inst/dac_data[10]} {top_i/ad9767_send_0/inst/ad9767_send_v1_0_S00_AXI_inst/send_inst/dac_data[11]} {top_i/ad9767_send_0/inst/ad9767_send_v1_0_S00_AXI_inst/send_inst/dac_data[12]} {top_i/ad9767_send_0/inst/ad9767_send_v1_0_S00_AXI_inst/send_inst/dac_data[13]}]]
#create_debug_core u_ila_1 ila
#set_property ALL_PROBE_SAME_MU true [get_debug_cores u_ila_1]
#set_property ALL_PROBE_SAME_MU_CNT 1 [get_debug_cores u_ila_1]
#set_property C_ADV_TRIGGER false [get_debug_cores u_ila_1]
#set_property C_DATA_DEPTH 4096 [get_debug_cores u_ila_1]
#set_property C_EN_STRG_QUAL false [get_debug_cores u_ila_1]
#set_property C_INPUT_PIPE_STAGES 2 [get_debug_cores u_ila_1]
#set_property C_TRIGIN_EN false [get_debug_cores u_ila_1]
#set_property C_TRIGOUT_EN false [get_debug_cores u_ila_1]
#set_property port_width 1 [get_debug_ports u_ila_1/clk]
#connect_debug_port u_ila_1/clk [get_nets [list top_i/processing_system7_0/inst/FCLK_CLK0]]
#set_property PROBE_TYPE DATA_AND_TRIGGER [get_debug_ports u_ila_1/probe0]
#set_property port_width 2 [get_debug_ports u_ila_1/probe0]
#connect_debug_port u_ila_1/probe0 [get_nets [list {top_i/ad9767_send_0/inst/ad9767_send_v1_0_S00_AXI_inst/send_inst/DMA_AXIS_tkeep[0]} {top_i/ad9767_send_0/inst/ad9767_send_v1_0_S00_AXI_inst/send_inst/DMA_AXIS_tkeep[1]}]]
#create_debug_port u_ila_0 probe
#set_property PROBE_TYPE DATA_AND_TRIGGER [get_debug_ports u_ila_0/probe1]
#set_property port_width 32 [get_debug_ports u_ila_0/probe1]
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
